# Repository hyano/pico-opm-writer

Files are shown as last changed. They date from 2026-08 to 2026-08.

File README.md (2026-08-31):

# pico-opm-writer

Raspberry Pi Pico 2 (RP2350) を YM2151 (OPM) に直結して鳴らすためのファームウェア。
ホスト PC から USB シリアルで**レジスタを直接叩く**ことも、内蔵フラッシュに入れた
**VGM / MDX を Pico 単体で演奏する**こともできる。鳴った音は YM3012 (DAC) から PCM として
取り込むので、**USB 経由の録音**と **I2S DAC からのアナログ出力**が外部の機材なしで
同時に得られる。

- **レジスタ書き込み**: USB CDC (仮想 COM ポート) にテキストコマンドを打つだけでよく、
  `screen` や `minicom` のような素のターミナルで足りる（[§3](#3-ホストインタフェース)）。
  バッチ実行やキャプチャの自動化には [ホスト側ツール](#10-ホスト側ツール)（`tools/`）を使う
- **VGM 再生**: `/VGM/` に置いた `.vgm` / `.vgz` を、ホストからシーケンスを流し込まずに
  再生する。ファイルが申告するクロックへ φM を自動で合わせる（[§8](#8-vgm-再生)）
- **MDX 再生**: `/MDX/` に置いた X68000 の MDX を、MXDRV 相当の音源ドライバで
  FM 8ch + ADPCM 8ch 再生する。ADPCM (PDX) はソフトウェアでデコードして FM に混ぜる
  （[§9](#9-mdx-再生)）
- **曲データの受け渡し**: 内蔵フラッシュ 4MiB の一部を FAT にしてあり、USB マスストレージ
  として PC から見える。SD カードも外付けフラッシュも要らない（[§7](#7-ストレージ)）
- **PCM 出力**: YM3012 の出力を 2 本目の USB CDC から PCM で吸い出せる（[§4](#4-pcm-出力)）。
  同じデータを I2S で PCM5102A へ常時流している（[§5](#5-i2s-出力)）。ロジックアナライザや
  外部の録音機材は要らない
- **PC を繋がない運用**: ボタン 3 個で自動連続再生とストレージの切り替えができる
  （[§3.17](#317-autoplay自動再生) / [§3.20](#320-ボタンgp21--gp22)）

ファームウェアの内部設計と実装は [docs/pico-opm-writer.md](docs/pico-opm-writer.md) にある。

## 1. ハードウェア構成

### 1.1 接続表

Pico 2 は OPM のバスへ双方向に接続する。**データバスを駆動するのは通常 Pico 側だけ**で、
読み出し（[`r`](#321-r読み出し)）の実行中だけ Pico 側を入力へ倒して OPM に駆動させる。
これとは別に、YM3012 (DAC) のシリアル出力を Pico 側へ取り込む（[§4](#4-pcm-出力)）。

| Pico 2 GPIO | 物理ピン | 接続先 | 方向 | 備考 |
| --- | --- | --- | --- | --- |
| GP0  | 1  | - | - | 将来のデバッグ UART TX 用に予約 |
| GP1  | 2  | - | - | 将来のデバッグ UART RX 用に予約 |
| GP2  | 4  | D0 | I/O | データバス。通常は出力、読み出し中だけ入力 |
| GP3  | 5  | D1 | I/O | |
| GP4  | 6  | D2 | I/O | |
| GP5  | 7  | D3 | I/O | |
| GP6  | 9  | D4 | I/O | |
| GP7  | 10 | D5 | I/O | |
| GP8  | 11 | D6 | I/O | |
| GP9  | 12 | D7 | I/O | D0-D7 は連続した GPIO であること（マスクでまとめて読み書きするため） |
| GP10 | 14 | A0 | OUT | L=アドレスラッチ / H=データ書き込み |
| GP11 | 15 | /CS  | OUT | チップセレクト（負論理） |
| GP12 | 16 | /WR  | OUT | 書き込みストローブ（負論理） |
| GP13 | 17 | /RD  | OUT | 読み出しストローブ（負論理）。[`r`](#321-r読み出し) の実行中だけ L |
| GP14 | 19 | /IC  | OUT | ハードウェアリセット（負論理） |
| GP15 | 20 | φM | OUT | マスタークロック、PIO で生成 |
| GP16 | 21 | /IRQ | IN  | 割り込み要求（負論理）。プルアップ、レベル参照のみ |
| GP17 | 22 | SO | IN  | YM3012 シリアルデータ。PIO の in_base |
| GP18 | 24 | φ1 | IN  | YM3012 ビットクロック（φM/2） |
| GP19 | 25 | SH1  | IN  | CH2 のサンプルホールド。フレーム同期に使う |
| GP20 | 26 | SH2  | IN  | CH1 のサンプルホールド。現在は未使用 |
| GP21 | 27 | SW1  | IN  | ボタン 1（[§3.20](#320-ボタンgp21--gp22)）。内部プルアップ、押下で GND |
| GP22 | 29 | SW2  | IN  | ボタン 2（同上） |
| GP25 | -  | - | OUT | 基板上 LED（[§3.9](#39-led)）。`PICO_DEFAULT_LED_PIN` |
| GP26 | 31 | BCK  | OUT | I2S ビットクロック（[§5](#5-i2s-出力)） |
| GP27 | 32 | LRCK | OUT | I2S ワードセレクト。BCK の次の GPIO であること |
| GP28 | 34 | DIN  | OUT | I2S データ |
| RUN  | 30 | SW3  | IN  | Pico 2 のリセット端子。押下で GND に落としてリセット。**ファームウェアからは見えない**（[§3.20](#320-ボタンgp21--gp22)） |
| GND  | 3, 8, 13, 18 … | GND | - | OPM と共通グラウンドを取ること |

GP23 / GP24 は Pico 2 の内部用途（`PICO_SMPS_MODE_PIN` / `PICO_VBUS_PIN`）なので使わない。
I2S の MCLK は使わないので、DAC へ出すのは GP26-GP28 の 3 本だけ。

SO / φ1 / SH1 / SH2 は **GP17 から連続していること**。キャプチャ用の PIO がこの 4 本を
in_base からのオフセットで参照する（[docs §4.2](docs/pico-opm-writer.md#42-pio-によるビット取り込み)）。

ピン番号の定義は [opm.h](src/opm.h) の `OPM_PIN_*`、[ym3012.h](src/ym3012.h) の `YM3012_PIN_*`、
[button.h](src/button.h) の `BUTTON_PIN_*` にまとまっている。

### 1.2 GPIO を割り当てない OPM 端子

| OPM 端子 | 処理 | 理由 |
| --- | --- | --- |
| CT1 / CT2 | 未接続で可 | 汎用出力端子。本ファームウェアは使わない |

### 1.3 配線上の注意

**Pico 2 と OPM は全線を直結する。** レベル変換器も分圧も挟まない。
[board/](board/) の基板もこの前提で起こしてある。モジュールを使わず RP2350A と PCM5102A を
直接実装する改版が [board_pcba/](board_pcba/README.md) にある（回路図のみ）。

- **入力側（Pico → OPM）**: OPM は 5V デバイス、Pico 2 の GPIO は 3.3V。RP2350 の 3.3V 出力を
  OPM が H / L として判別できることは実機で確認済みで、[test/](test/) の実測データはすべて
  この直結構成で取れている。ただし OPM の入力 H レベル閾値には個体差・ロット差があり、
  他の個体でも同じように動く保証は無い（未確認）。動作しない場合はバッファ / レベルシフタ
  （74HCT244 等）を φM とバス側に挿入する。
- **出力側（OPM → Pico）**: SO / φ1 / SH1 / SH2 / /IRQ は 5V デバイスである OPM の**出力**で、
  H レベルは 3.3V を超える。**RP2350 の GPIO 0-25 は 5V トレラント**なので直結でよい
  （[RP2350 データシート](https://datasheets.raspberrypi.com/rp2350/rp2350-datasheet.pdf)
  §14.8.2.1 Table 1426 の `Digital IO (FT)` / §14.9.1 Table 1433 の `VPIN_FT`）。
  成立の条件は次の 2 つで、本構成はどちらも満たしている。

  | 条件 | 本構成での成立 |
  | --- | --- |
  | 対象は **GPIO 0-25 のみ**（`Digital IO (FT)` パッド）。GP26-GP29 は ADC 兼用の `Digital IO / Analogue` で対象外 | 5V を受けるのは GP2-GP9 (D0-D7) / GP16 (/IRQ) / GP17-GP20 (SO・φ1・SH1・SH2) だけで、すべて範囲内 |
  | 5V が掛かっている間 **IOVDD が 3.3V で給電されている**こと。無給電のまま 5V を掛けるとパッドが壊れる | OPM の 5V は Pico の VBUS から取るので、5V があるときは必ず Pico の 3.3V も生きている |

  **ステッピングによる違いは無い。** データシートの FT パッドの規定は版を区別しておらず、
  Appendix C も A4 を "This stepping has no hardware changes." としている。
  A4 の[告知](https://www.raspberrypi.com/news/rp2350-a4-rp2354-and-a-new-hacking-challenge/)
  （2025-07-29）は認定試験を通したという告知であってシリコンの変更ではないので、
  出回っている A2 の Pico 2 でも同じように使える
  （[Raspberry Pi のエンジニアの明言](https://forums.raspberrypi.com/viewtopic.php?p=2330278)）。

  絶対最大定格は GPIO 0-25 が IOVDD = 3.3V のとき 5.5V、IOVDD = 0V のとき 3.63V
  （Table 1433 の `VPIN_FT`）。それ以外のピンは IOVDD + 0.5V。/IRQ は
  [opm.c](src/opm.c) が内部プルアップを張るので、外付け抵抗は要らない。

  **GP26-GP28（I2S の BCK / LRCK / DIN）に 5V デバイスを繋いではいけない。**
  この 3 本は 5V トレラントの対象外。接続先の PCM5102A は 3.3V ロジックで、
  しかも Pico からの出力専用なので現状は問題にならない（[§5](#5-i2s-出力)）。
- **バスの衝突防止**: D0-D7 は双方向なので、OPM と Pico が同時に駆動すると衝突する。
  /RD を H に保っていれば OPM は D0-D7 を駆動しないため、ファームウェアは
  **読み出し（[`r`](#321-r読み出し)）の実行中以外は /RD を H に固定**している。
  読み出しでは、OPM に駆動させる前に Pico 側を入力へ倒し、/RD を H に戻して OPM が
  バスを手放してから出力へ戻す。この間 D0-D7 は OPM の 5V 出力を受けるので、
  上の表の条件（GPIO 0-25・IOVDD 給電中）がそのまま効く。
  **ただしこれが効くのは GPIO を初期化した後だけ。** RP2350 のパッドはリセット直後
  入力 + プルダウン（`PADS_BANK0_GPIO0_RESET` の `PDE` = 1）なので、電源投入から
  `opm_init()` が /CS と /RD を H にするまでの間は OPM から見て /CS = L / /RD = L となり、
  **OPM が D0-D7 を駆動する窓がある**。この窓では Pico 側がまだ入力なので駆動は衝突せず、
  D0-D7 に乗る 5V も上の表の条件を満たす。窓そのものを塞ぎたければ /CS を 5V へ
  10kΩ 程度でプルアップする（このとき GP11 も 5V を受けるが、GPIO 0-25 なので同じく
  条件の内側）。
- 電源には十分なデカップリング（OPM の VCC-GND 間に 0.1µF + 10µF 程度）を入れる。
- **ボタンは 3 個ともスイッチ 1 個だけでよい。** SW1 / SW2 は GP21 / GP22 と GND の間、
  SW3 は RUN と GND の間に入れる。**外付けのプルアップ抵抗もコンデンサも要らない**
  （GP21 / GP22 は RP2350 の内部プルアップを張って負論理で読み、チャタリングは
  ファームウェア側で時間ベースに除去する。RUN は Pico 2 側で既にプルアップされている）。
  SW1 / SW2 を使わないなら GP21 / GP22 は開放でよい。内部プルアップで「離されている」と
  読めるので、ボタンを実装していない基板でも既定のファームウェアがそのまま動く。

## 2. クロック設定 (φM)

φM は PIO で生成する。φM とシステムクロックは**整数分周（ジッタなし）になる組**でしか
意味を持たないため、両者をペアにしたプリセットとして持たせている。

| プリセット | `clock` の引数 | φM | sys_clk | clkdiv | fs (φM/64) | 備考 |
| --- | --- | --- | --- | --- | --- | --- |
| 4MHz（**起動時の既定**） | `4` | 4.000000 MHz | 144 MHz（= 4MHz × 36） | 18 | 62500.0 Hz | YM2151 の定格上限。RP2350 定格 150MHz 以内 |
| NTSC | `3.58` | 3.579545 MHz | 157.5 MHz（= × 44） | 22 | 55930.4 Hz | NTSC カラーサブキャリア = 315/88 MHz。定格比 約 +5% の OC |

**動作させたまま切り替えられる。**

- `clock 4` / `clock 3.58` で手動切り替え（[§3.16](#316-clockクロック切り替え)）
- `vgm play` はヘッダが申告する YM2151 のクロックへ自動追従する
  （[§8.3](#83-φm-と-vgm-のクロック)）。`clock fixed` で抑止できる
- `mdx play` は X68000 の φM = 4MHz へ寄せる（[§9.3](#93-φm-と-テンポ)）。
  同じく `clock fixed` で抑止できるが、MDX は**テンポも φM に比例して狂う**
- **PCM を流している間は切り替えを拒否する。** サンプリングレートが
  ストリームの途中で変わると、ホスト側で出来上がる WAV の時間軸が黙って狂うため。
  `p 2` の待機中はまだ流していないので通る（[§3.16](#316-clockクロック切り替え)）

切り替えは sys_clk ごと張り替えるが、**φM・BCK・LRCK の H/L 期間が公称値より
短くなることはない**（順序と手順は [docs §2.3](docs/pico-opm-writer.md#23-実行時の切り替え)）。
所要は数百 µs で、その間 I2S のリング（先行 16.4ms）は枯れないのでアンダーランしない。

起動時にどちらで立ち上げるかは次のどちらかで決める。

- `opm.h` の `#define OPM_CLOCK_MODE OPM_CLOCK_MODE_4MHZ` の行を書き換える
- ヘッダを触らずに再コンフィグする:
  ```bash
  cmake -S . -B build -G Ninja -DCMAKE_BUILD_TYPE=Release -DPICO_BOARD=pico2 -DOPM_CLOCK_MODE=1
  ```
  `-DOPM_CLOCK_MODE=` （空）に戻すと `opm.h` の既定値に従う。

**プリセット外の値を使うときは φM と sys_clk の両方を整数分周になる組で指定すること**
（片方だけの変更は小数分周になり、φM にジッタが乗る）。理由と、整数分周にならなかった
場合の挙動は [docs §2](docs/pico-opm-writer.md#2-φm-の生成) にある。

φM を変えても PCM のサンプリングレート（φM/64）が変わるだけで、タイミング定数の
書き換えは要らない。

## 3. ホストインタフェース

### 3.1 接続

- USB CDC (仮想 COM ポート) **2 ポート**。

  | | 用途 | macOS でのデバイス名の例 |
  | --- | --- | --- |
  | CDC #0 | コマンド。Pico SDK の `stdio_usb` がそのまま使う | `/dev/cu.usbmodem11201` |
  | CDC #1 | PCM データ出力（[§4](#4-pcm-出力)） | `/dev/cu.usbmodem11203` |

  CDC #0 をディスクリプタの先頭に置いているので、コマンド側のデバイス名は 1 ポート構成の
  ときと変わらない。CDC #1 は末尾の番号が増えたものになる。
  2 本は独立しているので、コマンドを打ちながら PCM を取り込める。
- CDC を 2 本にする都合で **`picotool load -fx`（BOOTSEL 不要の書き込み）は使えない**
  （[§6.4](#64-書き込み代替経路)）。
- ボーレート・パリティ等の設定は無視される（USB CDC のため何を指定しても動作する）。
- macOS 例: `screen /dev/cu.usbmodem11201 115200`。
  **`/dev/tty.*` ではなく `/dev/cu.*` を使う**（`tty.*` は DCD 待ちで open がブロックする）。
  デバイス名の引き直し方は [§6.5](#65-シリアル-stdio-の読み取り) を参照。
- 接続を検出した時点で起動バナーを出力する（接続前の出力は捨てられるため）。

### 3.2 行フォーマット

- コマンドは **1 行 1 コマンド**。行末は `LF` / `CR` / `CRLF` のいずれでも受け付ける。
- 1 行の最大長は 255 文字。超えた場合は `ERR too long` を返し、その行を破棄する。
- コマンド文字・16 進数の大文字小文字は区別しない。
- トークン区切りは空白またはタブ（連続可）。
- 空行、および **行頭が `#` の行**はコメントとして無視し、**応答も返さない**。

**行末コメント（`w 20 c7 # ...`）には対応していない。** `#` は引数のトークンとして読まれ、
`ERR bad argument` または `ERR wrong arity` になる。行末コメント・プレースホルダ置換・
キャプチャ制御が要るシーケンスは [tools/opm-writer.py](docs/opm-writer.md) 経由で流し込む。

### 3.3 応答

各コマンドは必ず 1 行の応答で終わる。**例外は空行とコメント行だけ**で、これらは
何も返さない（[§3.2](#32-行フォーマット)）。

| 応答 | 意味 |
| --- | --- |
| `OK` | 正常終了 |
| `ERR <理由>` | エラー |

情報を返すコマンドは、`#` で始まる情報行を 0 行以上出力したあと最後に `OK` を返す。
ホスト側は「`#` 始まりは情報、それ以外の 1 行が終端」と扱えばよい。

情報行は 4 種類ある。いずれも `# ` で始まるので、区別せず読み飛ばしても構わない。

| 情報行 | 意味 |
| --- | --- |
| `# <tag> : ...` | 通常の情報。`<tag>` は主題（`vgm` / `adpcm` / `capture` など）を表す |
| `# hint : ...` | **直後の** `ERR` の理由と対処。応答より先に出る。**`ERR wrong state` には必ず付く** |
| `# warn : ...` | 処理は続いたが注意が要ること |
| `# ERR ...` | コマンドの応答ではない非同期の通知（[§3.18](#318-非同期通知)） |

**ファームウェアの応答はすべて英語。** 例外は `mdx play` / `mdx status` の `# title` 行
だけで、これは MDX ファイル中の Shift_JIS をそのまま流している（[§3.15](#315-mdxmdx-再生)）。

エラー理由の一覧:

| 応答 | 発生条件 |
| --- | --- |
| `ERR unknown command` | 未知のコマンド。1 文字のコマンドか `clock` / `storage` / `vgm` / `mdx` / `autoplay` / `reset` / `help` のいずれでもない場合と、それらのサブコマンドが未知の場合（`clock 5` のような未知のプリセット名も含む） |
| `ERR bad argument` | 引数が 16 進数 / 10 進数として解釈できない、ファイル名が不正、または語の引数が想定外（`mdx pcm maybe` / `storage format no`） |
| `ERR wrong arity` | 引数の個数が合わない |
| `ERR out of range` | 引数が許容範囲外 |
| `ERR too long` | 行が長すぎる |
| `ERR wrong state` | いまの状態では実行できない。**直前に必ず理由を示す `# hint` 行が出る。** どのコマンドがどの状態で拒否されるかは [§3.19](#319-状態による拒否の一覧) にまとめてある |
| `ERR no filesystem` | ストレージが未フォーマット、または領域がファームウェアと重なっている |
| `ERR not found` | 指定したファイルが無い、`/VGM` / `/MDX` が無い、または `autoplay list` を打ったときにプレイリストがまだ作られていない（[§3.17](#317-autoplay自動再生)） |
| `ERR bad file` | VGM / MDX として読めない（マジック不正 / ヘッダが壊れている / gzip ストリームが壊れている / MDX が 64KiB を超える） |
| `ERR io error` | フラッシュまたはファイルシステムの入出力に失敗した |
| `ERR not connected` | CDC #1 が開かれていない状態で `p 1`（[§3.10](#310-ppcm-出力)） |
| `ERR drain timeout` | `p 0` のドレインが 2 秒で終わらなかった（[§3.10](#310-ppcm-出力)） |
| `ERR self test failed` | `t` の自己テストのどれかが失敗した（[§3.12](#312-t自己テスト)） |
| `ERR unsupported` | この構成に機能が無い。`clock` の切り替え先の sys_clk をこのチップで生成できない（[§3.16](#316-clockクロック切り替え)）か、ビルド時に無効化されている（`MDX_ENABLED=0` / `PCM8_ENABLED=0`。[§9.8](#98-無効化)、`AUTOPLAY_ENABLED=0`。[§3.17](#317-autoplay自動再生)） |

### 3.4 コマンド一覧

| コマンド | 書式 | 説明 |
| --- | --- | --- |
| `w` | `w <addr> <data> [<addr> <data> ...]` | レジスタ書き込み。引数は 16 進。addr/data のペアを 1 行に複数並べて連続書き込みできる。**途中でエラーになった場合、そこまでの書き込みは実行済み**のまま `ERR` を返す |
| `r` | `r 0` / `r 1` | A0=0 / A0=1 で 1 バイト読み出し（[§3.21](#321-r読み出し)） |
| `reset` | `reset` | /IC によるハードウェアリセット。I2S のアンダーランを 1 回伴う（[§5.3](#53-アンダーラン)） |
| `c` | `c` | ソフトウェアによる全レジスタクリア（[§3.5](#35-cクリアが書き込む内容)） |
| `d` | `d <ms>` | 指定ミリ秒待機。10 進、`0`-`60000`。待っている間も PCM の送出は続く |
| `p` | `p` / `p 1` / `p 2` / `p 0` | PCM 出力の状態表示 / 開始 / 演奏に連動して開始 / 停止（[§3.10](#310-ppcm-出力)） |
| `s` | `s` / `s 0` | 統計の表示 / リセット（[§3.11](#311-s統計)） |
| `t` | `t` | 自己テスト（[§3.12](#312-t自己テスト)） |
| `i` | `i` | 情報表示（[§3.6](#36-i情報表示の出力例)） |
| `h` | `h` / `?` / `help` | コマンド一覧を表示 |
| `clock` | `clock` / `clock status` / `clock 4` / `clock 3.58` / `clock auto` / `clock fixed` | φM の表示と切り替え（[§3.16](#316-clockクロック切り替え)） |
| `storage` | `storage` / `storage status` / `storage host` / `storage player` / `storage format [force] yes` / `storage trace` | ストレージの状態表示とモード切り替え（[§3.13](#313-storageストレージ)） |
| `vgm` | `vgm` / `vgm status` / `vgm list` / `vgm play <path>` / `vgm stop` / `vgm loop [<n>]` / `vgm fade [<ms>]` | VGM の状態表示・一覧・再生、演奏の終わり方（[§3.14](#314-vgmvgm-再生)） |
| `mdx` | `mdx` / `mdx status` / `mdx list` / `mdx play <path>` / `mdx stop` / `mdx loop [<n>]` / `mdx fade [<ms>]` / `mdx pcm [on\|off]` | MDX の状態表示・一覧・再生、演奏の終わり方、ADPCM ミキシングの表示と切り替え（[§3.15](#315-mdxmdx-再生)） |
| `autoplay` | `autoplay` / `autoplay status` / `autoplay list` / `autoplay start` / `autoplay stop` / `autoplay next` / `autoplay prev` / `autoplay mode <list\|random>` / `autoplay loop <n>` / `autoplay fade <ms>` / `autoplay gap <ms>` / `autoplay source <vgm\|mdx\|both>` | VGM と MDX の自動連続再生（[§3.17](#317-autoplay自動再生)） |

コマンド体系の規則:

- **引数を省くと状態表示になる。** `p` / `clock` / `storage` / `vgm` / `mdx` / `mdx pcm` /
  `vgm loop` / `vgm fade` / `mdx loop` / `mdx fade` / `autoplay` は引数なしで現在の状態を
  返す。`clock status` / `storage status` /
  `vgm status` / `mdx status` / `autoplay status` は引数なしの形と同じ（打ちやすい方を
  使えばよい）。
- **状態を変えるコマンドは、変えたあとの状態を返す。** `p 1` / `p 2` / `p 0` / `storage host` /
  `storage player` / `clock 4` / `mdx pcm on` は変更後の状態を出してから `OK` を返す。
- **「止める」「切り替える」は冪等。** `vgm stop` / `mdx stop` / `autoplay stop` / `p 0` /
  `storage host` / `storage player` / `clock 4` は、既にその状態でも `OK` を返す。スクリプトから
  「いま何が動いているか分からないがとにかく止めたい」を書けるようにするため。
- **再生の開始は切り替えでもある。** `vgm play` / `mdx play` は何かが鳴っていても
  受け付け、走っている方（VGM / MDX のどちらでも）を止めてから始める。曲を変えるのに
  `stop` を先に打つ必要はない。
- **引数の基数は `w` だけ 16 進、他は 10 進。** `w` の 16 進は桁数自由で、値が `0xff`
  以下なら受理する（`w f 1` も `w 0020 00c7` も通る）。`0xff` を超えると
  `ERR out of range`。`d <ms>`（`0`-`60000`）と `p 1` / `p 2` / `p 0` / `s 0` は 10 進。
- **引数の語彙は、1 文字コマンドは数値、複数文字コマンドは語。** 1 文字コマンドは
  打鍵の短さを優先して `r 0` / `r 1` / `p 1` / `p 2` / `p 0` / `s 0` / `d 500` とし、複数文字コマンドは
  `on` / `off` / `auto` / `fixed` / `host` / `player` のように語で書く。
  `p on` のような書き方は受け付けない。
- **大小は区別しない。** 1 文字のコマンドも `clock` / `storage` / `vgm` / `mdx` /
  `autoplay` / `reset` / `help` とそのサブコマンドも同様。
- **自動再生とストレージの操作は、基板上のボタンからも行える。** `autoplay start` /
  `autoplay mode` / `autoplay next` / `autoplay prev` / `storage host` に相当する操作を
  SW1 / SW2 の押し方で選べる（[§3.20](#320-ボタンgp21--gp22)）。ボタン起点の操作は
  `#` で始まる情報行しか出さないので、「1 コマンド 1 応答」（[§3.3](#33-応答)）は崩れない。
- **`vgm play` と `mdx play` のファイル名だけは行の残り全部を 1 引数として受ける**ので、
  空白を含む名前もそのまま書ける（`vgm play BAD NAME.VGM`）。サブフォルダは `/` で
  区切って書く（`vgm play KONAMI/GRADIUS.VGM`）。

1 レジスタ書き込みには約 32µs かかる（最大 3 万回/秒）。内訳は
[docs §3.1](docs/pico-opm-writer.md#31-タイミング定数)。

### 3.5 `c`（クリア）が書き込む内容

/IC リセットに近い状態をソフトウェアで作る。実行順:

1. `0xE0`-`0xFF`（全 32 スロットの D1L/RR）に `0x0F`（D1L = 0 / RR = 15、最速リリース）。
   KEY OFF より前に書くので、直前の音色の RR に関わらず即座に減衰する
2. `0x08` に `0x00`-`0x07` を書き、全 8 チャンネルを KEY OFF
3. `0x60`-`0x7F`（全 32 スロットの TL）に `0x7F`（最小音量）
4. `0x0F` に `0x00`（ノイズ off）
5. `0x14` に `0x00`（タイマ / IRQ 停止）
6. `0x01` に `0x00`（LFO リセット解除）
7. `0x18` に `0x00`（LFO 周波数）
8. `0x19` に **`0x80` → `0x00` の順で 2 回**書き込む。`0x19` は bit7 で書き込み先が切り替わる
   レジスタで、`0x80` が PMD = 0、`0x00` が AMD = 0 の設定になる（PMD 側を消し忘れないため
   両方を書く）
9. `0x1B` に `0x00`（LFO 波形 / CT1・CT2）
10. `0x20`-`0x27` に `0x00`（RL / FB / CONNECT）

### 3.6 `i`（情報表示）の出力例

```
# pico-opm-writer 0.3.0
# phiM    : 4000000 Hz (clkdiv 18 + 0/256)
# sys_clk : 144000000 Hz
# preset  : 4  (vgm auto)
# pins    : D0-D7=GP2-GP9 A0=GP10 /CS=GP11 /WR=GP12 /RD=GP13 /IC=GP14
# pins    : phiM=GP15 /IRQ=GP16
# timing  : t_wr=1us t_addr=5us t_data=18.0us (72 phiM) t_rd=1us
# ym3012  : SO=GP17 phi1=GP18 SH1=GP19 SH2=GP20
# pins    : SW1=GP21 SW2=GP22 (pull-up, active low)
# button  : long 1000 ms  boot none
# capture : ring 16384 bytes (4096 frames) rate 62500 Hz
# i2s     : BCK=GP26 LRCK=GP27 DIN=GP28 (clkdiv 36 + 0/256)
# i2s     : 32fs bck 2000000 Hz rate 62500 Hz latency 1024 frames (16384 us)
# piotest : SKIP (disabled)
# storage : flash 0x040000 + 3836 KiB  cluster 4096 B  sector 512 B
# vgm     : dir /VGM  rate 44100 Hz  budget 500 us
# mdx     : dir /MDX  max 64 KiB  budget 500 us
# adpcm   : enabled  8 ch  pdx stream 1024 bytes/ch
OK
```

バージョンに続く 3 行は `clock`（[§3.16](#316-clockクロック切り替え)）の先頭 3 行と
同じ内容・同じ並び。
`I2S_ENABLED=0` でビルドした場合は `# i2s` の 2 行が `# i2s     : disabled` の 1 行に
なる（[§5.4](#54-無効化)）。同じく `BUTTON_ENABLED=0` では `# pins : SW1=...` と
`# button` の 2 行が `# button  : disabled` の 1 行になる（[§3.20](#320-ボタンgp21--gp22)）。

`# button` の `boot` は**起動時にボタンで選んだ動作モードとその結果**
（[§3.20](#320-ボタンgp21--gp22)）。押されていなければ `none`。起動直後の出力は
ホストが CDC を開く前なので捨てられるため、後から USB を挿しても分かるようここに残す。

```
# button  : long 1000 ms  boot autoplay list (ok)
# button  : long 1000 ms  boot autoplay random (no filesystem)
# button  : long 1000 ms  boot storage host (ok)
```

### 3.7 起動バナー

USB CDC の接続を検出した時点で `i` と同じ内容を出力する（末尾の `OK` を含む）。

### 3.8 使用例

```
> i
# pico-opm-writer 0.3.0
...
OK
> reset
OK
> w 20 c7 28 4a 30 00
OK
> d 500
OK
> w 08 00
OK
```

### 3.9 LED

基板上 LED (`PICO_DEFAULT_LED_PIN`、pico2 では GP25) で状態を示す。表示は 100ms
スロットのパターン駆動で、`sleep_ms()` などで処理を止めることはない。

| 状態 | パターン | 意味 |
| --- | --- | --- |
| 待機 | 常時点灯 | 電源が入っていて、キャプチャしておらず、エラーでもない |
| キャプチャ中 | 500ms ON / 500ms OFF | `p 1` から `p 0` の完了まで |
| `storage host` 中 | 200ms ON / 800ms OFF | ファイルシステムを PC へ渡している（[§3.13](#313-storageストレージ)） |
| 起動時のモード選択 | 100ms 点滅 ×n → 休み | ボタンを押しながら起動した。**n が選ばれたモード**（1 = `autoplay list` / 2 = `autoplay random` / 3 = `storage host`）。離すまで続く（[§3.20](#320-ボタンgp21--gp22)） |
| コマンド受信 | 100ms ON → 100ms OFF → 100ms ON | 1 回だけ差し込む。終わったら元のパターンの先頭へ戻る |
| ボタンの長押し成立 | 100ms OFF → 500ms ON → 100ms OFF | 1 回だけ差し込む。しきい値に達した瞬間に出る（[§3.20](#320-ボタンgp21--gp22)） |
| DMA overrun | 100ms ON/OFF ×3 → 1 秒 OFF | [§4.1](#41-取りこぼしたとき-dma-overrun)。エラー表示はこれだけ |

キャプチャ中の 500ms 点滅とコマンド受信の 100ms 二重点滅は速さで区別できる。
`storage host` 中の 200/800 は、点いている時間の短さでキャプチャ中の 500/500 と分かれる。
一時表示の 2 つは、コマンド受信が短い 2 連（計 300ms）、ボタンの長押し成立が
1 発の長い点灯（計 700ms）で区別できる。**長押しの合図が OFF から始まる**のは、
一時表示が基本パターンを完全に置き換えるため。待機（常時点灯）の上に点灯だけの
パターンを重ねても何も変化しない。

起動時のモード選択が 3 回点滅する場合（`storage host`）は DMA overrun と点滅の回数が
同じだが、**DMA overrun は `p 1` の後にしか起き得ない**ので起動待ちと同時には現れない。
休みの長さも違う。

**LED をエラー表示にするのは DMA overrun のときだけ。** `p` の状態エラー・CDC #1 の切断・
USB 未接続・一時的な USB 送信不可は、いずれもエラー表示にしない。

### 3.10 `p`（PCM 出力）

CDC #1 への PCM 送信を制御する。**取り込み側の PIO と DMA は起動時から常時動いていて、
このコマンドでは開始も停止もしない**（[§4](#4-pcm-出力)）。

| 書式 | 動作 |
| --- | --- |
| `p` | 現在の状態を表示する（下記） |
| `p 1` | このコマンドを処理した時点以降に DMA が書いたデータから送信を始める。それより前のデータは送らない |
| `p 2` | **次の `vgm play` / `mdx play` から送信を始め、その曲が終わったら自分で停止する**（下記） |
| `p 0` | このコマンドを処理した時点までに DMA が取り込んだデータを**最後の 1 フレームまで送り切ってから**停止する |

`p 1` / `p 2` / `p 0` は変更後の状態を 1 行出してから `OK` を返す。

```
> p
# capture : IDLE
# auto    : off
# cdc1    : connected
# rate    : 62500 Hz
OK

> p 1
# capture : CAPTURING
OK
```

`# capture` は `s` の `STATE` と同じ（`IDLE` / `WAITING` / `CAPTURING` / `DRAINING` /
`ERROR`。[§3.11](#311-s統計)）。`# auto` は `p 2` で始めたか、`# cdc1` は PCM 側の
ポートをホストが開いているか、`# rate` はサンプリングレート φM/64。

#### `p 1` と `p 2` の違い

**違うのは録り始めと録り終わりだけ。** 送り先（CDC #1）も PCM の形式（[§4](#4-pcm-出力)）も
ドレインの手順も overrun の条件も `storage host` の拒否も同じ。

| | `p 1` | `p 2` |
| --- | --- | --- |
| コマンド直後 | 即座に流し始める | **何も流さない**（`WAITING`）。待っている間の無音は WAV に入らない |
| 録り始め | `p 1` の瞬間 | 次に成功した `play` の瞬間 |
| 既に鳴っているとき | その時点から録る | 何もしない。**次の** `play` を待つ |
| 録り終わり | `p 0` まで無制限 | その曲が終わって**余韻も消えたとき**（[§3.22](#322-曲の終わり方)） |
| 終了の通知 | 無し（`p 0` の応答が終端） | `# capture : done <n> frames` |
| φM の切り替え | 拒否 | **待機中は通る。** 録り始めれば `p 1` と同じ扱い（[§3.16](#316-clockクロック切り替え)） |

φM だけ扱いが違うのは、待機中はまだ 1 フレームも流していないためで、これが
別クロックの VGM を `p 2` で録れる理由になっている。

```
> p 2
# capture : WAITING
OK
> mdx play SORCER/OP.MDX
# mdx     : SORCER/OP.MDX
OK
（曲が鳴り終わるまで CDC #1 に PCM が流れ続ける）
# mdx     : end of data
# capture : done 49376 frames
```

`p 2` の録り終わりは**自動再生が次の曲へ送るのと同じ時刻**になる。どちらも
[§3.22](#322-曲の終わり方) の同じ状態を見ているため。演奏中に別の曲を `play` した
場合もそこで打ち切る（1 回のキャプチャは 1 曲ぶん）。曲を鳴らさないまま放置すれば
`p 0` を打つまで待ち続ける。

演奏の終端をループ回数で決めたいときは `vgm loop` / `mdx loop` と組み合わせる
（[§3.22](#322-曲の終わり方)）。ホスト側の `!capture-song`
（[docs/opm-writer.md](docs/opm-writer.md)）はこの手順をそのまま実行する。

`p 0` はドレインが終わってから `OK` を返す。待っている間も PCM の送出と USB の処理は
回り続けるので、DMA が止まることはない。2 秒で終わらなければ打ち切って
`ERR drain timeout` を返す（ホストが CDC #1 を読んでいない場合）。

**`p 0` は冪等。** 待機中に打っても `OK` を返す。DMA overrun で `ERROR` に落ちている
場合もここで待機へ戻せる（[§4.1](#41-取りこぼしたとき-dma-overrun)）。

エラーになる条件:

| 状況 | 応答 |
| --- | --- |
| キャプチャ中（`WAITING` を含む）に `p 1` / `p 2` | `ERR wrong state`（`# hint : already capturing; run p 0 first`） |
| `storage host` 中に `p 1` / `p 2` | `ERR wrong state`（`# hint : cannot capture PCM in storage host; run storage player first`。[§3.13](#313-storageストレージ)） |
| CDC #1 が開かれていない状態で `p 1` / `p 2` | `ERR not connected` |

いずれもコマンドの状態エラーであって、ファームウェアのエラー状態にはしない
（LED も変えない）。CDC #1 が開かれていないまま送信を始めるとリング 65.5ms 分で
必ず overrun するため、`p 1` / `p 2` の時点で弾いている。

キャプチャ中に CDC #1 が閉じられたら**即座に送信を停止**して待機へ戻る。これはエラーでは
ないので LED も変わらない。再接続しても自動では再開せず、次の `p 1` / `p 2` を待つ。
`p 2` の待機中（`WAITING`）に閉じられた場合も同じで、演奏を待たずに降りる。

### 3.11 `s`（統計）

`s` で実行時の統計を表示し、`s 0` でリセットする。`RING` と `USB_TX` の単位はバイト
（他の項目の単位は下の表のとおり）。**`s` のラベルだけは大文字**で、他のコマンドの
情報行は小文字にしてある。同じ値が両方に出ることがあるのはこのため
（`s` の `FLASH` と `storage status` の `# flash` は同じもの）。

```
# STATE   : CAPTURING
# CPU     : 40% (max 41%)   USB 8%
# RING    : 44/16384 bytes  MAX 568/16384  FREE 16340
# USB_TX  : 0/4096 bytes  MAX 1240/4096
# I2S     : depth 963/1024 frames  MIN 866  UNDERRUN 0
# OVERRUN : 0   E0 : 0   RXSTALL : 0
# RATE    : 62508 frames/s (expect 62500)
# QUIET   : 0 frames
# LOOP    : 468607 passes/s  MAX 1511 us  AUDIO GAP max 1561 us
# SVC     : pcm8 612/1991  cap 794/1991  i2s 781/1991  vgm 0/18430  mdx 110/18430  sto 0/998  worked/calls per s
# FRAMES  : 56263161
# FLASH   : WRITE 76   BLACKOUT max 42711 us
# VGM     : PLAYING AFTERBURNER.VGM
# VGM POS : 507150/2205000 samples  loop 7
# VGM LAG : reslip 0  gz reload 0
# MDX     : STOPPED
# MDX POS : 0 clocks  loop 0  ch 0
# MDX TICK: @t 200  14336 us  reslip 0
# MDX PCM : on  1/8 ch  mask 01  keyon 128  miss 0  reads 647  CLIP 2
# SEQ LAG : max 657 us
# PIOTEST : SKIP (disabled)
# IRQ     : H
OK
```

| 項目 | 内容 |
| --- | --- |
| `STATE` | キャプチャの状態。`IDLE` / `WAITING` / `CAPTURING` / `DRAINING` / `ERROR`（[§3.10](#310-ppcm-出力)） |
| `CPU` | 直近 1 秒のうち **サービス関数の中に居た時間**の割合と、リセット以降の最大値。`USB` は `tud_task()` の占有率で、毎周回走る固定費なので分けてある |
| `RING` | DMA リングの未処理量と high-water、空き |
| `USB_TX` | CDC #1 の送信バッファ滞留量と high-water。USB エンドポイントの状態ではなく、ファーム内の TX FIFO の滞留量 |
| `I2S` | I2S の DMA より先に書けているフレーム数と low-water、アンダーラン回数（[§5](#5-i2s-出力)）。ここだけは減る方向が危険なので最小値を残す |
| `OVERRUN` | DMA overrun の発生回数 |
| `E0` | YM3012 の禁止コード `E=0` を見た数。**PIO のビット位相が正しければ 0 のまま** |
| `RXSTALL` | PIO の RX FIFO があふれた回数。あふれると L/R の並びが崩れる |
| `RATE` | 直近 1 秒で数えた実測フレームレートと期待値 φM/64 |
| `QUIET` | DAC の出力が無音のまま続いているフレーム数。曲の終わりの余韻が消えたかを判定するのと同じ値で、鳴っていれば 0（[§3.22](#322-曲の終わり方)） |
| `LOOP` | 直近 1 秒のメインループ周回数。1 周あたりの固定費を見積もるのに使う。`MAX` は `service_all()` の呼び出し間隔の最大値、`AUDIO GAP max` は音声チェーンが実際に回った間隔の最大値で、**どちらもリアルタイムの余裕を直接表す**（[§3.11.1](#3111-サービスの呼び出し間隔)） |
| `SVC` | サービスごとの「実仕事をした回数 / 呼ばれた回数」（どちらも毎秒）。呼ばれた回数は[§3.11.1](#3111-サービスの呼び出し間隔)の間引き間隔で決まり、実仕事の側はその中で本当に処理があった回数。分子が分母に対して極端に小さければ、そのサービスは間引きを緩めても構わない |
| `FRAMES` | 取り込んだ総フレーム数 |
| `FLASH` | 内蔵フラッシュへ 4KiB ブロックを書き出した回数と、その間メインループが止まった最大時間（[§3.13](#313-storageストレージ)） |
| `VGM` | VGM の再生状態（`STOPPED` / `PLAYING` / `ERROR`）と再生中のファイル名。gzip 圧縮されたファイルなら末尾に `(gzip)` が付く（[§8.5](#85-vgzgzipの再生)） |
| `VGM POS` | 発行済みのサンプル位置 / ヘッダの総サンプル数と、ループした回数 |
| `VGM LAG` | VGM の時計を張り直した回数（[§3.14](#314-vgmvgm-再生)）。`gz reload` は `.vgz` のループで先頭から展開し直した回数で、**0 でなければループのたびに音が数百 ms 途切れている**（[§8.5](#85-vgzgzipの再生)） |
| `MDX` | MDX 再生の状態とファイル名（[§3.15](#315-mdxmdx-再生)）。`MDX_ENABLED=0` でビルドした場合は `DISABLED`（[§9.8](#98-無効化)） |
| `MDX POS` | 発行済みの clock 数、曲が何周したか、チャンネル数。`loop` は「まだ終わっていない全チャンネルがループ点に到達した」回数 |
| `MDX TICK` | 現在の Timer-B 値と 1 clock の長さ、時計を張り直した回数（[§9.2](#92-タイミング)） |
| `MDX PCM` | ADPCM ミキシングの有効・無効、発音中のチャンネル数とビットマスク、発音を開始した回数（`keyon`）と鳴らせなかった回数（`miss`）、PDX を読んだ回数、FM に足した結果あふれたサンプル数（[§9.7](#97-adpcm-pcm8-の再生)） |
| `SEQ LAG` | シーケンサが予定時刻から遅れた最大時間。**VGM と MDX で共用**（同時には再生できないので 1 個で足りる） |
| `PIOTEST` | 起動時の PIO ループバック自己診断の結果（[docs §4.6](docs/pico-opm-writer.md#46-起動時の自己診断)）。既定では `SKIP (disabled)`（[§5.4](#54-無効化)）。`i` と `t` では同じものが `# piotest` として出る |
| `IRQ` | OPM の /IRQ の現在のレベル |

`E0` / `RXSTALL` / `RATE` は、ロジックアナライザを繋がずにキャプチャ経路の健全性を
確かめるための指標。

**`CPU` は「残りどれだけ余裕があるか」の指標ではない。** メインループはやる事が無くても
回り続けるビジーループなので、1 周あたりの費用を削れば周回数 (`LOOP`) が増えて割合は
元に戻る。**この値だけを見て負荷が減った / 増えたと判断しないこと。** 実際に使っている
時間の絶対量を見たいときは `STATS_PROFILE=1` で焼く（[§3.11.1](#3111-サービスの呼び出し間隔)）。

**余裕の有無は `LOOP` の `MAX` / `AUDIO GAP max` と、`I2S` の `MIN` / `UNDERRUN`、
それに `RATE` で見ること。** 前者が原因（サービスが最大どれだけ空いたか）、
後者が結果（そのぶん先行量がどこまで削れたか）にあたる。`AUDIO GAP max` が
I2S の先行量 1024 フレーム（16.4ms）に近づいてきたら余裕が尽きかけている。

`s 0` は high-water / low-water とカウンタ（`LOOP MAX` / `AUDIO GAP max` / `OPMW` を
含む）に加えて、`MDX PCM` 行の `keyon` / `miss` / `reads` / `CLIP` も 0 に戻す（`keyon` / `miss` / `reads` は `mdx play` でも 0 に戻る）。

#### 3.11.1 サービスの呼び出し間隔

メインループは各サービスを**毎周回ではなく最短間隔を決めて**回す。DAC から届く
フレームは 62500/s なのに対しループは数十万周/秒あり、毎周回回すと 1 回あたり
1 フレーム未満のために毎回支度をすることになって、固定費だけで CPU の大半を使う。

| グループ | 間隔 | 決め手 |
| --- | --- | --- |
| `tud_task()` | 125µs | PCM 出力のパケットレート。64 バイト / 250KB/s = 256µs が下限で、その 2 倍 |
| 音声チェーン（リング取り込み / ADPCM / キャプチャ送出 / I2S 供給） | 500µs | 間隔を延ばすほど固定費は下がるが I2S の先行量の谷が深くなる。500µs で 31 フレーム |
| シーケンサ（VGM / MDX）と曲の終わり方・曲送り | 50µs | この間隔ぶんが `SEQ LAG` に乗る。曲の終わり方（[§3.22](#322-曲の終わり方)）と曲送り（autoplay）は同じ周回でシーケンサの後に、この順で見るので、更新された再生状態をそのまま読める |
| ストレージの書き出し | 1000µs | 判断はもともと 250ms のアイドル期限 |
| ボタンの取り込み（GP21 / GP22） | 1000µs | デバウンスの窓 10ms に対して 10 サンプル取れ、1 秒の長押し判定に対しては十分粗い（[§3.20](#320-ボタンgp21--gp22)） |

いずれもリング一周 65.5ms よりはるかに短いので、DMA の位置は見失わない。
値はソースの `AUDIO_SERVICE_INTERVAL_US` などの `#define` 1 箇所で決まる。

**ここに書いてあるのは「最短でもこの間隔を空ける」であって、上限ではない。**
コマンドの応答やシーケンサの予算ループで 1 周が伸びれば、実際の間隔はこれより
長くなる。**実際にどこまで空いたかは `s` の `LOOP MAX` と `AUDIO GAP max` に出る**
（実測で公称 500µs に対し 1.5ms 前後）。I2S の先行量 1024 フレーム = 16.4ms が
その上限なので、`AUDIO GAP max` がそこへ近づいてきたら間隔か処理量を見直すこと。

サービスごとの滞在時間を絶対量 (µs/s) で見たいときは、プロファイルを有効にして焼く。

```bash
cmake -S . -B build -G Ninja -DCMAKE_BUILD_TYPE=Release -DPICO_BOARD=pico2 -DSTATS_PROFILE=1
```

`s` に `SVCTIME` と `OPMW` の 2 行が増える。どちらも区間ごとに時刻を 2 回読むぶん
本体より重くなるので、**常用はしない**。

```
# SVCTIME : pcm8 18302  cap 3042  i2s 23610  vgm 4886  mdx 34447  sto 169  us per s
# OPMW    : 727 writes/s  23407 us/s  avg 32.19 us  max 46 us
```

`OPMW` は OPM バスの 1 レジスタ書き込みの実費用。**`avg`（`us/s` ÷ `writes/s`）が
`opm_write()` 1 回の所要時間そのもの**なので、[opm.h](src/opm.h) のタイミング定数を
変えたときの前後比較はここで行う（[test/opm_busy/](test/opm_busy/README.md) の
ベンチマークと同じ量を実再生で測ったもの）。`max` は 1 回の最大値で、
USB の割り込みが挟まった回が出る。

### 3.12 `t`（自己テスト）

外部機器を使わずに実行できる自己テストをまとめて走らせる。

```
> t
# pcm     : PASS
# piotest : SKIP (disabled)
# mdx     : PASS (7 pitch, 5 tempo)
# adpcm   : PASS (19 cases)
OK
```

| 項目 | 内容 |
| --- | --- |
| `pcm` | PCM 変換の既知ベクタ検証。ゼロ / ±1 / 仮数境界 / 指数全域 / 禁止コード / 無効 3bit のマスク / 値域の両端。加えて全 `E`・全仮数でステップが `1 << (E-1)` になることを総当たりで確認する |
| `piotest` | 起動時に実施した PIO ループバック自己診断の結果（[docs §4.6](docs/pico-opm-writer.md#46-起動時の自己診断)）。**I2S が有効な既定構成では GP26-GP28 が競合するので実施せず `SKIP (disabled)` になる**（[§5.4](#54-無効化)） |
| `mdx` | MDX の音程 → KC/KF 変換と、Timer-B 値 → 1 clock の長さの既知ベクタ検証。KC の下位 4bit が 3/7/11/15 を飛ばす境界とオクターブ跨ぎを含む（[§9.4](#94-音程と音量の作り方)） |
| `adpcm` | MSM6258 の ADPCM デコーダの既知ベクタ検証。ステップ幅の表・符号ビット・12bit の飽和・段番号の上下端での頭打ちを含む。加えてレート比が全モードで整数であることと、音量 8 が原音（ゲイン 1.0）であることを確かめる（[§9.7](#97-adpcm-pcm8-の再生)） |

どれかが失敗したら `ERR self test failed` を返す。

機能をビルド時に落としてある場合、その項目は `SKIP (disabled)` になる（失敗ではない）。
`MDX_ENABLED=0` なら `mdx` と `adpcm` が、`PCM8_ENABLED=0` なら `adpcm` が
`SKIP (disabled)` になる（[§9.8](#98-無効化)）。

### 3.13 `storage`（ストレージ）

内蔵フラッシュ上の FAT ファイルシステムを、**Pico 側（FatFs）と PC 側（USB MSC）の
どちらが持つか**を排他で切り替える。詳しくは [§7](#7-ストレージ) を参照。

| コマンド | 説明 |
| --- | --- |
| `storage` / `storage status` | 現在の状態を表示する |
| `storage host` | フラッシュを PC へ渡す。PC にリムーバブルディスクとして現れる |
| `storage player` | フラッシュを Pico 側へ戻す。FatFs をマウントし直す |
| `storage format yes` | 領域を作り直す。既にファイルシステムがある場合は `storage format force yes` |
| `storage trace` | 直前に PC が投げた SCSI コマンドの記録を表示する（[§7.4](#74-マウントされないときの調べ方)） |

**`storage host` / `storage player` は冪等**で、既にそのモードなら何もせず `OK` を返す。
どちらも切り替え後のモードを 1 行出してから `OK` を返す。

**SW1 と SW2 の同時長押しでも `storage host` に入れる**（[§3.20](#320-ボタンgp21--gp22)）。
ボタン経由では自動再生・VGM・MDX を先に止めてから入るので、下記の拒否のうち残るのは
キャプチャ中だけになる。**HOST 中の LED は 200ms ON / 800ms OFF** になる
（[§3.9](#39-led)）ので、PC を見なくてもどちらのモードかが分かる。

```
> storage host
# storage : HOST
OK
```

`storage` / `storage status` の出力例:

```
# storage : PLAYER
# medium  : not present
# audio   : enabled
# region  : flash 0x040000 + 3836 KiB  (LBA 512 B x 7672)
# firmware: end 0x1001c654 (116308 B)  gap 142 KiB
# fs      : FAT12  cluster 4096 B  free 3808/3816 KiB
# label   : PICOOPM
# cache   : 8 lines  dirty 0
# flash   : WRITE 13   BLACKOUT max 39976 us
OK
```

| 項目 | 内容 |
| --- | --- |
| `storage` | `PLAYER`（Pico が持つ） / `HOST`（PC が持つ） |
| `medium` | MSC にメディアが入っていると見せているか。`HOST` のときだけ `present` |
| `audio` | PCM キャプチャと I2S 出力が使えるか。`HOST` 中は無効 |
| `region` | フラッシュ上の領域と論理セクタの構成 |
| `firmware` | ファームウェア末尾のアドレスと、領域先頭までの余裕 |
| `fs` | FAT の種類・クラスタ長・空き容量。未フォーマットなら `no filesystem` |
| `label` | ボリュームラベル |
| `cache` | ライトバックキャッシュの行数と、未書き出しの行数 |
| `flash` | 4KiB ブロックの書き出し回数と、その間メインループが止まった最大時間 |

**`storage host` は、VGM 再生中・MDX 再生中・PCM キャプチャ中だと `ERR wrong state` で
拒否する。** どれで落ちたかは直前の `# hint` 行に出る。先に `vgm stop` / `mdx stop` /
`p 0` を実行すること（[§3.19](#319-状態による拒否の一覧)）。

```
> storage host
# hint    : cannot switch while VGM is playing; run vgm stop first
ERR wrong state
```

`HOST` 中は次のものが使えない。フラッシュの消去でメインループが数十 ms 止まり、
キャプチャの DMA リング（65.5ms 分）と I2S の先行量（16.4ms 分）を守れないため。

* `p 1`（PCM キャプチャ）
* I2S 出力（無音になる。BCK / LRCK は止めないので DAC はポップしない）
* `vgm list` / `vgm play` / `mdx list` / `mdx play`（ファイルシステムがアンマウントされている）
* `storage format`

`PLAYER` へ戻した時点で音声経路を復帰させ、キャプチャと I2S のリング位置を張り直す。

### 3.14 `vgm`（VGM 再生）

`/VGM/` に置いた VGM ファイルを再生する。演奏対象は **YM2151 の部分だけ**で、
他の音源のコマンドは読み飛ばす。gzip 圧縮された `.vgz` も一時ファイルを作らずに
そのまま再生できる（[§8.5](#85-vgzgzipの再生)）。詳しくは [§8](#8-vgm-再生) を参照。

| コマンド | 説明 |
| --- | --- |
| `vgm` / `vgm status` | 再生状態を表示する |
| `vgm list` | `/VGM/` **以下**の `.vgm` と `.vgz` を並べる。サブフォルダも辿る |
| `vgm play <path>` | `/VGM/<path>` を再生する。`/VGM/` は付けない。`<path>` は `/VGM/` からの相対パス |
| `vgm stop` | 再生を止めて全チャンネルをキーオフする。RR を 15 にしてから落とすので速やかに消える。**冪等**（停止中でも `OK`。曲が自然に終わったあとの余韻もこれで消せる） |
| `vgm loop` / `vgm loop <n>` | 何周したらフェードアウトして終わるかの表示 / 設定。10 進、`0`-`99`。**`0` は無限**（既定）で、ループを持つ曲は止まらない |
| `vgm fade` / `vgm fade <ms>` | フェードアウトの長さの表示 / 設定。10 進、`0`-`60000`（既定 `2000`）。`0` はフェードせず即停止 |

```
> vgm
# vgm     : PLAYING AFTERBURNER.VGM
# pos     : 507150/2205000 samples  loop 7
# lag     : reslip 0  gz reload 0
# end     : loop endless  fade 2000 ms
# song    : PLAYING
OK
```

`.vgz` を再生中なら 1 行目の末尾に `(gzip)` が付く。`# pos` / `# lag` と同じ内容は
`s` の `VGM` / `VGM POS` / `VGM LAG` の 3 行にもある（[§3.11](#311-s統計)）。
`# end` は上の `vgm loop` / `vgm fade` の現在値、`# song` は曲の終わり方の状態で、
どちらも [§3.22](#322-曲の終わり方) を参照。

```
> vgm loop 2
# end     : loop 2  fade 2000 ms
OK
```

```
> vgm list
# file    :   1234567 AFTERBURNER.VGM
# file    :    234567 OUTRUN.VGZ
# file    :    345678 KONAMI/GRADIUS.VGM
# file    :    456789 KONAMI/OLD/TWINBEE.VGM
# file    :    567890 SEGA/OUTRUN.VGM
# files   : 5
OK

> vgm play KONAMI/GRADIUS.VGM
# vgm     : version 1.51  samples 2205000  loop yes
# clock   : file 3579545 Hz / phiM 4000000 Hz (pitch goes up)
OK
```

サイズを先に置き、ファイル名を必ず最後の欄にしてある（名前に空白を含みうるため）。
`.vgz` のサイズは圧縮された状態のバイト数。

#### サブフォルダの扱い

`vgm list` / `mdx list` は `/VGM/` `/MDX/` の**下の階層も辿る**。出す名前はルートからの
相対パスで、区切りは `/`。並びは**深さ優先**で、あるフォルダのファイルを名前順（大小無視）に
出し切ってから、サブフォルダを名前順に 1 つずつ降りる。上の例なら `KONAMI/GRADIUS.VGM` が
`KONAMI/OLD/TWINBEE.VGM` より先に来る。

`vgm play` / `mdx play` にも同じ相対パスをそのまま渡せる。上限は 2 つ:

| 制限 | 値 |
| --- | --- |
| 相対パスの長さ | 127 文字 |
| 階層の深さ | 8 段（`/VGM` 自身を 1 段目と数えるので、その下は 7 段まで） |

超えたものは一覧にもプレイリストにも出さず、`# files` 行の前に警告を出す。

```
# warn    : skipped 3 path(s) longer than 127 chars
# warn    : skipped 1 directory(s) deeper than 8 levels
```

`.` で始まるフォルダ（macOS が作る `.Spotlight-V100` など）と、隠し属性・システム属性の
付いたフォルダには潜らない。

`vgm list` は 256 件で打ち切る。打ち切ったときは `# files` 行の前に警告が出る
（`mdx list` も同じ上限）。

```
# warn    : truncated at 256 entries
# files   : 256
```

デュアルチップの VGM は 2 個目のチップを無視するので、`vgm play` が警告を出す
（[§8.1](#81-対応範囲)）。

```
# warn    : dual chip file; the second chip (0xA4) is ignored
```

`.vgz` を再生すると `# vgm` 行の末尾に `gzip` が付く。

```
> vgm play OUTRUN.VGZ
# vgm     : version 1.51  samples 1852000  loop yes  gzip
OK
```

**再生中は `w` / `reset` / `c` と `storage host` を `ERR wrong state` で拒否する。**
VGM とユーザーのレジスタ書き込みが混ざると何が鳴っているのか分からなくなるため。
`p 1` / `p 0` / `s` / `i` / `t` / `d` は再生中も使える（VGM を鳴らしながら
CDC #1 へ録音できる）。全体は [§3.19](#319-状態による拒否の一覧)。

**`vgm play` / `mdx play` は再生中でも受け付ける。** 走っている方を止めてから
新しいファイルを開くので、曲を変えるのは 1 コマンドで済む。止めた曲は 1 行で報告する。

```
> vgm play OUTRUN.VGM
# vgm     : stopped AFTERBURNER.VGM
# vgm     : version 1.51  samples 1852000  loop yes
OK
```

**新しいファイルを開けなかったときは前の曲へは戻らず、停止状態で終わる。**
`stopped` の行が出るので、応答だけで前の曲が止まったことが分かる。

```
> vgm play NOSUCH.VGM
# vgm     : stopped OUTRUN.VGM
ERR not found
```

ファイル名の書式が不正なとき（`ERR bad argument`）だけは、ファイルを開く前に弾くので
前の曲がそのまま鳴り続ける。

ループを持たないファイルはデータの終端で自動的に止まる。全チャンネルをキーオフして
ファイルを閉じ、状態は `STOPPED` に戻る。再生を始めたあとにファイルの中身が壊れて
いると分かった場合は、`OK` を返したあとなので非同期通知になり、状態は `ERROR` になる。
どちらも [§3.18](#318-非同期通知) を参照。

### 3.15 `mdx`（MDX 再生）

`/MDX/` に置いた MDX ファイル（X68000 の MXDRV 用のバイナリ MML）を再生する。
**FM 8ch と ADPCM 8ch** を鳴らす。ADPCM は本機にハードウェアが無いのでソフトウェアで
デコードし、FM の出力に足して I2S と PCM キャプチャへ流す。
詳しくは [§9](#9-mdx-再生) を参照。

| コマンド | 説明 |
| --- | --- |
| `mdx` / `mdx status` | 再生状態を表示する |
| `mdx list` | `/MDX/` **以下**の `.mdx` を並べる。サブフォルダも辿る。256 件で打ち切る |
| `mdx play <path>` | `/MDX/<path>` を再生する。`/MDX/` は付けない。`<path>` は `/MDX/` からの相対パス |
| `mdx stop` | 再生を止めて全チャンネルをキーオフする。RR を 15 にしてから落とすので速やかに消える。**冪等**（停止中でも `OK`。曲が自然に終わったあとの余韻もこれで消せる） |
| `mdx loop` / `mdx loop <n>` | 何周したらフェードアウトして終わるかの表示 / 設定。10 進、`0`-`99`。**`0` は無限**（既定） |
| `mdx fade` / `mdx fade <ms>` | フェードアウトの長さの表示 / 設定。10 進、`0`-`60000`（既定 `2000`）。`0` はフェードせず即停止 |
| `mdx pcm` | ADPCM ミキシングの状態を表示する |
| `mdx pcm on` / `mdx pcm off` | ADPCM を足す / 足さない（FM だけの音と聴き比べる用） |

```
> mdx
# mdx     : PLAYING GRADIUS.MDX
# title   : グラディウス / KONAMI
# pos     : 12345 clocks  loop 0  ch 9
# tick    : @t 200  14336 us  reslip 0
# end     : loop endless  fade 2000 ms
# song    : PLAYING
OK
```

同じ内容は `s` の `MDX` / `MDX POS` / `MDX TICK` の 3 行にもある
（[§3.11](#311-s統計)）。ADPCM の詳細は `mdx pcm` の方に出る。

```
> mdx list
# file    :      8192 GRADIUS.MDX
# file    :     12345 XEVIOUS.MDX
# file    :      6543 ZOOM/OVERTAKE.MDX
# files   : 3
OK

> mdx play GRADIUS.MDX
# mdx     : GRADIUS.MDX
# title   : グラディウス / KONAMI
# ch      : 9  voices 12
OK
```

タイトルはファイルに入っている Shift_JIS をそのまま流す。UTF-8 の端末では化けるので、
必要なら端末側で文字コードを切り替える。`ch` は 9（FM 8 + ADPCM 1）か
16（FM 8 + ADPCM 8。PCM8 拡張）のどちらか。

PDX（ADPCM の波形集）を要求する曲では、その名前と、実際に開いたファイルが出る。

```
> mdx play THEXDER.MDX
# mdx     : THEXDER.MDX
# title   : THEXDER
# ch      : 9  voices 20
# pdx     : THEXDER
# pdxpath : /MDX/THEXDER.PDX
OK
```

`# pdx` は MDX のヘッダが要求している名前、`# pdxpath` は実際に開いたファイル。
探す順と置き方は [§9.7](#97-adpcm-pcm8-の再生)。

PDX が見つからないときはエラーにはならず、FM パートだけがそのまま鳴る。

```
# pdx     : THEXDER
# hint    : cannot open /MDX/THEXDER.PDX (not found); the ADPCM part will not sound
```

`mdx pcm` で ADPCM の状態が見える。

```
> mdx pcm
# adpcm   : on
# pdxpath : /MDX/THEXDER.PDX
# active  : 2 ch  mask 03  pan L+R
# keyon   : 128   miss 0
# reads   : 647   clip 0
OK
```

`keyon` は ADPCM の発音を開始した回数、`miss` は鳴らそうとして波形が見つからなかった
（または音量 0 になった）回数。**ADPCM が終盤にしか出てこない曲もある**ので、
「聞こえない」だけでは曲の側の話かファームの側の話か分からない。この 2 つを見れば
聴かずに切り分けられる。カウンタは `mdx play` と `s 0` で 0 に戻り、曲が終わったあとも残る。

`mdx pcm off` は**電源を切るまで残る**。off のまま PDX を要求する曲を再生すると、
`mdx play` が理由を出す。

```
> mdx play THEXDER.MDX
...
# pdxpath : /MDX/THEXDER.PDX
# hint    : ADPCM mixing is off; run mdx pcm on to restore it
```

**再生中は `w` / `reset` / `c` と `storage host` を `ERR wrong state` で拒否する。**
`p 1` / `p 0` / `s` / `i` / `t` / `d` は再生中も使える。
全体は [§3.19](#319-状態による拒否の一覧)。

**`mdx play` は再生中でも受け付ける**（[§3.14](#314-vgmvgm-再生) と同じ）。VGM と MDX を
同時に鳴らすことはできないが、どちらが鳴っていても `play` が止めてから始めるので、
`mdx play` ↔ `vgm play` の行き来も 1 コマンドでできる。

`.mdx` として読めない中身は `ERR bad file`。64KiB を超えるファイルも受け付けない
（`# hint : MDX must be 65536 bytes or less`）。再生を始めたあとに壊れていると
分かった場合は `OK` を返したあとなので非同期通知になる。このとき全チャンネルを
キーオフして PDX も閉じ、状態は `ERROR` になる。

全チャンネルが演奏終了（`0xF1 0x00`）に達すると自動で止まる。ループを持つ曲は
止まらないので `mdx stop` で止める。どの止まり方も 1 行の非同期通知が出る
（[§3.18](#318-非同期通知)）。

### 3.16 `clock`（クロック切り替え）

φM を動作させたまま切り替える。プリセットは [§2](#2-クロック設定-φm) の 2 つ。

| 書式 | 動作 |
| --- | --- |
| `clock` / `clock status` | 現在の φM / sys_clk / プリセット / I2S のレートを表示する |
| `clock 4` | φM 4.000000MHz（sys_clk 144MHz）へ切り替える |
| `clock 3.58` | φM 3.579545MHz（sys_clk 157.5MHz）へ切り替える |
| `clock auto` | `vgm play` でファイルのクロックへ追従する（**既定**） |
| `clock fixed` | 追従を止め、手動で選んだプリセットを保つ |

切り替えたときは `clock` と同じ内容を出してから `OK` を返す。

```
> clock 3.58
# phiM    : 3579545 Hz (clkdiv 22 + 0/256)
# sys_clk : 157500000 Hz
# preset  : 3.58  (vgm auto)
# i2s     : clkdiv 44 + 0/256  rate 55930 Hz  bck 1789772 Hz
# capture : rate 55930 Hz
OK
```

既に同じプリセットのときは何もせずに応答だけを返す（冪等）。プリセット名以外を
渡すと `ERR unknown command`（`clock 5` / `clock 3.6` など）。

**PCM を流している間（`CAPTURING` / `DRAINING`）は `ERR wrong state` で拒否する。**
サンプリングレートがストリームの途中で変わると、ホスト側で出来上がる WAV の時間軸が
黙って狂うため。これは `vgm play` の自動追従にも同じように効き、キャプチャ中に
別クロックの VGM を再生しようとすると再生自体が `ERR wrong state` になる
（同じクロックなら通る）。このとき前の曲は止まったままになる（[§3.14](#314-vgmvgm-再生)）。

```
> clock 3.58
# hint    : cannot switch phiM while capturing PCM; run p 0 first
ERR wrong state
```

**`p 2` の待機中（`WAITING`）は通す。** まだ 1 フレームも流していないので、途中で
レートが変わるストリームがそもそも存在しない。通さないと、ファイル側のクロックを
要求する VGM を `p 2` で録ろうとした時点で `vgm play` が必ず弾かれる
（[docs/opm-record.md](docs/opm-record.md) が使うのはこの経路）。

VGM 再生中は拒否しない。レジスタを叩くわけではなく、変わるのは音程と包絡線の速さだけで、
テンポは 44100Hz の絶対サンプル数で刻んでいるので狂わない。

### 3.17 `autoplay`（自動再生）

`/VGM/` と `/MDX/` のファイルを 1 本のプレイリストに束ねて順に鳴らす。曲が終わったこと・
指定した周回数に達したことをファームウェア側で見張るので、ホストは `autoplay start` を
1 回打つだけでよい。

曲の終わり方そのものは [§3.22](#322-曲の終わり方) の状態機械が持っていて、こちらは
その `IDLE` を待って次の曲へ送るだけ。`autoplay loop` / `autoplay fade` は
自動再生中だけ `vgm loop` / `mdx loop` の代わりに使われる（既定値が違うので
2 系統に分けてある。手動再生は `0` = 無限、自動再生は `2`）。

| コマンド | 説明 |
| --- | --- |
| `autoplay` / `autoplay status` | 状態を表示する |
| `autoplay list` | プレイリストを鳴らす順に並べる。現在の曲に `*` が付く |
| `autoplay start` | プレイリストを作り直して 1 曲目を鳴らす（開始時は間隔を空けない） |
| `autoplay stop` | 自動再生を止める。鳴っている曲も止まる。**冪等**（停止中でも `OK`） |
| `autoplay next` / `autoplay prev` | 次 / 前の曲へ**即座に**移る。フェードも間隔も挟まない |
| `autoplay mode list` / `autoplay mode random` | 曲順。既定は `list` |
| `autoplay loop <n>` | フェードを始めるまでの周回数。`0`-`99`、既定 `2`。`0` は無限 |
| `autoplay fade <ms>` | フェードアウトの長さ。`0`-`60000`、既定 `2000`。`0` はフェードせず即停止 |
| `autoplay gap <ms>` | 曲間の無音。`0`-`60000`、既定 `2000` |
| `autoplay source vgm` / `mdx` / `both` | 対象ディレクトリ。既定は `both` |

```
> autoplay
# autoplay: PLAYING  mode list  source both
# song    : PLAYING
# track   : 3/105  mdx BOS01.MDX
# timing  : loop 2  fade 2000 ms  gap 2000 ms
OK
```

`# song` は鳴っている曲の終わり方の状態で、`vgm status` / `mdx status` に出るものと
同じ（[§3.22](#322-曲の終わり方)）。`# autoplay` が `PLAYING` のままでも、
`# song` は `FADING` や `RINGOUT` を通って `IDLE` になり、そこで次の曲へ送られる。

```
> autoplay list
# entry   : *   1 vgm DEMO.VGM
# entry   :     2 vgm LOOPTEST.VGM
# entry   :     3 vgm KONAMI/GRADIUS.VGM
# entry   :     4 mdx BOS01.MDX
...
# entries : 105
OK
```

#### 曲順

`list` は `/VGM/` 以下の全曲に続けて `/MDX/` 以下の全曲を並べる。それぞれの中は
`vgm list` / `mdx list` と同じ**深さ優先**（[§3.14](#314-vgmvgm-再生)）で、曲名はルートからの
相対パス。`vgm list` と `mdx list` の出力をそのまま繋いだ順になり、`autoplay list` の
並びと一致する。

`random` は `autoplay start` のたびにシャッフルし、最後まで行くと並べ直す。並べ直した
直後に同じ曲が 2 回続かないようにしてある。

プレイリストは `autoplay start` のときだけ作る。`autoplay source` や `autoplay mode` を
変えたあと、あるいは PC からファイルを足したあとは、`autoplay start` を打ち直す。
上限は 512 件で、相対パスの合計が 24KiB を超えるか 512 件に達すると
`# warn    : truncated at <件数> entries` を出して打ち切る。パスが 127 文字を超える曲と
8 段より深いフォルダは `vgm list` / `mdx list` と同様にプレイリストにも入らず、
`autoplay start` が同じ `# warn` を出す（[§3.14](#314-vgmvgm-再生)）。

#### 次の曲へ移る条件

**`# song` が `IDLE` になったら次へ送る**（[§3.22](#322-曲の終わり方)）。そこへ至る道は 2 つ。

- **曲が終わった。** ループを持たない VGM の終端、MDX の全チャンネルの演奏終了、
  どちらも再生系が自分で止まるのをそのまま使う。再生中に壊れていると分かって
  `ERROR` に落ちた場合も次へ送る。
- **`autoplay loop <n>` の周回数に達した。** ループカウンタが `n` に達した時点
  （`n` 周を弾き終えて `n+1` 周目に入った瞬間）からフェードアウトを始め、
  `autoplay fade <ms>` の時間をかけて落としてから止める。`autoplay loop 0` に
  すると周回では止めず、曲の終端でだけ次へ進む。

どちらの場合も、**曲の余韻（`RINGOUT`）が消えるのを待ってから** `autoplay gap <ms>` の
無音を数え始める。曲間の無音は「余韻 → 間隔」の順で、次の曲の頭に前の曲の尾が被らない。

```
# mdx     : end of data
# mdx     : BOS02.MDX
...
# song    : fade out (loop 2)
# song    : end of fadeout
# vgm     : version 1.51  samples 2205000  loop yes
...
```

#### フェードアウトの効く範囲

フェードは **YM3012 から取り込んだ PCM に掛けるデジタルゲイン**で作る。ADPCM を混ぜた
あとの 1 箇所に掛かるので、**I2S 出力（[§5](#5-i2s-出力)）と PCM キャプチャ
（[§4](#4-pcm-出力)）の両方に等しく効く**。

**基板上の YM3012 のアナログ出力には効かない。** Pico は OPM から DAC へのシリアル線を
傍受しているだけで、その経路には入っていない（[§1.1](#11-接続表)）。アナログ側で音が
止まるのは、フェードが終わったあとのキーオフの時点になる。

ゲインを 1.0 へ戻すのはキーオフの後。ただし**キーオフしてもチップはすぐには黙らない**
（全スロットの RR を 15 にしても、リリースが消えるまで最悪 5.5ms かかる）ので、
16ms の猶予を置いてから 4ms かけて戻す。そのぶん曲間の無音が伸びるだけで、次の曲は
`autoplay gap 0` や `autoplay next` でも頭を削られずに始まる。

#### 他のコマンドとの関係

**手で `vgm play` / `mdx play` / `vgm stop` / `mdx stop` を打つと自動再生は降りる。**
選んだ曲だけが鳴り、プレイリストの続きへは進まない。

```
> vgm play TESTTONE.VGM
# autoplay: stopped
# vgm     : version 1.51  samples 66150  loop no
OK
```

**曲を開けなかったときは 1 行出して次の曲へ送る。** プレイリストを一巡しても 1 曲も
鳴らせなければ自動再生ごと止める。キャプチャ中（`p 1`）に φM の違う曲へ進もうとすると
`clockmode` が拒否するので、この経路は普通に通る（[§3.16](#316-clockクロック切り替え)）。

```
# hint    : cannot switch phiM while capturing PCM; run p 0 first
# autoplay: skip BOS01.MDX (wrong state)
...
# autoplay: stopped (no playable file)
ERR wrong state
```

**`storage host` は自動再生中なら拒否する。** 曲間（`GAP`）は VGM も MDX も鳴っていないが、
通したところで次の曲で必ず失敗するので、`autoplay stop` を先に打たせる
（[§3.19](#319-状態による拒否の一覧)）。

設定（`mode` / `source` / `loop` / `fade` / `gap`）は `autoplay stop` では消えず、
電源を入れ直すと既定値に戻る。

#### ボタンからの操作

基板上の SW1 / SW2 で、PC を繋がずに開始・曲順の切り替え・曲送りができる。
どの押し方が何に相当するかは [§3.20](#320-ボタンgp21--gp22) の表にまとめてある。

**長押しは `autoplay start` なので、プレイリストを作り直して 1 曲目から始まる。**
`list` で再生中に SW1 を長押しすると先頭へ戻る。曲順を変えずに送りたいだけなら短押しを使う。

#### 無効化

```bash
cmake -S . -B build -G Ninja -DCMAKE_BUILD_TYPE=Release -DPICO_BOARD=pico2 -DAUTOPLAY_ENABLED=0
```

プレイリスト（約 26KiB）と状態機械がリンクされず、`autoplay` は `ERR unsupported` を
返すようになる。

```
> autoplay start
# hint    : autoplay is disabled at build time (AUTOPLAY_ENABLED=0)
ERR unsupported
```

### 3.18 非同期通知

コマンドの応答とは無関係に、ファームウェア側の都合で出る 1 行の通知。**すべて `#` で
始まる情報行**なので、「1 コマンド 1 応答」（[§3.3](#33-応答)）は崩れない。ホスト側は
情報行として読み飛ばすか、必要なら内容を見ればよい。

| 通知 | 意味 |
| --- | --- |
| `# vgm : end of data` | ループを持たない VGM がデータの終端に達して止まった（[§3.14](#314-vgmvgm-再生)） |
| `# mdx : end of data` | MDX の全チャンネルが演奏終了（`0xF1 0x00`）に達して止まった（[§3.15](#315-mdxmdx-再生)） |
| `# mdx : end of fadeout` | MDX が MML のフェードアウト（`0xE7 0x01`）を完了して止まった |
| `# song : fade out (loop <n>)` | ループ回数が上限に達したのでフェードアウトを始めた（[§3.22](#322-曲の終わり方)） |
| `# song : end of fadeout` | 上のフェードアウトが終わって演奏を止めた |
| `# warn : ringout cut at <ms> ms` | 曲の終わりの余韻が上限まで消えなかったので強制的に消音した（[§3.22](#322-曲の終わり方)） |
| `# warn : ringout gave up at <ms> ms` | 強制消音しても無音にならなかったので余韻を待つのをやめた（[§3.22](#322-曲の終わり方)） |
| `# autoplay: skip <名前> (<理由>)` | 自動再生がその曲を開けなかったので次へ送った |
| `# autoplay: stopped` | 自動再生が降りた。手動の `vgm play` / `mdx play` / `*_stop` でも出る |
| `# autoplay: stopped (no playable file)` | プレイリストを一巡して 1 曲も鳴らせなかった |
| `# storage : ejected by host` | PC がリムーバブルディスクを取り出した。所有権が Pico 側へ戻る（[§7.2](#72-pc-から曲データをコピーする)） |
| `# button  : <ボタン> <長さ>: <実行した内容>` | ボタンの操作を受け付けた（[§3.20](#320-ボタンgp21--gp22)） |
| `# button  : <操作> failed (<理由>)` | ボタンの操作が状態の制約で通らなかった。直前に各モジュールの `# hint` が出る |
| `# capture : done <n> frames` | `p 2` のキャプチャが曲の終わりで自分から止まった（[§3.10](#310-ppcm-出力)） |
| `# capture : abort (<理由>)` | `p 2` のキャプチャが曲の終わりを待たずに打ち切られた。`done` は出ない（[§4.1](#41-取りこぼしたとき-dma-overrun)） |
| `# ERR dma overrun` | キャプチャのリングがあふれて送信を止めた。状態は `ERROR`（[§4.1](#41-取りこぼしたとき-dma-overrun)） |
| `# ERR vgm bad file (<理由> at 0x<位置>)` | 再生中の VGM が壊れていた。状態は `ERROR`（[§3.14](#314-vgmvgm-再生)） |
| `# ERR mdx bad file (<理由> at 0x<位置>)` | 再生中の MDX が壊れていた。状態は `ERROR`（[§3.15](#315-mdxmdx-再生)） |
| `# ERR storage io error` | フラッシュへの書き出しに失敗した（[§7.3](#73-書き込みの仕組みと制約)） |
| `# ERR storage region overlaps firmware (...)` | 起動時。FatFs 領域がファームウェアと重なっているのでマウントも書き込みもしない（[§7.1](#71-領域の変え方)） |

```
# ERR vgm bad file (opcode 0x2f at 0x0001a34c)
# ERR mdx bad file (truncated at 0x00000c34)
# button  : SW1 short: next track
# button  : SW1+SW2 long: storage host
# button  : storage host failed (wrong state)
```

**`# ERR ...` は裸の `ERR ...`（コマンドの応答）とは別物。** 頭の `# ` の有無で
機械的に区別できる。`ERROR` に落ちた状態は `s`（[§3.11](#311-s統計)）や
`vgm` / `mdx` / `p` の状態表示からも読める。

### 3.19 状態による拒否の一覧

`ERR wrong state` になる組み合わせ。**拒否されたときは直前に必ず `# hint` 行が出る**ので、
どの原因で落ちたかは応答だけで分かる。原因は下の 4 列に**自動再生中**を加えた 5 つで、
5 つ目が効くのは `storage host` だけ（下記）。

| コマンド | VGM 再生中 | MDX 再生中 | キャプチャ中 (`p 1` / `p 2`) | `storage host` 中 |
| --- | --- | --- | --- | --- |
| `w` / `reset` / `c` | 拒否 | 拒否 | 可 | 可 |
| `r 0` / `r 1` | 可 | 可 | 可 | 可 |
| `d` / `i` / `t` / `s` / `h` | 可 | 可 | 可 | 可 |
| `p 1` / `p 2` | 可 | 可 | 拒否 | 拒否 |
| `p 0` | 可 | 可 | 可 | 可 |
| `clock 4` / `clock 3.58` | 可 | 可 | **拒否**（`p 2` の待機中は可） | 可 |
| `clock auto` / `clock fixed` | 可 | 可 | 可 | 可 |
| `storage host` | 拒否 | 拒否 | 拒否 | 可（冪等） |
| `storage player` | 可 | 可 | 可 | 可 |
| `storage format` | 可 | 可 | 可 | 拒否 |
| `vgm list` / `mdx list` | 可 | 可 | 可 | 拒否 |
| `vgm play` / `mdx play` | 可（止めて始める） | 可（止めて始める） | 同じ φM なら可 | 拒否 |
| `vgm stop` / `mdx stop` | 可 | 可 | 可 | 可 |
| `autoplay start` | 可（止めて始める） | 可（止めて始める） | 同じ φM なら可 | 拒否 |
| `autoplay next` / `autoplay prev` | 可 | 可 | 同じ φM なら可 | 拒否 |
| `autoplay stop` | 可 | 可 | 可 | 可 |
| `autoplay list` と設定（`mode` / `loop` / `fade` / `gap` / `source`） | 可 | 可 | 可 | 可 |
| 状態表示（`p` / `clock` / `storage` / `vgm` / `mdx` / `mdx pcm` / `autoplay`） | 可 | 可 | 可 | 可 |

読み方の要点:

- **`w` / `reset` / `c` を再生中に拒否する**のは、シーケンサとユーザーの書き込みが混ざると
  何が鳴っているのか分からなくなるため（[§3.14](#314-vgmvgm-再生)）。**読み出しの `r` は
  拒否しない**（レジスタを変えないので、再生中のステータスをそのまま観測できる。
  [§3.21](#321-r読み出し)）。
- **`storage host` を 3 つの状態すべてで拒否する**のは、フラッシュの消去でメインループが
  数十 ms 止まり、キャプチャの DMA リング（65.5ms 分）と I2S の先行量（16.4ms 分）を
  守れないため（[§3.13](#313-storageストレージ)）。
- **キャプチャ中の `clock` 切り替えを拒否する**のは、サンプリングレートがストリームの
  途中で変わるとホスト側で出来上がる WAV の時間軸が黙って狂うため
  （[§3.16](#316-clockクロック切り替え)）。`vgm play` / `mdx play` の自動追従にも
  同じように効くので、**キャプチャ中に別クロックの曲を再生しようとすると再生自体が
  拒否される**（同じクロックなら通る）。**このとき前の曲は既に止まっている。**
- **`p 2` の待機中（`WAITING`）だけは φM の列から外れる。** まだ 1 フレームも
  流していないので `clock 4` / `clock 3.58` も、別クロックの `vgm play` / `mdx play` /
  `autoplay` も通る（[§3.10](#310-ppcm-出力)）。それ以外の列 — `p 1` / `p 2` の拒否も
  `storage host` の拒否も — は待機中かどうかに関わらず表のとおり。
- **`storage host` だけは 5 つ目の原因「自動再生中」も見る。** 曲間（`GAP`）は VGM も
  MDX も鳴っていないので表の 2 列では素通りしてしまうが、通しても次の曲で必ず失敗する
  （[§3.17](#317-autoplay自動再生)）。他のコマンドは自動再生そのものを見ておらず、
  曲が鳴っていれば VGM / MDX の列で、鳴っていなければ通る。
- **`vgm play` / `mdx play` は再生中でも拒否しない。** 走っている方を止めてから
  新しいファイルを開く。開いたあとで失敗したときは前の曲へは戻らず、停止状態で
  `ERR` を返す（[§3.14](#314-vgmvgm-再生)）。
- **`stop` 系と `storage` のモード切り替えは拒否されない。** いずれも冪等で、
  既にその状態でも `OK` を返す（[§3.4](#34-コマンド一覧)）。
- **`autoplay list` と設定系はどの状態でも通る。** どちらも RAM のプレイリストと
  設定値を触るだけで、ファイルシステムを読まないため。**プレイリストの作り直し
  （`autoplay start`）だけはファイルシステムが要る**ので `storage host` 中は拒否される。
- **ボタン経由でも同じ表が効く。** ただしボタンの `storage host` は自動再生・VGM・MDX を
  先に止めてから入るので、**残る拒否要因はキャプチャ中だけ**になる
  （[§3.20](#320-ボタンgp21--gp22)）。キャプチャを止めないのは、`p 1` 中は必ずホストが
  CDC を握っていて `p 0` を打てるため。

ビルド時に落とした機能は `ERR wrong state` ではなく `ERR unsupported` を返す
（[§9.8](#98-無効化)）。

### 3.20 ボタン（GP21 / GP22）

基板上の 3 個のタクトスイッチで、**PC を繋がずに**自動再生とストレージを操作する。

| ボタン | 接続先 | 役割 |
| --- | --- | --- |
| SW1 | GP21 | 自動再生の開始（`list`）と次の曲 |
| SW2 | GP22 | 自動再生の開始（`random`）と前の曲 |
| SW3 | RUN | ハードウェアリセット。**ファームウェアからは見えない** |

SW1 / SW2 は GP21 / GP22 と GND の間に入れるだけでよい（[§1.3](#13-配線上の注意)）。
RP2350 の内部プルアップを張って負論理で読み、チャタリングは時間で除去する。

#### 起動時のモード選択

**ボタンを押しながら起動すると、そのモードで動き始める。** 押しながら USB に電源を
入れるか、SW1 / SW2 を押しながら SW3 でリセットする。

| 押されているボタン | 動作 | LED |
| --- | --- | --- |
| SW1 のみ | `autoplay mode list` + `autoplay start` 相当 | 1 回点滅の繰り返し |
| SW2 のみ | `autoplay mode random` + `autoplay start` 相当 | 2 回点滅の繰り返し |
| SW1 + SW2 | `storage host` 相当 | 3 回点滅の繰り返し |
| なし | 通常起動（従来どおり） | 常時点灯 |

**モードは起動した瞬間の押下で決まり、実行は両方を離してから**行う。離すまでは LED が
上記のパターンで点滅し続けるので、意図したモードになっているかを確かめてから離せる
（違っていたら SW3 で起動し直す）。離したあとに押し足しても、決まったモードは変わらない。

起動時の出力は**ホストが CDC を開く前なので捨てられる**。結果は `i` の `# button` 行に
残るので、後から USB を挿しても分かる（[§3.6](#36-i情報表示の出力例)）。

ファイルシステムが無い基板で SW1 / SW2 起動しても、自動でフォーマットはしない
（`# button : long 1000 ms boot autoplay list (no filesystem)` が残るだけ）。
**SW1+SW2 の `storage host` は未フォーマットでも通る**ので、新品の基板を PC 側で
フォーマットする用途に使える。

#### 動作中の操作

**長押しのしきい値は 1 秒。** 押し続けてしきい値に達した瞬間に成立し、LED が
100ms OFF → 500ms ON → 100ms OFF の合図を出す。**離すのを待たない**ので、
効いたかどうかが押している最中に分かる。合図が出たあとは離すまで何も起きない。
しきい値未満で離した場合は短押しになり、離した瞬間に効く。

| 操作 | 動作 |
| --- | --- |
| SW1 長押し | `autoplay mode list` + `autoplay start` 相当 |
| SW2 長押し | `autoplay mode random` + `autoplay start` 相当 |
| SW1 + SW2 長押し | `storage host` 相当 |
| SW1 短押し | `autoplay next` 相当。**自動再生が止まっていれば SW1 長押しと同じ** |
| SW2 短押し | `autoplay prev` 相当。**自動再生が止まっていれば SW2 長押しと同じ** |
| SW1 + SW2 短押し | **何もしない**（1 行出すだけ） |
| SW3 | 押し下げ時間に関わらずハードウェアリセット |

**長押しでモードを切り替えるときは、元のモードを破棄する。** `storage host` へ入る前に
自動再生と VGM / MDX の再生を止め、自動再生を始める前に `storage player` へ戻す。

**SW1 + SW2 の短押しに動作を割り当てていない**のは、`storage host` が破壊的だから。
曲送りを速く連打したときに誤ってファイルシステムを PC へ渡してしまわないよう、
`storage host` は必ず 1 秒の長押しを要求する。

**`storage host` 中は短押しが効かない。** 抜けられるのは長押しか SW3 のリセットだけ
（[§7.2](#72-pc-から曲データをコピーする)）。

```
# button  : SW1 short: next track
# button  : SW2 long: autoplay random
# button  : SW1+SW2 long: storage host
# button  : SW1+SW2 short: ignored (hold 1 s for storage host)
# button  : SW1 short: ignored (storage is handed to the PC)
```

状態の制約で通らなかったときは、各モジュールの `# hint` に続けて 1 行出す。
拒否の条件はコマンドで打った場合と同じ（[§3.19](#319-状態による拒否の一覧)）。

```
# hint    : cannot switch while capturing PCM; run p 0 first
# button  : storage host failed (wrong state)
```

#### 同時押しの判定

**両方を押すタイミングがずれてもよい。** 押している間に押されたボタンをすべて覚え、
**2 個目が入った時点から 1 秒**を数え直す。SW1 を押してから SW2 を足すまでに
0.5 秒かかっても、SW2 を足した 1 秒後に「SW1 + SW2 の長押し」が成立する。

数え直すのは、そうしないと**片方を長く押しているところへもう片方が滑り込んだ瞬間に
`storage host` が誤爆する**ため（SW1 を単独で押し続けているところへ、しきい値の
0.05 秒前に SW2 が入ると、その 0.05 秒後には両方が押されている状態で 1 秒に
達してしまう）。副作用として、SW1 を 0.9 秒押してから SW2 を足すと
SW1 単独の長押しは成立せず、1.9 秒で同時長押しになる。

離すときのずれは気にしなくてよい。**全部離すまでが 1 回の操作**なので、
SW1 を離してから SW2 を離すまでに間があっても 2 回には分かれない。

#### 制約

- **コマンドの実行中はボタンの操作が遅れる。** 押下の検出（LED の合図）はその場で出るが、
  実行はメインループがコマンドを抜けてから。`d 60000` の待機中なら最大 60 秒、
  `vgm list` / `mdx list` / `autoplay list` の長い出力中ならその終わりまで遅れる。
  古くなったからといって捨てることはしない（押したのに何も起きない方が困るため）。
- **消化しきれていない操作があるうちは、次の操作を捨てる。** 溜めて順に流すと、
  待たされた末に曲が何曲も飛ぶことになるため。
- **`storage format` の実行中の操作は失われる。** 数十秒メインループごと止まるので、
  押したことも離したことも検出されない（遅れるのではなく消える）。

#### 無効化

```bash
cmake -S . -B build -G Ninja -DCMAKE_BUILD_TYPE=Release -DPICO_BOARD=pico2 -DBUTTON_ENABLED=0
```

状態機械がリンクされず、**GP21 / GP22 は初期化もされない**ので他の用途へ回せる。
`i` の表示は `# button  : disabled` の 1 行になる。SW3（RUN）はハードウェアの配線
なので、この設定に関わらずリセットがかかる。

なお**ボタンを実装していない基板でも既定の `BUTTON_ENABLED=1` のままでよい**。
内部プルアップで「離されている」と読めるので、従来と同じ挙動になる。

### 3.21 `r`（読み出し）

/RD を叩いて OPM から 1 バイト読み出す。引数は A0 に出すレベルで、10 進の `0` か `1`。

```
> r 1
# read    : a0=1 data=0x00
OK
> w 10 20      # CLKA
OK
> w 14 05      # LOAD A + IRQEN A でタイマ A を走らせる
OK
> r 1
# read    : a0=1 data=0x01      ← タイマ A のフラグ
OK
> w 14 10      # F-Reset A（LOAD A は落とす）
OK
> r 1
# read    : a0=1 data=0x00
OK
```

`data` は D0-D7 をそのまま 16 進で出す。ビットの意味づけはしないので、
必要ならホスト側で分解する。

- **`r 1`（A0=1）がデータシート上のステータスレジスタ。** bit7 = BUSY、bit1 = タイマ B の
  フラグ、bit0 = タイマ A のフラグ。
- **`r 0`（A0=0）の読み出しはデータシートに規定が無い。** 実測では**直前に Pico 側が
  D0-D7 へ駆動した値がそのまま返る**（`w 14 05` の直後は `0x05`、`w 14 10` の直後は
  `0x10`、MDX 再生中はシーケンサが最後に書いた値）。OPM は A0=0 では D0-D7 を駆動して
  おらず、開放されたバスに残った電荷を読んでいるものと考えられる。**値に意味は無い。**

読み出しの間だけデータバスの向きが入れ替わる。OPM に駆動させる前に Pico 側を入力へ倒し、
/RD を H に戻して OPM がバスを手放してから出力へ戻すので、バスは衝突しない
（[§1.3](#13-配線上の注意)、[docs §3](docs/pico-opm-writer.md#3-opm-バスシーケンス)）。
1 回の読み出しに掛かる時間は約 2µs。

**レジスタを変えないので、再生中でも拒否しない**（[§3.19](#319-状態による拒否の一覧)）。
VGM / MDX を鳴らしたままステータスを覗ける。

**`w` の BUSY 待ちには使っていない。** `opm_write()` はデータサイクル後に
`OPM_BUSY_CYCLES`（72 φM サイクル = 4MHz で 18.0µs / 3.579545MHz で 20.1µs）待つ方式で、
ステータスはポーリングしない。BUSY 長が**レジスタにもチップの状態にも依存せず一定**
であることが実測で確定しているため、ポーリングには副作用しか無い
（[docs §3.1](docs/pico-opm-writer.md#31-タイミング定数)、
[test/opm_busy/](test/opm_busy/README.md)）。実効値は `i` の `# timing` 行に出る。

### 3.22 曲の終わり方

VGM も MDX も、曲がどう終わるかは 1 つの状態機械で決まる。`vgm status` /
`mdx status` / `autoplay status` の `# song` 行がその状態。

```
            play                 loop 上限          fade 期限
  IDLE ───────────> PLAYING ─────────────────> FADING ─────────┐
   ▲                  │                                        │
   │                  │ 自然終了 / stop / 壊れていた             │
   │                  ▼                                        ▼
   └───── 無音 ──── RINGOUT <───────────────────────────────────┘
                      │
                  play（曲送り / 次の曲）──> PLAYING
```

余韻を待っている最中に次の曲が始まったら、待たずに `PLAYING` へ戻る
（`autoplay next` や `autoplay gap 0` がこの経路）。

| 状態 | 意味 |
| --- | --- |
| `IDLE` | 鳴っていない |
| `PLAYING` | 演奏中 |
| `FADING` | ループ回数が `loop` に達してフェードアウト中。演奏はまだ続いている |
| `RINGOUT` | 演奏は止まった。**余韻が消えるのを待っている** |

#### ループ回数で終わらせる

`vgm loop <n>` / `mdx loop <n>` を `0` 以外にすると、その回数だけ周回したところで
`fade` ミリ秒かけてフェードアウトし、演奏を止める。**既定は `0`（無限）**なので、
何も設定しなければ従来どおりループを持つ曲は止まらない。

フェードアウトは出力ゲインで作るので、**I2S 出力と USB キャプチャにしか効かない。**
YM3012 のアナログ出力はフェードが終わるまで元の音量のままで、音が消えるのは
そのあとのキーオフ（[§5](#5-i2s-出力)）。

自動再生には `autoplay loop` / `autoplay fade` という別の設定があり、自動再生中は
そちらが優先される（[§3.17](#317-autoplay自動再生)）。既定値が違う（手動再生は
`0` = 無限、自動再生は `2`）ので 2 系統に分けてある。

#### 曲の終わりの余韻

**曲データが尽きたとき、ファームウェアは OPM に何も書かない。** 最後の音は音色本来の
RR で自然に減衰する（[§9.1](#91-対応範囲)）。`RINGOUT` はその減衰が終わるのを待つ状態で、
出力が 100ms のあいだ無音のままなら `IDLE` へ移る。100ms 必要なのは、波形が 1 周期に
2 回ゼロを通るため（可聴下限の 20Hz = 50ms 周期を跨ぐ長さが要る）。

RR が小さい音色が鳴ったまま曲が終わると減衰しないので、**5 秒で打ち切って強制的に
消音する**。このとき `# warn : ringout cut at 5000 ms` を出す。

強制消音しても 10 秒までに無音にならなければ、**待つのをやめて `IDLE` へ移る**
（`# warn : ringout gave up at 10000 ms`）。`RINGOUT` に留まり続けると
`songend_is_active()` が落ちず、キャプチャの終端も曲送りも同時に止まってしまうため、
状態機械に袋小路を作らない。

`vgm stop` / `mdx stop` は状態に関わらず消音するので、余韻の途中でも即座に止められる。
次の曲を `play` したときも、その先頭で全レジスタがクリアされて切れる。

#### 誰がこの状態を見るか

- **自動再生の曲送り** — `IDLE` になってから曲間の無音（`autoplay gap`）を数え始める。
  次の曲の頭に前の曲の尾が被らない
- **演奏に連動したキャプチャ**（`p 2`）— `IDLE` になった時点で WAV を閉じる
  （[§3.10](#310-ppcm-出力)）

どちらも同じ状態を見ているので、**キャプチャの終端と曲送りの時刻は必ず一致する。**

## 4. PCM 出力

OPM が YM3012 (DAC) へ送るシリアル出力を取り込み、PCM に変換して CDC #1 へ流す。
`p 1` / `p 0`（[§3.10](#310-ppcm-出力)）で送信を制御する。

| 項目 | 値 |
| --- | --- |
| 形式 | signed 16bit little-endian、ステレオインタリーブ（L, R, L, R, …） |
| サンプリングレート | **φM / 64**（既定の φM 4MHz なら 62500 Hz） |
| 値域 | **−32768 〜 +32704** |
| チャネル | YM3012 の CH1 = **L**、CH2 = **R** |

- ヘッダは付かない。CDC #1 を開いて読んだバイト列がそのまま PCM になる。
- **正側が +32767 に届かないのは YM3012 の仕様どおり**（最大値は `511 << 6 = 32704`）。
  正規化してはいけない。
- サンプリングレートは φM に比例するので、`OPM_CLOCK_MODE_NTSC`（φM 3.579545MHz）では
  55930.4 Hz になる。WAV に書き出すときはこのレートを使う。

変換の仕組みとフレーム構造は
[docs §4](docs/pico-opm-writer.md#4-ym3012-dac-キャプチャ) にある。

### 4.1 取りこぼしたとき (DMA overrun)

**取り込みは常時動いていて、ファーム内のリングバッファは 65.5ms 分しかない**（φM 4MHz で
4096 フレーム）。`p 1` の間、ホストは CDC #1 を読み続ける必要がある。

読み落としてリングが一杯になると、壊れたデータを送り続けないよう次のように振る舞う。

1. 送信を停止する（`s` の `STATE` が `ERROR` になる）
2. コマンド側の CDC #0 へ `# ERR dma overrun` を出す
3. `p 2`（演奏連動）で始めていたなら、続けて `# capture : abort (dma overrun)` を出す。
   この経路では `# capture : done` を出せないので、**これが終端の合図になる**
4. LED をエラー表示にする（[§3.9](#39-led)）
5. 次の `p 1`（または `p 0`）を受けるまで止まったまま

`# ` 始まりの情報行として出すので、「1 コマンド 1 応答」（[§3.3](#33-応答)）は崩れない
（[§3.18](#318-非同期通知)）。発生回数は `s` の `OVERRUN` に残る。
復帰は次の `p 1` でも、`p 0` で待機へ戻してからでもよい。

[tools/opm-writer.py](docs/opm-writer.md) の `!capture` を使えば、読み出しは
スクリプト側が面倒を見る。

## 5. I2S 出力

キャプチャした PCM をそのまま I2S で外部 DAC (PCM5102A) へ流す。**電源を入れれば常に
出力していて、開始も停止もコマンドは無い**。レジスタを書けばその場で音が出る。

USB キャプチャ（[§4](#4-pcm-出力)）とは独立した読み出し位置を持つので、`p 1` で
キャプチャしながら鳴らしても互いに干渉しない。

### 5.1 DAC の配線

| Pico 2 | PCM5102A | 備考 |
| --- | --- | --- |
| GP26 | BCK | ビットクロック |
| GP27 | LRCK / WS | ワードセレクト。**GP26 の次の GPIO であること**（PIO の sideset 2bit に載せる） |
| GP28 | DIN | データ |
| GND | SCK | **GND へ落とす。** SCK を L にすると内蔵 PLL が BCK からシステムクロックを作る |
| — | XSMT | H 固定（ソフトミュートは使わない）。多くのブレークアウト基板は既定で H |

MCLK (SCK) を DAC 内部で作らせるので、Pico から出すのは 3 本だけ。

### 5.2 フォーマット

| 項目 | 値 |
| --- | --- |
| フォーマット | Philips 標準 I2S、MSB first、16bit |
| BCK | 32fs（φM 4MHz で 2.000 MHz） |
| サンプリングレート | φM/64 = 62500 Hz（`OPM_CLOCK_MODE_NTSC` では 55930.4 Hz） |
| チャンネル | LRCK=0 が L (YM3012 CH1) / LRCK=1 が R (CH2) |
| レイテンシ | 1024 フレーム = 16.4 ms |

62.5kHz は標準的なレートではないが、PCM5102A は内蔵 PLL が BCK に追従するので
そのまま鳴る（対応範囲 8k〜384kHz）。

**サンプリングレートは変換していない。** φM も I2S も同じ sys_clk から分周しているため、
キャプチャ側と出力側のレートは厳密に一致する。リサンプリングもドリフト補正も無く、
固定長のバッファを挟むだけで済む。分周比の導出は
[docs §5.2](docs/pico-opm-writer.md#52-サンプリングレートのロック)。

L と R は同じ波形にならない（[test/dac_lr/](test/dac_lr/README.md)）。これは YM3012 の
仕様どおりで、I2S 出力もそのまま両チャンネルを出している。

### 5.3 アンダーラン

I2S へ供給する DMA は止まらないので、CPU がリングを埋め遅れると **DMA は無音ではなく
古いリング内容を再生する**。検出したら未処理を捨てて先行分を無音で埋め直し、
`s` の `UNDERRUN` を 1 増やす（[§3.11](#311-s統計)）。一瞬ノイズが出るが継続はしない。

余裕は 16.4ms あるので、通常の動作では起きない。`s` の `I2S` の `MIN`（先行量の
low-water）がどこまで削れたかの指標になる。

OPM を繋がずに動かした場合はソースが供給されないため、16.4ms ごとにアンダーランを
繰り返す。出力は無音のままで、`UNDERRUN` だけが増え続ける。

**`reset`（/IC リセット）を実行すると必ず 1 回アンダーランする。** /IC の間は YM3012 が出力を
止めてソースが 10ms ぶん欠け、`opm_reset()` の待ちの間はリングを補充できないので、
先行量 16.4ms を使い切る。リセット直後に一瞬ノイズが出るだけで継続はしない。
**`UNDERRUN` はリセットした回数だけ増えるので、値を見るときは `s 0` でリセットしてからの
差分で見ること。** 内訳は [docs §5.4](docs/pico-opm-writer.md#54-アンダーラン) にある。

### 5.4 無効化

`I2S_ENABLED=0` で再コンフィグすると I2S を止め、GP26-GP28 を解放できる。

```bash
cmake -S . -B build -G Ninja -DCMAKE_BUILD_TYPE=Release -DPICO_BOARD=pico2 -DI2S_ENABLED=0
```

このとき起動時の PIO ループバック自己診断が自動的に有効になる
（[docs §4.6](docs/pico-opm-writer.md#46-起動時の自己診断)）。診断は GP26-GP28 を使うので
I2S とは同時に使えず、**I2S が有効な既定構成では `i` / `t` の `# piotest` と `s` の
`# PIOTEST` が `SKIP (disabled)` になる**。DAC を外して診断だけ試したいときは
`-DYM3012_LOOPBACK=1` を付ける。

## 6. ビルドと書き込み

**配布されている zip を焼くだけならビルドは要らない。[§6.6](#66-リリース版の-zip-を使う) を読むこと。**

ツールチェーンは `~/.pico-sdk/` 配下にバージョン固定でインストールされている。
**システムの cmake / ninja / arm-none-eabi-gcc は使わない。**

| 用途 | パス |
| --- | --- |
| cmake | `~/.pico-sdk/cmake/v4.3.4/bin/cmake` |
| ninja | `~/.pico-sdk/ninja/v1.13.2/ninja` |
| toolchain | `~/.pico-sdk/toolchain/15_2_Rel1/bin` |
| picotool | `~/.pico-sdk/picotool/2.3.0/picotool/picotool` |
| openocd | `~/.pico-sdk/openocd/0.12.0+dev` |

VS Code のターミナルでは `.vscode/settings.json` がこれらを PATH と環境変数に設定する。
CLI から直接叩く場合は自分で export する:

```bash
export PICO_SDK_PATH=~/.pico-sdk/sdk/2.3.0
export PICO_TOOLCHAIN_PATH=~/.pico-sdk/toolchain/15_2_Rel1
export PATH=~/.pico-sdk/toolchain/15_2_Rel1/bin:~/.pico-sdk/picotool/2.3.0/picotool:~/.pico-sdk/cmake/v4.3.4/bin:~/.pico-sdk/ninja/v1.13.2:$PATH
```

### 6.1 ビルド

```bash
# 増分ビルド（通常はこれだけで足りる）
ninja -C build

# 再コンフィグ（CMakeLists.txt や .pio を変更したとき）
cmake -S . -B build -G Ninja -DCMAKE_BUILD_TYPE=Release -DPICO_BOARD=pico2
```

`build/` は Release / `rp2350-arm-s` で構成済み。`.vscode/tasks.json` の "Compile Project"
タスクが増分ビルドと等価。

成果物は `build/pico-opm-writer.{uf2,elf,bin,hex,dis}` と `build/compile_commands.json`。

### 6.2 書き込み（SWD / PicoProbe が既定）

PicoProbe (Debugprobe on Pico、CMSIS-DAP、VID:PID `2e8a:000c`) をターゲット pico2 の SWD に
接続している場合、**CLI からはこれで焼くのが既定**。BOOTSEL 操作もターゲットの USB 状態も
要らない。

```bash
~/.pico-sdk/openocd/0.12.0+dev/openocd \
  -s ~/.pico-sdk/openocd/0.12.0+dev/scripts \
  -f interface/cmsis-dap.cfg \
  -f target/rp2350.cfg \
  -c "adapter speed 5000; program build/pico-opm-writer.elf verify reset exit"
```

`.vscode/tasks.json` の "Flash" タスクと等価。成功時は `** Programming Finished **` /
`** Verified OK **` / `** Resetting Target **` が出る。`openocd` は PATH に無いので
フルパスで叩く。DAP に繋がらなくなったら `target/rp2350-rescue.cfg` を使う
"Rescue Reset" タスク相当を先に実行する。

書き込みには `.elf` を使う（`.uf2` ではない）。

### 6.3 デバッグ

GUI でのステップ実行デバッグは VS Code の "Pico Debug (Cortex-Debug)" 構成を使う。

### 6.4 書き込み（代替経路）

SWD を繋いでいない場合は BOOTSEL から書き込む。BOOTSEL を押しながら USB を挿し、
現れる RPI-RP2 ドライブへ `build/pico-opm-writer.uf2` をコピーする。

```bash
picotool load build/pico-opm-writer.uf2   # BOOTSEL で起動した状態で実行する
```

**`picotool load -fx`（BOOTSEL 操作なしで再起動させる書き込み）は使えない。**
CDC を 2 本にするため TinyUSB のディスクリプタを自前で持っており、
`PICO_ENABLE_USB_RESET_VIA_VENDOR_INTERFACE` が無効になるため
（[docs §6](docs/pico-opm-writer.md#6-usb-cdc-2-本と-msc-の実装)）。

### 6.5 シリアル (stdio) の読み取り

| デバイス | 中身 |
| --- | --- |
| `/dev/cu.usbmodem11201` | **ターゲット pico2 の USB CDC #0** = コマンド / `printf` の出力先 |
| `/dev/cu.usbmodem11203` | **ターゲット pico2 の USB CDC #1** = PCM データ出力（[§4](#4-pcm-出力)） |
| `/dev/cu.usbmodem114302` | PicoProbe 側の CDC-UART ブリッジ（現状の設定では未使用） |

これに加えて USB マスストレージのインタフェースが 1 本ある。`storage host` のあいだだけ
メディアが入っている状態になり、PC にリムーバブルディスクとして現れる（[§7](#7-ストレージ)）。

tty 名は USB のポート位置に依存する。変わったら `ioreg -r -c IOSerialBSDClient -l -w 0` の
`locationID` と `ioreg -p IOUSB -l -w 0` の `USB Product Name` を突き合わせて引き直す
（ターゲットは Product Name `Pico`、プローブは `Debugprobe on Pico _CMSIS_DAP_`）。

注意点:

- **`/dev/tty.*` ではなく `/dev/cu.*` を使う。** `tty.*` は DCD 待ちで open がブロックする。
- **SWD の `reset` でターゲットの USB CDC が切断・再列挙される。** 書き込み直後は
  デバイスノードが数秒消えるので、存在を待ってから開く。
- `stdio_usb` はホストが開く前の出力を捨てるため、起動直後の行は取り逃す。

### 6.6 リリース版の zip を使う

ビルド済みのファームウェアは GitHub の Releases で配っている。

https://github.com/hyano/pico-opm-writer/releases

`pico-opm-writer-<バージョン>.zip` を展開すると、同じ名前のディレクトリが 1 つできる。

| ファイル | 中身 |
| --- | --- |
| `pico-opm-writer.uf2` | ファームウェア本体。これを焼く |
| `README.md` / `docs/` | このドキュメントと内部設計書 |
| `tools/opm-writer.py` / `tools/opm-record.py` | ホスト側ツール（[§10](#10-ホスト側ツール)） |
| `VERSION.txt` | どのコミットをどのオプションでビルドしたか |
| `SHA256SUMS` | 全ファイルのチェックサム |
| `LICENSE` / `THIRD-PARTY-LICENSES.md` / `licenses/` / `external/` | ライセンス（[§12](#12-ライセンス)） |

**焼き方**（[§6.4](#64-書き込み代替経路) と同じ）。BOOTSEL を押しながら USB を挿すと
`RPI-RP2` というドライブが現れるので、そこへ `pico-opm-writer.uf2` をコピーする。
コピーが終わると Pico 2 が勝手に再起動してファームウェアが立ち上がる。

展開した中身が壊れていないかを見るには、展開先のディレクトリで:

```bash
shasum -a 256 -c SHA256SUMS     # Linux では sha256sum -c SHA256SUMS
```

`VERSION.txt` の `version` が zip 名のバージョン、`describe` が元の git のタグ名
（`release/<バージョン>`）、`firmware version` がファームウェア自身が名乗る版
（起動バナーと `i` が出すもの）、`build options` がビルド時のオプションの実効値。
**問い合わせるときはこのファイルを添えること。**

FatFs の領域はファームウェアを焼いても消えない（[§7.1](#71-領域の変え方)）。
ただし `VERSION.txt` の `FLASH_FATFS_OFFSET` と `FLASH_FATFS_SIZE` が
今使っているものと違う版へ乗り換えると、領域の位置がずれてマウントできなくなる。
その場合は `storage format` でやり直す。

#### リリース用の zip を自分で作る

```bash
ninja -C build release
```

`build/release/pico-opm-writer-<バージョン>.zip` ができる。バージョンは
`git describe --tags --always` の結果から先頭の `release/` を落としたもの。
タグが無ければ短縮コミットハッシュになる。

**版を上げるときは [CMakeLists.txt](CMakeLists.txt) の `project(... VERSION x.y.z ...)`
を直してコミットしてから、`release/x.y.z` のタグを打つ。** ファームウェアの版はここの
1 箇所だけで決まり、起動バナー・`i`・`picotool info` のすべてがこの値になる。
タグの版とずれていると `ninja -C build release` はエラーで止まるので、
「zip 名は新しいのに焼いたファームは古い版を名乗る」リリースは作れない。

同じことを GitHub Actions でもやっている（`.github/workflows/build.yml`）。
push と Pull Request では zip を artifact として上げるだけで、
`release/<バージョン>` の形式のタグを push したときだけ Releases を作って zip を添付する。

## 7. ストレージ

Raspberry Pi Pico 2 に載っている **内蔵 QSPI フラッシュ 4MiB** のうち、
ファームウェアの後ろから末尾の予約セクタまでを FAT ファイルシステムとして使う。
外付けのフラッシュや SD カードは足さないので、**GPIO は 1 本も消費しない**。

```
0x10000000  ┬ ファームウェア（約 114KiB）
            ┆  （空き 約 142KiB）
0x10040000  ┬ FatFs 領域 3836KiB
0x103FF000  ┬ 末尾予約 4KiB（RP2350-E10。§7.1 参照）
0x10400000  ┴
```

| 項目 | 値 |
| --- | --- |
| 領域 | フラッシュ先頭から 0x40000、サイズ 3836KiB（3,928,064 バイト） |
| フォーマット | FAT12 / クラスタ 4096 バイト / SFD（MBR 無し） |
| 論理セクタ | 512 バイト（FatFs と USB MSC で共通） |
| ボリュームラベル | `PICOOPM` |
| VGM の置き場所 | `/VGM/` |
| MDX の置き場所 | `/MDX/` |

クラスタ長をフラッシュの消去単位と同じ 4096 バイトに揃えてあるので、
**1 クラスタの書き換えがフラッシュの消去 1 回で済む**。

### 7.1 領域の変え方

通常は **ファームウェアに残す容量（KiB）だけ**を指定すればよい。残りは末尾の
予約セクタの手前まで自動で FatFs になる。

```bash
cmake -S . -B build -G Ninja -DCMAKE_BUILD_TYPE=Release -DPICO_BOARD=pico2 \
      -DFLASH_FATFS_RESERVE_KB=512
```

| `FLASH_FATFS_RESERVE_KB` | 領域の開始 | FatFs の容量 |
| --- | --- | --- |
| 128 | 0x20000 | 3964KiB |
| 256（既定） | 0x40000 | 3836KiB |
| 512 | 0x80000 | 3580KiB |
| 1024 | 0x100000 | 3068KiB |

**どこまで広げられるか**は次の 2 つで決まる。

| 境界 | 値 | 理由 |
| --- | --- | --- |
| 開始位置の下限 | ファームウェアの終端（約 114KiB）を 4KiB 切り上げた位置 | 重なるとファームウェアを自分で壊す |
| 終端の上限 | フラッシュ末尾の 1 セクタ手前（0x3FF000） | 下記の RP2350-E10 |

末尾 1 セクタを空けてあるのは、**picotool が UF2 へ RP2350-E10 エラッタ回避用の
「absolute block」を入れる**ため。これはフラッシュではなく XIP 空間の末尾
0x10FFFF00 を狙うブロックで、4MiB のフラッシュではアドレスが折り返して
末尾セクタ（0x3FF000–0x3FFFFF）に落ちる。ここを FatFs に使ってしまうと、
**BOOTSEL や `picotool load` で UF2 を焼くたびにファイルシステムの末尾 4KiB が消える**。
SWD で `.elf` を焼く場合は absolute block が付かないので起きない。

予約量を変えたいときは `-DFLASH_FATFS_TAIL_RESERVE=` で指定する（4096 の倍数）。
UF2 を一切使わない運用なら 0 にできるが、推奨しない。

オフセットとサイズをバイトで名指しすることもできる。`FLASH_FATFS_OFFSET` と
`FLASH_FATFS_RESERVE_KB` の同時指定はエラーになる。

```bash
cmake -S . -B build -G Ninja -DCMAKE_BUILD_TYPE=Release -DPICO_BOARD=pico2 \
      -DFLASH_FATFS_OFFSET=3145728 -DFLASH_FATFS_SIZE=1044480
```

**領域を変えたらフォーマットし直すこと。** ジオメトリが変わるので、前の領域で
作ったファイルシステムはそのままでは使えない（§7.3）。

検査は 3 段構えになっている。

1. **コンパイル時** — 境界の 4096 バイト揃え、末尾予約への食い込み、FAT12 の
   クラスタ数上限を [flash_disk.c](src/flash_disk.c) の `_Static_assert` で見る。
2. **リンク後** — `__flash_binary_end` を読んでファームウェアと領域が重なって
   いないかを見る。重なっていればビルドが失敗する。余裕は毎回表示される。

   ```
   -- flash: firmware 116308 B (end 0x1001c654)
   --        FatFs  0x40000 + 3928064 B (end 0x3ff000)
   --        margin 145836 B  OK
   ```

3. **起動時** — 同じ `__flash_binary_end` と突き合わせる。重なっていたらマウントも
   書き込みも一切せずに `storage status` へ表示する（ビルド時に捕まえ損ねた場合の
   最後の砦。`hard_assert` で止めると復旧しづらいのでこうしてある）。

### 7.2 PC から曲データをコピーする

```
> storage host
# storage : HOST
OK
```

**SW1 と SW2 の同時長押し、または両方を押しながらの起動でも同じ状態に入れる**
（[§3.20](#320-ボタンgp21--gp22)）。PC を繋ぐ前にファイルシステムを渡しておけるので、
初めて曲を入れるときはこちらが早い。HOST 中は LED が 200ms ON / 800ms OFF になる。

PC にリムーバブルディスク `PICOOPM` が現れるので、`/VGM/` へ `.vgm` / `.vgz` を、
`/MDX/` へ `.mdx` を置く。終わったら **PC 側で取り出し（eject）する**。それだけで
Pico 側へ所有権が戻り、FatFs が自動でマウントし直される。

`/VGM` と `/MDX` はどちらも `storage format` が作る。それより前にフォーマットした
メディアには `/MDX` が無いので、その場合は PC 側でフォルダを作る（無いまま
`mdx list` を実行すると `ERR not found` になる）。

```
# storage : ejected by host
```

eject せずに `storage player` と打っても戻せるが、PC 側に書き込み途中のデータが
残っている可能性があるため警告が出る。

```
> storage player
# warn    : host did not eject; files may be incomplete
# storage : PLAYER
OK
```

**macOS では、一度取り出したあと同じ USB 接続のまま再びディスクとして現れさせることが
できない。** これは macOS 側の制約で、取り出した時点で USB マスストレージのドライバが
デバイスから切り離され、USB の再列挙まで戻ってこないため。ファームウェアが SCSI の
UNIT ATTENTION（メディアが入れ替わった）を返しても、リムーバブルメディアとして
申告していても変わらない。実際、`storage host` の LOEJ 処理を完全に無効にしても
マウントされないことを確認している。

対策は次のいずれか。

* **Pico の USB を挿し直す**（CDC も一度切れるが確実）
* コピーが 1 回で済むよう、必要なファイルをまとめて置いてから取り出す

USB を挿し直したくない場合、`storage host` と `storage player` の往復自体は
何度でもでき、`vgm list` や `vgm play` も正常に動く。**PC からもう一度書きたいときだけ**
挿し直しが要る。

**HOST から抜ける操作をボタンに割り当てているのは長押しだけ**で、短押しは
「ファイルシステムを PC へ渡している」という 1 行を出すだけで何もしない
（[§3.20](#320-ボタンgp21--gp22)）。PC がマウントしたまま抜けると書き込み途中の
ファイルが壊れるうえ、上記のとおり macOS では挿し直すまで戻せないため。
どうしても抜けられなくなったら SW3（リセット）で起動し直す。

新品の基板では領域が全 `0xFF` なのでファイルシステムが無い。
**起動時に自動でフォーマットすることはしない**ので、最初に 1 度だけ実行する。

```
> storage format yes
# format  : takes tens of seconds; I2S will underrun meanwhile
OK
```

### 7.3 書き込みの仕組みと制約

フラッシュの消去・書き込みのあいだは XIP が止まるため割り込みを落とす必要があり、
**4KiB ブロックあたり 40〜70ms メインループが止まる**。これはキャプチャの DMA リング
（65.5ms 分）と I2S の先行量（16.4ms 分）を超えるので、`storage host` のあいだは
PCM キャプチャと I2S 出力を無効にしている（[§3.13](#313-storageストレージ)）。

書き込みは 8 行 × 4KiB のライトバックキャッシュ（RAM 32KiB）を経由する。
PC からの書き込みはまずキャッシュに載り、次のいずれかでフラッシュへ落ちる。

* キャッシュに空きが無くなったとき（その場で最も古い 1 行を書き出す）
* PC からの書き込みが 250ms 途切れたとき（1 行ずつ流し切る）
* PC が eject したとき / `storage player` へ切り替えたとき（全部書き出す）

SCSI の `SYNCHRONIZE CACHE` では書き出さない。macOS はコピー中にこれを頻繁に
投げてくるため、素直に従うと 512 バイト書くたびに 4KiB ブロックを書き直すことになり、
書き込み回数が 1 桁増える。**取り外す前には必ず eject するか `storage player` に戻すこと。**

| 注意点 | 内容 |
| --- | --- |
| ファームウェアの再書き込み | OpenOCD の `program` も `picotool load` も ELF/UF2 の中身しか書かないので、**ファイルシステムは残る**。UF2 だけは末尾セクタへ 1 ブロック書くが、そこは領域外に予約してある（§7.1） |
| `picotool erase` / BOOTSEL の nuke UF2 | フラッシュ全体を消すので**ファイルシステムも消える** |
| 容量 | 3836KiB（既定）。macOS が `.fseventsd` を作るぶん少し減る（Spotlight は `/.metadata_never_index` で抑止済み） |
| 同時アクセス | `PLAYER` では MSC がメディア非挿入を返し、`HOST` では FatFs をアンマウントするので、両者が同時にフラッシュを触ることはない |

### 7.4 マウントされないときの調べ方

`storage host` を実行しても PC にディスクが現れず、すぐに

```
# storage : ejected by host
```

が出ることがある。**まず疑うのは macOS の画面ロック。** macOS は画面がロックされている
あいだ、リムーバブルメディアの自動マウントを拒否してイジェクトする。ファイルシステムの
判別（`msdos_fskit`）まで成功したうえで `loginwindow` がマウント承認を拒否するので、
症状は「認識すらされない」ように見える。**画面のロックを解除してから `storage host` を
実行すれば、そのままマウントされる。**

macOS 側のログでは次のように出る。

```
$ log stream --style compact --level info
diskarbitrationd  probed disk, id = /dev/disk6, with msdos_fskit, success.
diskarbitrationd  dispatched callback, kind = disk mount approval, disk = /dev/disk6.
loginwindow       CopySLMountApprovalCallback | DiskArb - wholeDisk != nil, calling DADiskEject
diskarbitrationd  dispatched response, kind = disk mount approval, dissented, status = 0xF8DA0008
diskarbitrationd  ejected disk, id = /dev/disk6, success.
```

画面ロックが原因でないときは、ファーム側が受け取った SCSI を `storage trace` で見る。
`storage host` に入った時点で記録が始まり、直近 320 件が残る。

```
> storage trace
# msc     : 131 events (showing 131)
# msc 000 : T 01 01 00
# msc 001 : T 01 00 01
# msc 002 : P 01 00 00
# msc 003 : C 00 00 00
# msc 004 : W 01 00 00
# msc 005 : I 00 00 00
# msc 006 : R x115
# msc 121 : P 00 00 00
# msc 122 : S 00 00 01
OK
```

| 記号 | 意味 | 欄 |
| --- | --- | --- |
| `T` | TEST UNIT READY | メディア有無 / メディア交換の通知を返したか / 成功したか |
| `I` | INQUIRY | — |
| `C` | READ CAPACITY | — |
| `W` | 書き込み可否の問い合わせ（MODE SENSE の一部） | 書き込み可か |
| `P` | PREVENT/ALLOW MEDIUM REMOVAL | 取り出し禁止か |
| `S` | START STOP UNIT | 電源状態 / start / **load_eject** |
| `R` | READ10 | 連続する分は `R xN` とまとめる |
| `X` | 上記以外の SCSI | オペコード / 第 2 バイト / 転送長 |

読み方の要点:

- `T 01 01 00` → `T 01 00 01` と続いていれば、メディア交換の通知（UNIT ATTENTION）が
  正しく受理されている。ここで `T 00 ...` しか出ないならメディアを見せられていない
- `R` が数十件出ていれば、**ファイルシステムは読めている**。そのあとの
  `S 00 00 01`（load_eject）が PC 側からのイジェクト
- `R` が 1 件も無いまま `S 00 00 01` が来るなら、PC はファイルシステムを読む前に
  諦めている。ディスクリプタや容量の申告を疑う

## 8. VGM 再生

`/VGM/` に置いた VGM ファイルを、ファームウェア単体で（PC からシーケンスを流し込まずに）
再生する。操作は [§3.14](#314-vgmvgm-再生)。

### 8.1 対応範囲

**演奏対象は YM2151（VGM コマンド `0x54`）だけ。** 他の音源のコマンドは仕様上の
長さぶん読み飛ばす。デュアルチップのファイルは 2 個目（`0xA4`）を無視し、
`vgm play` が `# warn : dual chip file; the second chip (0xA4) is ignored` を出す。

| 項目 | 内容 |
| --- | --- |
| 対応バージョン | 1.00 以降（データ開始位置は v1.50 未満と 0 のとき 0x40 固定） |
| 処理するコマンド | `0x54`（YM2151 書き込み） / `0x61` `0x62` `0x63` `0x70`-`0x7F`（wait） / `0x80`-`0x8F`（DAC。書き込みは飛ばし wait だけ効かせる） / `0x66`（終端） / `0x67`（データブロックを飛ばす） |
| 読み飛ばすもの | 上記以外の既知コマンドを仕様上の長さぶん |
| 中断するもの | 未知のオペコード（`0x00`-`0x2F` / `0x60` / `0x65` / `0x69`-`0x6F` / `0x96`-`0x9F`）、ファイルの途中終端。`# ERR vgm bad file (...)` を出して `ERROR` へ（[§3.18](#318-非同期通知)） |
| ループ | ヘッダのループオフセットが有効ならそこへ戻って繰り返す。`vgm loop <n>` を設定していなければ `vgm stop` するまで続く（[§3.22](#322-曲の終わり方)） |
| 終端 | ループを持たないファイルが終端に達したら**レジスタには何も書かずに**止まる。最後の音は音色本来の RR で自然に減衰する（[§3.22](#322-曲の終わり方)） |
| 圧縮 | `.vgz`（gzip）を一時ファイルを作らずストリームのまま展開して再生する（[§8.5](#85-vgzgzipの再生)） |
| 非対応 | GD3 タグ（曲名・作者）の表示 |

不正なファイルを読んでも、無限ループや範囲外の読み出しは起きない。
どの経路も必ず 1 バイト以上消費し、シークは必ずファイルサイズと突き合わせる。

### 8.2 タイミング

VGM の wait は 44100Hz の絶対サンプル数で表される。予定時刻は `time_us_64()` と
突き合わせ、**発行済みの絶対サンプル数から毎回計算し直す**ので丸め誤差が累積しない。
φM は sys_clk の整数分周で、どちらも同じ水晶から出ているため長期的なずれも生じない。

1 回の処理は 500µs で打ち切り、遅れた分は次の周回で詰める。遅れの最大値は
`s` の `SEQ LAG` で見える（実測で 700µs 程度）。ループの継ぎ目でも時計を
リセットしないので、時間の不連続は生じない。

**ハードウェアタイマの割り込みは使わない。** レジスタ書き込み 1 回が 32µs
ブロックするため、キーオンが集中すると割り込み文脈を数 ms 占有して I2S への
供給を飢えさせる。ポーリングにすることで、書き込みの合間に必ず
キャプチャと I2S のサービスが挟まる。

### 8.3 φM と VGM のクロック

`vgm play` は、ヘッダ（オフセット `0x30`）が申告する YM2151 のクロックへ
**φM を自動で合わせる**。合わせ先は最寄りのプリセット（[§2](#2-クロック設定-φm)）で、
境界は 2 つの中点 3789772Hz。

| ファイルの申告値 | 選ばれるプリセット |
| --- | --- |
| 4000000 Hz | `4`（4.000000 MHz） |
| 3579545 Hz | `3.58`（3.579545 MHz） |
| 3546895 Hz（PAL）/ 3375000 Hz など | `3.58`（3.579545 MHz） |

キャプチャと I2S のサンプリングレート（φM/64）も一緒に変わる。切り替えは
`opm_clear()` より前に済むので、再生開始の時刻には影響しない。

寄せてもなお値が一致しないときだけ、残ったずれを警告する。

```
> vgm play SOMETHING.VGM
# vgm     : version 1.51  samples 705600  loop yes
# clock   : file 3546895 Hz / phiM 3579545 Hz (pitch goes down)
OK
```

**ずれるのは音程と包絡線の速さだけで、テンポは正確なまま。** VGM の wait は
チップのクロックではなく 44100Hz の絶対サンプル数だからで、だから wait を
伸縮させるのは逆効果になる（テンポまで狂う）。

追従してほしくないときは `clock fixed`（[§3.16](#316-clockクロック切り替え)）。
このとき φM は動かず、食い違いは警告として出るだけになる。

**PCM を流している間（`p 1`）に別クロックの VGM を再生しようとすると、再生自体が
`ERR wrong state` になる。** キャプチャ中のクロック切り替えを拒否しているため。
先に `p 0` を打つか、`clock fixed` にする。**このとき前の曲は既に止まっている**
（`play` はファイルを開く前に止めるため）。

**`p 2` の待機中は通る**ので、別クロックの VGM も演奏連動キャプチャで録れる
（[§3.16](#316-clockクロック切り替え)）。曲の頭で φM が切り替わり、その曲の
サンプリングレートで最後まで録れる。

v1.10 より前の VGM にはクロックのフィールドが無い。この場合は追従せず、
現在の φM のまま再生する。

### 8.4 既存機能との共存

VGM 再生中も YM3012 のキャプチャと I2S 出力はそのまま動く。

```
VGM ──> YM2151 ──> YM3012 ─┬─> USB CDC #1（p 1 で録音）
                            └─> I2S ──> PCM5102A
```

`p 1` を併用すれば、再生した VGM をそのまま WAV として録音できる。

### 8.5 `.vgz`（gzip）の再生

gzip 圧縮された VGM（`.vgz`）を、**一時ファイルを作らずに展開しながら**再生する。
ホスト側で圧縮して `/VGM/` へ置くだけでよい。

```bash
gzip -9 -c foo.vgm > foo.vgz
```

圧縮したままフラッシュに置けるので、**領域に入る曲数が数倍になる**（YM2151 の
VGM は 3〜10 倍に縮む）。`vgm list` は `.vgm` と `.vgz` を区別せず名前順に並べ、
`vgm play` はどちらも受ける。

**圧縮されているかどうかは拡張子ではなくファイル先頭のマジック（`1F 8B`）で決める。**
中身が gzip の `.vgm` も、その逆も正しく扱える。

| 項目 | 内容 |
| --- | --- |
| 展開器 | miniz の `tinfl`（[§12](#12-ライセンス)） |
| 展開バッファ | 32KiB。DEFLATE の履歴窓を兼ねる |
| ループ | 継ぎ目に停止は出ない。非圧縮の `.vgm` と同じ（下記） |
| 追加で使う RAM | 約 84KiB。RP2350 の 512KiB に対して残りは約 330KiB |
| 追加で使う ROM | 約 10KiB |
| CRC32 | 検証しない（下記） |

**ループの継ぎ目は非圧縮と変わらない。** gzip は後方シークできないので、ループ先頭を
はじめて通過する瞬間に展開器の状態を丸ごと保存しておき、2 周目以降はそこへ戻す。
戻すのはメモリのコピーだけなので、頭出しのために展開し直すことはない。

保存できないまま通過してしまった場合の保険として、先頭から展開し直す経路がある。
こちらを通ると継ぎ目で音が数百 ms 途切れ、`s` の `gz reload` が増える
（[§3.11](#311-s統計)）。**通常の再生では 0 のまま。** この経路に入るときは
警告が出る。

```
# warn    : could not save the .vgz loop point; will re-inflate from the start
```

`0x67` のデータブロックのような前方への読み飛ばしは、gzip では飛ばせないので展開して
捨てるしかない。1KiB ずつに分けて 500µs の予算に乗せるため、読み飛ばしのあいだも
キャプチャと I2S への供給は止まらない。ここで生じた遅れは時計の張り直しが吸収する
（[§8.2](#82-タイミング)）。

**gzip トレーラの CRC32 は検証しない。** 読むのは ISIZE（展開後のサイズ）だけ。
ループ再生では終端に到達しないことが普通で、全部展開しないと計算できない CRC を
待っても壊れたファイルの検出は早まらないため。壊れていれば展開エラーか VGM 側の
未知オペコードとして必ず捕まる（[§3.14](#314-vgmvgm-再生)）。

同じ VGM を非圧縮と `.vgz` で 20 秒ずつ再生したときの実測（φM 4MHz、I2S 有効）。

| | 非圧縮 `.vgm` | `.vgz` |
| --- | --- | --- |
| 20 秒後の `VGM POS` | 889,033 samples | 889,633 samples |
| `CPU` | 32% | 32% |
| `SEQ LAG` の最大 | 621µs | 798µs |
| `I2S UNDERRUN` | 0 | 0 |

テンポは非圧縮と変わらない。VGM の wait は 44.1kHz の絶対サンプル数なので、
展開に時間がかかっても遅れとして現れるだけで、テンポには乗らない（[§8.2](#82-タイミング)）。

展開器ごと落としたいときは CMake のキャッシュ変数で無効にする。

```bash
cmake -S . -B build -G Ninja -DCMAKE_BUILD_TYPE=Release -DPICO_BOARD=pico2 -DVGM_VGZ_ENABLED=0
```

無効にすると `.vgz` は `ERR bad file` になる。

```
> vgm play OUTRUN.VGZ
# hint    : .vgz (gzip) is disabled by VGM_VGZ_ENABLED=0; gunzip before transferring
ERR bad file
```

実測サイズは
text 90,800 → 80,684 バイト / bss 180,448 → 94,012 バイト。

## 9. MDX 再生

`/MDX/` に置いた MDX ファイル（X68000 の音源ドライバ MXDRV 用のバイナリ MML）を、
ファームウェア単体で再生する。操作は [§3.15](#315-mdxmdx-再生)。

VGM が「レジスタ書き込みのタイムスタンプ付きダンプ」なのに対し、MDX は
**チャンネルごとに独立したシーケンサ**を持つ MML なので、音色・音量・ピッチ・LFO を
ファームウェア側で解釈してはじめて YM2151 のレジスタ値になる。つまり MXDRV 相当の
音源ドライバがファームウェアに入っている。

### 9.1 対応範囲

**FM 8ch と ADPCM 8ch。** MDX の MML コマンドは全部解釈する（音色・音量・パン・
ゲートタイム・レガート・リピート・ループ・ディチューン・ポルタメント・ソフト LFO
（音程 / 音量）・OPM のハードウェア LFO・同期・フェードアウト・キーオン遅延）。

**ADPCM パートはソフトウェアでデコードして鳴らす。** X68000 の ADPCM は MSM6258 と
いう別のチップで本機には載っていないので、PDX から読んだ波形をファームウェアが
デコードし、YM3012 から取り込んだ FM の PCM に足す。詳しくは
[§9.7](#97-adpcm-pcm8-の再生)。

チャンネル数はファイルが持つ 9（FM 8 + ADPCM 1）か 16（FM 8 + ADPCM 8。PCM8 拡張）。
16ch のファイルでは、`0xE8`（PCM8 モード宣言）が実行されるまで 9ch ぶんだけを回す。
`0xE8` は**チャンネル数だけでなく ADPCM の制御そのものを切り替える**。`0xE8` が無い曲では
音量（`v` / `@v`）もバンク（`@n`）も効かない（[§9.7](#97-adpcm-pcm8-の再生)）。
ADPCM チャンネルは**シーケンサとしては FM と同じように回している**。同期コマンド
（`0xEF` / `0xEE`）が ADPCM 側から FM 側へ飛んでくる曲があり、止めてしまうと FM が
永久に待ち続けるため。

`.mdx` を gzip したものには対応しない。MDX 本体は数 KB〜数十 KB しかないので、
`.vgz` のような圧縮の利点が小さい。

**曲データが尽きたときレジスタには何も書かない。** 参照実装 (MXDRV) の演奏終了処理は
END_FLG を落として PCM8 を止めるだけで OPM を触らないので、それに合わせてある。
最後の音は音色本来の RR で自然に減衰し、消えるのは `mdx stop` を打つか次の曲を
`play` したときになる（[§3.22](#322-曲の終わり方)）。

### 9.2 タイミング

MDX のテンポは **OPM の Timer-B 由来**で、`@t`（`0xFF`）が書く 1 バイトがそのまま
Timer-B の値になる。1 clock の長さは

```
1024 × (256 - @t) φM サイクル
```

で、φM 4MHz なら `(256 - @t) × 256 µs`。既定の `@t 200` で 14336µs（約 70Hz）。

**この周期は φM サイクル数でちょうど整数になる**ので、φM から誤差なく µs へ直せる。
実装では 1/65536µs 単位の累算器に足し込んでいて、テンポを変えても `clock` で φM を
切り替えても、丸め誤差が溜まらない。

タイマ割り込みは使わず `time_us_64()` のポーリングで作る。OPM のレジスタ 0x12（Timer-B）
と 0x14（タイマ制御）には MXDRV と同じように書き込むが、`/IRQ` は誰も読まない。

1 tick で発行する書き込みが多いときは、**tick の途中で中断して次の周回へ持ち越す**。
音色の展開は 1 チャンネルあたり 25 レジスタ（約 800µs）で、これが複数チャンネルで
同じ tick に重なると 1 tick で 180 回以上になる。全チャンネルの処理が終わるまで
tick は進めないので、演奏が先へ流れることはない。

200ms を超えて遅れたときは早送りせず時計を張り直す（`s` の `reslip`）。

### 9.3 φM と テンポ

`mdx play` は φM を X68000 の **4MHz** へ寄せる（`clock auto` のとき。
[§2](#2-クロック設定-φm)）。`clock fixed` にしていれば従わず、食い違いを警告する。

```
> mdx play GRADIUS.MDX
# mdx     : GRADIUS.MDX
...
# clock   : mdx 4000000 Hz / phiM 3579545 Hz (pitch and tempo both off)
OK
```

VGM と違い、**MDX は φM がずれるとテンポまでずれる。** VGM の wait は 44100Hz 固定の
絶対サンプル数なので φM とは無関係だが（[§8.3](#83-φm-と-vgm-のクロック)）、MDX の
1 clock は Timer-B 由来なので φM に反比例する。3.579545MHz で鳴らすと音程が約 10%
低くなるうえ、テンポも約 10% 遅くなる。

### 9.4 音程と音量の作り方

内部の音程は **1/64 半音**単位で持つ。MDX の音符 0-95 は `音符 × 64 + 5` が基準値で、
この `+5` は MXDRV の調律ぶん。ここへディチューン・ポルタメント・音程 LFO を足し込み、
最後に 4 倍して上位バイトを KC（`0x28+ch`）、下位バイトを KF（`0x30+ch`）にする。

KC の下位 4bit は 3 / 7 / 11 / 15 を飛ばすので、音符番号から KC への変換は 96 個の表で行う。
MDX の音符 0 は `o0 d+` で、これは OPM の KC 0 とちょうど一致する。

音量は `v0`-`v15`（16 段の表で TL へ）と `@v`（TL を直接指定）の 2 系統があり、
値の bit7 で区別する。TL を足すのは**キャリアのスロットだけ**で、どれがキャリアかは
音色の CON から決まる。フェードアウトと音量 LFO はこの TL に足し込む。

`t` コマンドがこの音程変換とテンポ換算を既知のベクタで検証する（[§3.12](#312-t自己テスト)）。

### 9.5 既存機能との共存

**VGM と MDX を同時に鳴らすことはできない。** ただし `play` は走っている方を止めてから
始めるので、切り替えは 1 コマンドでできる（[§3.14](#314-vgmvgm-再生)）。読み込みに
失敗したときは前の曲へは戻らず、停止状態で終わる。

再生中は `w` / `reset` / `c` と `storage host` を拒否する（理由は VGM と同じ。
[§8.4](#84-既存機能との共存)）。MDX 本体はファイルを丸ごと RAM に載せているので
アンマウントされても読めるが、**PDX は再生中もファイルを開いたまま読み続ける**
（[§9.7](#97-adpcm-pcm8-の再生)）。どちらにせよフラッシュの消去中は数十 ms 止まる
ので拒否する。

PCM キャプチャ（`p 1`）と I2S 出力は再生中も動く。`mdx play` が φM を切り替えようと
したときに PCM を流している最中だと `ERR wrong state` になり、前の曲は止まったままに
なる。`p 2` の待機中なら切り替えは通る（[§3.16](#316-clockクロック切り替え)）。

### 9.6 MXDRV との相違点

レジスタへの書き込み内容と順序は MXDRV 2.06+17 Rel.X5-S / MXDRVg V2.00b に合わせてある
（一部の機能だけ MXDRV 2.06+16 Rel.3+25。[§12](#12-ライセンス)）。違うのは 2 点。

**BUSY 待ちをしない。** MXDRV は書き込みのたびに OPM のステータスレジスタを読んで
bit7 が下りるのを待つが、本機は固定ウェイト（アドレス後 5µs / データ後 25µs、
合計約 32µs）で代える。ステータス自体は [`r 1`](#321-r読み出し) で読めるが、
書き込み経路では見ない（[test/opm_busy/](test/opm_busy/README.md)）。
X68000 実機より遅い方向なので、詰まるとすれば書き込みが間に合わない側に出る。
`s` の `MDX TICK` の `reslip` と I2S のアンダーランで検出できる。

**余韻が消えない曲を 5 秒で打ち切る。** 参照実装は演奏終了後の音を止めないので、
RR が 0 の音色が鳴ったままだと減衰せずに残り続ける。本機は 5 秒待っても無音に
ならなければ強制的に消音し、`# warn : ringout cut at 5000 ms` を出す
（[§3.22](#322-曲の終わり方)）。それでも 10 秒までに無音にならなければ待つのをやめる。
それ以外の場面での消音のタイミングは参照実装と同じ。

ADPCM については、X68000 では PCM8（江藤啓氏の ADPCM 多重再生ドライバ）が
MSM6258 を叩く。本機はその PCM8 に相当する処理をソフトウェアで持っている
（[§9.7](#97-adpcm-pcm8-の再生)）。

### 9.7 ADPCM (PCM8) の再生

MDX ファイルのヘッダには PDX（ADPCM の波形集）の名前が入っている。
`mdx play` はその名前に `.PDX` を付けたファイルを、次の順で探す。

1. **再生中の MDX と同じフォルダ** — `/MDX/BOS/BOS01.MDX` なら `/MDX/BOS/<名前>.PDX`
2. **`/MDX/` 直下** — `/MDX/<名前>.PDX`

曲ごとのフォルダに PDX を同梱する置き方と、共通の PDX を `/MDX/` 直下へまとめる置き方の
どちらでも鳴る。`/MDX/` 直下の曲では 1. と 2. が同じパスになるので 1 回しか探さない。
大小文字は区別しないので、`THEXDER` という名前で `thexder.pdx` も見つかる。
どちらにも無ければエラーにはならず、FM パートだけがそのまま鳴る。

ヘッダの PDX 名そのものにフォルダは書けない。`/` `\` `:` と制御文字を含む名前は
（ファイルの中身は信用しないので）その場で弾く。

```
> mdx play BOS14.MDX
# mdx     : BOS14.MDX
# title   : Ｂlast Ｐower ！ ～ from BOSCONIAN-X68
# ch      : 9  voices 8
# pdx     : bos
# pdxpath : /MDX/bos.PDX
OK

> mdx play BOS/BOS01.MDX
# mdx     : BOS/BOS01.MDX
# title   : Ｇood Ｍorning ～ from BOSCONIAN-X68
# ch      : 9  voices 8
# pdx     : bos
# pdxpath : /MDX/BOS/bos.PDX
OK
```

PDX は数百 KB あるので RAM には載せず、**再生しながらフラッシュから読む**。
`storage host` が再生中に拒否されるのはこのためでもある（[§9.5](#95-既存機能との共存)）。
`mdx stop` と曲の終わりでファイルは閉じる。

#### 鳴らし方

X68000 の ADPCM は 5 通りの再生周波数を持ち、MDX の `@ED` がそれを選ぶ。
本機の出力レートは φM/64 で、ADPCM のレートも φM の分周なので、**比は必ず整数**になる。

| `@ED` | 形式 | レート | 出力フレーム/サンプル |
| --- | --- | --- | --- |
| 0 | ADPCM | 3.90625 kHz | 16 |
| 1 | ADPCM | 5.20833 kHz | 12 |
| 2 | ADPCM | 7.8125 kHz | 8 |
| 3 | ADPCM | 10.41667 kHz | 6 |
| 4 | ADPCM | 15.625 kHz | 4 |
| 5 | 16bit PCM | 15.625 kHz | 4 |
| 6 | 8bit PCM | 15.625 kHz | 4 |

整数比なので**補間はしない**。1 サンプルをそのまま所定の回数だけ繰り返す。これは
MSM6258 の出力（階段波）そのもので、実機に一番近い。`mdx play` は φM を X68000 と
同じ 4MHz へ寄せるので、実レートも実機と一致する。

音量は PCM8 の仕様どおり **1 step = 2dB で 8 が原音**（-16dB〜+14dB）。MML の
`v` / `@v` とフェードアウトから PCM8 の 0-15 を作る。定位は PCM8 の仕様どおり
**全チャンネル共通**で、0 以外で最後に指定された値が有効になる。

#### `0xE8` があるかどうかで鳴り方が変わる

X68000 では、PCM8 を使うのは **`0xE8`（PCM8 モード宣言）を出した曲だけ**。出さない曲は
IOCS の ADPCM コールへ流れる。IOCS には音量もバンクも無いので、**同じ PDX を使っても
鳴り方が違う**。本機もこの分岐をそのまま持っている。

| | `0xE8` あり | `0xE8` なし |
| --- | --- | --- |
| 発音チャンネル | 8 | 1 |
| 音量 `v` / `@v` | 効く | **効かない**（原音量 8 固定） |
| フェードアウト | 音量が下がる | 途中から**音が止まる**（定位 0） |
| バンク `@n` | 効く | **効かない**（常にバンク 0） |
| 波形の長さ | 24bit | **16bit** |

周波数（`@ED`）と定位（`p`）はどちらでも同じように効く。`0xE8` を出さない曲が ADPCM
パートに `v` を書いていても、実機と同じく無視される。

**音量の調整つまみは無い。** ADPCM のフルスケールを FM のフルスケールと同じ重みで
足す、実機に忠実な固定のレベルにしてある。両方が大きいときに足して 16bit を超えた
回数は `s` の `MDX PCM` の `CLIP` に出る（実機のアナログミックスでも歪む領域）。

#### 出力先

ADPCM は **I2S 出力にも PCM キャプチャ（`p 1`）にも同じように乗る。** YM3012 から
取り込んだ値を PCM へ変換した直後の 1 箇所で足しているので、どちらの経路にも同じ音が
流れる。`mdx pcm off` にすると FM だけになるので、聴き比べや解析に使える
（ADPCM 側の解析をしたくないときにも使う）。

#### 対応していないこと

- PCM8 のチェイン出力（アレイチェイン / リンクチェイン）。MDX からは使われない。
- PCM8 の単音再生モードと、常駐判定・占有などの管理用ファンクション。
- `0xE7 0x02`（MDX から PCM8 へのコマンド）のうち、本機に対応する設定が無いもの
  （多重 / 単音モードの切り替えなど）。読み飛ばすだけで演奏は続く。

### 9.8 無効化

MDX 再生と ADPCM は CMake のキャッシュ変数で個別に落とせる。

```bash
# MDX 再生ごと落とす（シーケンサと 64KiB のファイルバッファがリンクされない）
cmake -S . -B build -G Ninja -DCMAKE_BUILD_TYPE=Release -DPICO_BOARD=pico2 -DMDX_ENABLED=0

# FM だけ鳴らす（ADPCM のデコーダとミックスリング 約 27KiB がリンクされない）
cmake -S . -B build -G Ninja -DCMAKE_BUILD_TYPE=Release -DPICO_BOARD=pico2 -DPCM8_ENABLED=0
```

`PCM8_ENABLED` の既定は空で、`MDX_ENABLED` に従う。`-DMDX_ENABLED=0` にすれば
ADPCM も一緒に落ちるので、両方を指定する必要は無い。

`PCM8_ENABLED=0` でビルドすると `i` の `# adpcm` 行が `disabled` になり、
PDX を要求する曲は FM パートだけが鳴る。

```
# adpcm   : disabled  8 ch  pdx stream 1024 bytes/ch
...
# pdx     : THEXDER
# hint    : cannot open /MDX/THEXDER.PDX (disabled); the ADPCM part will not sound
```

`mdx pcm off`（[§3.15](#315-mdxmdx-再生)）との違いは、**コードごと消えること**。
実行時に `mdx pcm on` へ戻すことはできない。聴き比べたいだけなら `mdx pcm off` を使う。

**無効化した機能は `ERR unsupported` を返す**（`ERR wrong state` ではない。
理由は `# hint` 行に出る）。状態表示だけは通るので、無効化されていることを
`mdx` / `mdx pcm` / `i` / `t` から確認できる。

```
（PCM8_ENABLED=0）
> mdx pcm on
# hint    : ADPCM is disabled at build time (PCM8_ENABLED=0)
ERR unsupported

（MDX_ENABLED=0）
> mdx list
# hint    : MDX playback is disabled at build time (MDX_ENABLED=0)
ERR unsupported

> mdx
# mdx     : DISABLED
# pos     : 0 clocks  loop 0  ch 0
# tick    : @t 0  0 us  reslip 0
OK
```

## 10. ホスト側ツール

`tools/` にホスト PC 側のスクリプトを置いている。いずれも Python 3 の標準ライブラリだけで
動く（`.zst` を扱う機能のみ Python 3.14 以上が必要）。

| スクリプト | 役割 | ドキュメント |
| --- | --- | --- |
| `tools/opm-writer.py` | シーケンスファイルを USB CDC 経由でファームへ流し込む。行末コメント / `@KEY@` 置換 / `!capture` `!capture-song` によるキャプチャに対応。どちらもファームの CDC #1 から PCM を直接読む | [docs/opm-writer.md](docs/opm-writer.md) |
| `tools/opm-record.py` | 実機に入っている曲を 1 曲 1 ファイルで WAV に録る。曲名の指定・`--list` による一覧・`--all` による全曲録音 | [docs/opm-record.md](docs/opm-record.md) |
| `tools/opm-lfo-period.py` | 実機キャプチャから LFO の更新周期をサンプル数で測る（`--mode am` / `--mode pm`）。結果は 1 ファイル 1 行の TSV | [docs/opm-lfo-period.md](docs/opm-lfo-period.md) |
| `tools/opm-lfo-period-testgen.py` | `opm-lfo-period.py` の回帰テスト（実機不要） | [docs/opm-lfo-period-testgen.md](docs/opm-lfo-period-testgen.md) |

**キャプチャはファームの CDC #1 から PCM を直接読むので、ロジックアナライザは要らない。**
`test/` の掃引スクリプトはそのまま実行できる。

```bash
./test/dac_lr/capture_all.py --analyze
```

曲をまるごと録るなら `opm-record.py` が短い。長さを指定する必要はない。

```bash
./tools/opm-record.py --all --loop 2 -o out/
```

`test/` 以下は、これらを使った実機調査の一次データ生成環境。掃引スクリプトと測定条件は
それぞれの README にまとめてある。

| ディレクトリ | 調べていること |
| --- | --- |
| [test/lfo_noise/](test/lfo_noise/README.md) | LFO ノイズ波形（`LFRQ` / `NFRQ` の掃引） |
| [test/noise_period/](test/noise_period/README.md) | ノイズ発生器そのもの（NE でノイズを直接 DAC へ出す） |
| [test/dac_lr/](test/dac_lr/README.md) | DAC の 2 スロット (CH1/CH2) の関係 |
| [test/pcm8_sync/](test/pcm8_sync/README.md) | FM と ADPCM の発音タイミング |
| [test/opm_busy/](test/opm_busy/README.md) | BUSY フラグと `opm_write()` の待ち時間 |

## 11. 将来の拡張（本仕様の範囲外）

- **PCM8 のチェイン出力（アレイチェイン / リンクチェイン）。** MDX からは使われない
  ので後回しにしている（[§9.7](#97-adpcm-pcm8-の再生)）
- バイナリストリーミングモード（`w` の 1 行あたりのオーバーヘッド削減）
- VGM の GD3 タグ（曲名・作者）の表示
- ロータリーエンコーダ / 表示器による操作（ボタンは
  [§3.20](#320-ボタンgp21--gp22) で実装済み。曲名の表示先が無いので、
  いま鳴っている曲は CDC #0 でしか分からない）
- 自動再生の設定（曲順・ループ回数・フェード）のフラッシュへの保存。現在は電源を
  入れ直すと既定値に戻る
- `opm_write()` の固定ウェイトの短縮。`t_ADDR`（5µs）と `t_WR`（1µs）は仮置きの値で、
  最小値を測っていない（[test/opm_busy/](test/opm_busy/README.md)）
- `/IRQ` の割り込み処理。現在はレベルを参照できるだけ（`s` の `IRQ`）
- バス書き込みの PIO 化と FIFO による非同期キューイング
- 2 個目の OPM / 他の Yamaha 音源チップ (OPN 系) への対応

## 12. ライセンス

MIT License。詳細は [LICENSE](LICENSE) を参照。

ただし `pico_sdk_import.cmake` は Raspberry Pi (Trading) Ltd. 由来のファイルで、
BSD-3-Clause が適用される（ファイル先頭の表示のとおり）。

`external/` に置いた外部ソースはそれぞれの条件による（[external/README.md](external/README.md)）。

MDX の解釈（[§9](#9-mdx-再生)）は X68000 の音源ドライバ MXDRV
（(c)1988-92 milk., K.MAEKAWA, Missy.M, Yatsube）の仕様に準拠している。
準拠先は大半が **X68k MXDRV music driver version 2.06+17 Rel.X5-S / for Win32 [MXDRVg] V2.00b**
で、一部の機能だけ **MXDRV 2.06+16 Rel.3+25** に準拠する。
MXDRV のソースは本リポジトリには含まれておらず、`mdx.c` は独自に書き起こしたもの。

ADPCM パート（[§9.7](#97-adpcm-pcm8-の再生)）は **PCM8 version 0.48**
（(c) 江藤啓 1991,92）の技術資料に準拠している。PCM8 のソースやバイナリは本リポジトリ
には含まれておらず、`pcm8.c` は独自に書き起こしたもの。

| 置き場所 | ライセンス |
| --- | --- |
| `external/fatfs/` — FatFs R0.16（ChaN） | 1 条項の BSD 風。[external/fatfs/LICENSE.txt](external/fatfs/LICENSE.txt) |
| `external/miniz/` — miniz 3.1.2 | MIT（本プロジェクトと同一）。[external/miniz/LICENSE](external/miniz/LICENSE) |

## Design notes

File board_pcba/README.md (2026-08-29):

# board_pcba — RP2350 / PCM5102A 直載せ基板

JLCPCB の **Economic PCBA** で組み立てる pico-opm-writer の基板。Raspberry Pi Pico 2 と
GY-PCM5102 のモジュールを使わず、RP2350A・PCM5102A・周辺部品を直接実装する。
モジュール側に重複していた電源回路・USB・水晶を基板側へ統合してある。

**ファームウェアのピン割り当ては [README.md](../README.md) §1.1 の接続表と同一。**
`src/opm.h` の `OPM_PIN_*` / `src/ym3012.h` の `YM3012_PIN_*` / `src/button.h` の
`BUTTON_PIN_*` はそのまま使える。

回路図・部品配置・配線・GND ベタまで**一通り完成している**。ERC / DRC ともエラー 0 件（§8）。

## 1. ファイル

| ファイル | 内容 |
| --- | --- |
| `pico-opm-writer_pcba.kicad_sch` | 回路図（A3 1 枚。6 ブロックに区切ってある） |
| `pico-opm-writer_pcba.kicad_pcb` | 基板（46 × 47.5mm / 2 層）。配線・GND ベタまで入っている（§5） |
| `pico-opm-writer_pcba.kicad_dru` | カスタム DRC ルール（ソケット内側の部品を許可する。§5.3） |
| `pico-opm-writer.kicad_sym` | プロジェクト固有シンボル（YM2151 のみ） |
| `abracon_aota-b201610s3r3-101-t.kicad_mod` | インダクタのフットプリント（出典は §6） |
| `rpi_capc1005x50_wide.kicad_mod` | C8 / C10 用のパッド間を広げた 0402（**VREG_LX をパッドの間に通すために必須**。§4.6、出典は §6） |
| `sym-lib-table` / `fp-lib-table` | 上の 2 つをライブラリとして登録する |

シンボル・フットプリントは **YM2151 と上の 2 つの `.kicad_mod` 以外すべて KiCad 10 の標準ライブラリ**。

## 2. 回路の構成

```
USB-C VBUS ─┬─ +5V ─┬─ U4 AMS1117-3.3 ── +3V3   RP2350A / フラッシュ / PCM5102A デジタル
            │       ├─ U5 XC6206P332  ── +3.3VA PCM5102A の AVDD / CPVDD
            │       └─ U6 YM2151 VDD
            └─ C1 10uF + C2 100nF

+3V3 ─ U1 VREG_VIN ─┐ RP2350 内蔵スイッチングレギュレータ
      ─ R9 33Ω ─ VREG_AVDD（C9 4.7uF）
                VREG_LX ─ L1 3.3uH ─ VREG_FB = +1V1 ─ DVDD ×3
```

回路図のブロック分け:

| ブロック | 内容 |
| --- | --- |
| A. USB-C ・ 電源 | J1、CC プルダウン、USB 直列終端、U4 / U5 の 2 系統 LDO |
| B. クロック ・ フラッシュ ・ 起動 | X1、U2、BOOTSEL (SW4)、RESET (SW3) |
| C. RP2350A | U1、デカップリング、内蔵レギュレータの外付け部品 |
| D. YM2151 (OPM) | U6、/CS プルアップ、デカップリング |
| E. PCM5102A ・ 音声出力 | U3、I2S 直列抵抗、チャージポンプ、出力フィルタ、J2 |
| F. ユーザー I/F ・ デバッグ端子 | SW1 / SW2、LED、SWD / UART / DAC プローブ、取付穴 |

ブロック間はネットラベルだけでつないである。ネット名は現行 [board/](../board/) を踏襲し、
I2S のみ PCM5102A のピン名に合わせて `LRCK` としている。

### 2.1 RP2350A ↔ YM2151

[README.md](../README.md) §1.1 の接続表そのまま。

| U1 ピン | GPIO | ネット | U6 ピン |
| --- | --- | --- | --- |
| 4,5,7,8,9,10,12,13 | GP2–GP9 | `D0`–`D7` | 10,12,13,14,15,16,17,18 |
| 14 | GP10 | `A0` | 4 |
| 15 | GP11 | `~{CS}` | 7 |
| 16 | GP12 | `~{WR}` | 5 |
| 17 | GP13 | `~{RD}` | 6 |
| 18 | GP14 | `~{IC}` | 3 |
| 19 | GP15 | `ΦM` | 24 |
| 27 | GP16 | `~{IRQ}` | 2 |
| 28 | GP17 | `SO` | 21 |
| 29 | GP18 | `Φ1` | 23 |
| 31 | GP19 | `SH1` | 20 |
| 32 | GP20 | `SH2` | 19 |

GP21 / GP22 はボタン、GP25 は LED、GP26–GP28 は I2S。GP0 / GP1 は UART ヘッダへ引き出す。
**GP23 / GP24 / GP29 と YM2151 の CT1 / CT2 は未接続。**

### 2.2 PCM5102A

GY-PCM5102 の既定ジャンパ設定をハードワイヤしてある。

| ピン | 接続 |
| --- | --- |
| 1 CPVDD / 8 AVDD | `+3.3VA`（U5 の出力。100nF を各ピンに 1 個ずつ） |
| 20 DVDD | `+3V3`（100nF） |
| 18 LDOO | 内蔵 1.8V LDO の出力。100nF + 10µF で `GND` へ |
| 2 CAPP / 4 CAPM | 2.2µF のフライングキャパシタ |
| 5 VNEG | 2.2µF で `GND` へ |
| 12 SCK | `GND`（内蔵 PLL モード） |
| 16 FMT | `GND`（I2S） |
| 11 FLT | `GND`（Normal latency） |
| 10 DEMP | `GND`（De-emphasis off） |
| 17 XSMT | `+3V3`（soft un-mute） |
| 13 BCK / 15 LRCK / 14 DIN | 22Ω 直列で GP26 / GP27 / GP28 |
| 6 OUTL / 7 OUTR | 470Ω → J2.T / J2.R、各々 2.2nF で `GND` へ |

**CPVDD はチャージポンプの電源で、TI のデータシートは AVDD と同じアナログ 3.3V に置く**
（§10.1.1 の Figure 33、§11.1 の Table 12）。デジタル側から取ると、チャージポンプの
パルス電流がアナログ電源へ回り込む。

**470Ω + 2.2nF は TI のデータシートが指定するポストフィルタ**（fc ≈ 154kHz）。
TI は THD+N・SNR・チャンネルセパレーションの規格値をすべて
「10kΩ 負荷 + 470Ω 出力抵抗 + 2.2nF シャント」の条件で規定しているので省略しない。
出力はチャージポンプで GND センターになるため DC カットのコンデンサは要らない。

### 2.3 YM2151 の /CS プルアップ

**R11: `~{CS}` → `+3V3` に 1kΩ。** 電源投入から `opm_init()` が /CS を H にするまでの間、
RP2350 のパッドは入力＋内部プルダウンなので、これが無いと OPM が D0-D7 を駆動する窓ができる
（[README.md](../README.md) §1.3）。

プルアップ先を 5V ではなく **3.3V** にした理由:

- **YM2151 の全入力の VIH は min 2.0V**（TTL しきい値。VIL は max 0.8V、入力リークは
  Vi=10V で 0.1µA 以下）。**RP2350 の内部プルダウンは IOVDD=3.3V で 36kΩ〜113kΩ。**
- この 2 つから、`opm_init()` 前の /CS 電位は次のようになる。

  | プルアップ | R_PD=36k | R_PD=113k | VIH 2.0V への余裕 | /CS Low 時の吸い込み | GP11 の最大電圧 |
  | --- | --- | --- | --- | --- | --- |
  | +5V / 10kΩ | 3.91V | 4.59V | +1.9V | 0.5mA | **4.59V** |
  | +3V3 / 10kΩ | 2.58V | 3.03V | +0.58V | 0.33mA | 3.3V |
  | **+3V3 / 1kΩ** | **3.21V** | **3.27V** | **+1.2V** | 3.3mA | 3.3V |

- 通常動作では GP11 が 3.3V で /CS を駆動するので、5V にしても H レベルは良くならない。
  1kΩ なら起動直後も**通常駆動時と同じ電位**になる。
- 5V プルアップは、VBUS が立って 3.3V がまだ立ち上がり切っていない間、IOVDD 不足のまま
  GP11 へ 5V を流し込む。3.3V なら GP11 は 3.3V レールに追従するだけで IOVDD を超えない。
- 1kΩ は他でも使っているので部品番号が増えない。3.3mA は RP2350 の 1 ピンあたりの駆動能力
  （12mA）にも合計値（`I_IOVSS_MAX` 100mA）にも収まり、/CS が L になるのは
  バスサイクル中だけなので平均消費は無視できる。

3.3V レールの立ち上がり中の短い窓は塞げないが、それは現行 [board/](../board/) と同じ状態で、
README §1.3 の整理がそのまま当てはまる。POR 解除から `opm_init()` までの長いほうの窓は塞げる。

## 3. 部品表

単価は JLCPCB の 10 個購入時。**Basic は Extended 手数料（部品番号ごとに $3）がかからない。**

| Ref | 部品 | LCSC | 種別 | 個数 | 単価 | 小計 |
| --- | --- | --- | --- | ---: | ---: | ---: |
| U1 | RP2350A (A4 ステッピング) | C42411118 | Ext | 1 | $1.2699 | $1.270 |
| U2 | W25Q128JVSIQ (16MB) | C97521 | **Basic** | 1 | $2.2528 | $2.253 |
| U3 | PCM5102APWR | C107671 | Ext | 1 | $1.2440 | $1.244 |
| U4 | AMS1117-3.3 (デジタル) | C6186 | **Basic** | 1 | $0.2161 | $0.216 |
| U5 | XC6206P332MR-G (アナログ) | C5446 | **Basic** | 1 | $0.1449 | $0.145 |
| X1 | ABM8-272-T3 12MHz | C20625731 | Ext | 1 | $0.4217 | $0.422 |
| L1 | AOTA-B201610S3R3-101-T 3.3µH | C42411119 | Ext | 1 | $0.2834 | $0.283 |
| J1 | USB-C 16P | C2765186 | Ext | 1 | $0.0740 | $0.074 |
| SW1–SW4 | TS-1088-AR02016 | C720477 | **Basic** | 4 | $0.0555 | $0.222 |
| D1 | LED 0603 赤 | C2286 | **Basic** | 1 | $0.0074 | $0.007 |
| R2–R4, R10, R11 | 1kΩ 0402 | C11702 | **Basic** | 5 | $0.0039 | $0.019 |
| R5, R6 | 27Ω 0402 | C25100 | Ext | 2 | $0.0032 | $0.006 |
| R7, R8 | 5.1kΩ 0402 | C25905 | **Basic** | 2 | $0.0026 | $0.005 |
| R9 | 33Ω 0402 | C25105 | **Basic** | 1 | $0.0077 | $0.008 |
| R12–R14 | 22Ω 0402 | C25092 | **Basic** | 3 | $0.0057 | $0.017 |
| R15, R16 | 470Ω 0402 | C25117 | **Basic** | 2 | $0.0048 | $0.010 |
| C2, C4, C5, C7, C11–C21, C24–C27, C29, C30 | 100nF 0402 X7R | C1525 | **Basic** | 21 | $0.0055 | $0.115 |
| C22, C23 | 15pF 0402 C0G | C1548 | **Basic** | 2 | $0.0041 | $0.008 |
| C33, C34 | 2.2nF 0402 | C1531 | Ext | 2 | $0.0037 | $0.007 |
| C8–C10 | 4.7µF 0402 6.3V | C23733 | **Basic** | 3 | $0.0232 | $0.070 |
| C31, C32 | 2.2µF 0603 16V | C23630 | **Basic** | 2 | $0.0193 | $0.039 |
| C6, C28 | 10µF 0603 10V | C19702 | **Basic** | 2 | $0.0349 | $0.070 |
| C1, C3 | 10µF 0805 25V | C15850 | **Basic** | 2 | $0.0959 | $0.192 |

**実装 62 点で $6.70 / 枚。Extended は 7 種（U1 / U3 / X1 / L1 / J1 / 27Ω / 2.2nF）で
手数料 $21。10 枚なら部品 $67.0 + $21 = 約 $88**（PCB 製造費・実装費・送料は別）。

R1（10kΩ・QSPI_SS のプルアップ）は **DNF**。フットプリントだけ用意してある（§4.4）。

### 3.1 手はんだする部品（PCBA 対象外）

| Ref | 部品 | フットプリント |
| --- | --- | --- |
| U6 | YM2151 + DIP-24 ソケット | `Package_DIP:DIP-24_W15.24mm_Socket` |
| J2 | ST-005-G 3.5mm ステレオジャック | `Connector_Audio:Jack_3.5mm_Switronic_ST-005-G_horizontal` |
| J3 | SWD 1×3 ピンヘッダ | `Connector_PinHeader_2.54mm:PinHeader_1x03_P2.54mm_Vertical` |
| H1 / H2 | M2 取付穴（対角 2 箇所） | `MountingHole:MountingHole_2.2mm_M2` |

| ヘッダ | ピン |
| --- | --- |
| J3 (SWD) | 1=`SWDIO` / 2=`GND` / 3=`SWCLK` |

### 3.2 未使用の GPIO

**GP0 / GP1（UART）は未接続。** 当初は φ1.0mm のテストパッドを置いていたが、基板を
縮めるにあたって削除した。回路図では U1 の GPIO0 / GPIO1 に no-connect フラグを
付けてあるので ERC は 0 件になる。

`Φ1` / `SO` / `SH1` / `SH2` の観測が要るときは、U1 と U6 の間の配線にプローブを当てる。

## 4. 部品選定：検討した選択肢と選定理由

### 4.1 サイズと価格

| 項目 | 選択肢 | 採用 | 理由 |
| --- | --- | --- | --- |
| チップ抵抗 | 0402 / 0603 | **0402 に統一** | Economic PCBA の最小サイズが 0402 |
| µF 級コンデンサ | 全部 0402 / 全部 0603 / 電圧で使い分け | **電圧で使い分け** | 0402 の Basic 品は 6.3V しかなく DC バイアスで大きく容量が減る。`+5V` と `+3V3` の 10µF は 0805/25V、`+3.3VA` と LDOO の 10µF は 0603/10V |
| VREG 周辺の 4.7µF | 0402 / 0603 | **0402** | RPi の設計ガイド §2.1 が 0402 (1005 metric) を指定。レギュレータのレイアウトが critical なのでサイズを勝手に大きくしない |
| タクトスイッチ | 5.1×5.1mm / 3.9×3×2mm | **C720477 (3.9×3×2mm)** | Basic かつ在庫 90 万個。KiCad 標準 `SW_SPST_TS-1088-xR020` がこの部品のデータシートから起こされている |

### 4.2 フラッシュ容量

| 選択肢 | 判断 |
| --- | --- |
| 2MB (W25Q16) | 曲データが約 1.7MB までで足りない |
| 4MB (W25Q32) | Pico 2 と同容量でファームウェアの変更が不要だが、**Extended 品しかなく 16MB の Basic 品より高い** |
| **16MB (W25Q128JVSIQ / C97521)** | **採用。** Basic で在庫 10 万個。RP2350 がサポートする最大容量で、RPi のリファレンス設計と同一部品。FatFs 領域が約 15.7MB になる（ファームウェア側の対応は §7） |

### 4.3 USB D+/D− の直列 27Ω

RPi の設計ガイド §5.1 が「USB のインピーダンス規格を満たすために 27Ω の直列終端が必要」と
明記している。**JLCPCB に Basic の 27Ω は 0402 / 0603 / 0805 のいずれにも無く**、手数料が
同じくかからない Preferred ティアにも無い。Basic の 0402 抵抗で選べる値は
0 / 10 / 22 / 33 / 49.9 / 100 / 120 / 200 / 220 / 330 / 470 / 510 / 1000 Ω の 13 種だけ。

| 個数 / 1 本あたり | 最良の組み合わせ | 実効値 |
| --- | --- | --- |
| 2 個 | 33 ∥ 200 | 28.32Ω (+4.9%) |
| 2 個 | 33 ∥ 120 | 25.88Ω (−4.1%) |
| 3 個 | 22 + (10 ∥ 10) | 27.00Ω（厳密） |
| 3 個 | 33 ∥ (49.9 + 100) | 27.05Ω (+0.2%) |

2 個では ±4% 以上ずれ、±1% に入れるには 1 本あたり 3 個（D+/D− で計 6 個）要る。
Extended 手数料は枚数に依存しない $3 なので 10 枚なら 1 枚あたり $0.30 にしかならず、
**USB はこの基板の唯一のホストインタフェースなので終端を分割してまで節約しない**。
33Ω 単体（R9 と共通化して新規部品ゼロ）も検討したが、+22% となり USB 2.0 フルスピードの
ドライバ出力インピーダンス規格（28〜44Ω、直列抵抗込み）を超える可能性がある。

### 4.4 RPi の設計ガイドに従った部分

RP2350 の内蔵スイッチングレギュレータ周辺は、RPi の設計ガイドが
「部品選定ごと真似しろ、外れるなら自己責任」と明記しているので全面的に合わせてある。

| 部品 | 選択肢 | 採用と理由 |
| --- | --- | --- |
| 12MHz 水晶 | Basic の 20pF 品 (C9002) / Extended の 12pF (C70565) / **ABM8-272-T3 (C20625731)** | **ABM8-272-T3。** ガイド §4 が名指しで推奨し、直列 1kΩ は「最大 ESR 50Ω・IOVDD 3.3V」に合わせて水晶を過大駆動しないよう選んだ値だと述べている。回路から外れると全温度域での検証が必要になる。負荷容量 15pF ×2 の直列 7.5pF に寄生 3pF を足して 10.5pF ≒ CL 10pF |
| VREG インダクタ | Sunlord SWPA3015 (C48020, 3×3mm) / **AOTA-B201610S3R3-101-T (C42411119)** | **AOTA。** ガイド §2.1 が「巻き方向が逆だと漏れ磁束が出力コンデンサ C7 に干渉し、RP2350 内部の制御回路を乱す」ため極性ドット付き・リール内で向きが揃った専用品を Abracon に作らせたと述べ、代替は自己責任としている |
| QSPI_SS の 10kΩ | 実装 / **DNF** | **DNF。** ガイド §3.1「この特定のフラッシュ (W25Q128JVS) では外付けプルアップは不要と判明した。別のフラッシュを使うときのために footprint だけ用意してある」 |
| アナログ LDO | ME6211C33M5G (C82942) / SPX3819 (C9055) / **XC6206P332MR-G (C5446)** | **XC6206。** ME6211 は在庫 9 個で実質発注不可。XC6206 は Basic・在庫 45 万個で、200mA / ドロップ 250mV@100mA は AVDD の約 25mA に十分 |
| PCM5102A の電源 | LDO 1 個で共通 / フェライトビーズで分離 / **LDO 2 個** | **LDO 2 個。** RP2350 内蔵バックのスイッチングノイズをアナログ側から切り離す。追加は LDO 1 個とコンデンサ 2 個だけ。AVDD と CPVDD は TI のデータシートどおり同じ `+3.3VA` に載せ、DVDD だけ `+3V3` から取る |
| 10µF の置き場所 | 電源ピンごと / **レギュレータの入出力だけ** | **レギュレータの入出力だけ。** `+5V` は C1（U4 / U5 の入力）、`+3V3` は C3（U4 の出力）、`+3.3VA` は C6（U5 の出力）の 1 個ずつで、デカップリングバンクには置かない。RPI-RP2350A-MINIMAL と同じ配置で、AMS1117 / XC6206 が安定条件として要求する出力コンデンサもこれで満たす。各 IC のピン直近は 100nF が受け持つ |
| 出力フィルタ | Basic の 1nF (fc 339kHz) / Basic の 4.7nF (fc 72kHz) / **2.2nF (C1531)** | **2.2nF。** TI が THD+N・SNR の規格値をこの条件で規定しているので測定条件と一致させる |

### 4.5 フットプリントの照合

**KiCad 10 標準ライブラリで足りることを、実部品のパッド座標と数値比較して確認した。**

| 部品 | 使うフットプリント | 確認内容 |
| --- | --- | --- |
| USB-C C2765186 | `Connector_USB:USB_C_Receptacle_Palconn_UTC16-G` | EasyEDA API から取った実物のパッド座標と比較。SMD パッド X は ±3.20 / ±2.40 / ±1.75 / ±1.25 / ±0.75 / ±0.25 で完全一致、シェル穴も相対 0.03mm 以内。当初候補の `HRO_TYPE-C-31-M-12` は ±3.25 / ±2.45 で**不一致** |
| ABM8-272-T3 | `Crystal:Crystal_SMD_3225-4Pin_3.2x2.5mm` | RPi リファレンスの footprint とパッドが完全一致（±1.1 / ±0.85、1.4×1.2mm） |
| TS-1088-AR02016 | `Button_Switch_SMD:SW_SPST_TS-1088-xR020` | KiCad 側の `descr` が C720477 のデータシートを参照している |
| ST-005-G | `Connector_Audio:Jack_3.5mm_Switronic_ST-005-G_horizontal` | KiCad 側の `descr` が ST-005-G のデータシートを参照している |
| C8 / C10 の 0402 | `pico-opm-writer:rpi_capc1005x50_wide` | KiCad 標準ではパッド間が 0.40mm しかなく `VREG_LX` が通らない（§4.6） |
| AOTA-B201610S3R3-101-T | `pico-opm-writer:abracon_aota-b201610s3r3-101-t` | KiCad 標準の 2016 メトリック品はどれもパッドが違う（最も近い `L_Changjiang_FTC201610S` で ±0.65mm / 0.8×1.7mm、実物は ±0.7mm / 0.7×1.7mm）ため §6 のとおり複製した |

USB-C はレイアウト着手時に 1:1 印刷で最終確認する。合わなければ
`easyeda2kicad --lcsc_id C2765186 --footprint` で取り込む。

### 4.6 C8 / C10 のパッド間を広げた 0402

**`VREG_LX`（U1 pin 48 → L1）は C8 と C10 のパッドの間を通す。** RPi のリファレンス設計は
この 2 個（向こうの C6 / C7）だけ専用の land pattern を使っており、KiCad 標準の 0402 では
配線が通らない。

| フットプリント | パッド | パッド内側の隙間 | 0.15mm 配線（両側 0.15mm クリアランス）|
| --- | --- | --- | --- |
| RPi `generic_capc1005x50_wide` | 0.47 × 0.55 @ ±0.515 | **0.56mm** | 通る |
| RPi `generic_capc1005x50`（通常） | 0.55 × 0.55 @ ±0.475 | 0.40mm | 通らない |
| KiCad 標準 `C_0402_1005Metric` | 0.56 × 0.62 @ ±0.48 | 0.40mm | **通らない** |

そのため `rpi_capc1005x50_wide.kicad_mod` を複製して C8 / C10 に割り当てている（出典は §6）。
コートヤードだけは RPi の 0.94mm ピッチ配置に収まるよう 1.8 × 0.9mm に広げてある。
**C8 / C10 を標準の 0402 に戻すと `VREG_LX` が通らなくなる。**

部品自体は同じ 0402 のチップコンデンサなので、BOM も JLCPCB の部品番号も変わらない。

## 5. 基板

### 5.1 仕様

| 項目 | 値 |
| --- | --- |
| 外形 | **46 × 47.5mm**、角 R2mm |
| 層数 / 板厚 | **2 層 / 1.6mm** |
| 配線 | 753 本 / 総延長 1579mm（F.Cu 551 本 / B.Cu 202 本） |
| ビア | **167 本すべて φ0.45mm / ドリル 0.2mm**（アニュラーリング 0.125mm） |
| GND | 基板全面のベタゾーン 1 個（F.Cu + B.Cu）＋ **スティッチングビア 84 本**（§5.7） |
| 実装面 | **表面のみ**（Economic PCBA は片面実装） |
| 手はんだ | `U6` / `J2` / `J3` の 3 点だけ（§3.1） |

ネットクラスと実際に使われている配線幅:

| ネットクラス | 幅 | クリアランス | 本数 |
| --- | --- | --- | ---: |
| Default | 0.15mm | 0.15mm | 498 |
| Power / USB / VREG | 0.2mm | 0.15mm | 217 |
| Analog | 0.3mm | 0.15mm | 16 |
| （局所ネックダウン） | 0.125〜0.142mm | 0.15mm | 22 |

**ネックダウンの 22 本は QFN-60（0.4mm ピッチ）の脱出部などで 0.15mm が物理的に入らない
箇所。** JLCPCB の 1oz 標準能力は 0.10mm 幅 / 0.10mm 間隔なので製造上の問題はない。
DRC の `min_track_width` はこれに合わせて 0.12mm にしてある。

DRC ルール: `min_clearance` 0.15 / `min_via_diameter` 0.45 /
`min_through_hole_diameter` 0.2 / `min_via_annular_width` 0.125 /
`min_hole_clearance` 0.2 / `min_copper_edge_clearance` 0.3。

**部品は 0.5mm グリッドに載せてある。** 例外は次の 2 つだけ。

- **RPi のリファレンス設計から 1:1 で複製した部品**は U1 相対座標がグリッドに乗らない。
  対象は `RPI-RP2350A-MINIMAL_R4-S1.kicad_pcb` の以下の部品で、
  U1 の回転（270°）に合わせてクラスタごと回してある。

  | ours | RPi | 役割 |
  | --- | --- | --- |
  | `C8` `C10` `L1` `C9` `R9` | C6 / C7 / L1 / C9 / R3 | 内蔵レギュレータ。§4.4 のとおりここから外れると自己責任 |
  | `R5` `R6` | R7 / R8 | USB の 27Ω 直列終端 |
  | `C21` | C12 | 53 / 54 ピンで共用する 100nF |

  `L1` の極性ドットの向きも RPi と一致させてある。
- **`J1` (USB-C)** は挿入口が基板端に載る Y 座標に置いてある。

**リファレンスのシルクはすべて水平**（`KeepUpright` 有効）。0.25mm グリッドに載せ、
部品の中心に揃えてある。68 個中 31 個は自分の部品から 0.5mm 以内、最も遠いもので 2.3mm。
密集部（U1 のデカップリング列と PCM5102A のアナログ部）は 0.8mm の文字が
入る隙間が無いため、これ以上は詰められない。

### 5.2 ビア寸法の根拠

JLCPCB の仕様は資料によって食い違っている（同社の Q&A ページ自身が矛盾を認めて
サポート問い合わせを案内している）。確認できた範囲では次のとおり。

| 出典 | 記載 |
| --- | --- |
| 能力表（2 層） | 最小ビア穴 0.15mm・最小ビア径 0.25mm。ただし **0.15mm 穴は割増** |
| 能力表の推奨値 | ビア穴 **0.2mm** / ビア径 **0.35mm** |
| ブログ | 推奨アニュラーリング **0.13mm**、「ドリル **0.3mm 以上が標準プロセス**」 |

採用した φ0.45 / 0.2mm は、

- ドリル 0.2mm は能力表の**推奨最小値**。0.3mm 未満なので小径穴として基板製造費に
  割増が付く可能性はあるが、**Economic PCBA（実装）の可否には影響しない**
- アニュラーリング 0.125mm は推奨 0.13mm にほぼ一致し、JLCPCB 自身の推奨ビア
  （0.35/0.2 → 0.075mm）よりはるかに健全

**ビア径を後から広げることはできない。** 配線済みの基板で実測したところ、
φ0.45 → φ0.5 で 234 件、φ0.6 で 134〜141 件のクリアランス違反が出る。
寸法を変えるならネットクラスを直してから配線をやり直すこと。

### 5.3 ブロック配置

コネクタは 2 つとも**下辺**に出す。

```
      0      10      20      30      40  46
  0 +---------------------------------------+
    | +-----------------------------+ SW1SW2|
    | |   U6  DIP-24 socket (横置き) | SW3SW4|
    | |   内側: C25                 | D1 R10|
 20 | +-----------------------------+    H2 |
    | C15 C11 C14  R11 R2 R1  U2 flash      |
    | X1  C22             C21 R5 R6  R12-14 |
 30 | C16 U1 RP2350A  C8 C10 L1   U3 PCM5102|
    | C12 R3 C17   C9 R9   C26-C28  U5 C5-C7|
    | J3  C18-C20         C30-C32 R15 R16   |
 40 | H1  C1-C3  R7 R8    C33 C34           |
    |    [J1 USB-C]   U4     [J2 jack] ===> |
 47.5+---------------------------------------+
```

**U1 は 270° 回してある。** GPIO2–11（`D0`–`D7` / `A0` / `~{CS}`）の並ぶ辺が
真上の U6 を向き、残りの辺は次のようになる。

| U1 の辺 | 向き | 主な信号 | 向かい合う部品 |
| --- | --- | --- | --- |
| GPIO0–11 (1–15) | 上 | `D0`–`D7` `A0` `~{CS}`（GP0/GP1 は未使用） | U6 の下段 |
| GPIO12–18 ほか (16–30) | 左 | `~{WR}` `~{RD}` `~{IC}` `ΦM` / `XIN` `XOUT` / SWD / `RUN` / `~{IRQ}` `SO` `Φ1` | X1、J3、U6 の上段左端 |
| GPIO19–28 ほか (31–45) | 下 | `SH1` `SH2` / ボタン / `LED` / I2S | C18–C20、U3 |
| VREG・USB・QSPI (46–60) | 右 | VREG 一式 / `USB_DP` `USB_DM` / QSPI | L1、R5/R6、U2 |

**U6 は 90° 回してある。** 下段（U1 側）が 1–12 ピン、上段が 24–13 ピン。

| 段 | 左→右 |
| --- | --- |
| 上段 | `ΦM` `Φ1` `VDD` `SO` `SH1` `SH2` `D7` `D6` `D5` `D4` `D3` `D2` |
| 下段 | `GND` `~{IRQ}` `~{IC}` `A0` `~{WR}` `~{RD}` `~{CS}` CT1 CT2 `D0` `GND` `D1` |

この向きにすると **`D2`–`D7` が U1 の並び順のまま**上段へ抜け、`ΦM` / `Φ1` /
`SO` / `SH1` / `SH2` が U1 の左辺の至近（上段の左端）に来る。
**`SH1` / `SH2` だけは U1 の下辺から出るので回り込みになる**が、
これは 62.5kHz のサンプルホールドストローブなので長さを許容している。

**U3 は 90° 回してある。** I2S（`BCK` / `LRCK` / `DIN`）が上、`OUTL` / `OUTR` が下。
データシート §12.1 の「I2S のクロック・データを OUTL / OUTR から離す」を
パッケージの反対側に分けることで満たし、アナログ出力は真下の J2 へ最短で降りる。

### 5.4 ソケットの内側に置いた部品

DIP-24 ソケットは 2 列の間が 15.24mm 開いている。ここに `C25`（U6 の VDD の 100nF）を
置いて面積を稼いでいる。**U6 のコートヤードの中にあるので DRC が衝突と判定する。**
`pico-opm-writer_pcba.kicad_dru` の `socket_inner_parts` ルールで例外にしてある。

反対の列へ渡る信号もソケットの内側を通している。
**表層を通せば裏面のベタ GND を切らずに済む。**

### 5.5 配線するときの注意

RP2350 の設計ガイドから。回路図には現れないのでここに残す。

- **USB は 90Ω 差動が理想だが、2 層 1.6mm では現実的な線幅で作れない。**
  RP2350 の USB はフルスピード (12Mbps) なので、
  「対を短く・密結合・等長・**直下は切れ目のない裏面 GND**」で通す（設計ガイド §5.1）。
  J1 は U1 の右辺（`USB_DP` / `USB_DM`）の真下に置いてある
- **R5 / R6（27Ω）は RP2350 の至近**、フラッシュ周りの R1 / R2 はフラッシュの至近（設計ガイド §3.1・§5.1）
- **`VREG_PGND` の大電流リターンは、他の GND を乱さずに PGND ピンへ直接戻す**（§2.1）
- **L1 は極性ドットの向きを RPi のレイアウトに合わせる**（設計ガイド §2.1。座標は本書 §5.1）
- **水晶の配線は極力短く。** 寄生容量を 3pF と見込んで負荷容量を決めている（§4）
- 電源ピンごとに 100nF を至近に置く。53 / 54 ピンだけ `C21` 1 個を共用している（§2.2.1）
- SMD 部品はすべて表面に置く（Economic PCBA は片面実装）
- **`VREG_LX` は C8 / C10 のパッドの間を通す**（§4.6）

PCM5102A のデータシート §12.1 から。

- **電源とチャージポンプのデカップリング（C26 / C27 / C28 / C29 / C30 / C31 / C32）は
  U3 の直近に置く**
- **I2S のクロック・データ配線を OUTL / OUTR から離す**（§5.3 で U3 の向きにより分離済み）
- `AGND` / `DGND` / `CPGND` は分離せず共通グラウンドでよい。表層を信号、裏層を GND ベタにする

`+5V` のバルクは U4 / U5 の入力側の C1 だけで、U6 の VDD には C25 (100nF) しか付いていない
（§4.4）。**J1 から U4 / U5 を経て U6 までの `+5V` を短く太く引く。**

### 5.6 freerouting を使うときの手順

配線は KiCad の Specctra DSN / SES 経由で freerouting に投げている。
**DSN のエクスポートは GUI 専用**（`kicad-cli` には無い）。

1. KiCad で基板を開き、**Board Setup → Net Classes のビア寸法が φ0.45 / 0.2mm に
   なっているか先に確認する**
2. File → Export → Specctra DSN
3. freerouting で自動配線 → Export Specctra Session (.ses)。
   **両層とも preferred direction は無効にする**（有効だとマンハッタン配線になり
   ビアが激増して裏面 GND が細切れになる）
4. File → Import → Specctra Session

**KiCad を開いたままプロジェクトファイルを外部から編集しないこと。** KiCad は
プロジェクト設定をメモリに持っていて保存時に書き戻すため、`.kicad_pro` の
ネットクラスや DRC ルールの編集が失われ、古い設定のまま DSN が出力される。

取り込み後にやること:

- **SES 由来の小さな銅箔ゾーンを削除する。** freerouting は一部の接続をポリゴンで
  出力し、KiCad はそれを 1mm² 未満の小さなゾーンとして取り込む（今回は 312 個）。
  削除しても未接続は増えない
- **0.12mm 未満の配線が無いか確認する。** freerouting は DSN が 0.15mm を宣言していても
  0.1124mm の配線を出すことがある（今回は 21 本）
- ゾーンを再フィルして DRC を通す

### 5.7 GND のベタとスティッチングビア

GND は **F.Cu と B.Cu をまたぐ 1 個のゾーン**で、基板端から 0.3mm 内側まで塗ってある。

- **スティッチングビア 84 本**を 5mm 格子で入れて表裏のベタをつないでいる。
  格子点に置けない場合は周囲 ±1mm を 0.25mm 刻みで探し、それでも無理なら飛ばす
- ビアは他の銅箔から 0.15mm、**穴からは 0.2mm（KiCad は「穴の縁 ↔ 相手の銅箔」で測る）**、
  基板端からは 0.3mm + ビア半径を確保している
- ゾーンは **島の除去を「常に」** に設定してある。どこにもつながらないベタは残らない
- 最小幅 0.25mm。これ以下の細いヒゲは塗られない

結果として、F.Cu は 7 領域（最大 1394mm²）、B.Cu は 3 領域（最大 1486mm²）で、
**すべての領域が 4 点以上でつながっている**（1 点だけで釣り下がったアンテナ状のベタは無い）。

### 5.8 ケース（3D プリント）

- 取付穴は **M2 × 2 箇所**（左下 H1 / 右上 H2）。ソケットへ YM2151 を押し込む力を受けるので、
  **ケース側にソケット真下を支えるボスを立てる**こと
- 操作部は右辺に固めてある（SW1 / SW2 / SW3 / SW4 / D1）。天面に穴を開ける
- コネクタは下辺に 2 つ。J2 のバレルは基板端から突き出す

## 6. 出典

`abracon_aota-b201610s3r3-101-t.kicad_mod` と `rpi_capc1005x50_wide.kicad_mod` は
Raspberry Pi の `RPI-RP2350A-MINIMAL_R4-S1`（`reference/board/` に同梱、**MIT License**、
Copyright (c) 2026 Raspberry Pi Ltd）の `.kicad_pcb` に埋め込まれていたフットプリント
（`abracon_aota-b201610s3r3-101-t` と `generic_capc1005x50_wide`）を複製したもの。
3D モデルの参照と基板固有の情報（配置座標・ネット・ローカルクリアランス）は外してある。
`rpi_capc1005x50_wide` はコートヤードだけ 1.8 × 0.9mm に広げてある（§4.6）。

## 7. ファームウェア側の未対応事項

16MB フラッシュを選んだので、この基板でファームウェアを動かすには次が要る。

- `PICO_FLASH_SIZE_BYTES` を 16MiB にする独自ボードヘッダ（`pico2.h` を include して上書き）
- `cmake ... -DFLASH_TOTAL_BYTES=16777216`

`src/flash_disk.c` の `_Static_assert` が両者の一致を検査するので、片方だけ変えると
コンパイルが落ちる。

## 8. 検証

実機は要らない。`kicad-cli` だけで完結する。

```bash
KC=/Applications/KiCad/KiCad.app/Contents/MacOS/kicad-cli

# ERC（0 件であること）
$KC sch erc --severity-error --severity-warning --exit-code-violations \
    board_pcba/pico-opm-writer_pcba.kicad_sch

# 基板（エラー 0 件・未配線 0 件・回路図との等価性 0 件であること）
$KC pcb drc --schematic-parity --severity-error --severity-warning --units mm \
    -o /tmp/pcba-drc.rpt board_pcba/pico-opm-writer_pcba.kicad_pcb

# BOM（LCSC 番号と DNP が入っていること）
$KC sch export bom --group-by 'Value,Footprint,LCSC Part #' \
    --fields 'Reference,Value,Footprint,${QUANTITY},LCSC Part #,${DNP}' \
    -o /tmp/pcba-bom.csv board_pcba/pico-opm-writer_pcba.kicad_sch

# 目視用
$KC sch export pdf -o /tmp/pcba.pdf board_pcba/pico-opm-writer_pcba.kicad_sch
$KC pcb render --side top -o /tmp/pcba-top.png board_pcba/pico-opm-writer_pcba.kicad_pcb
```

現状:

| 項目 | 結果 |
| --- | --- |
| ERC | **0 件** |
| DRC エラー | **0 件** |
| 未配線 | **0 件** |
| 回路図との等価性 | **0 件** |
| DRC 警告 | 9 件（シルクのみ。下記） |

残る警告 9 件は次の 2 種類で、いずれも実害が無いため残してある。

| 警告 | 件数 | 内容 |
| --- | ---: | --- |
| `silk_edge_clearance` | 4 | 基板端に載る J1 / J2 のコネクタ外形。基板端のシルクは製造時に切られる |
| `silk_overlap` / `silk_over_copper` | 5 | 密集部でリファレンス文字が隣の線やパッドにわずかにかかる。JLCPCB はパッドにかかるシルクを自動で除去する |

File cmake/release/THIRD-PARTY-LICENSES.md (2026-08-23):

# 同梱物のライセンス

このパッケージに入っている `pico-opm-writer.uf2` は、本プロジェクトのコードに加えて
下記の第三者コードをリンクした結果である。それぞれのライセンス本文を同梱している。

pico-opm-writer 自身のライセンスは MIT。[LICENSE](LICENSE) を参照。

| コンポーネント | 版 | ライセンス | 本文 |
| --- | --- | --- | --- |
| Raspberry Pi Pico SDK（Raspberry Pi Ltd.） | 2.3.0 | BSD-3-Clause | [licenses/pico-sdk-LICENSE.txt](licenses/pico-sdk-LICENSE.txt) |
| TinyUSB（hathach, tinyusb.org） | Pico SDK 同梱版 | MIT | [licenses/tinyusb-LICENSE](licenses/tinyusb-LICENSE) |
| FatFs（ChaN） | R0.16 | 1 条項の BSD 風 | [external/fatfs/LICENSE.txt](external/fatfs/LICENSE.txt) |
| miniz（Rich Geldreich ほか） | 3.1.2 | MIT | [external/miniz/LICENSE](external/miniz/LICENSE) |

FatFs と miniz の入手元・適用したパッチ・設定は [external/README.md](external/README.md) にある。

`pico_sdk_import.cmake`（ビルドスクリプト。バイナリには含まれない）も
Raspberry Pi (Trading) Ltd. 由来で BSD-3-Clause が適用される。

## ソースを含まない準拠先

MDX の解釈は X68000 の音源ドライバ MXDRV
（(c)1988-92 milk., K.MAEKAWA, Missy.M, Yatsube）の仕様に準拠している。
準拠先は大半が **X68k MXDRV music driver version 2.06+17 Rel.X5-S /
for Win32 [MXDRVg] V2.00b** で、一部の機能だけ **MXDRV 2.06+16 Rel.3+25** に準拠する。

ADPCM パートは **PCM8 version 0.48**（(c) 江藤啓 1991,92）の技術資料に準拠している。

どちらもソース・バイナリ・資料とも本プロジェクトには含まれておらず、
`mdx.c` と `pcm8.c` は独自に書き起こしたものである。

## ソース

https://github.com/hyano/pico-opm-writer

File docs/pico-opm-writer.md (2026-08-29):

# pico-opm-writer（ファームウェア内部設計）

[pico-opm-writer.c](../src/pico-opm-writer.c) ほか `src/` 以下の `.c` / `.h` / `.pio`

Raspberry Pi Pico 2 (RP2350) 上のファームウェアが、OPM のバス制御と YM3012 の
DAC キャプチャをどう実装しているかの説明。**使い方・配線・コマンド仕様は
[README.md](../README.md)** にある。

## 1. ソース構成

| ファイル | 役割 |
| --- | --- |
| [pico-opm-writer.c](../src/pico-opm-writer.c) | `main()`。システムクロック設定、初期化列、メインループの骨格（4 行） |
| [console.h](../src/console.h) / [console.c](../src/console.c) | コマンドの受け口。CDC #0 からの行入力、パーサ、各コマンドのハンドラ、応答（`OK` / `ERR`） |
| [report.h](../src/report.h) / [report.c](../src/report.c) | `i` / `s` / `h` の状態表示。本文だけを出し、末尾の `OK` は出さない |
| [sched.h](../src/sched.h) / [sched.c](../src/sched.c) | メインループの協調スケジューラ。`service_all()` と、各グループを回す最短間隔（[§1.1](#11-メインループ)） |
| [opm.h](../src/opm.h) / [opm.c](../src/opm.c) | OPM のピン割り当て・タイミング定数・φM の分周比算出と張り替え、バス制御 |
| [opm_clock.pio](../src/opm_clock.pio) | φM 生成用 PIO プログラムと `opm_clock_program_init()` |
| [clockmode.h](../src/clockmode.h) / [clockmode.c](../src/clockmode.c) | φM プリセットの実行時切り替え。sys_clk と PIO 分周比の張り替え順序（[§2.3](#23-実行時の切り替え)） |
| [ym3012.h](../src/ym3012.h) / [ym3012.c](../src/ym3012.c) | YM3012 の PIO + DMA リング初期化、リング位置の管理、PCM 変換、自己診断 |
| [ym3012.pio](../src/ym3012.pio) | キャプチャ用 PIO プログラムと `ym3012_capture_program_init()` |
| [capture.h](../src/capture.h) / [capture.c](../src/capture.c) | キャプチャの状態機械と、リング → PCM → CDC #1 の送出。演奏に連動する `p 2` もここ（[§4.7](#47-演奏に連動したキャプチャ-p-2)） |
| [i2s.h](../src/i2s.h) / [i2s.c](../src/i2s.c) | I2S 出力の PIO + DMA リング初期化、先行量の維持、アンダーラン復帰 |
| [i2s.pio](../src/i2s.pio) | I2S 出力用 PIO プログラムと `i2s_out_program_init()` |
| [usb_pcm.h](../src/usb_pcm.h) / [usb_pcm.c](../src/usb_pcm.c) | CDC #1 の接続判定・書き込み・滞留量 |
| [button.h](../src/button.h) / [button.c](../src/button.c) | GP21 / GP22 の取り込み。デバウンス、短押し / 長押しの状態機械、イベントのメールボックス（[§13](#13-ボタン入力)） |
| [buttonmap.h](../src/buttonmap.h) / [buttonmap.c](../src/buttonmap.c) | ボタン起点の操作。イベントの消化と、起動時のモード選択（[§13.1](#131-検出と消化を分ける)） |
| [led.h](../src/led.h) / [led.c](../src/led.c) | 非ブロッキングな LED パターン表示 |
| [stats.h](../src/stats.h) / [stats.c](../src/stats.c) | CPU 使用率・high-water・カウンタ |
| [flash_disk.h](../src/flash_disk.h) / [flash_disk.c](../src/flash_disk.c) | 内蔵フラッシュ上のブロックデバイス。領域定数、ライトバックキャッシュ、消去と書き込み |
| [ffconf.h](../src/ffconf.h) | FatFs の設定（上流の `external/fatfs/` には置かない。[§8.1](#81-ffconfh-をプロジェクト側に置く仕組み)） |
| [diskio_flash.c](../src/diskio_flash.c) | FatFs の `disk_*` 実装 |
| [storage.h](../src/storage.h) / [storage.c](../src/storage.c) | ストレージのモード状態機械、マウント、フォーマット、状態表示 |
| [filelist.h](../src/filelist.h) / [filelist.c](../src/filelist.c) | FatFs 上のファイル一覧。`vgm list` / `mdx list` の出力、autoplay のプレイリストへ集める `filelist_collect()`、パスの検査 `filelist_path_ok()` で共用（[§1.3](#13-ファイル一覧の共用)） |
| [usb_msc.c](../src/usb_msc.c) | USB マスストレージの `tud_msc_*` コールバック |
| [vgm.h](../src/vgm.h) / [vgm.c](../src/vgm.c) | VGM のヘッダ解析、コマンド解釈、スケジューラ、一覧 |
| [vgz.h](../src/vgz.h) / [vgz.c](../src/vgz.c) | gzip ストリームの展開。`FIL` から読み、展開したバイト列を前から順に返す（[§9.4](#94-vgz-のストリーム展開)） |
| [mdx.h](../src/mdx.h) / [mdx.c](../src/mdx.c) | MDX のヘッダ解析、MML の解釈、チャンネル状態機械、tick スケジューラ、一覧（[§10](#10-mdx-再生)） |
| [pcm8.h](../src/pcm8.h) / [pcm8.c](../src/pcm8.c) | MDX の ADPCM パート。PDX のストリーム読み出し、MSM6258 デコード、FM への加算（[§10.7](#107-adpcm-pcm8-の再生)） |
| [songend.h](../src/songend.h) / [songend.c](../src/songend.c) | 曲の終わり方。ループ回数での打ち切り、フェードアウト、終わったあとの余韻待ち（[§11](#11-曲の終わり方-songend)） |
| [autoplay.h](../src/autoplay.h) / [autoplay.c](../src/autoplay.c) | VGM / MDX の自動連続再生。プレイリスト、曲順、曲送りの状態機械（[§12](#12-自動連続再生-autoplay)） |
| [tusb_config.h](../src/tusb_config.h) / [usb_descriptors.c](../src/usb_descriptors.c) | USB CDC 2 本 + MSC 1 本の TinyUSB 設定とディスクリプタ |
| [external/fatfs/](../external/fatfs/) | FatFs R0.16（上流のまま。[external/README.md](../external/README.md)） |
| [external/miniz/](../external/miniz/) | miniz 3.1.2（上流のまま。展開器 `tinfl` だけを使う。[external/README.md](../external/README.md)） |

### 1.1 メインループ

メインループの 1 周分は [sched.c](../src/sched.c) の `service_all()` が持つ。
`main()` に残っているのは初期化列と、次の 4 行を回す `for(;;)` だけ。

```c
service_all();          // USB・音声・シーケンサ・ストレージをひと回し（sched.c）
buttonmap_dispatch();   // ボタンのイベントを 1 個消化する（buttonmap.c）
console_poll_connect(); // ホストが CDC #0 を開いたか（100ms ごと。console.c）
console_service();      // コマンドを 1 文字読む（console.c）
```

**スケジューラを別ファイルにしてあるのは、`service_all()` から呼んでよいものの
境界がこのファームウェアで最も壊しやすい不変条件だから**（再入・順序・間引きの
3 つが同時に掛かる）。コマンドパーサや状態表示と同居していると、その境界が
1 ファイル 2000 行の中に埋もれる。

**`report.c` が `OK` を出さないのも同じ理由。** 「1 コマンド 1 応答」
（[README §3.3](../README.md#33-応答)）を守る責任を `console.c` の
1 か所に閉じてあるので、`report_info()` は起動バナーとしても同じものを使える。

`service_all()` は `tud_task()` → キャプチャリング位置の取り込み → ADPCM のレンダリング →
キャプチャの送出 → I2S への供給 → VGM の発行 → MDX の発行 → 曲の終わり方の判定 →
曲送りの判定 → 演奏連動キャプチャへの通知 → ストレージの書き出し → ボタンの取り込み →
LED → 統計、をひと回しする。**ボタンの消化**とコマンド 1 文字読みは `main()` の側。

**曲の終わり方（[§11](#11-曲の終わり方-songend)）は必ずシーケンサの後、曲送りの前。**
同じ周回で更新された再生状態から出した結論を、autoplay がそのまま曲送りに使える。
演奏連動キャプチャへの通知（`capture_note_track()`、[§4.7](#47-演奏に連動したキャプチャ-p-2)）
だけは間引きの外に置く。比較が数回で済むうえ、間引くと待機から録り始めるまでの遅れが
そのまま WAV の頭の欠けになるため。

**リング位置の取り込みと ADPCM のレンダリングが先頭に来る**のは、キャプチャも I2S も
`ym3012_reader_read_pcm()` の中でミックス済みの PCM を受け取るため。どちらが読むより
先に描き終えていなければならない（[§10.7](#107-adpcm-pcm8-の再生)）。
`d` の待機、`p 0` のドレイン待ち、`vgm list` / `mdx list` / `autoplay list` の行出力の
合間、起動時のボタン解放待ち（[§13.6](#136-起動シーケンス)）からも同じ処理を呼ぶので、
コマンドの待ち時間の中でも PCM の送出・I2S への供給・USB の処理は止まらない。

**この周回は 2 つの DMA リングの位置を追いかけている**（キャプチャ側と I2S 側）。
どちらもリング一周は 65.5ms なので、1 周回がこれを超えると位置を見失う。
フラッシュの消去はこれを超えるので、専用の復帰手順を用意している（[§9.3](#93-書き込み中の停止とリング位置)）。

**各サービスは毎周回ではなく、グループごとに最短間隔を決めて呼ぶ。** 間隔と決め手は
[README §3.11.1](../README.md#3111-サービスの呼び出し間隔) にある。判定は `due()` が
受け持ち、「最短でもこの間隔を空ける」であって「この周期ちょうどで回す」ではない。
長く止まったあとは 1 回だけ真になり、取りこぼしを溜めない。

**間引きは信号の流れに対しては透明だが、新しい内容を書き込む瞬間には効く。**
リングの読み書きはフレーム番号で結ばれていて、いつ読みに行っても内容は同じになる。
これが崩れるのは「外から時刻を持ち込む操作」だけで、ADPCM のキーオンがそれに当たる。
そちらは間引きを待たずにその場で処理する（[§10.7](#107-adpcm-pcm8-の再生) の
「束ねても発音の時刻は動かない」）。

間引く理由は 2 つ。1 つは、フレームが 62500/s しか届かないのにループは数十万周/秒
あるので、毎周回回すと 1 回あたり 1 フレーム未満のために毎回支度をすることになる点
（[§10.7](#107-adpcm-pcm8-の再生) の `PCM8_BATCH_FRAMES` と同じ理屈）。もう 1 つは、
**ここはビジーループなので 1 周が軽くなるとその分だけ周回数が増える**点。片方のグループ
だけを間引くと、浮いた時間を残りのグループが周回数ぶん食い返す（実測: 音声チェーンだけを
間引いたら `LOOP` が 3.4 倍になり `tud_task()` の占有率が 15% から 26% へ上がった）。
だから `tud_task()` も含めて全部を間引く。

**ボタンだけは取り込みと消化が離れている。** `service_all()` の中で行うのは GPIO を読んで
短押し / 長押しのイベントに変えるところまでで、`autoplay_*` / `storage_*` を呼ぶのは
`main()` の `for(;;)` 直下に置いた `buttonmap_dispatch()` だけ。`service_all()` は上記のとおり
コマンド処理中の待ちからも呼ばれるので、そこから上位の操作を呼ぶと
`filelist_collect()`（[§1.3](#13-ファイル一覧の共用) のとおり走査バッファを共用していて
再入できない）を壊し、コマンドの応答の途中へ別の出力が割り込む。
`buttonmap_dispatch()` を置いた位置は、**`process_line()` の外側であることが構文的に保証される
唯一の点**。イベントは深さ 1 のメールボックスで渡す（[§13](#13-ボタン入力)）。

コマンド側の入出力はすべて標準入出力 API 経由で行う。

- 出力: `printf()` / `puts()`
- 入力: `getchar_timeout_us()` でノンブロッキングに 1 文字ずつ受け取り、行バッファに溜める。
  受信 FIFO が空のときに SDK のドライバ走査まで降りないよう、`tud_cdc_n_available()` で
  先に見る
- 接続検出: `stdio_usb_connected()`（100ms ごと）

パーサ側の上限は [console.c](../src/console.c) に定義がある。1 行の最大長が
`LINE_MAX_LEN`（255 文字）、`d` に指定できる待機時間の上限が `DELAY_MAX_MS`（60000 ms）。

### 1.2 主要 API

```c
void opm_init(void);                        // GPIO と PIO(φM) を初期化し /IC リセットを実行
void opm_write(uint8_t addr, uint8_t data); // 1 レジスタ書き込み（アドレス→データの 2 サイクル）
void opm_reset(void);                       // /IC によるハードウェアリセット
void opm_clear(void);                       // ソフトウェアによる全レジスタクリア
void opm_key_off_all(void);                 // 全 32 スロットを RR=15 にしてから 8ch をキーオフ

uint32_t opm_clock_hz_actual(void);         // 実際に生成されている φM 周波数
uint32_t opm_clock_div_int(void);           // PIO 分周比の整数部
uint32_t opm_clock_div_frac(void);          // PIO 分周比の小数部（/256）
```

クロック照会の 3 関数は `i` の情報表示（[README §3.6](../README.md#36-i情報表示の出力例)）に使う。
`opm_key_off_all()` は消音の唯一の実装で、`opm_clear()` / `vgm_stop()` / `mdx_stop()` と
余韻の強制打ち切り（[§11.2](#112-余韻の判定)）が共有する。手順と、書く順序を分けてある
理由はこの関数の側に書いてある（[§11.3](#113-フェードアウト)）。

フラッシュ書き込みのように長く止まったあとは、リングの位置を張り直す
（[§9.3](#93-書き込み中の停止とリング位置)）。呼び出し側は集約した 1 本だけを使う。
個別の 3 本を直接呼ばないのは、消費者が増えたときに呼び忘れが起きないようにするため。

```c
void capture_resync_after_blackout(void); // 下の 3 つをまとめて呼ぶ。呼び出し側はこれだけ

void ym3012_ring_resync(void); // 書き込み位置を取り込み直し、既定カーソルを合わせる
void i2s_resync(void);         // 読み出し位置を取り込み直し、先行分を無音で埋め直す
void pcm8_resync(void);        // ミックスリングを無音で埋めてレンダリング位置を張り直す

void i2s_set_enabled(bool);    // 無効中はソースを読まず無音だけを流す（クロックは止めない）
```

変換した PCM に別の音源を混ぜるフック。USB キャプチャと I2S の唯一の合流点に
掛かるので、1 箇所で両方に効く（[§10.7](#107-adpcm-pcm8-の再生)）。

```c
void ym3012_set_mixer(ym3012_mixer_t fn); // 変換直後に呼ぶ。加算と飽和はフック側で行う
void ym3012_set_mix_ready(uint64_t frame);// 描き終えた位置。カーソルはここを超えて読まない
```

ミキサの後段に掛ける出力ゲイン。autoplay のフェードアウトがこれを使う
（[§11.3](#113-フェードアウト)）。

```c
void ym3012_fade_start(uint64_t start_frame, uint32_t frames);          // 1.0 -> 0.0
void ym3012_fade_release(uint32_t delay_frames, uint32_t ramp_frames);  // 猶予のあと 1.0 へ
void ym3012_fade_clear(void);                                           // 猶予もランプも無し
```

ボタン（[§13](#13-ボタン入力)）。取り込みと消化が離れているので、
`button_service()` を呼ぶ側と `button_take_event()` を呼ぶ側は別（[§1.1](#11-メインループ)）。

```c
void button_service(void);                   // GPIO を読んでイベントに変えるところまで
bool button_take_event(button_event_t *out); // メールボックスから 1 個。無ければ false
uint32_t button_boot_chord(void);            // 起動時に押されていた集合。0 = 通常起動
void button_boot_wait_release(void (*tick)(void)); // 全解放まで tick を回して待つ
```

LED の一時表示と、起動時のモード提示（[§13.5](#135-led-の一時表示と起動待ち)）。

```c
void led_notify_button(void);           // 長押し成立の合図
void led_boot_pattern(uint32_t blinks); // 起動待ち。点滅の回数で選んだモードを示す
```

### 1.3 ファイル一覧の共用

`vgm list` と `mdx list` は、ディレクトリ・拡張子・件数上限を除いて同じ処理をするので
[filelist.c](../src/filelist.c) にまとめてある。`vgm_list()` / `mdx_list()` は引数を渡すだけ。

```c
const char *filelist_print(const char *dir, const char *const *exts, uint32_t n_exts,
                           uint32_t max_entries, void (*tick)(void));
```

`dir` 以下を**再帰**し、扱う名前は常に `dir` からの相対パス（`KONAMI/GRADIUS.VGM`）。
並びは**深さ優先**で、あるディレクトリのファイルを名前の昇順で出し切ってから、
サブディレクトリを名前の昇順で 1 つずつ降りる。

名前を全部ためてからソートすると数十 KB のバッファが要るので、「直前に採った名前より
大きいものの中で最小」を毎回ディレクトリ走査で探す（`scan_min_gt()`）。走査は XIP からの
読み出しだけなので速く、必要な RAM は名前 2 個ぶんで、これは `FILINFO.fname` と同じ
`FF_LFN_BUF + 1`（256 バイト）。同じ関数をサブディレクトリの順序付けにも使う。

**並べ替えの比較子と等値判定は別に持つ。**

- `filelist_name_cmp()` は大小無視で比較し、**大小無視で等しいときは `strcmp()` の結果を
  返す**。上の走査は順序が一意に決まらないと同じ名前を出し続けるか取りこぼすため。
- 拡張子の判定にはこれを使えない。`".MDX"` と `".mdx"` は大小無視では等しくても
  `strcmp()` は 0 を返さないので、一致しなくなる。等値判定は専用の `ext_equal()` が行う。

`tick` は 1 行出すごとに呼ばれる。呼び出し側は `service_all` を渡していて、
一覧の出力中も PCM の送出と I2S への供給が止まらないようにしてある。

#### 再帰の作業領域

段ごとにスタックへ名前 2 本（512 バイト）を積むわけにはいかないので、走査の作業領域は
すべて `static` に置く。

| 変数 | 大きさ | 役割 |
| --- | --- | --- |
| `s_fi` | 約 300 B | 走査に使う `FILINFO`。段をまたいで使い回す |
| `s_dp[FILELIST_MAX_DEPTH]` | 約 416 B | 段ごとの `DIR`。8 段ぶん |
| `s_path` | 161 B | いま見ているディレクトリの絶対パス（`FILELIST_PATH_BUF`） |
| `s_prev` / `s_best` | 各 256 B | 「直前に採った名前」と「走査で見つかった最小の名前」 |

**`s_prev` / `s_best` は段をまたいで共用できる。** 深さ優先の順序がそれを保証している。

- ファイルの走査中に再帰は起きない（同じ段のファイルを出し切ってから降りる）ので、
  ファイル用の `s_prev` は段をまたがない。
- サブディレクトリ用の「直前」だけは再帰を跨ぐが、選んだ名前は `s_path` へ追記してから
  降りるので、**戻ってきたときの `s_path` の最終要素がそのまま「直前」になる**。
  親を開き直すあいだだけ `s_path` の区切りを `'\0'` へ差し替えて `f_opendir()` し、
  直後に `'/'` へ戻す（FatFs はパス文字列を読むだけなので、これで親と子を使い分けられる）。
  段ごとの「直前」バッファが要らなくなる。
- `s_best` は `s_path` へ写すか出力するまでの一時領域で、再帰を跨がない。

`f_readdir()` は `.` と `..` を返さない（[ff.c](../external/fatfs/ff.c) の `dir_read()` が
`et == '.'` を弾く）ので、走査が親へ戻って回り続けることはない。加えて先頭ドットの
ディレクトリと隠し属性・システム属性のディレクトリには潜らない。

#### 上限と検査

| 定数 | 値 | 意味 |
| --- | --- | --- |
| `FILELIST_MAX_DEPTH` | 8 | 潜れる深さ。ルート自身を 1 段目と数える |
| `FILELIST_PATH_MAX` | 127 | ルートからの相対パスの長さ |

上限を超えたものは一覧にもプレイリストにも入れず、件数の行の前に
`# warn    : skipped N path(s) longer than 127 chars` /
`# warn    : skipped N directory(s) deeper than 8 levels` を出す。長すぎるものの数を
数えるのは 1 周目だけ（`filelist_print()` は同じディレクトリを何度も走査するので、
毎回数えると同じファイルを重複して数えてしまう）。

コマンドから来たパスは `filelist_path_ok()` が開く前に検査する。長さ・深さに加えて
`\` `:` と制御文字、空の要素、`.` / `..` を弾く。**`..` を通すとルートの外のファイルを
開けてしまう**ので、ここが実質の境界になる。`vgm_play()` / `mdx_play()` はこの 1 本を
呼ぶだけで、それぞれが自前の検査を持たない。

ルート自身が開けないときだけ `"not found"` / `"io error"` を返す。途中のサブディレクトリが
開けないときは `# warn` を出して走査を続ける。

#### 一覧を RAM へ集める

autoplay のプレイリストは任意の位置の名前を後から引く必要があり、上の「毎回全走査」では
足りない。同じフィルタと同じ順序を使いつつ、ディレクトリ 1 個につき 1 回の走査で
呼び出し側のバッファへ詰める口を別に持つ。

```c
const char *filelist_collect(const char *dir, const char *const *exts, uint32_t n_exts,
                             uint32_t path_max, filelist_buf_t *buf);
```

- 相対パスは `'\0'` 区切りでプールへ、オフセットは `uint16_t` の配列へ入れる。走査しながら
  **二分挿入**するので、全部ためてから並べ替えるための追加バッファが要らず、動かすのは
  `uint16_t` の配列だけで済む。
- `buf->count` をリセットせず**追記**する。並べ替えは**ディレクトリ単位で閉じていて**、
  各ディレクトリのファイルを「そこを詰め始めた位置」から後ろの範囲だけで並べる。
  サブディレクトリの分はその後ろへ積まれるので、結果は `filelist_print()` と同じ
  深さ優先の順になる。だから `vgm list` の出力順と `autoplay list` の並びが一致する。
- `vgm_collect()` → `mdx_collect()` の順に呼べば「`/VGM` の全部 → `/MDX` の全部」が
  1 個のバッファにできる（[§12.1](#121-プレイリスト)）。
- `path_max` より長い相対パスは飛ばす。`vgm_play()` / `mdx_play()` が 127 文字までしか
  受け付けないので、集めても鳴らせない。

走査の実体（`walk()`）は `filelist_print()` と共通で、違いは `filelist_buf_t *` を
渡したかどうかだけ。順序が 2 つの実装に分かれないようにしてある。

`FILINFO` と上の作業領域は 2 本で `static` 共用する。**この 2 本は互いに再入できない。**

## 2. φM の生成

PIO ステートマシン 1 基で GPIO をトグルする（1 命令 1 サイクル × 2 で 1 周期）。

```
φM = sys_clk / (2 × clkdiv)
```

プリセットの一覧と切り替え方は [README §2](../README.md#2-クロック設定-φm) にある。
プリセットは動作させたまま切り替えられる（[§2.3](#23-実行時の切り替え)）。

### 2.1 システムクロックを φM に合わせる理由

φM とシステムクロックは**整数分周（ジッタなし）になる組**でしか意味を持たないため、
両者をペアにしたプリセットとして [opm.h](../src/opm.h) に持たせている。

`φM × 偶数 = sys_clk` がちょうど成り立つ組でのみ `clkdiv` が整数（小数部 0）になり、
ジッタのない φM が得られる。RP2350 の既定値 150MHz のままだと 4MHz は
`clkdiv = 18.75`、3.579545MHz は `clkdiv = 20.953125`（1/256 に丸めた値）となり、
どちらも小数分周になる。小数分周でも平均周波数の誤差は無視できる
（前者は誤差なし、後者で約 -35ppm）が、1 周期ごとに ±1 sys_clk
（150MHz で ±6.7ns、φM 3.58MHz の周期に対して約 2.4%）のジッタが乗る。

起動時に `set_sys_clock_khz(OPM_SYS_CLOCK_KHZ, true)` を **`stdio_init_all()` より前に**
呼んでいる（ここで決まるのは起動時のプリセットだけで、以後は
[clockmode.c](../src/clockmode.c) が張り替える）。USB は独立した USB PLL から給電されるため、この変更の影響を受けない。
既定の 144MHz は RP2350 の定格 150MHz 以内なのでオーバークロックにあたらない。
`OPM_CLOCK_MODE_NTSC` の 157.5MHz は定格に対して約 5% のオーバークロックになるが、
電圧設定の変更なしで動作する範囲。

`OPM_CLOCK_HZ` / `OPM_SYS_CLOCK_KHZ` をプリセット外の値へ直接書き換えることもできるが、
その場合は **必ず両方を整数分周になる組で**指定すること（片方だけの変更は小数分周になる）。

### 2.2 小数分周へのフォールバック

プリセット外の φM を指定して整数分周にならない場合は、PIO の小数分周
（`sm_config_set_clkdiv_int_frac8()`、分解能 1/256）にフォールバックする。起動時の
情報表示で実際の分周比を確認できる。

### 2.3 実行時の切り替え

4MHz と 3.579545MHz (= 315/88 MHz) の**両方**が整数分周になる sys_clk は 2520MHz が
最小で、RP2350 では実現できない。したがって φM を変えるには sys_clk ごと張り替えるしかない。
[clockmode.c](../src/clockmode.c) がこれを行う。

守るべきは 1 つ。**φM・BCK・LRCK の H/L 期間を公称値より短くしないこと。**
YM2151 と PCM5102A が短いパルスを取りこぼしたり誤判定したりするのを避ける。

#### 短いパルスが出る条件

φM の H/L 期間は `clkdiv` 個の clk_sys サイクルに等しい（[opm_clock.pio](../src/opm_clock.pio) は
2 命令ループ）。BCK も同じで、H/L = `clkdiv_i2s` 個。したがって:

- clk_sys 自体には欠けたサイクルが出ない。clk_sys は **glitchless mux** を持つ
- clk_sys が**下がる**方向では、進行中の H/L 期間は**伸びる**だけ
- clk_sys が**上がる**方向では、進行中の H/L 期間は最悪
  `clkdiv × 新 clk_sys の周期` まで縮む。**これは新しい周波数での公称 H/L 期間そのもの**

つまり短いパルスは「分周比が小さいまま clk_sys が上がる」ときにだけ出る。規則はこうなる。

> **clk_sys を上げる操作の直前には、その clk_sys に対応する最終の分周比が入っていること。
> 分周比を書き換えるのは clk_sys を下げたあとにすること。**

#### 手順

割り込みを落として一気に実行する。所要は数百 µs。

| | 操作 | そのあいだの φM |
| --- | --- | --- |
| A | clk_sys を pll_usb (48MHz) へ退避する。pll_sys を触るには使用をやめる必要がある | 下げ方向。H/L は伸びるだけ |
| B | 48MHz を前提に分周比を張り直す。**整数へ切り上げる**ので φM は目標以下にしかならない | ほぼ公称値（4MHz なら clkdiv 6 でぴったり、3.579545MHz なら clkdiv 7 で 3.429MHz） |
| C | `pll_init(pll_sys, ...)` で pll_sys を新しい周波数へ再ロックする | B のまま。OPM も DAC も通常の動作範囲に留まる |
| D | 新しい sys_clk を前提にした**最終の**分周比を入れる | 48MHz のままなので 1.1〜1.3MHz へ落ちるが、E までは約 1µs |
| E | clk_sys を pll_sys へ戻す | 上げ方向。最終の分周比が入っているので最悪でも公称値ちょうど |

`clock_configure_undivided()` は内部で一度 clk_ref (XOSC 12MHz) を経由する
（aux mux は glitchless ではないため、SDK が SRC を逃がしてから aux を書き換える）。
このため A と E それぞれに数 µs の「clk_sys 12MHz」の窓ができるが、これも下げ方向なので
短いパルスにはならない。E で戻るときは最終の分周比が効く。

`clk_peri` と `clk_ref` は起動時の設定（pll_usb / XOSC）のままで触らない。

#### 分周比の書き換え自体

走ったままの SM に `SMx_CLKDIV` を書くと、進行中のカウントがどう扱われるかは規定されて
いない。**SM を一瞬止めてから書く**ことでこの不確定性を消している。

```c
pio_sm_set_enabled(pio, sm, false);   /* ピンは最後のレベルを保持 = H/L が伸びる */
pio_sm_set_clkdiv_int_frac8(pio, sm, div_int, div_frac8);
pio_sm_clkdiv_restart(pio, sm);       /* 分周カウンタを 0 に。次の H/L は必ず全幅 */
pio_sm_set_enabled(pio, sm, true);
```

`pio_sm_clkdiv_restart()` は `CTRL.CLKDIV_RESTART` を立てるだけで PC / X / Y / ISR / OSR
には触らない。**`pio_sm_restart()` は使わない**（[i2s.pio](../src/i2s.pio) の注意書きのとおり、
PC を先頭へ戻すと X が中途半端なまま位相が恒久的に狂う）。

#### 影響を受けない部分

| | 理由 |
| --- | --- |
| ym3012 キャプチャ | [ym3012.pio](../src/ym3012.pio) は clkdiv 固定 1 で、SO / φ1 / SH1 / SH2 のエッジ駆動。12MHz の窓のあいだだけ φ1 に対する余裕が減って数フレーム壊れうるが、毎フレーム SH1 で再同期する |
| VGM のテンポ | `time_us_64()` 基準。タイマのティックは clk_ref (XOSC) 系なので sys_clk と無関係（[§9.2](#92-スケジューラ)） |
| USB | `clk_usb` は pll_usb 系で、pll_sys の再構成に影響されない |
| BUSY 待ち | `OPM_BUSY_CYCLES`（72 φM）から実 φM で実行時に算出するので、切り替えのたびに計算し直される（[§3.1](#31-タイミング定数)） |
| I2S の先行量 | 切り替え中はメインループが約 300µs 止まるが、先行 `I2S_TARGET_FRAMES` = 16.4ms に対して十分短い。アンダーランしない |
| フラッシュ (QMI) | 分周は `PICO_FLASH_SPI_CLKDIV = 4` 固定で clk_sys に追従する。遷移の両端 36MHz / 39.4MHz はどちらも起動時に実績のある構成 |

`sys_clk` に依存して実行時に算出している値（[opm.c](../src/opm.c) の `s_setup_cycles` /
`s_data_wait_cycles` と φM の分周比、[i2s.c](../src/i2s.c) の `s_div256`）は、
切り替えのたびに計算し直す。
I2S 側は `clkdiv_i2s = 2 × clkdiv_opm`（[§5.2](#52-サンプリングレートのロック)）の関係だけで決まるので、
B で使う切り上げた分周比にもそのまま追従する。

## 3. OPM バスシーケンス

OPM への 1 レジスタ書き込みは「アドレスラッチ」→「データ書き込み」の 2 サイクルからなる。

```
[アドレスサイクル]
  A0 = L, D0-D7 = レジスタアドレス
  データ確定を待つ (t_SETUP)
  /WR = L → t_WR 保持 → /WR = H
  t_ADDR 待機

[データサイクル]
  A0 = H, D0-D7 = 書き込む値
  データ確定を待つ (t_SETUP)
  /WR = L → t_WR 保持 → /WR = H
  BUSY 待機     ← OPM の内部処理（BUSY）が終わるまで。72 φM サイクル
```

読み出しは 1 サイクルで、`opm_read()`（`r 0` / `r 1`、[README §3.21](../README.md#321-r読み出し)）
だけが使う。**データバスの向きの切り替えが衝突防止そのもの**なので、この順序は崩さない。

```
[読み出しサイクル]
  D0-D7 を入力へ倒す        ← OPM に駆動させる前に必ず先に行う
  A0 = 読み出し先, /CS = L
  アドレス確定を待つ (t_SETUP)
  /RD = L → t_RD 保持 → D0-D7 を取り込む → /RD = H
  /CS = H
  t_FLOAT 待機              ← OPM が D0-D7 を手放すまで
  D0-D7 を出力へ戻す
```

**書き込み経路ではステータスレジスタの BUSY フラグを見ない。** 読み出せるようになった
後も、データサイクル後は **BUSY が明けるのに要する時間だけ待つ**（`OPM_BUSY_CYCLES`）
ままにしてある。BUSY 長が完全に一定であることが実測で確定しているので、
ポーリングには副作用しか無い（[§3.1](#31-タイミング定数)）。

### 3.1 タイミング定数

[opm.h](../src/opm.h) の定数で調整する。クロック依存の待ち時間は `clock_get_hz(clk_sys)` から
実行時に算出しているため、φM プリセットを変えても定数の書き換えは要らない。

| 定数 | 既定値 | 考え方 |
| --- | --- | --- |
| `OPM_T_SETUP_NS` | 100 ns | データ確定から /WR 立ち下がりまで。実際は GPIO 操作の命令実行時間で満たされるが明示的に確保する |
| `OPM_T_WR_US` | 1 µs | /WR の L 期間 |
| `OPM_T_ADDR_US` | 5 µs | アドレスラッチ後の待機 |
| `OPM_BUSY_CYCLES` | 72 φM | データ書き込み後の BUSY 待ち。**µs ではなく φM サイクルで持ち、実 φM から実行時に算出する**（4MHz で 18.0µs / 3.579545MHz で 20.1µs）。実測の 67.1 サイクルに約 7% の余裕を足した値（[test/opm_busy/](../test/opm_busy/README.md)） |
| `OPM_T_RD_US` | 1 µs | /RD の L 期間。データシートのアクセス時間に対して大きく余裕を取った仮置き |
| `OPM_T_FLOAT_US` | 1 µs | /RD を H に戻してから D0-D7 を出力へ戻すまで。OPM がバスを手放すのを待つ |
| `OPM_T_IC_LOW_MS` | 10 ms | /IC の L 保持時間 |
| `OPM_T_IC_WAIT_MS` | 10 ms | /IC を H に戻してから最初の書き込みまでの待機 |

**`OPM_BUSY_CYCLES` 以外はデータシートの最小値から詰めた値ではなく、余裕を大きく取った
仮置きである。** この値で [test/](../test/) の全キャプチャ（数千条件）が取れているので
「短すぎはしない」ことは分かっているが、どこまで短縮できるかは測っていない（未確認）。

`OPM_BUSY_CYCLES` だけは実測に基づく。BUSY はデータサイクルから **67.1 ± 0.2 φM
サイクル**で落ち、**レジスタアドレスにも書き込む値にもチップの発音状態にも依存しない**
（[test/opm_busy/](../test/opm_busy/README.md)）。したがって

- **単位は µs ではなく φM サイクル。** `s_setup_cycles` と同じく実行時に算出するので、
  φM プリセットを切り替えても定数の書き換えが要らない。算出は
  `opm_clock_compute()` が目標値ではなく**実 φM**（`s_clock_hz_actual`）で行う。
  クロック切り替えの途中で使う切り上げ分周比では実 φM が目標を下回るため、
  目標で割ると待ちが足りなくなる
- **BUSY のポーリングには置き換えない。** 削減幅は固定待ちと同じ 7µs で、
  副作用（チップ不在時の無限ループ、アサート遅延 0.33µs の余裕、D0-D7 が 5V を
  受ける時間の増加）だけが増える（同 README の「案 C を採る理由が無い」）
- **待ちの繰り延べもしない。** 平均は下がるが最悪は下がらず（`opm_clear()` の密ループには
  重ねる仕事が無い）、φM の張り替え前と `opm_reset()` の前に未消化の待ちを消化する
  制約が新たに増える

1 レジスタ書き込みは約 25µs（最大 4 万回/秒）。実測値は `s` の `OPMW` 行に出る
（[README §3.11.1](../README.md#3111-サービスの呼び出し間隔)）。

### 3.2 リセット手順

1. φM の出力を開始する（PIO を先に動かしておくこと）
2. /IC = L にして `OPM_T_IC_LOW_MS` 保持
3. /IC = H に戻して `OPM_T_IC_WAIT_MS` 待機

φM が停止した状態で /IC を操作しても OPM は初期化されないため、順序が重要。

## 4. YM3012 DAC キャプチャ

OPM が YM3012 (DAC) へ送るシリアル出力を PIO + DMA で取り込み、Core 0 で
signed 16bit little-endian ステレオ PCM へ変換して 2 本目の USB CDC へ流す。
ロジックアナライザを使わずに Pico 2 単体で波形が取れる。

**PIO と DMA は起動時から常時動いている。** `p 1` / `p 0`（[README §3.10](../README.md#310-ppcm-出力)）が
切り替えるのは「リングから読み出して CDC へ流すかどうか」だけで、取り込み自体は止めない。

```
     YM3012
   SO / φ1 / SH1
        │
        ▼
       PIO  ← 1 フレーム 32bit を組む（ビット取り込みだけ）
        │
        ▼
       DMA  ← ハードウェアリングへ書き続ける（割り込みなし）
        │
        ▼
  16KB リングバッファ
        │
        ▼
     Core 0  ← YM3012 形式 → PCM 変換
        │
        ▼
  USB CDC #1（signed 16bit LE ステレオ）
```

### 4.1 フレームの構造

φ1 は φM/2 のビットクロック。1 変換 = φ1 16 クロック、CH1 → CH2 の順に繰り返すので
**1 フレーム = 32 クロック**、出力レートは **φM/64**（φM 4MHz なら 62500Hz）になる。

CH1 の D0 を起点にしたときのフレームの中身は次のとおり。

| φ1 クロック | 内容 |
| --- | --- |
| 0..9 | CH1 仮数 D0..D9 |
| 10..12 | CH1 指数 S0..S2 — 直後に **SH2 が立ち下がる** |
| 13..15 | 無効 ×3 |
| 16..25 | CH2 仮数 D0..D9 |
| 26..28 | CH2 指数 S0..S2 — 直後に **SH1 が立ち下がる** |
| 29..31 | 無効 ×3 |

**CH1 = L / CH2 = R。** SH1 と SH2 はそれぞれ相手チャネルの名前が付いているように見えるが、
SH2 が CH1 の、SH1 が CH2 のサンプルホールドである。したがって、

- **SH1 の立ち下がり**の直後から 32bit 取り込むと `L, R` の順になる
- SH2 の立ち下がりの直後から取り込むと `R, L` の順になってしまう

ので、フレーム同期には **SH1 の立ち下がり**を使う。この対応は
[test/dac_lr/](../test/dac_lr/README.md) で実測により確定している。

### 4.2 PIO によるビット取り込み

[ym3012.pio](../src/ym3012.pio) の 7 命令。入力は in_base (GP17) から連続 4 本で、
ピンはすべて in_base からのオフセットで参照する（GPIO 番号は現れない）。
**SO / φ1 / SH1 / SH2 を GP17 から連続で割り当てないといけないのはこのため。**

```
.wrap_target
    wait 1 pin 2            ; SH1 が H になるのを待つ
    wait 0 pin 2            ; SH1 立ち下がり = CH2 スロットの終端。次は CH1 (L)
    set  x, 31              ; 1 フレーム = 32bit
bitloop:
    wait 0 pin 1            ; φ1 の L 区間へ入る
    wait 1 pin 1            ; φ1 立ち上がり
    in   pins, 1            ; SO を 1bit 取り込む
    jmp  x--, bitloop
.wrap
```

- **右シフト + autopush（閾値 32）**。YM3012 は LSB first なので、右シフトすると
  先に届いたビットがそのまま LSB 側へ落ちる
- 1 フレーム = 1 エントリ。**L が下位 16bit、R が上位 16bit** に入る。L と R が
  ハードウェア的に不可分なので、途中でずれることがない
- **毎フレーム SH1 で取り直す**ので、一度ずれても次のフレームで復帰する
- TX FIFO は使わないので `PIO_FIFO_JOIN_RX` で RX を深さ 8 にする
- 分周なし。φ1 (2MHz) に対して sys_clk (144MHz) は 1 クロックあたり 72 サイクルある

φM 生成用の PIO ([opm_clock.pio](../src/opm_clock.pio), 2 命令) と I2S 出力用の PIO
([i2s.pio](../src/i2s.pio), 8 命令) とは別のステートマシンを使う。3 つとも
`pio_claim_free_sm_and_add_program()` で動的に確保するので、SM も命令メモリのオフセットも
固定していない。合計 17 命令で、RP2350 には PIO ブロックが 3 つ（各 4 SM / 32 命令）
あるので余裕がある。

得られる 32bit ワードのビット配置:

```
bit  0.. 2 : 無効 ×3        bit 16..18 : 無効 ×3
bit  3..12 : L 仮数 D0..D9   bit 19..28 : R 仮数 D0..D9
bit 13..15 : L 指数 S0..S2   bit 29..31 : R 指数 S0..S2
```

### 4.3 PCM への変換

データシート LSI-2130123 (1992-04) より、YM3012 の 1 語は
**無効 3bit + 仮数 10bit + 指数 3bit** で、いずれも LSB first。

- 仮数は 10bit オフセットバイナリ。符号付き値は `m - 512`（範囲 −512..+511）
- 指数は `E = S2*4 + S1*2 + S0`。E が大きいほどステップが粗い（E=1 が最も細かい）
- 線形値は **`pcm = (m - 512) << (E - 1)`**
- **`E = 0` は 3→7 デコーダの禁止コード**で正常な出力には現れない。0 として扱う

値域は **−32768**（m=0, E=7）〜 **+32704**（m=1023, E=7 = 511<<6）。
正側が +32767 に届かないのは仕様どおりで、正規化してはいけない。

実装は [ym3012.h](../src/ym3012.h) の `ym3012_word_to_pcm()`。

MDX の ADPCM パートを鳴らしているあいだは、この変換の**直後**に ADPCM が加算される
（[§10.7](#107-adpcm-pcm8-の再生)）。加算はカーソルによらず同じ結果になるので、
USB キャプチャと I2S には同じ音が乗る。禁止コード E=0 の計数は加算より前に済ませて
あるので、統計は取り込んだ信号の品質を表したまま変わらない。

### 4.4 DMA リング

RP2350 のハードウェアリング機能で、PIO の RX FIFO からリングバッファへ書き続ける。

| 項目 | 値 |
| --- | --- |
| 転送サイズ | 32bit（1 フレーム = 1 転送） |
| リングサイズ | 16384 バイト = 4096 フレーム（`channel_config_set_ring(.., true, 14)`） |
| バッファのアライン | 16384 バイト境界（リング機能はアドレス下位ビットだけを回すため） |
| TRANS_COUNT | `dma_encode_endless_transfer_count()`（MODE=ENDLESS） |
| DREQ | `pio_get_dreq(pio, sm, false)` |
| 割り込み | **使わない** |

φM 4MHz では 62500 フレーム/s なので **流入は 250 KB/s**、リングは **65.5ms 分**になる。
これが Core 0 と USB が停滞できる上限。

CPU は `dma_channel_hw_addr(ch)->write_addr` から書き込み位置を読む。リング内の位置は
12bit しか分からないので、差分を積んで 64bit の総フレーム数へ延ばす。呼び出し間隔が
リング一周より短い限りこの差分は一意に決まる。読み出し位置との差が未処理フレーム数で、

| 未処理フレーム数 | 状態 |
| --- | --- |
| 0 | empty |
| 1 .. 4095 | データあり |
| 4096 以上 | **overrun** |

リング末尾をまたぐ読み出しはそこで 2 回に分割する。

**読み出し位置は消費者ごとに持つ。** USB キャプチャと I2S 出力（[§5](#5-i2s-出力)）は
同じリングを別々のペースで読むので、`ym3012_reader_t` を各自が 1 個持ち、
`ym3012_reader_read_pcm()` がそのカーソルだけを進める。書き込み位置
（`s_write_total`）は 1 つで、DMA の位置から更新する。

```c
typedef struct {
    uint64_t read_total;
    bool     count_forbidden;  // 禁止コード E=0 を統計へ数えるか
} ym3012_reader_t;
```

`count_forbidden` を分けているのは、`E0`（[README §3.11](../README.md#311-s統計)）が
「キャプチャしたデータの品質」の指標だから。常時回っている I2S 側で数えると意味が
変わるので、数えるのは USB キャプチャ側のカーソルだけにしている。

引数を取らない `ym3012_unread()` / `ym3012_read_pcm()` などは、USB キャプチャが使う
既定カーソルへのラッパとして残してある。

### 4.5 DMA overrun

未処理がリング全体に達すると、最も古いフレームが DMA に踏まれた可能性がある。
壊れたデータを PCM として送り続けないよう、次のように扱う。

1. キャプチャを中止して PCM 送信を停止する（状態は `ERROR`）
2. コマンド CDC へ `# ERR dma overrun` を出す
3. `p 2`（演奏連動、[§4.7](#47-演奏に連動したキャプチャ-p-2)）で始めていたなら、続けて
   `# capture : abort (dma overrun)` を出してから `s_auto` を落とす。**この経路では
   `# capture : done` を出せない**ので、合図を出さないとホストは上限まで待ち続ける
4. LED をエラー表示にする（[README §3.9](../README.md#39-led)）
5. 次の `p 1`（または待機へ戻す `p 0`）を受けるまで止まったままにする

**PIO と DMA は止めない。** リングの整合性は次の `p 1` で読み出し位置を取り直して回復する。

`# ` を付けた情報行として出しているのは、裸の `ERR ...` を非同期に出すと
「1 コマンド 1 応答」（[README §3.3](../README.md#33-応答)）を破り、ホスト側のパーサが実行中の
コマンドの応答と取り違えて同期を失うため。状態は `s`（[README §3.11](../README.md#311-s統計)）の
`state` と `OVERRUN` からも読める。

### 4.6 起動時の自己診断

ロジックアナライザを繋がずに PIO のビット順を検証するため、起動時に
**ループバック自己診断**を 1 回だけ実行する。

キャプチャ用 PIO が参照するのは SO / φ1 / SH1 の 3 本だけで、しかも純粋にエッジ駆動で
タイミング制約が無い。そこで DMA を仕掛ける前に、未接続の **GP26-GP28** を CPU から
ビットバンギングして既知の (L, R) を含む合成フレームを流し込み、PIO が push した
32bit ワードと変換後の PCM が期待値と一致するかを確かめる。これで

- SH1 立ち下がりの検出
- φ1 立ち上がりでの SO サンプリング
- LSB first / 右シフト / autopush 32
- 16bit ワードのフィールド配置と L, R の順序

がまとめて検証できる。結果は起動バナーと `t`（[README §3.12](../README.md#312-t自己テスト)）で
確認できる。

**GP26-GP28 は I2S 出力（[§5](#5-i2s-出力)）と同じ 3 本**なので、両立しない。
`YM3012_LOOPBACK_ENABLED` の既定値は `I2S_ENABLED` から決まり、I2S が有効なら診断を
行わず結果は `SKIP (disabled)` になる。DAC を外して診断だけ試すときは
`-DYM3012_LOOPBACK=1` で再コンフィグする。

### 4.7 演奏に連動したキャプチャ (`p 2`)

`p 1` との違いは**録り始めと録り終わりだけ**で、送信の実装はどちらも同じ経路を通る。
状態が 1 つ増える。

```
IDLE --p 1--> CAPTURING --p 0--> DRAINING --送り切り--> IDLE
IDLE --p 2--> WAITING --play--> CAPTURING --曲の終わり--> DRAINING --> IDLE
```

`WAITING` は IDLE と同じくリングを読み捨てるだけで、CDC #1 へは 1 バイトも出さない。
**待っている間の無音を WAV に入れないため。** ここで溜め込むとリング 65.5ms 分で
overrun するので、読み捨ては省けない。

**開始と終了の合図はどちらも `capture_note_track(active, seq)` で外から渡す。**

- `seq` は `songend_track_seq()`（`vgm_play_seq() + mdx_play_seq()`）。`p 2` の時点の値を
  控えておき、変わったら「次の play が起きた」。**レベル（鳴っているか）では拾えない** —
  鳴っている最中に別の曲を `play` しても再生状態は落ちないため。`WAITING` 中に変われば
  録り始め、`CAPTURING` 中に変われば打ち切る（1 キャプチャ = 1 曲）
- `active` は `songend_is_active()`（[§11](#11-曲の終わり方-songend)）。**余韻が消えるまで
  true** なので、`p 2` の録り終わりは自動再生が次の曲へ送るのと必ず同じ時刻になる

**[capture.c](../src/capture.c) は vgm / mdx / songend を include しない。** 判定を持ち込むと、
`storage host` の排他をコマンド層に置いたのと同じ理由で層が濁る。渡ってくるのは
`bool` と番号だけ。

呼び出しは [pico-opm-writer.c](../src/pico-opm-writer.c) の `service_all()` で、**シーケンサの
間引き（`due()`）の外**に置く。比較が数回で済むうえ、間引くと待機から録り始めるまでの
遅れがそのまま WAV の頭の欠けになる。

終了は `# capture : done <n> frames` で通知する。`#` 始まりの情報行なので「1 コマンド
1 応答」（[README §3.3](../README.md#33-応答)）は崩れない。`n` は
`ym3012_read_total() - s_start_total`、つまり CDC #1 へ積んだフレーム数そのもの。

**終わったことは異常終了でも必ず通知する。** DMA overrun（[§4.5](#45-dma-overrun)）は
1 フレームも送れないまま止まるので `done` を出せない。代わりに
`# capture : abort (dma overrun)` を出す。この 2 行のどちらかが出るまでホストは
待つので、片方でも欠けるとホストは `--song-max-ms` を使い切るまで気付けない。

## 5. I2S 出力

キャプチャした PCM を、そのまま I2S で外部 DAC (PCM5102A) へ流す。
利用者から見た仕様と配線は [README §5](../README.md#5-i2s-出力)。

USB キャプチャと同じリングを [§4.4](#44-dma-リング) の別カーソルで読むので、
`p 1` と同時に動いても互いに干渉しない。**起動時から常時動いていて、停止する手段は無い。**

MDX の ADPCM パートは変換の直後に足されるので、I2S にも USB キャプチャと同じ音が
乗る（[§10.7](#107-adpcm-pcm8-の再生)）。

```
  16KB キャプチャリング（[§4.4](#44-dma-リング)）
        │
        ▼
     Core 0  ← YM3012 形式 → PCM 変換（I2S 用のカーソルで読む）
        │
        ▼
  16KB 出力リング  ← DMA の読み出し位置より 1024 フレーム先を維持する
        │
        ▼
       DMA  ← ハードウェアリングから PIO TX FIFO へ流し続ける（割り込みなし）
        │
        ▼
       PIO  ← BCK / LRCK / DIN を作る
```

### 5.1 PIO プログラム

[i2s.pio](../src/i2s.pio) の 8 命令。sideset 2bit に BCK / LRCK、OUT 1bit に DIN を割り当てる。
**LRCK は BCK の次の GPIO でなければならない**（sideset は連続したピンにしか出せない）。

```
.side_set 2                         ;  bit1 = LRCK / bit0 = BCK
.wrap_target
bitloop_r:
    out pins, 1        side 0b10    ; BCK L: ビットを出す
    jmp x--, bitloop_r side 0b11    ; BCK H: DAC が拾う。15bit ぶん回る
    out pins, 1        side 0b00    ; 16bit 目。ここで LRCK を先に落とす
    set x, 14          side 0b01
bitloop_l:
    out pins, 1        side 0b00
    jmp x--, bitloop_l side 0b01
    out pins, 1        side 0b10    ; 16bit 目。ここで LRCK を先に上げる
    set x, 14          side 0b11
.wrap
```

1 bit = 2 命令 = 2 サイクル（BCK の L 区間と H 区間）で、1 フレーム = 32bit = **64 サイクル**。
各 16bit ブロックの最終ビットを出すところで LRCK を先に反転させているのが、I2S の
「LRCK 遷移の 1 BCK 後から新しいワードの MSB が始まる」規約にあたる。

**ワードのビット並びが [§4.3](#43-pcm-への変換) の出力形式とそのまま一致する。**

- OSR は MSB first (`shift_right = false`) の 32bit autopull なので、先に出るのは上位 16bit
- 先に出るブロックは LRCK=1 の期間 = Philips I2S の R チャンネル
- キャプチャ側のフレーム形式は「下位 16bit = L (CH1) / 上位 16bit = R (CH2)」

つまり `ym3012_reader_read_pcm()` が `out[2i]=L, out[2i+1]=R` と書いたバッファを
`uint32_t` として DMA で流すだけでよく、**並べ替えや専用の変換関数は要らない**
（リトルエンディアンであることが前提。`_Static_assert` で担保している）。

`pio_sm_init()` はスクラッチレジスタ X を初期化しないので、
`i2s_out_program_init()` の末尾で `pio_sm_exec()` を使って X = 14 を入れている。
SM 停止中の `pio_sm_exec()` は即時実行されるため、呼び出し側が `pio_sm_set_enabled()` を
呼ぶ時点で X は 14 になっている。走り出したあとは各位相の 16bit 目の `set x, 14` が
次の位相ぶんを仕込むので、以後はプログラム内で回る。

これを省くと最初の R ブロックのビット数が 16 からずれ、以後ワード境界と LRCK の位相が
**恒久的に**ずれる（autopull は 32bit ごとに引くのに対し、LRCK は 32bit 周期のままなので
一度ずれると戻らない）。同じ理由で、**SM を再起動する経路を足すときは X を入れ直すこと**。
PC だけプログラム先頭へ戻すと、X が中途半端な値のまま最初の位相のビット数がずれる。

1 フレームが 64 サイクルに厳密に収まっていて、各位相の 16bit 目の BCK H 区間が
その `set x, 14` そのものなので、[§4.2](#42-pio-によるビット取り込み) の取り込み側のように
`.wrap_target` の直後へ初期化用の `set x` を置く余地は無い（1 命令足すとレートが狂う）。

### 5.2 サンプリングレートのロック

φM も I2S も同じ sys_clk を PIO で分周して作っているので、**両者は同一クロック源で
完全にロックする**。リサンプリングもドリフト補正も要らず、固定長のバッファを挟むだけでよい。

1 フレーム = 64 サイクル、fs = φM/64 なので

```
clkdiv_i2s = sys_clk / (64 × fs) = sys_clk / φM
```

φM 側は 2 命令のループなので `clkdiv_opm = sys_clk / (2 × φM)`。したがって

```
clkdiv_i2s = 2 × clkdiv_opm
```

`i2s_init()` は `opm_clock_div_int()` / `opm_clock_div_frac()` から 16.8 固定小数の
分周値を組み立て、**256 倍のまま 2 倍する**。丸めを一度も挟まないので、プリセットが
小数分周になる場合でもレートは厳密に一致する。

2 プリセットではどちらも整数分周になる。

| プリセット | sys_clk | φM | fs | clkdiv_i2s | BCK (32fs) |
| --- | --- | --- | --- | --- | --- |
| `4` | 144 MHz | 4.000000 MHz | 62500.0 Hz | 36 + 0/256 | 2.000 MHz |
| `3.58` | 157.5 MHz | 3.579545 MHz | 55930.4 Hz | 44 + 0/256 | 1.7898 MHz |

`i2s_retune()` は同じ式を再計算して、走っている SM の分周比だけを書き換える。
φM 側が何を入れていても `clkdiv_i2s = 2 × clkdiv_opm` の関係だけで決まるので、
クロック切り替えの途中で使う切り上げ分周比にも自動で追従する（[§2.3](#23-実行時の切り替え)）。

### 5.3 出力リングと先行量の維持

[§4.4](#44-dma-リング) のリングを、読み出し側で回す形に反転させたもの。

| 項目 | 値 |
| --- | --- |
| 転送サイズ | 32bit（1 フレーム = 1 転送） |
| リングサイズ | 16384 バイト = 4096 フレーム（`channel_config_set_ring(.., false, 14)`） |
| バッファのアライン | 16384 バイト境界 |
| TRANS_COUNT | `dma_encode_endless_transfer_count()`（MODE=ENDLESS） |
| DREQ | `pio_get_dreq(pio, sm, true)` |
| 割り込み | **使わない** |
| 先行量 `I2S_TARGET_FRAMES` | 1024 フレーム = 16.4 ms |

リング一周をキャプチャ側と同じ 65.5ms に揃えてあるので、**ポーリング間隔の制約は
増えていない**（[§1.1](#11-メインループ)）。

CPU は `dma_channel_hw_addr(ch)->read_addr` から DMA の読み出し位置を読み、差分を積んで
総フレーム数へ延ばす。自分が書いた総フレーム数との差が「DMA の先をどれだけ走っているか」
= 出力レイテンシで、毎周回これを `I2S_TARGET_FRAMES` まで埋め戻す。

起動時はリングが `.bss` の全ゼロ（= 無音）なので、書き込み位置を先行量ぶん進めた
状態にするだけで先行分の無音が用意できる。

**ソースが空のときに無音を差し込まない。** レートが厳密に一致している以上、ポーリングの
位相差でキャプチャ側が一瞬空になるのは正常な状態。ここで無音を入れると差し込んだ分だけ
キャプチャ側にバックログが溜まり、最後は overrun する。足りない分は次の周回で埋める。

逆に CPU が停滞した場合は、DMA が進んだぶん埋め戻す量が増えるので、次の周回で
バックログをまとめて消費して両者が揃う。**追いつき処理は要らない。**

### 5.4 アンダーラン

ENDLESS のリング DMA は止まらないので、埋め戻しが間に合わないと **DMA は無音ではなく
古いリング内容を再生する**。先行量が 0 以下になったら

1. `UNDERRUN` を 1 増やす（[README §3.11](../README.md#311-s統計)）
2. キャプチャ側のカーソルを書き込み位置へ合わせて、溜まった古いフレームを捨てる
3. 先行分を無音で埋め直して仕切り直す

これを完全に防ぐには DMA を止めるか無音バッファへチェーンする必要があり、
割り込みを使わない構成から外れるので採っていない。

先行量が尽きるのは 16.4ms 停滞したときで、キャプチャ側リングの 65.5ms より
はるかに早い。**アンダーランは必ずキャプチャ側の overrun より先に検出される**ので、
I2S 側のカーソルがキャプチャ側リングを一周遅れることはない。

OPM を繋がずに動かした場合はソースが供給されないため、16.4ms ごとに 1. 〜 3. を
繰り返す。出力は無音のままで、`UNDERRUN` だけが増え続ける。

`reset`（/IC リセット）でも必ず 1 回起きる。理由は 2 つあり、どちらも単独で先行量を使い切る。

- `opm_reset()` は `OPM_T_IC_LOW_MS` + `OPM_T_IC_WAIT_MS` = **20ms** をメインループを
  回さずに待つ（[§1.1](#11-メインループ)）。その間 DMA は 1250 フレーム消費するのに
  埋め戻しは走らないので、先行量 16.4ms を超える。
- /IC が L の間は YM3012 が出力を止めるため、**625 フレーム（10ms 相当）がそもそも
  供給されない**。レートが厳密に一致していて余剰が無い（[§5.2](#52-サンプリングレートのロック)）
  以上、この欠損を取り返す方法は無く、先行量から永久に差し引かれる。**先行量を増やしても
  欠損の累積は止まらない。**

欠損量は `s` の `RATE` で確かめられる。`reset` を含む 1 秒だけ 61870 frames/s 前後（= 62500 から
620 ほど少ない）に落ち、/IC を使わない `c` では 62500 frames/s のまま減らない。

## 6. USB CDC 2 本と MSC の実装

コマンド用とキャプチャ用に CDC を 2 本並べる（利用者から見た構成は
[README §3.1](../README.md#31-接続)）。Pico SDK の `stdio_usb` は CDC を 1 本しか
用意しないので、TinyUSB のディスクリプタと初期化はアプリ側で持つ。

- `tinyusb_device` を追加でリンクし、[tusb_config.h](../src/tusb_config.h) と
  [usb_descriptors.c](../src/usb_descriptors.c) を自前で用意する
- `tud_task()` はメインループから回す
- **CDC #0 をディスクリプタの先頭に置く。** こうするとコマンド側のデバイス名が
  1 ポート構成のときと変わらず、既存のホスト側スクリプトがそのまま動く。
  CDC #1 は末尾の番号が増えたものになる
- この構成では `PICO_ENABLE_USB_RESET_VIA_VENDOR_INTERFACE` が無効になるため、
  **BOOTSEL へ自動移行する `picotool load -fx` は使えない**
  （[README §6.4](../README.md#64-書き込み代替経路)）

`PICO_STDIO_USB_STDOUT_TIMEOUT_US=10000` を CMake で定義している。既定の 0.5 秒のままだと、
ホストが CDC #0 を読まないときの `printf` が DMA リングの 65.5ms（[§4.4](#44-dma-リング)）を
食い潰す。同じ理由で `vgm list` は行の出力ごとにメインループのサービスを回す。

### 6.1 MSC の追加

マスストレージは CDC の**後ろ**（インタフェース 4、EP `0x05` / `0x85`）に足す。
CDC #0 をインタフェース 0 に固定したままにするためで、CDC #1 の番号も動かない。
`USBD_ITF_MAX` がそのまま `bNumInterfaces` になるので、enum に 1 行足すだけで追従する。

`CFG_TUD_MSC_EP_BUFSIZE` は論理セクタと同じ 512 にする。こうすると `read10` / `write10`
コールバックの `offset` が常に 0 になり、1 回の呼び出しがちょうど 1 セクタになる。
この define が無いと `msc_device.h` が `#error` で止まる。

**モードの切り替えでインタフェースを付け外ししない。** `bNumInterfaces` を変えるには
`tud_disconnect()` / `tud_connect()` が必要で、`storage host` と打った瞬間に CDC #0 が
切れてしまい、同じセッションからモードを往復できなくなる。代わりに
`tud_msc_test_unit_ready_cb()` の真偽で**メディアの挿抜**として表現する。
false を返すと TinyUSB が自分で MEDIUM NOT PRESENT の sense を立てるので、
PLAYER モードでは PC からの SCSI コマンドが `read10` / `write10` に到達する前に全部失敗する。

### 6.2 SCSI トレース

MSC はホスト側の挙動が見えないので、コールバックが受け取った SCSI をリングに控える
（`usb_msc.c` の `trace()`、直近 320 件）。表示は `storage trace`
（[README §7.4](../README.md#74-マウントされないときの調べ方)）。

**記録だけしてその場では表示しない。** MSC のコールバックは `tud_task()` の中から
呼ばれるので、ここで `printf` すると `stdio_usb` が `tud_task()` を再入しうる。

記録の開始は `storage_set_host()` が `usb_msc_trace_reset()` を呼ぶところ。
PLAYER に戻しても消さないので、イジェクトされたあとでも読み出せる。

## 7. ビルド構成

Pico VS Code 拡張が管理する「DO NOT EDIT」ブロック（`sdkVersion` / `toolchainVersion` /
`picotoolVersion` の設定と `pico-vscode.cmake` の include）は手で書き換えない。
それ以外は次の構成になっている。

- `add_executable` に [§1](#1-ソース構成) の `.c` を並べる
- **ファームウェアのバージョンの定義は `project(VERSION ...)` の 1 箇所だけ。**
  そこから `pico_set_program_version`（バイナリに埋め込むメタデータ。`picotool info`
  が読む）と、`target_compile_definitions` の `OPM_WRITER_VERSION`（`i` と起動バナーが
  表示する版番号）の両方を出す。代替定義は置いていないので、CMake を通さずに積むと
  未定義エラーになる
- `target_compile_options` に `-Wall -Wextra`（自前のソースだけが対象）
- `pico_generate_pio_header(... opm_clock.pio)` / `(... ym3012.pio)` / `(... i2s.pio)` →
  `build/opm_clock.pio.h` / `build/ym3012.pio.h` / `build/i2s.pio.h` を生成
- `target_link_libraries` は `pico_stdlib` / `hardware_pio` / `hardware_dma` /
  `hardware_clocks` / `hardware_pll` / `hardware_flash` / `pico_flash` / `pico_rand` /
  `tinyusb_device` / `fatfs` / `miniz`。`hardware_pll` は [clockmode.c](../src/clockmode.c) の
  `pll_init()`、`pico_rand` は [autoplay.c](../src/autoplay.c) の `get_rand_32()` が要求する
- FatFs と miniz は `add_library(... STATIC ...)` の別ターゲットにする。`-Wall -Wextra` が
  `pico-opm-writer` に `PRIVATE` で付いているので、これで上流コードに波及せず、
  警告抑止も改変も要らなくなる（[§8](#8-ストレージ)）
- miniz は設定ヘッダを持たないので、`miniz` ターゲットの `target_compile_definitions` で
  `MINIZ_NO_STDIO` / `MINIZ_NO_TIME` / `MINIZ_NO_MALLOC` / `MINIZ_NO_DEFLATE_APIS` /
  `MINIZ_NO_ARCHIVE_APIS` / `MINIZ_NO_ZLIB_APIS` を定義し、展開器 `tinfl` だけを残す
- キャッシュ変数 `OPM_CLOCK_MODE` を持ち、指定時のみ同名マクロを
  `target_compile_definitions` で渡す（φM プリセットの切り替え、[§2](#2-φm-の生成)）
- キャッシュ変数 `I2S_ENABLED`（既定 1）は**常に**マクロとして渡す。
  [ym3012.h](../src/ym3012.h) がこれを見て `YM3012_LOOPBACK_ENABLED` の既定値を決めるため、
  未定義のままにできない（[§4.6](#46-起動時の自己診断)）
- キャッシュ変数 `YM3012_LOOPBACK` は指定時のみ `YM3012_LOOPBACK_ENABLED` として渡し、
  上の自動判定を上書きする
- キャッシュ変数 `VGM_VGZ_ENABLED`（既定 1）は**常に**マクロとして渡す。
  [vgz.h](../src/vgz.h) がこれで実装ごと切り替わるため、未定義のままにできない
  （0 にすると展開器と約 84KiB のバッファがリンクされない。[§9.4](#94-vgz-のストリーム展開)）
- キャッシュ変数 `MDX_ENABLED`（既定 1）は**常に**マクロとして渡す。
  [mdx.h](../src/mdx.h) がこれで実装ごと切り替わるため、未定義のままにできない
  （0 にするとシーケンサと 64KiB のファイルバッファがリンクされず、`mdx` コマンドは
  すべて失敗する。[§10](#10-mdx-再生)）
- キャッシュ変数 `PCM8_ENABLED` は指定時のみマクロとして渡す。空なら
  [pcm8.h](../src/pcm8.h) の既定（`MDX_ENABLED` に従う）を使う
  （0 にするとデコーダとミックスリング約 27KB がリンクされない。[§10.7](#107-adpcm-pcm8-の再生)）
- キャッシュ変数 `AUTOPLAY_ENABLED`（既定 1）は**常に**マクロとして渡す。
  [autoplay.h](../src/autoplay.h) がこれで実装ごと切り替わるため、未定義のままにできない
  （0 にするとプレイリスト約 26KB と状態機械がリンクされない。[§12](#12-自動連続再生-autoplay)）
- キャッシュ変数 `BUTTON_ENABLED`（既定 1）は**常に**マクロとして渡す。
  [button.h](../src/button.h) がこれで実装ごと切り替わるため、未定義のままにできない
  （0 にすると GP21 / GP22 に一切触らない。[§13.7](#137-無効化)）
- キャッシュ変数 `STATS_PROFILE`（既定 0）は**常に**マクロとして渡す。1 で `s` に
  `SVCTIME` と `OPMW` の 2 行が増える（[README §3.11.1](../README.md#3111-サービスの呼び出し間隔)）
- FatFs 領域は `FLASH_FATFS_RESERVE_KB`（ファームウェアに残す KiB。既定 256）から
  オフセットとサイズを CMake 側で計算し、`FLASH_FATFS_OFFSET` / `FLASH_FATFS_SIZE` /
  `FLASH_FATFS_TAIL_RESERVE` を**常に**マクロとして渡す。後段のリンク後チェックが
  領域の実値を必要とするため、[flash_disk.h](../src/flash_disk.h) 側の `#ifndef` 既定値は
  CMake を通さないビルドのための保険という位置づけ（[README §7.1](../README.md#71-領域の変え方)）。
  `FLASH_FATFS_OFFSET` / `FLASH_FATFS_SIZE` をバイトで名指しすることもでき、
  `FLASH_FATFS_OFFSET` と `FLASH_FATFS_RESERVE_KB` の同時指定は `FATAL_ERROR` にする。
  サイズを名指ししなければ `FLASH_TOTAL_BYTES`（既定 4194304）から末尾予約と
  オフセットを引いた残り全部になる
- `pico_add_extra_outputs()` の後に [cmake/check_flash_region.cmake](../cmake/check_flash_region.cmake)
  を `POST_BUILD` で走らせ、`__flash_binary_end` と領域が重なっていないかを検査する
  （[§8.5](#85-領域がファームウェアと重ならないこと)）
- `PICO_STDIO_USB_STDOUT_TIMEOUT_US=10000` を定義する（[§6](#6-usb-cdc-2-本と-msc-の実装)）
- `pico_enable_stdio_usb 1` / `pico_enable_stdio_uart 0`
- `target_include_directories` に `src/` を入れる。SDK の tusb_config.h は
  `-isystem` で入るので、これで自前の [tusb_config.h](../src/tusb_config.h) が優先される
- 配布用の `release` ターゲットを持つ。configure 時の値（SDK のパス、各キャッシュ変数の
  実効値）を [cmake/release_config.cmake.in](../cmake/release_config.cmake.in) から
  `build/release_config.cmake` へ焼き、`cmake -P` で走る
  [cmake/make_release.cmake](../cmake/make_release.cmake) が zip に固める。
  **キャッシュ変数を増やしたらテンプレートの `REL_OPTIONS` にも足すこと**（`VERSION.txt`
  に並べるビルドオプション）。版はタグ由来の値と `project(VERSION)` を照合し、違えば
  `FATAL_ERROR` で止める。中身と使い方は [README §6.6](../README.md#66-リリース版の-zip-を使う)

### 7.1 PIO のビルドフロー

`.pio` は `pico_generate_pio_header()` で `build/<名前>.pio.h` に変換され、C 側は
`#include "opm_clock.pio.h"` のように参照する。`.pio` 内の `% c-sdk { ... %}` ブロックは
そのまま生成ヘッダへ展開されるため、`opm_clock_program_init()` のような初期化ヘルパは
ここに書く。

**新しい `.pio` を追加したときは `pico_generate_pio_header()` の行を足して再コンフィグする。**

## 8. ストレージ

内蔵 QSPI フラッシュの一部を FAT ファイルシステムとして使う。層の構成は次のとおり。

```
  VGM Player                USB MSC (usb_msc.c)
      |                            |
    FatFs (external/fatfs)         |
      |                            |
  diskio_flash.c                   |
      |                            |
      +---------> flash_disk.c <---+
                       |
             内蔵 QSPI フラッシュ
```

`flash_disk.c` は論理セクタ 512 バイトのブロックデバイスで、FatFs と USB MSC の
**両方が同じサイズで見る**。所有権は `storage.c` のモードで排他にしており、
同時に両方から触られることはない（[README §7.3](../README.md#73-書き込みの仕組みと制約)）。

### 8.1 `ffconf.h` をプロジェクト側に置く仕組み

FatFs 本体は無改変で `external/fatfs/` に置く。設定だけを
[ffconf.h](../src/ffconf.h) に持たせるために、**上流のテンプレート `ffconf.h` を
`external/fatfs/` へ置かない**。

`ff.h` の `#include "ffconf.h"` がツリー内で唯一の参照で（`ff.c` は `ff.h` と
`diskio.h` しか include しない）、GCC は `"..."` をまず include 元のファイルがある
ディレクトリから探す。そこに無ければ `-I` に入っている `src/` が拾われる。

事故を検出するため [ffconf.h](../src/ffconf.h) は `OPM_FFCONF_H` を定義し、
[diskio_flash.c](../src/diskio_flash.c) が `#if !defined(OPM_FFCONF_H)` で `#error` にする。
`ff.h` 自身も `FF_DEFINED != FFCONF_DEF` をコンパイル時に弾くので、版のずれも検出される。

出所・適用した公式パッチ・省いたファイルは [external/README.md](../external/README.md) に記録している。

### 8.2 ライトバックキャッシュ

フラッシュの消去単位は 4096 バイト、論理セクタは 512 バイトなので、書き込みには
読み出し・修正・書き戻しが要る。8 行 × 4KiB（RAM 32KiB）のキャッシュを挟む。

| 関数 | 性質 |
| --- | --- |
| `flash_disk_read()` | dirty な行はその行から、それ以外は XIP から `memcpy`。ブロックしない・消去しない・キャッシュを汚さない |
| `flash_disk_write()` | キャッシュに載せるだけ。**絶対に消去しない**。空きが無ければ `FLASH_DISK_BUSY` |
| `flash_disk_flush_one()` | 最も古い dirty 行を 1 つ書き出す。**唯一の停止点** |

行数を 8 にしてあるのは、FAT12 のメタデータ（ブートセクタ + FAT + ルートディレクトリ
= 4KiB ブロックで 5 個ほど）とデータクラスタを同時に載せておくため。PC のファイルコピーは
FAT・ディレクトリ・データを交互に書くので、行が少ないとそのたびに追い出しが起きる。

書き出す前に XIP を読んで全 `0xFF` なら消去を省く。新品の基板では領域が
まるごと消去済みなので、初回のフォーマットと最初のコピーが目に見えて速くなる。

`flash_range_program()` へ渡すポインタは RAM を指している必要がある（書き込み中は
XIP が止まる）。キャッシュ行のデータ部を別配列にしてあるのはそのため。

### 8.3 書き出しをいつ行うか

**`tud_msc_write10_cb()` の中でその場で書き出す。** 当初は「キャッシュが埋まったら 0 を
返して呼び直してもらい、その隙にメインループのサービスが書き出す」設計にしたが、これは
成立しない。`tud_task()` はイベントキューを空になるまで同じ呼び出しの中で回すので、
0 を返してもメインループには戻らず、再試行が空回りするだけでコピーが止まる。

HOST モードでは PCM キャプチャと I2S を止めてあるので（[§8.4](#84-所有権の切り替え)）、
ここで数十 ms ブロックしても巻き込む相手がいない。

先回りの書き出しはしない。「dirty が全行に達したら書き出す」ようにすると、ホストが
FAT やディレクトリを何度も書き直すたびに書き出したそばから汚れ直し、書き込み回数が
数倍になる。SCSI の `SYNCHRONIZE CACHE` でも書き出さない（macOS はコピー中にこれを
頻繁に投げてくる）。確実に書き切るのは eject と `storage player` のときだけ。

256KiB のコピー（macOS の `cp`）での実測:

| 方式 | 書き出し回数 | 所要時間 |
| --- | --- | --- |
| 先回り + SYNCHRONIZE CACHE で全書き出し | 640 | 34 秒 |
| 必要になったときだけ | **76** | **3 秒** |

理論値は 256KiB / 4KiB = 64 回なので、1.19 倍まで詰められている。

### 8.4 所有権の切り替え

```
PLAYER --( storage host )--> HOST
    ガード: autoplay 停止中 かつ VGM 停止中 かつ MDX 停止中
            かつ capture_state() == IDLE
    動作:   i2s_set_enabled(false) -> f_unmount() -> メディア挿入

HOST --( storage player / ホストの eject )--> PLAYER
    動作:   flash_disk_flush_all() -> メディア排出 -> f_mount()
            -> i2s_set_enabled(true) -> capture_resync_after_blackout()
```

`STORAGE_MODE_PLAYER` を 0 にしてあるので、`.bss` のゼロ初期値が「メディア非挿入」に
なる。`tusb_init()` から `storage_init()` までの隙間で MSC のコールバックが呼ばれても
安全側に倒れる。

`disk_status()` は HOST モード中に `STA_NOINIT` を返し、FatFs 側からも同時アクセスを塞ぐ。

HOST へ入るとき `storage_take_media_change()` の合図を立て、MSC 側は最初の
TEST UNIT READY で 1 回だけ UNIT ATTENTION（`0x06` / ASC `0x28`「メディアが
入れ替わった」）を返す。`tud_msc_test_unit_ready_cb()` が false を返しても、
sense を先に立てておけば TinyUSB は MEDIUM NOT PRESENT で上書きしない
（`msc_device.c` は `sense_key` が 0 のときだけ既定値を入れる）。

またホストがメディアを 1 度も読んでいないうちに来た LOEJ は無視する。
これは利用者の操作ではなく「前に取り外したのだから入れ直すな」というホストの指示で、
従うと `storage host` に戻せなくなる。

**ただし macOS では、一度取り出すと USB を挿し直すまでディスクとして戻ってこない。**
UNIT ATTENTION を返しても、TinyUSB がリムーバブルメディアとして申告していても、
LOEJ 処理を完全に無効にしても変わらないことを実機で確認した。取り出した時点で
ホスト側の USB マスストレージドライバがデバイスから切り離されるためで、
ファームウェア側から回避する手段は無い（[README §7.2](../README.md#72-pc-から曲データをコピーする)）。

### 8.5 領域がファームウェアと重ならないこと

`storage_init()` でリンカシンボル `__flash_binary_end` を読み、領域の先頭を超えていたら
`STORAGE_FS_REGION_OVERLAP` にして**マウントも書き込みも一切しない**。

`hard_assert` で止めないのは、基板が起動しなくなると復旧しづらいため。状態として
持ち回り、`i` と `storage status` から常時見えるようにしている。

ただし実行時の検査は焼いて起動するまで結果が分からないので、**その前に 2 段構えで
落とす**。

領域自体の妥当性は [flash_disk.c](../src/flash_disk.c) の `_Static_assert` でコンパイル時に
検査する。4096 バイト境界に揃っているか、末尾の予約セクタに食い込んでいないか、
クラスタ数が FAT12 の上限（4085）を下回るか。

ファームウェアと重なっていないかは、リンクが終わらないと分からない。
[cmake/check_flash_region.cmake](../cmake/check_flash_region.cmake) を `POST_BUILD` で
走らせ、`${CMAKE_NM}` で `__flash_binary_end` を読んで領域の先頭と突き合わせる。
重なっていれば `FATAL_ERROR` でビルドが失敗し、そうでなければ余裕のバイト数を出す。

末尾の予約セクタ（`FLASH_FATFS_TAIL_RESERVE`、既定 4096）は picotool が UF2 へ入れる
RP2350-E10 の absolute block 用。0x10FFFF00 狙いのブロックが 4MiB のフラッシュでは
末尾セクタへ折り返すので、ここを領域に含めると UF2 で焼くたびにファイルシステムの
末尾が潰れる（[README §7.1](../README.md#71-領域の変え方)）。

## 9. VGM 再生

### 9.1 コマンドの解釈

`vgm_step()` が 1 コマンドずつ処理する。オペランド長は `operand_len()` の表で引き、
`0xFF` は「未知なので中断」。**どの経路も必ず 1 バイト以上消費する**ので、
壊れたファイルでも無限ループにならない。シークは必ずファイル全体の長さと突き合わせる
（`.vgz` では `f_size()` の代わりに gzip トレーラの ISIZE を使う。[§9.4](#94-vgz-のストリーム展開)）。

`0x54 aa dd`（YM2151 書き込み）の `aa` は 8bit のレジスタアドレスそのもので、
**bit7 をマスクしてはいけない**。`0x80`-`0xFF` は D1L/RR・KC・KF・PMS/AMS の実レジスタで、
落とすと音が出なくなる。2 個目の YM2151 は別オペコード `0xA4` で、固定長スキップで飛ばす。

`0x67` のデータブロックは MB 単位になりうるので、`f_lseek()` で飛ばす（1 バイトずつ
読んで飛ばすと破綻する）。`.vgz` はシークできないので別扱いになる（[§9.4](#94-vgz-のストリーム展開)）。

`vgm_play()` はヘッダ解析のあと `apply_file_clock()` を呼び、オフセット `0x30` が申告する
YM2151 のクロックへ φM を寄せる（[clockmode.c](../src/clockmode.c) の
`clockmode_follow_file()`。最寄りのプリセット、境界は 2 つの中点 3789772Hz）。
これは `opm_clear()` と `s_start_us` の設定より前に済ませるので、切り替えに使った
数百 µs が再生の起点に乗らない。寄せてもなお一致しないときだけ、残ったずれを警告する。

`clock fixed` のときは寄せずに警告だけを出す。クロックを切り替えられない状態
（PCM キャプチャ中）で切り替えが必要になった場合は、`vgm_play()` 自体が
`wrong state` で失敗する（[§2.3](#23-実行時の切り替え)）。

### 9.2 スケジューラ

```c
s_due_us = s_start_us + (s_samples * 1000000ull) / VGM_SAMPLE_RATE;
```

**絶対サンプル数から毎回計算し直す**ので丸め誤差が累積しない。ループの継ぎ目でも
`s_samples` と `s_start_us` を触らないため、時間の不連続も生じない。

1 回の `vgm_service()` は `VGM_BUDGET_US`（500µs）で打ち切る。メインループは 1 周回で
標準入力を 1 文字しか読まないので、ここを大きくするとコマンド入力が遅くなる
（1.5ms にすると 660 文字/秒まで落ちる）。500µs なら約 2000 文字/秒で、
追いつき能力は `opm_write()` が 32µs なので約 28k writes/s あり十分。

ハードウェアタイマの割り込みは使わない。`opm_write()` が 32µs ブロックするため、
キーオンが集中すると割り込み文脈を数 ms 占有して `i2s_service()` を飢えさせる。
「アプリコードに割り込みハンドラを置かない」という既存の方針も崩れる。

キャプチャのフレームカウンタ（φM/64）から時計を取る案も採らない。62500 → 44100 の
換算が結局必要なうえ、再生タイミングがキャプチャ経路の健全性に依存してしまう。

`VGM_RESYNC_LAG_US`（200ms）を超えて遅れたら、遅れを早送りで取り返さずに時計の方を
現在時刻へ張り直す。回数は `s` の `reslip` に出る。

### 9.3 書き込み中の停止とリング位置

**これを外すと既存機能が無警告で壊れるので、実装で最も注意を要する点。**

`ym3012_ring_poll()` と `i2s_poll()` は DMA ポインタの差分を**リング長 4096 フレームで
剰余を取って**総フレーム数に積む（[§4.4](#44-dma-リング) / [§5.3](#53-出力リングと先行量の維持)）。
これにより

```
s_write_total ≡ DMA の書き込み添字 (mod YM3012_RING_FRAMES)
s_dma_total / s_fill_total ≡ リング内の添字 (mod I2S_RING_FRAMES)
```

という**位相**が常に成り立つ。「フレーム番号 f の中身は `s_ring[f & 4095]` にある」という、
読み出しカーソル・フェードのゲイン・PCM8 のミックスリングが共通で頼っている前提は、
この位相そのものである。

**張り直すときも差分は必ず積む。** 基準点だけを現在位置へ寄せると、止まっていた分だけ
位相がずれる。位相がずれても音は連続したままなので気づかないが、以後フレーム番号が指すのは
その分だけ**古い音**になり、ずれは停止のたびに積み上がる。実害は次のとおり。

- **フェードの解除境界が過去に落ちる。** `ym3012_fade_release()` は「いま取り込んでいる
  フレーム」に境界を置くが、位相が E ずれていると実際に解除されるのは E フレーム前から。
  autoplay のフェードアウト直後に、キーオフ前の全音量の音楽が最大 65.5ms 出る
- **I2S の先行量が嘘になる。** `i2s_resync()` の直後に `s_fill_total = s_dma_total` する
  ので、真の先行量が `(I2S_TARGET_FRAMES - 止まっていた分) mod 4096` になる。`depth` は
  満量を報告し続けるので `depth <= 0` のアンダーラン復帰も発火しない
- **overrun 検出が手遅れになる。** 真の上書きは `unread >= 4096 - E` で始まるのに、
  判定は `unread >= 4096` のまま

一周 65.5ms を超えて止まると、進んだ分が一周単位で切り捨てられて総フレーム数
（`s` の `FRAMES` / `RATE`）が少なく出る。**それは統計だけの誤差で、位相はどれだけ
止まっても必ず合う。** フラッシュの書き出しは 1 セクタごとに張り直すので、実測でも
1 回あたり 42ms 止まりで一周には届かない。

対策は 2 段構えにしてある。

1. **HOST モード中は音声経路を止める。** `i2s_set_enabled(false)` で I2S はソースを
   読まず無音だけを詰める。リング全体が無音なので、停止中に DMA が古い内容を再生しても
   出てくるのは無音。BCK / LRCK と DMA は止めない（止めると PCM5102A がポップし、
   [i2s.h](../src/i2s.h) の「I2S 出力は常時動作し停止しない」前提も崩れる）
2. **`capture_resync_after_blackout()` で基準点を張り直す。** 呼ぶのは 3 か所で、
   `flash_disk_flush_one()` の中（`storage format` は PLAYER モードで走るため必要）、
   `storage player` への遷移時、そして `buttonmap_boot_apply()` の末尾
   （[§13.6](#136-起動シーケンス)）

**張り直しは 3 本を 1 本にまとめてある**（[§1.2](#12-主要-api)）。`ym3012_ring_resync()` /
`i2s_resync()` / `pcm8_resync()` を個別に呼ばないのは、消費者が増えたときに呼び忘れが
起きないようにするため。`i2s_resync()` が**自分の ym3012 カーソルも同期する**のが肝で、
既存のアンダーラン復帰路ではやっているが停止経路はそこを通らない。前 2 者は
`ym3012_ring_poll()` / `i2s_poll()` を呼んでから復帰処理に入る形にしてあり、
位相を保つ責任は poll の 1 か所に閉じている。

検証は `s` を見る。**フラッシュの書き出し回数 (`FLASH WRITE`) と `I2S UNDERRUN` が
ほぼ同数**になり、復帰後に `RATE` が φM/64 ちょうどへ戻れば正しく繋がっている。
`UNDERRUN` が 0 のままなら resync が効いておらず、静かに壊れている。

**位相までは `s` からは見えない。** 崩れていても `RING` は空いて見え、`OVERRUN` も
増えないので、確かめるには音で測る。長い無音を作ってから `p 1` を打ち、その直後に
キーオンして、キャプチャの先頭からトーンが始まるまでのフレーム数を数える。
`capture_start()` は `ym3012_ring_poll()` と `ym3012_ring_sync()` を通るので、位相が
合っていればコマンドの往復ぶん（1ms 未満）に収まる。ここが数千フレームなら崩れている。

### 9.4 `.vgz` のストリーム展開

gzip 圧縮された VGM を、一時ファイルを作らずに展開しながら再生する。層の構成は次のとおり。

```
  vgm.c        ヘッダ解析・コマンド解釈・スケジューラ（圧縮の有無を知らない）
    |          s_buf[4096] の補充だけが分岐する
  vgz.c        gzip ヘッダ / トレーラの解析、出力リング、スナップショット
    |          VGM の知識は持たない
  miniz tinfl  DEFLATE の展開（external/miniz）
    |
  FatFs (FIL)  圧縮されたままのバイト列を読む
```

`vgm_getc()` 以降のコマンド解釈は非圧縮と共通で、`s_buf` も同じものを使う。
違うのは補充が `f_read()` か `vgz_read()` かだけ。

**圧縮の判定は拡張子ではなくファイル先頭のマジック（`1F 8B`）で行う。** 中身が gzip の
`.vgm` も、`.vgm` そのままの `.vgz` も世の中にあるため。`vgm list` の絞り込み
（[filelist.c](../src/filelist.c) の `has_ext()` と [vgm.c](../src/vgm.c) の `VGM_EXTS[]`）は
拡張子で拾うが、それは一覧に何を出すかの話であって展開するかどうかとは独立している。

**出力リングが DEFLATE の履歴窓を兼ねる。** `tinfl` は出力バッファをリングとして扱い、
窓のマスクを

```c
mask = (pOut_buf_next - pOut_buf_start) + *pOut_buf_size - 1;
```

から作って、これが 2 の冪 -1 でないと弾く。**つまり「毎回リングの末尾まで埋めさせる」
呼び方しかできず、1 回の出力バイト数を選べない。** DEFLATE の距離は最大 32768 なので、
リングを 32KiB (`VGZ_DICT_SIZE`) にすればそれがそのまま履歴窓になり、別に窓を持つ必要も
無くなる。

出力長を選べない代わりに、**1 回の `tinfl_decompress()` の仕事量は入力量で抑える**。
`VGZ_IN_CHUNK`（256 バイト）だけ渡すと、通常の圧縮率（3〜10 倍）で 1〜3KiB の展開に
相当する。圧縮率が極端に高い箇所では 1 回でリング末尾まで（最大 32KiB）展開しうるが、
それでも数 ms で、I2S のリングが 65.5ms あるので破綻しない（[§5.3](#53-出力リングと先行量の維持)）。
圧縮率 72 倍のファイルを実機で再生したときの `SEQ LAG` の最大値は 11ms、
`I2S UNDERRUN` は 0 だった。

`vgm.c` 側の補充単位も非圧縮とは別にしてある。`VGM_GZ_CHUNK` は 1024 バイトで、
展開が 1 バイトあたり十数サイクルかかるため `s_buf` 全体（4096 バイト）を一度に埋めると
`VGM_BUDGET_US`（500µs）を割ってしまう（[§9.2](#92-スケジューラ)）。

**ループの戻り方が、実装で最も注意を要する点。** gzip は後方シークできないので、
素直に作ると 2 周目の頭出しのたびに先頭から展開し直すことになり、継ぎ目で音が
数百 ms 途切れる。

そうならないよう、**ループ先頭 (`s_loop_target`) をはじめて通過する瞬間に展開器の状態を
丸ごと保存する**。保存するのは次の 5 つ。

| 保存するもの | 大きさ |
| --- | --- |
| `tinfl_decompressor`（ビットバッファ・ハフマン表・状態） | 約 8KiB |
| 32KiB の出力リングとその書き込み位置 | 32KiB |
| 消費済みの圧縮オフセット（ファイル内位置） | - |
| 展開後の位置と、未消費の展開データの位置・長さ | - |
| `vgm.c` 側の `s_buf` とその位置（`vgz` 側は `s_buf` に先読みしたぶん先を指しているため） | 4KiB |

2 周目以降は `memcpy` と `f_lseek()` で戻すだけなので、**継ぎ目に停止は出ない**
（非圧縮の `.vgm` と同じ）。これが成り立つのは `tinfl_decompressor` が**ポインタを含まない
POD** で、出力リングを呼び出しごとに引数で渡す造りだからで、miniz を更新するときは
この前提を確認する（[external/README.md](../external/README.md)）。

保存できないままループ先頭を過ぎてしまった場合の保険として `vgz_rewind()` があり、
先頭から展開し直す。この経路を通った回数は `s` の `gz reload` に出す
（[README §3.11](../README.md#311-s統計)）。**0 でなければループのたびに音が途切れている。**

**前方への読み飛ばしは展開して捨てるしかない。** `0x67` のデータブロックを gzip の
途中から飛ばすことはできないため。データブロックは MB 単位になりうるので、
1 回のサービスで消化しきると I2S が飢える。

`vgm_skip()` は残りバイト数を `s_skip_left` に積むだけにして、`vgm_step()` の頭で
`VGM_GZ_CHUNK`（1024 バイト）ずつ消化する。`vgm_service()` の 500µs 予算ループに
そのまま乗るので、読み飛ばしのあいだもキャプチャと I2S へのサービスが挟まる。
ここで生じた遅れは `VGM_RESYNC_LAG_US`（200ms）による時計の張り直しが吸収する
（[§9.2](#92-スケジューラ)）。256KiB のデータブロックを含む `.vgz` を実機で再生したときの
`SEQ LAG` の最大値は 20ms、`I2S UNDERRUN` は 0 だった。

**gzip トレーラの CRC32 は検証しない。** 読むのは ISIZE（展開後サイズ）だけで、
`vgm_size()` が `f_size()` の代わりに使う。**ループ再生では終端に到達しないことが普通**で、
全部展開しないと計算できない CRC を待っても壊れたファイルの検出は早まらないため。
壊れていれば `tinfl` の展開エラーか、VGM 側の未知オペコード
（[§9.1](#91-コマンドの解釈)）として必ず捕まる。

`VGM_VGZ_ENABLED=0` にすると [vgz.c](../src/vgz.c) は「常に失敗する」スタブだけになり、
展開器も約 84KiB のバッファもリンクされない（[§7](#7-ビルド構成)）。
`vgm_play()` は gzip のファイルを `bad file` で拒否し、理由を `# hint` 行で出す。

## 10. MDX 再生

VGM が「レジスタ書き込みのタイムスタンプ付きダンプ」なのに対し、MDX は
**チャンネルごとに独立したシーケンサ**を持つバイナリ MML なので、音色・音量・ピッチ・
LFO をこちらで解釈してはじめて YM2151 のレジスタ値になる。つまり [mdx.c](../src/mdx.c) は
MXDRV 相当の音源ドライバそのもの。

利用者から見た仕様は [README §9](../README.md#9-mdx-再生)。

### 10.1 参照実装への準拠

レジスタへの書き込み内容と順序は **MXDRV 2.06+17 Rel.X5-S / MXDRVg V2.00b** に
合わせてある（一部の機能だけ **MXDRV 2.06+16 Rel.3+25**。[README §12](../README.md#12-ライセンス)）。
[mdx.c](../src/mdx.c) の冒頭に、参照実装のチャンネルワーク `MXWORK_CH` のオフセット
（`S0000`〜`S004e`）と `mdx_ch_t` のフィールドの対応表を置いてある。整数の幅も
参照実装に合わせ（符号なしで持ち、必要なところだけ符号付きへキャストする）、
68000 での桁溢れの仕方まで同じ結果になるようにしている。

**MXDRV のソースはリポジトリに含めない。** `mdx.c` は独自に書き起こしたもの
（[README §12](../README.md#12-ライセンス)）。

相違点は 2 つ。

**BUSY 待ちをしない。** MXDRV は書き込みのたびに OPM のステータスを読んで bit7 が
下りるのを待つが、本機は `opm_write()` の固定ウェイト（合計約 32µs、
[§3.1](#31-タイミング定数)）で代える。ステータス自体は `opm_read()` で読めるが、
書き込み経路では見ない（[§3](#3-opm-バスシーケンス)）。X68000 実機より遅い方向にしか
ならない。

**余韻が消えない曲を 5 秒で打ち切る。** 消音のタイミングそのものは参照実装と同じで、
`$E0`-`$FF` へ `0x0F` を撒いてから `$08` へ ch0-7 のキーオフを撃つ `L00063e` 相当
（本機の `opm_key_off_all()`）が走るのは **STOP と次の PLAY の先頭だけ**。演奏終了
（`L001442`。全チャンネルが `0xF1 0x00` に達した時点）では END_FLG を落として PCM8 を
止めるだけで OPM を触らないので、最後の音は音色本来の RR で自然に減衰する。
参照実装はその音を止める手立てを持たないが、本機は RR=0 の音色が残った場合に備えて
5 秒で強制消音する（[§11.2](#112-余韻の判定)）。

参照実装が持つ 256 バイトのレジスタシャドウはそのまま持っている。レジスタ `0x1B` は
上位 2bit が CT1/CT2 出力で、LFO 波形を書くときに読み出して混ぜる必要があるため。

### 10.2 データ構造とローダ

ファイルは **丸ごと RAM に載せる**（`MDX_MAX_BYTES` = 64KiB）。VGM の 4096 バイト
前方ストリームは使えない。チャンネルごとに独立したポインタがリピートやループで前後し、
さらに `0xF6`（リピート開始）が**データ自身を書き換えて**回数カウンタに使うため。

ヘッダの構造は次のとおりで、オフセットとワードはすべてビッグエンディアン（68000）。

```
タイトル (Shift_JIS)  0x0D 0x0A 0x1A で終端
PDX ファイル名        0x00 で終端
base: +0      Word      音色データのオフセット（base 相対）
      +2      Word × N  各チャンネルの MML のオフセット（base 相対）
```

チャンネル数 `N` は表そのものの大きさから求める。表は base から `2 + 2N` バイトなので
`N = (先頭チャンネルのオフセット - 2) / 2` で、9（FM 8 + ADPCM 1）か
16（FM 8 + ADPCM 8。PCM8 拡張）になる。それ以外なら `bad file`。

音色は 27 バイト固定長レコードの並びで、先頭バイトが音色番号。番号 → 位置の索引を
256 エントリ作る。参照実装は再生のたびに線形探索して**最初の一致**を採るので、
索引も最初の一致を残す。

### 10.3 tick スケジューラ

テンポは OPM の Timer-B 由来で、1 clock は `1024 × (256 - @t)` φM サイクル。
**φM サイクル数でちょうど整数になる**ので誤差なく時刻へ直せる。

```c
s_due_q += ((uint64_t)period_cycles * 65536ull * 1000000ull) / phim_hz;
s_due_us = s_due_q >> 16;
```

`s_due_q` は 1/65536µs 単位の累算器。`period_cycles` は最大 262144 なので、除算前でも
u64 に収まる。丸めは 1 tick あたり 15ps 未満で、1 時間で 4µs 程度。テンポ変更にも
`clock` による φM の切り替えにも自然に追従する。

**1 tick は途中で中断して次の周回へ持ち越せる。** 音色の展開は 1 チャンネルあたり
25 レジスタ（約 800µs）で、複数チャンネルで同じ tick に重なると 1 tick で 180 回を
超える。`MDX_BUDGET_US`（500µs）で抜けて次の周回から続きを処理し、**全チャンネルの
処理が終わるまで tick は進めない**ので、演奏が先へ流れることはない。中断位置は
`s_cursor` と `s_in_tick` が持つ。

この予算の理由は `VGM_BUDGET_US` と同じで、メインループが 1 周回で標準入力を
1 文字しか読まないため（[vgm.h](../src/vgm.h) の説明）。

`MDX_RESYNC_LAG_US`（200ms）を超えて遅れたら、早送りせず時計を張り直す。

### 10.4 チャンネル状態機械

1 tick で各チャンネルに対して次の 3 つをこの順に呼ぶ（参照実装の割り込みハンドラと
同じ並び）。

1. **`ch_pre()`** — ポルタメントの積分と LFO を 1 clock 進める
2. **`ch_len()`** — ゲートタイムを減らして 0 ならキーオフ、音長を減らして 0 なら
   次の音符・休符まで MML を読む（`ch_fetch()`）。同期待ち中はここで止まる
3. **`ch_post()`** — 音色の展開・パン・音程・音量をレジスタへ反映し、キーオンする

**音色の書き込みはキーオンまで遅延する。** `0xFD`（`@`）は音色レコードの位置を控えて
フラグを立てるだけで、レジスタは書かない。参照実装と同じ挙動で、書き込みバーストの
分布が変わるとタイミングの詰まり方も変わるため合わせてある。

`0xF1 0x00`（演奏終了）に当たったチャンネルは、参照実装が静的な `{0x7f, 0xf1, 0x00}` へ
ポインタを向け直すのと同じ効果を、**いま読んだ `0xF1` の位置へ戻す**ことで作る。
こうしないとその先にある別チャンネルの MML や音色データを読んでしまう。
全チャンネルが終了したら再生を止める。

### 10.5 音程と音量の変換

内部の音程は **1/64 半音**単位。MDX の音符 0-95 は `音符 × 64 + 5` が基準で、`+5` は
MXDRV の調律ぶん。ここへディチューン・ポルタメント・音程 LFO を足し、
`pitch_to_kc_kf()` が 0x17FF で頭打ちにしてから 4 倍し、上位バイトを KC（`0x28+ch`）、
下位バイトを KF（`0x30+ch`）にする。KC の下位 4bit は 3 / 7 / 11 / 15 を飛ばすので
96 エントリの表で引く。MDX の音符 0 は `o0 d+` で OPM の KC 0 とちょうど一致する。

音量は `v0`-`v15`（16 段の表で TL へ）と `@v`（TL 直接）の 2 系統で、値の bit7 で
区別する。TL を足すのは**キャリアのスロットだけ**で、どれがキャリアかは音色の CON から
引く（`{0x08,0x08,0x08,0x08,0x0c,0x0e,0x0e,0x0f}`）。オペレータのレジスタは
`ベース + スロット × 8 + チャネル` で並びは M1 / M2 / C1 / C2、これは MDX の音色 27 バイトの
並びと同じなので並べ替えは要らない（[test/noise_period/](../test/noise_period/README.md)
で実測済み）。

この 2 つの変換は `t` コマンドが既知のベクタで検証する
（[README §3.12](../README.md#312-t自己テスト)）。

### 10.6 出力バックエンド

音を出す操作は `snd_voice()` / `snd_pan()` / `snd_volume()` / `snd_pitch()` /
`snd_key_on()` / `snd_key_off()` の 6 本に集約してある。**FM と ADPCM の分岐は
この 6 本の中だけ**にあり、`if (ch < 8)` を処理のあちこちに撒かなくて済む。

FM チャンネルは 6 本すべてが OPM のレジスタを書く。ADPCM チャンネルは
`snd_key_on()` / `snd_key_off()` だけが働き、[pcm8.c](../src/pcm8.c) を呼ぶ。
音色・パン・TL・KC/KF はレジスタに対応するものが無いので何もしない
（PCM8 は発音のたびに音量・レート・定位を引数で渡す方式で、レジスタ相当の
遅延書き込みが要らない）。

**ADPCM チャンネルもシーケンサとしては FM と同じように回す。** 同期コマンド
（`0xEF` / `0xEE`）が ADPCM 側から FM 側へ飛んでくる曲があり、止めると FM が
永久に待つため。チャンネルの内訳は参照実装と同じく 16 = FM 8 + ADPCM 1 + PCM8 拡張 7 で、
9-15ch は `0xE8`（PCM8 モード宣言）が実行されてから回り始める。

`0xE8` が変えるのはチャンネル数だけではない。**ADPCM の制御そのものが切り替わる**
（[§10.7](#107-adpcm-pcm8-の再生) の「PCM8 モードと IOCS 経路」）。

### 10.7 ADPCM (PCM8) の再生

X68000 の ADPCM は MSM6258 という別のチップで、本機には載っていない。
[pcm8.c](../src/pcm8.c) が **PCM8（江藤啓氏の ADPCM 多重再生ドライバ）相当の 8ch** を
ソフトウェアでデコードし、YM3012 から取り込んだ FM の PCM に足す。
利用者から見た仕様は [README §9.7](../README.md#97-adpcm-pcm8-の再生)。

```
  PDX（FatFs / 内蔵フラッシュ）
        │  チャンネルごとに 1KB ずつ先読み
        ▼
   ADPCM デコード（MSM6258）→ 音量 → hold 回そのまま繰り返す
        │
        ▼
   8ch を int32 で加算 → 1 回だけ飽和 → 16KB ミックスリング（フレーム番号で引く）
        │
        ▼
   ym3012_reader_read_pcm() の中で FM に加算 → 1 回だけ飽和
        │                                      │
        ▼                                      ▼
   USB キャプチャ (CDC #1)                  I2S 出力
```

#### PCM8 の呼び出し方

参照実装は `TRAP #2` で PCM8 を叩く。[pcm8.h](../src/pcm8.h) の API はその機能コードと
1 対 1 に対応させてある（`pcm8_key_on()` = `$000x`、`pcm8_set_mode()` = `$007x`、
`pcm8_stop()` = `$000x` でデータ長 0、`pcm8_abort_all()` = `$0101`）。

- **キーオンは 2 回発行する。** 参照実装はまずデータ長 0 で当該チャネルを止め、
  次に長さを付けて鳴らす。`snd_key_on()` もそのまま `pcm8_stop()` → `pcm8_key_on()` と呼ぶ。
- **音量**は FM と同じ `v` / `@v` の値から TL 相当（0-42）を作り、43 段の表で
  PCM8 の音量 0-15 に落とす。フェードアウトのオフセットもここに 8bit で足すので、
  溢れたら音量 0 かつ定位 0（= そのチャネルは鳴らない）になる。
  参照実装と同じく **フェードアウトはキーオン時にしか効かない**。IOCS 経路では
  音量そのものが指定できないので、代わりに `PCM_CUT` が定位を 0 にする。
- **定位は全チャネル共通**（PCM8 の仕様）。0 以外で最後に指定された値が残る。
  MML の `p` は `0xFC` の側で 0 と 3 を入れ替えて格納し、キーオン時にもう一度
  入れ替えるので元に戻る。初期値 0 はキーオン時に 3（左右）になる。
- **`v` / `@v` はタイでつながっている間だけ**、発音中の音量を `$007x` で差し替える
  （参照実装の `PCM_Vol`）。判定に使う「直前の音がタイだったか」は `ch_len()` の
  入口でチャンネルのレガート指定を写して持つ。周波数と定位は `-1`（据え置き）で
  渡すので、音量が範囲を外れても停止はせず音量 0 になるだけ。PCM8 モードでない曲では
  発行しない。
- **`0xE7 0x02`（PCM8 へのコマンド）** は 6 バイトが `d0.w` + `d1.l` の
  ビッグエンディアン。`$0100`（終了）・`$0101`（一時停止 = 即時打ち切り）・
  `$007x`（動作モード変更）を解釈し、本機に効く設定が無いもの（`$01FC` など）は無視する。

#### PCM8 モードと IOCS 経路

参照実装が PCM8 を叩くのは **`0xE8`（PCM8 モード宣言）が実行された曲だけ**。
`0xE8` が無い曲の ADPCM は IOCS `_ADPCMOUT` / `_ADPCMMOD` へ流れる。IOCS には
音量もバンクも無いので、**同じ PDX を使っても鳴り方が違う**。

| | PCM8 モード（`0xE8` あり） | IOCS 経路（`0xE8` なし） |
| --- | --- | --- |
| 発音チャンネル | 8（9-15ch） | 1（8ch のみ） |
| 音量 `v` / `@v` | 効く（0-15 に落とす） | **効かない**（原音量 8 固定） |
| フェードアウト | 音量に足す | **音量には効かない**。`PCM_CUT`（`FADE_ADD` >= 10）で定位 0 = 無音 |
| バンク `@n` | 効く（`bank × 96 + 音符`） | **効かない**（常にバンク 0） |
| PDX の長さ | 32bit を読んで 24bit へ切る | **下位 16bit だけ** |
| タイ中の音量差し替え | `$007x` を出す | 出さない |
| `0xE7 0x02`（PCM8 コマンド） | 実行する | 6 バイト読み飛ばす |
| キーオフ | データ長 0 のチャネル停止 | `_ADPCMMOD` の中止 + 終了 |
| `0xE7 0x06` | 効かない | 中止を抑止して鳴らし切る |

周波数（`0xED`）と定位（`p`）はどちらの経路でも同じ値を渡す。

[pcm8.h](../src/pcm8.h) では IOCS 経路を `pcm8_iocs_out()` / `pcm8_iocs_mod()` として
別の入口に分けてある（参照実装でも呼ぶベクタが違う）。MSM6258 は実機に 1 個しか
無いので `pcm8_iocs_out()` は ch0 固定。

#### PDX の読み出し

PDX は先頭が **96 音 × 8 バイト（BE の offset と length）のエントリ表**で、
`@n`（`0xFD`）が選ぶバンクを合わせると `(bank × 96 + 音符) × 8` で引ける。長さは
参照実装と同じく 24bit で切る。offset はファイル先頭からの絶対位置。
IOCS 経路ではバンクが効かず（常に 0）、長さも下位 16bit しか見ない。

**PDX は丸ごと RAM に載せない。** 数百 KB あって MDX 本体（64KiB）のようには
扱えないので、`FIL` を 1 本開いたまま `f_lseek` + `f_read` でストリーミングする。
チャンネルごとに 1KB の先読みバッファを持ち、使い切ったら次を読む
（15.6kHz でも 1KB は 131ms 分なので、補充は毎秒数回で済む）。エントリ表は
1 バンクぶん（768 バイト）だけキャッシュし、バンクが変わったときに読み直す。
裏はすべて内蔵フラッシュの XIP なので、1 回の読み出しは数 µs で終わる。

ファイル名は MDX ヘッダの PDX 名に `.PDX` を付けたもの。`pdx_path()` がこれを
**再生中の MDX と同じディレクトリ**と **`MDX_DIR` 直下**の 2 通りに組み立て、
`open_pdx()` がその順に開いてみる。曲ごとのフォルダへ PDX を同梱する置き方と、
共通の PDX を直下へまとめる置き方のどちらでも鳴る。`MDX_DIR` 直下の曲では 2 通が
同じパスになるので 1 回しか試さない。

ディレクトリ部は再生中の曲の相対パス（`s_name`）の最後の `/` までをそのまま使う。
ヘッダの PDX 名の側は**ファイルの中身なので信用せず**、ディレクトリ区切りと制御文字を
弾く（曲は `/MDX` の外を指せない）。FatFs の LFN 照合は大小を無視するので、実体が
小文字（`bos.pdx`）でも当たる。

#### デコードとレート変換

MSM6258 の ADPCM は 1 ニブル 4bit で、**下位ニブルが先**。

```
delta = step/8 + step/4·b0 + step/2·b1 + step·b2   （符号は b3）
出力  = clamp(出力 + delta, -2048, 2047)            （12bit）
段番号 = clamp(段番号 + {-1,-1,-1,-1,2,4,6,8}[n & 7], 0, 48)
```

12bit の結果を 4bit 左シフトして 16bit フルスケールにする。これは PCM8 の
16bit PCM 形式と同じレベルで、仕様の「8bit PCM の D/A 変換レベルは 16bit PCM と同一」
とも一致する。16bit PCM 形式（mode 5）は BE の signed short をそのまま、
8bit PCM 形式（mode 6）は signed char を 8bit 左シフトする。

**レート変換に補間は要らない。** X68000 では ADPCM のクロックも OPM のクロックも
同じ発振器から作られる。本機でも同じ関係を保ち、ADPCM のレートを φM の分周として
定義すると、出力の φM/64 との比は φM の値によらず必ず整数になる。

| mode | レート | φM との関係 | 出力フレーム/サンプル |
| --- | --- | --- | --- |
| 0 | 3.90625 kHz | φM/1024 | 16 |
| 1 | 5.20833 kHz | φM/768 | 12 |
| 2 | 7.8125 kHz | φM/512 | 8 |
| 3 | 10.41667 kHz | φM/384 | 6 |
| 4 | 15.625 kHz | φM/256 | 4 |
| 5 (16bit PCM) | 15.625 kHz | φM/256 | 4 |
| 6 (8bit PCM) | 15.625 kHz | φM/256 | 4 |

`mdx_play()` は φM を X68000 と同じ 4MHz へ寄せる（[§2.3](#23-実行時の切り替え)）ので、
実レートも実機と一致する。φM がそれ以外でも比は整数のままで、音程もテンポも ADPCM も
一緒にずれる（`mdx_play()` がその旨を出す）。

したがってソースサンプルをそのまま整数回繰り返すだけでよく、位相の小数部も除算も
要らない。これは MSM6258 の出力（階段波）そのものでもある。

#### ミックスリングと 2 本のカーソル

キャプチャの読み出しカーソルは USB と I2S で独立していて、位置も 1 回に読む長さも違う
（[§5](#5-i2s-出力)）。そこで ADPCM 側は **フレーム番号で引ける 16KB のリング**に
描いておき、読み出しでは消費しない。`ym3012_reader_read_pcm()` が渡してくる
`rd->read_total` は消費者によらない絶対フレーム番号なので、どちらのカーソルから
何フレーム単位で呼ばれても同じ結果を返せる（= 冪等）。リングの長さをキャプチャ側と
同じ 4096 フレームにしてあるのは、カーソルが書き込み位置から最大でも
リング 1 周ぶんしか離れないため。

加算は `ym3012_reader_read_pcm()` の変換直後の 1 箇所だけで行う
（[ym3012.c](../src/ym3012.c) の `ym3012_mixer_t` フック）。ここが USB キャプチャと
I2S の唯一の合流点なので、1 箇所で両方に効く。禁止コード E=0 の計数は混ぜる前に
済ませてあるので、統計は「取り込んだ信号の品質」のまま変わらない。

**飽和は 1 回だけ。** 8ch を int32 で足してからリングへ入れるときに 1 回、
FM に足すときにもう 1 回。チャンネルごとに 16bit へ飽和させると歪む。
ADPCM のフルスケールと FM のフルスケールを同じ重みで足すので、実機のアナログ
ミックスと同じく両方が大きいときは歪む。その回数は `s` の `CLIP` で見える。

#### まとめて描く理由

メインループは 20 万周/秒ほど回るのに対し、出力は 62500 フレーム/秒しかない。
毎周回描くと 1 周あたり 1 フレーム未満のためにブロックの支度をすることになり、
固定費だけで CPU の 2 割近くを使う。そこで **発音中は 64 フレーム（約 1ms）
溜めてから描く**（`PCM8_BATCH_FRAMES`）。

まとめている途中のフレームを消費者が先に持って行くと、その分だけ混ぜ損ねて
ADPCM が途切れる。これを防ぐため `ym3012_set_mix_ready()` で
「描き終えたフレーム番号」を伝え、カーソルはそこを超えて読まない。I2S は
1024 フレームの先行を持っている（[§5.3](#53-出力リングと先行量の維持)）ので、
64 フレーム待たせても余裕には響かない。

無音のときは束ねない。リング全体がすでに 0 なので、書き直さずに位置だけ進める。

#### 束ねても発音の時刻は動かない

`pcm8_service()` が描くのは `[s_rendered_total, ym3012_write_total())` という
**「今」より過去に向かう**区間で、レンダリング前線 `s_rendered_total` は束ねと
音声チェーンの間引き（`AUDIO_SERVICE_INTERVAL_US` = 500µs、[§1.1](#11-メインループ)）の
ぶんだけ「今」より後ろにある。ここへそのままキーオンを描き込むと、**その音は過去の
フレーム番号から鳴り始める**。FM は `opm_write()` した瞬間の音がその瞬間のフレーム番号に
入る（[§4.4](#44-dma-リング)）ので、ADPCM だけが早く出ることになる。

そこで **発音状態を変える前に、その瞬間のフレーム番号まで描き切る。**
[pcm8.c](../src/pcm8.c) の `flush_now()` がこれを行い、`pcm8_key_on()` / `pcm8_stop()` /
`pcm8_set_mode()` / `pcm8_abort_all()` / `pcm8_iocs_out()` / `pcm8_iocs_mod()` /
`pcm8_set_enabled()` の入口から呼ばれる（`pcm8_close_pdx()` は `pcm8_abort_all()` 経由）。
描く総量は変わらないので、費用は `pcm8_service()` から `mdx_service()` へ移るだけ。

**`ym3012_ring_poll()` をその場で呼ぶのが肝。** 呼ばないと `ym3012_write_total()` は
直前の音声チェーン（最大 500µs 前）の値のままで、間引きぶんの 31 フレームが残る。
差分を積むだけの関数なので何度呼んでも安全（[§4.4](#44-dma-リング)）。

**束ねそのものは撤去していない。** 発音状態が変わらない区間では時刻の誤差を生まないので、
CPU の固定費を下げる効果だけが残る。

これを入れる前は ADPCM が FM より **実曲で最大 2.0ms 早く**、しかも 1 音ごとに揺らいでいた。
入れたあとの残りは 1〜2 フレーム（16〜32µs）で、その中身はキャプチャ経路の 1 フレームと、
tick 内で FM のキーオンが先に発行される分。測定と内訳は
[test/pcm8_sync/](../test/pcm8_sync/README.md)。

#### 鳴っているかを聴かずに確かめる

ADPCM が曲の終盤にしか出てこないことがある（`DS19P.MDX` は 12 秒の曲で ADPCM の
発音が 2 回だけ、しかも 6.5 秒過ぎから）。「聞こえない」だけでは曲の側の話か
ファームの側の話か分からないので、`mdx pcm` に発音を開始した回数（`keyon`）と
鳴らせなかった回数（`miss`）を出している。`keyon` が 0 のままなら曲がまだ
鳴らそうとしていない、`miss` が増えていれば PDX にその波形が無い（または音量 0）。

`mdx pcm off` は電源を切るまで残るので、off のまま PDX を要求する曲を再生したときは
`mdx play` が理由を出す。

#### 長時間止まったとき

フラッシュの消去などでメインループがリング 1 周（65.5ms）を超えて止まると、
描いても誰も読まない領域を延々と埋めることになる。遅れがリング 1 周を超えたら
リングを無音で埋めて位置を張り直す。なお通常の復帰では
`capture_resync_after_blackout()` が `pcm8_resync()` まで呼ぶので、この保険には
入らない（[§9.3](#93-書き込み中の停止とリング位置)）。

### 10.8 既存機能との共存

VGM と MDX は相互排他で、同時には鳴らせない。排他は中央のアービタではなく
`vgm_play()` / `mdx_play()` が直接相手を止めることで作る。どちらも、自分と相手のうち
`STOPPED` でない方を `vgm_stop()` / `mdx_stop()` で止めてからファイルを開く。

**止めるのを先にするのは、新しい曲の読み込み先が再生中の曲のデータそのものだから。**
MDX は `s_file`（64KB）が 1 面しかなく、VGM もストリーム用の `FIL` が 1 個しかない。
新旧を並べて持てない以上、読み込みに失敗しても前の曲へは戻せないので、そのまま停止状態で
エラーを返す仕様にしてある。ファイル名の書式検査だけは副作用が無いので停止より前に置き、
`bad argument` では前の曲を止めない。

`MDX_ENABLED=0` のスタブは `mdx_stop()` が hint と `unsupported` を返すので、`vgm.c` からは
`mdx_state() != MDX_STATE_STOPPED` で囲って呼ぶ（スタブの `mdx_state()` は常に
`MDX_STATE_STOPPED` なので、無効ビルドでは呼ばれない）。`mdx.c` から `vgm_stop()` を呼ぶ側は
VGM に無効化ビルドが無いので囲わない。

`ERROR` も止める対象に入れて `STOPPED` へ正規化する。`mdx_service()` は `mdx_fail()` で
`ERROR` に落ちた時点で `vgm_service()` と対称にキーオフと `pcm8_close_pdx()` を行うので、
`ERROR` のまま放置しても PDX が開いたままにはならない。

遅れの統計は `stats_seq_lag_*` を 2 つで共用する（同時に走らないので 1 個で足りる）。
曲を切り替えても 0 には戻らないので、曲ごとに見るなら `s 0`。

[§9.3](#93-書き込み中の停止とリング位置) の「書き込み中の停止とリング位置」の制約は
MDX にもそのまま掛かる。MDX はファイルを丸ごと RAM に載せているのでアンマウントされても
読めるが、**PDX は再生中もファイルを開いたまま読み続ける**（[§10.7](#107-adpcm-pcm8-の再生)）。
どちらにせよフラッシュの消去中は数十 ms 止まるので `storage host` は再生中拒否する。
`mdx stop` と曲の終わりで PDX は閉じる。

## 11. 曲の終わり方 (songend)

[songend.c](../src/songend.c) は「曲の一生」を 1 本の状態機械で持つ。ループ回数で打ち切るか、
自然に終わるまで待つか、終わったあとの余韻をどこまで待つか — **その仕様も処理もここに
しかない。** 利用者側の仕様は [README §3.22](../README.md#322-曲の終わり方)。

**外に出す観測は実質 `songend_is_active()` の 1 つ。** 自動連続再生の曲送り
（[§12](#12-自動連続再生-autoplay)）も、演奏に連動したキャプチャ（[§4.7](#47-演奏に連動したキャプチャ-p-2)）も
これを見る。両者が必ず同じ時刻で動くのはこのため。

### 11.1 状態機械

```
            play                 loop 上限          fade 期限
  IDLE ───────────> PLAYING ─────────────────> FADING ─────────┐
   ▲                  │                                        │
   │                  │ 自然終了 / stop / ERROR                 │ stop_players()
   │                  ▼                                        ▼
   └───── 無音 ──── RINGOUT <───────────────────────────────────┘
                      │
                  play（曲送り / 次の曲）──> PLAYING
```

`songend_service()` は [§1.1](#11-メインループ) のシーケンサ群の**後ろ**、
`autoplay_service()` の**前**で回す。同じ周回で更新された `vgm_state()` / `mdx_state()` を
見て出した結論を、autoplay がそのまま曲送りに使える。

| 状態 | 抜ける条件 | 次 |
| --- | --- | --- |
| どれでも | `songend_track_seq()` が変わった | `PLAYING`（新しいトラック） |
| `PLAYING` | 再生系が `PLAYING` でなくなった（終端 / `ERROR` / `stop`） | `RINGOUT` |
| `PLAYING` | `loop != 0` かつループカウンタが `loop` に達した | `FADING`（`fade == 0` なら止めて `RINGOUT`） |
| `FADING` | フェードの期限が来た、または曲が先に終わった | 止めて `RINGOUT` |
| `RINGOUT` | 出力が `SONGEND_RINGOUT_QUIET_MS` のあいだ無音だった | `IDLE` |

**新しいトラックの検出はレベルではなく通し番号で行う。** 鳴っている最中に別の曲を
`play` しても `vgm_is_playing()` は落ちないので、「曲が変わった」をレベルからは拾えない。
`vgm_play_seq()` / `mdx_play_seq()` は `*_play()` が成功するたびに増える通し番号で、
その和が `songend_track_seq()`。`autoplay next` が余韻を待たずに切り替わるのも、
`songend_stop_playback()` の直後に `start_track()` が番号を進めて `PLAYING` へ引き戻すため。

**終わりの検出はポーリングしかできない。** 再生系にコールバックの口は無く、終了は
`vgm_service()` / `mdx_service()` が状態を落として 1 行出すだけ。

**ループ上限は 2 系統ある。** `songend_set_loop()` が持つのは手動再生用の設定
（既定 0 = 無限）で、autoplay はトラックを始めるたびに `songend_arm()` で自分の値
（既定 2）を差し込む。既定値の意味が違うので統合できない。`songend_arm()` は
通し番号もそこで latch するので、後から `songend_service()` が設定値で上書きし直す
ことはない。

### 11.2 余韻の判定

曲データが尽きたとき、[vgm.c](../src/vgm.c) / [mdx.c](../src/mdx.c) は **OPM に何も書かない**
（[README §3.22](../README.md#322-曲の終わり方)）。最後の音は音色本来の RR で減衰するので、
`RINGOUT` はそれが消えるのを待つ。MDX でそうするのは参照実装がそうだから
（[§10.1](#101-参照実装への準拠)）で、VGM には対応する参照実装が無く、
「終端で余韻を切り落とさない」という同じ扱いに揃えてある
（[README §8.1](../README.md#81-対応範囲) の「終端」）。

観測は [ym3012.c](../src/ym3012.c) が持つ。`ym3012_ring_poll()` が取り込んだフレームを
`ym3012_word_to_pcm()` で変換して `YM3012_QUIET_LEVEL` と比べ、超えた位置を
`ym3012_last_loud_total()` に覚える。`ym3012_write_total()` との差がそのまま
「無音が続いているフレーム数」で、`s` の `QUIET` 行に出る。

**`ym3012_reader_read_pcm()` の側ではなく取り込みの側に置いてある。** 変換を通るのは
I2S と USB キャプチャの 2 本だけなので、`I2S_ENABLED=0` でキャプチャもしていない構成では
誰も変換せず、判定が止まってしまう。取り込みは常時走っている。見ているのが
ミックス前・フェード前の生の DAC 出力になるのは、むしろ「チップがまだ鳴っているか」
そのものなので都合がよい。ADPCM は曲の終わりに `pcm8_close_pdx()` /
`pcm8_abort_all()` で止まるので取りこぼさない。

**`SONGEND_RINGOUT_QUIET_MS` が 100ms なのは、波形が 1 周期に 2 回ゼロを通るため。**
瞬時値だけを見ると鳴っていても「無音」に見えるので、可聴下限（20Hz = 50ms 周期）を
跨ぐ長さが要る。

**`SONGEND_RINGOUT_MAX_MS`（5 秒）で強制的に消音する。** RR=0 の音色が鳴ったまま曲が
終わると減衰しないので、待つのをやめるだけではチップが鳴りっぱなしになる。
`opm_key_off_all()` を 1 回だけ撃って `# warn : ringout cut at 5000 ms` を出し、
そのまま無音の判定を続ける（強制リリースは実測で最悪 5.5ms なので必ず成立する）。
**参照実装は自然終了後の音を止めないので、ここは保険としての意図的な逸脱**
（[§10.1](#101-参照実装への準拠)）。

**`SONGEND_RINGOUT_GIVEUP_MS`（10 秒）で無音を待つのをやめる。** 強制消音は 1 回しか
撃たないので、それでも出力が `YM3012_QUIET_LEVEL` を割らなければ `RINGOUT` から抜ける
道が無くなる。`songend_is_active()` が永久に true になり、**キャプチャの終端も
autoplay の曲送りも同時に止まる**（両方ともこの 1 つの観測しか見ていないため）。
ここまで来たら `# warn : ringout gave up at 10000 ms` を出して `IDLE` へ落とし、
状態機械に袋小路を残さない。

### 11.3 フェードアウト

`ym3012_reader_read_pcm()` の**ミキサ適用後**に掛けるデジタルゲインで作る
（[§4.3](#43-pcm-への変換) の合流点）。ADPCM を混ぜたあとなので FM と ADPCM の両方が
一緒に落ち、I2S と USB キャプチャの両方に同じように効く。

**ゲインは絶対フレーム番号の関数にしてある。** カーソルは I2S とキャプチャで 2 本あり
読み出し位置も読む量も違うので、経過時刻で決めると 2 本で違う音になる。ミキサフックが
`first_frame` を受けているのと同じ理屈。

```
残り比 q = 1 - (frame - start) / frames      (Q16)
ゲイン   = q * q                              (線形だと終わり際で急に消えて聞こえる)
```

除算はフレームごとには行わない。開始時に `1/frames` を Q32 で 1 回だけ求め、以後は
乗算とシフトで引く。

**解除もフレーム番号で持つ。** ゲインを即座に 1.0 へ戻すと、リングにまだ残っている
「フェード済みのはずの区間」が全音量で読み出されて十数 ms のノイズになる。
`ym3012_fade_release()` は「このフレーム以降だけ 1.0 に戻す」境界を置くだけで、
それより前は落とし切ったままにする。

**境界を置く前に `ym3012_ring_poll()` を呼ぶ。** 取り込み位置 `s_write_total` は
`service_all()` の音声チェーン（500us 間隔、[§1.1](#11-メインループ)）でしか進まず、
`songend_service()` はその 1/10 の間隔で走る。さらに `opm_key_off_all()` が約 1.3ms
ブロックする。引き直さないと境界が最大 1.8ms 過去に落ち、**まだ落とすべき区間まで
解除されて**しまう。位相が保たれていること（[§9.3](#93-書き込み中の停止とリング位置)）が
前提で、崩れているとこの引き直しをしても境界はその分だけ過去に落ちる。

**解除するのは停止（キーオフ）の後**で、`enter_ringout()` が `stop_players()` の
後ろで呼ぶ。順序が逆だと、まだ鳴っているチップの音が全音量で出てしまう。

**ただしキーオフの直後ではまだ黙っていない。** `opm_key_off_all()` は全スロットの RR を
15 にしてから落とすが、それでもチップのリリースは残る。実測で **KC=0 / KS=0（リリースが
最も遅くなる条件）でも 0 に達するまで約 5.5ms**。ここを詰めると、その区間が全音量で
出て「プチッ」と鳴る。そこで `SONGEND_RELEASE_MS`（16ms）の猶予を置いてから、
`SONGEND_RELEASE_RAMP_MS`（4ms）のランプで 1.0 へ戻す。猶予はフェードが 0 に達した
あとの無音を延ばすだけなのでコストが無く、余裕を 3 倍取ってある。ランプは見積もりが
外れて音が残っていたときの保険。カーブはフェードアウトの `q²` を時間で反転したもの。

`opm_key_off_all()` は**全 32 スロットの RR を書いてから、キーオフ 8 回をまとめて撃つ**。
ch ごとに交互に書くと最初と最後のチャンネルでキーオフが 1.3ms ずれ、リリースの残りも
同じだけ滲むので、猶予の見積もりが立たなくなる。

**境界は前へしか動かない。** `ym3012_fade_start()` で `UINT64_MAX` に初期化されて
1 回のフェードのあいだ単調減少し、後ろへ動かす要求は無視する。一度解除した区間を
無音に塗り直さないため。この規則があるので、`begin_track()` が曲を始めた時点で
`ym3012_fade_release(0, ramp)` を打ち直せる。曲間を挟まない `autoplay next` / `prev` や
`autoplay gap 0` では猶予の大半が新しい曲の頭に被るので、この打ち直しは省略できない
（猶予が済んでいれば何もしない）。

**効く出力先が I2S と USB キャプチャに限られる**のは、Pico が OPM から DAC へのシリアル線を
傍受しているだけで、基板の YM3012 のアナログ経路には入っていないため
（[README §3.22](../README.md#322-曲の終わり方)）。

MDX は MXDRV 由来の TL フェード（`0xE7 0x01`）を別に持っているが、songend はそちらを
使わない。VGM に相当物が無く、曲の種類でフェードの効く出力先が変わってしまうため。

## 12. 自動連続再生 (autoplay)

[autoplay.c](../src/autoplay.c) は「曲が終わったら次を鳴らす」だけの薄い層で、**音を出す仕事も
曲を終わらせる仕事もしない。** 曲の終わり方は [§11](#11-曲の終わり方-songend) が持っていて、
こちらは `songend_is_active()` が落ちるのを待って次の曲を `vgm_play()` / `mdx_play()` で
始めるだけ。

利用者側の仕様は [README §3.17](../README.md#317-autoplay自動再生)。

### 12.1 プレイリスト

曲は `VGM_DIR` / `MDX_DIR` からの相対パス（`KONAMI/GRADIUS.VGM`）で持つ。`'\0'` 区切りで
プールへ詰め、`filelist_collect()`（[§1.3](#13-ファイル一覧の共用)）が深さ優先の順に
並べたオフセット配列を持つ。

```c
static char     s_pool[AUTOPLAY_POOL_BYTES];    // 24KiB
static uint16_t s_offs[AUTOPLAY_MAX_ENTRIES];   // 深さ優先の順。VGM の後ろに MDX
static uint16_t s_order[AUTOPLAY_MAX_ENTRIES];  // 鳴らす順。値は s_offs の添字
static uint32_t s_vgm_count;                    // s_offs の [0, s_vgm_count) が VGM
```

プールが 24KiB あるのは、名前ではなくサブディレクトリを含む相対パスを持つため。
`vgm_play()` / `mdx_play()` へはこの文字列をそのまま渡す（プレイリスト側はディレクトリを
意識しない）。

**曲の種別を持つ配列は無い。** `vgm_collect()` を先に、`mdx_collect()` を後に呼んで
同じバッファへ追記するので、`s_offs` 上の位置が `s_vgm_count` 未満かどうかがそのまま
「VGM か MDX か」になる。

`s_order` を `s_offs` と分けてあるのは、シャッフルしても「一覧としての並び」を壊さない
ため。`list` では恒等写像、`random` では Fisher-Yates（`get_rand_32()`）で並べ替える。
前方へ一巡したところで並べ直し、**並べ直した直後の先頭が直前に鳴らした曲だったら 1 個
ずらす**（切れ目で同じ曲が 2 回続かないように）。

プレイリストを作るのは `autoplay start` のときだけ。再生中にディレクトリを走査し直すと、
曲の途中で数十 ms 止まるうえ、鳴らしている曲の位置を見失う。走査はツリーを再帰するので、
段が深いほど止まる時間も伸びる。

### 12.2 状態機械

`autoplay_service()` は `songend_service()` の**後ろ**で回す
（[§1.1](#11-メインループ)）。同じ周回で出た結論をそのまま見られる。

| 状態 | 抜ける条件 | 次 |
| --- | --- | --- |
| `PLAYING` | `songend_is_active()` が落ちた | `GAP` |
| `GAP` | 無音の期限が来た | 次の曲を鳴らして `PLAYING` |

**曲が終わるのを待つ枝は 1 本しかない。** ループ回数での打ち切りもフェードアウトも
songend が行い、**余韻が消えるまで active のまま**なので、曲間の無音は静かになってから
数え始まる。曲が壊れて `ERROR` に落ちたときも同じ道を通る。フェード中かどうかは
`songend_state_name()` の側に出るので、autoplay 自身の状態は 3 つで足りる。

`start_track()` は `*_play()` が成功したら `songend_arm(s_loop, s_fade_ms)` を呼ぶ。
autoplay の loop / fade の既定値は手動再生と違う（[§11.1](#111-状態機械)）ので、
トラックごとに差し込み直す。

**曲名は autoplay 側が持つ。** `vgm_current_name()` は停止した瞬間に空文字列を返すので、
「いま何番目の何を鳴らしていたか」は再生系からは引けない。

`start_track()` は鳴らせる曲が見つかるまで送り、1 曲ずつ理由を出す。プレイリストを
一巡しても 1 曲も鳴らせなければ自動再生ごと止める（`p 1` 中に φM の違う曲へ進むと
`clockmode_follow_file()` が拒否するので、この経路は普通に通る）。

`s_busy` は `autoplay_service()` を抑止するフラグ。**立てるのは autoplay 自身の 2 経路
だけ** — `autoplay start` がプレイリストを集めている間と、`autoplay list` が出している間。
どちらも 1 行ごと（または 1 件ごと）に `service_all()` を tick として呼ぶので、
立てておかないと集計や出力の最中に曲送りが走ってプレイリストの並びが変わる。
`vgm list` / `mdx list` は `s_busy` に触らない。曲送りが走っても
[filelist.c](../src/filelist.c) の走査バッファは壊れない（`vgm_play()` はそこを触らない）が、
一覧の途中に `# autoplay:` の行が挟まりうる。

### 12.3 他のモジュールとの関係

- **手動の `vgm play` / `mdx play` / `*_stop` はコマンド層で `autoplay_stop()` を先に呼ぶ。**
  autoplay 自身も `vgm_play()` を呼ぶので、区別はコマンド層に置くのが一番単純になる。
- **`storage host` のガードに `autoplay_is_running()` が要る**（[§8.4](#84-所有権の切り替え)）。
  曲間（`GAP`）は VGM も MDX も鳴っていないので、再生系の判定だけでは素通りしてしまう。
- 統計（`STATS_SVC_*`）は足していない。`autoplay_service()` は比較が数回で、`s` の
  `SVC` 行を増やすほどの滞在時間にならない。

## 13. ボタン入力

GP21 (SW1) と GP22 (SW2) の 2 個。SW3 は RUN 端子に繋がっていてハードウェアが
リセットするだけなので、ファームウェアには現れない。仕様と操作は
[README §3.20](../README.md#320-ボタンgp21--gp22)。

### 13.1 検出と消化を分ける

[button.c](../src/button.c) は **autoplay も storage も include しない**。GPIO を読んで
短押し / 長押しのイベントに変えるところまでを持ち、何をするかは
[buttonmap.c](../src/buttonmap.c) の `buttonmap_dispatch()` が決める。

分ける理由は `service_all()` の呼ばれ方（[§1.1](#11-メインループ)）。`d` の待機・
`p 0` のドレイン待ち・一覧出力の行ごとの tick から**コマンド処理の途中で再入的に
呼ばれる**ので、ここから `autoplay_start()` を呼ぶと、`vgm list` の走査中に
`filelist_collect()` が同じ `FILINFO` と走査バッファへ入ってくる
（[§1.3](#13-ファイル一覧の共用)）。応答の途中に `# autoplay:` の行が割り込む問題も
同時に起きる。

`buttonmap_dispatch()` は `main()` の `for(;;)` 直下、`service_all()` の次に置く。
ここが `process_line()` の外側であることが構文的に保証される唯一の点。

### 13.2 デバウンスを時間で測る理由

「N 回連続で同じ値なら確定」ではなく「同じ値が `BUTTON_DEBOUNCE_US` 続いたら確定」に
してある。メインループの周回数は状況で桁違いに変わる（通常は数十万周/秒、フラッシュの
消去中は数十 ms 空く）ので、回数で数えると時定数が定義できない。

`button_service()` 自体も `BUTTON_SERVICE_INTERVAL_US` で間引いてある。値と決め手は
[README §3.11.1](../README.md#3111-サービスの呼び出し間隔) にある。

2 本を 1 つの窓でまとめて見ている。片方が暴れている間はもう片方も確定しないが、
確定値は保持されたままなので実害が無く、ピンごとに窓を持つより状態が少なくて済む。

### 13.3 エピソードと chord

**エピソード**は最初の押下から全解放まで。**chord** はそのエピソード中に押された
ボタンの OR。離すときのずれ（SW1 を離してから SW2 を離すまでの数十 ms）は、全解放まで
エピソードが続くので自動的に吸収される。

| 状態 | 遷移 |
| --- | --- |
| `EP_IDLE` | 確定値が 1 個以上 ON → chord を張って `EP_ACTIVE` へ |
| `EP_ACTIVE` | chord が広がった → chord を足して**ホールドの起点を張り直す** |
| `EP_ACTIVE` | 起点から `BUTTON_LONG_PRESS_US` 経過 → 長押しを post して `EP_LOCKED` へ |
| `EP_ACTIVE` | 全解放 → 短押しを post して `EP_IDLE` へ |
| `EP_LOCKED` | 全解放まで何もしない。全解放で `EP_IDLE` へ |

**ホールドの起点は「最初の押下」ではなく「最後に chord が広がった時刻」。** ここが
唯一の非自明な点で、起点を最初の押下にすると *SW1 を単独で 0.9 秒押しているところへ
SW2 が 0.05 秒遅れて入った瞬間に chord が BOTH になり、1.0 秒の時点で `storage host` が
誤爆する*。張り直せばこれが消えるうえ、**和音のずれを吸収するための猶予時間という
定数を別に置かずに済む**。副作用は「SW1 を 0.9 秒押してから SW2 を足すと 1.9 秒で
同時長押しになる」だけで、誤爆よりはるかに安全。

長押しを**しきい値に達した瞬間**に成立させ、以降は全解放までロックアウトするので、
押しっぱなしでも 1 回しか効かない。離したときに何も起きないのはこのため。

### 13.4 メールボックス

深さ 1。埋まっている間に来たイベントは捨てる（古い方を残す）。理由は
[README §3.20](../README.md#320-ボタンgp21--gp22)。長押しの成立後は全解放まで
ロックアウトされるので、「長押しの直後に短押しが来て上書きされる」という並びは
構造的に起きない。

**捨てたことをその場で `printf` しない。** `button_service()` は一覧出力の行ごとの
tick からも呼ばれるので、そこから行を吐くと出力の途中に割り込む。数だけ
`button_dropped()` に積む。

### 13.5 LED の一時表示と起動待ち

[led.c](../src/led.c) の一時表示（オーバーレイ）はポインタ + 長さ + 位置の 3 変数で持ち、
`overlay_start()` で差し込む。非アクティブはポインタが `NULL` なので番兵の値は要らない。
種類を問わず後から来たものが勝つ。

**一時表示は基本パターンを完全に置き換える。** 待機は常時点灯なので、点灯だけの
パターンを重ねても何も変化しない。長押しの合図を `"0111110"`（OFF から始まる）に
してあるのはこのため。

起動待ちは基本状態 `LED_STATE_BOOT` を 1 つだけ足し、点滅回数ごとのパターンは
`led_boot_pattern()` がポインタで選ぶ。3 つの状態には割っていない。

`LED_STATE_HOST` の張り替えは [storage.c](../src/storage.c) が持つ
（[capture.c](../src/capture.c) が `LED_STATE_CAPTURE` を持つのと同じ作法）。コマンド経由・
ボタン経由・PC の eject 経由（`storage_host_ejected()`）の 3 つが必ず
`storage_set_host()` / `storage_set_player()` を通るので、1 箇所で揃う。

**不変条件: `LED_STATE_HOST` と `LED_STATE_CAPTURE` は同時に成立しない。** `p 1` は
HOST 中に拒否され、`storage host` はキャプチャ中に拒否されるため
（[§8.4](#84-所有権の切り替え)）。この排他を将来緩めると、キャプチャの停止が
`LED_STATE_IDLE` を張って HOST の表示を消す。

### 13.6 起動シーケンス

`button_init()` は `led_init()` の直後、初期化列の先頭に近い位置で呼ぶ。**プルアップを
最も早く効かせて整定時間を稼ぐため**と、押されているかの採取をここで済ませて素早く
離した利用者を取りこぼさないため。GP21 / GP22 は `opm_init()` の `gpio_init_mask()`
（GP2-GP14）にも ym3012（GP17-GP20）にも I2S（GP26-GP28）にも含まれないので、後続の
初期化と衝突しない。整定は RC で µs オーダーだが当てにせず、`button_init()` の中で
同じ値が `BUTTON_DEBOUNCE_US` 続くのを確かめてから確定する。

実行（`buttonmap_boot_apply()`）は初期化列の最後、`autoplay_init()` の後。
`autoplay_start()` が `storage_init()` のマウントを前提にするため。

**解放待ちのループでは `service_all()` を回す。** 待ち時間は利用者次第で数秒あり得るが、
キャプチャ側と I2S 側の DMA リングは `ym3012_init()` / `i2s_init()` の時点で既に走って
いて、一周 65.5ms を超えて止まると位置を見失う（[§1.1](#11-メインループ)）。
`tud_task()` が止まると USB の列挙も進まない。

**起動時に押されていたぶんを実行時のイベントにしない。** `button_init()` は
`EP_LOCKED` から始め、`button_boot_wait_release()` は抜けるときに状態機械を
`EP_IDLE` / chord = 0 へ戻す。これをやらないと、離した時点で短押しが post されて
起動モードと二重に発火する。

`buttonmap_boot_apply()` の最後に `capture_resync_after_blackout()` を呼ぶ。ホストが CDC を
開く前の `printf` は 1 本あたり最大 `PICO_STDIO_USB_STDOUT_TIMEOUT_US`（10ms）ブロック
するので、複数行出すと I2S の先行量 16.4ms を超え得るため。

### 13.7 無効化

`BUTTON_ENABLED=0` では [button.c](../src/button.c) が全部空の実装になり、GP21 / GP22 には
一切触らない。`button_take_event()` が常に `false` を返すので、
**[pico-opm-writer.c](../src/pico-opm-writer.c) の消化側に `#if` は要らない**
（autoplay と同じ流儀）。[led.c](../src/led.c) の追加分は数十バイトなので常にリンクする
（`LED_STATE_HOST` はボタンとは独立に `storage host` で使う）。

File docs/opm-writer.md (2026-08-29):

# opm-writer

[tools/opm-writer.py](../tools/opm-writer.py)

シーケンスファイルを USB CDC 経由で pico-opm-writer のファームへ流し込むホスト側ドライバ。
1 行送るごとに応答 (`OK` / `ERR`) を待ち、`!capture` / `!capture-song` の行では
キャプチャを起動する。ファームのコマンド仕様は [README §3](../README.md#3-ホストインタフェース) を参照。

外部ライブラリは使わない（標準ライブラリのみ）。

## 使い方

```bash
# シーケンスを流し込み、!capture の内容を WAV で保存
./tools/opm-writer.py seq.txt out.wav.zst

# プレースホルダを埋める
./tools/opm-writer.py seq.txt out.wav.zst -D LFRQ=a3 -D NFRQ=1f -D TIME=1000

# 実機に触らず、実行内容だけ確認する
./tools/opm-writer.py seq.txt out.wav.zst -D ... -n
```
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

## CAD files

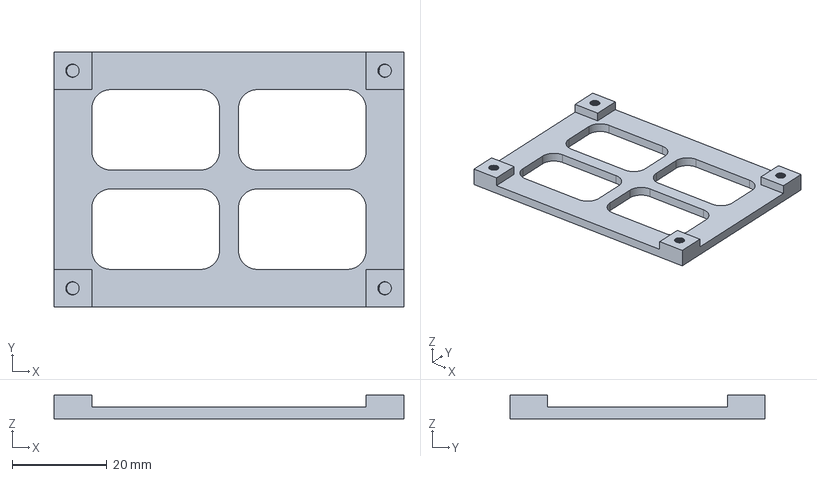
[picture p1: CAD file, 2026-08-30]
board/base/pico-opm-writer_base.FCStd
74.0 x 54.0 x 5.00 mm

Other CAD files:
board/base/pico-opm-writer_base-Body.stl

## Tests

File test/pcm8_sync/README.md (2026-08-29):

# FM と ADPCM の発音タイミングのずれ

FM（YM2151 → YM3012 → PIO キャプチャ）と ADPCM（[pcm8.c](../../src/pcm8.c) のソフトデコード）は
`ym3012_reader_read_pcm()` の中でフレーム番号を突き合わせて足され、I2S と USB CDC #1 へ出る。
MDX が両者を**同じ tick でキーオン**したとき、出力の中で立ち上がりが揃うかを実測した。

対象は I2S と USB キャプチャだけ。**YM3012 のアナログ出力には ADPCM が乗らない**ので、
そちらを聴いている限りこのずれは存在しない。

数値はすべて φM 4MHz（出力 62500 フレーム/s、**1 フレーム = 16µs**）のもの。

## 1. 解析結果の要約

| 項目 | 結論 | 根拠 |
| --- | --- | --- |
| 修正前の FM と ADPCM の発音時刻の関係 | **ADPCM が先行する。**実曲で最大 126 フレーム = 2.0ms。1 音ごとに値が変わる揺らぎで、固定オフセットではない | [§3.1](#31-修正前adpcm-が-fm-より先に出る) |
| 先行量を決めているもの | `pcm8_service()` のレンダリング前線 `s_rendered_total` が「今」より後ろにある量そのもの。束ね（`PCM8_BATCH_FRAMES` = 64 フレーム）と音声チェーンの間引き（`AUDIO_SERVICE_INTERVAL_US` = 500µs = 31 フレーム）の噛み合わせで決まる | [§3.2](#32-先行量はレンダリング前線の遅れそのもの) |
| ADPCM が発音中かどうかによる違い | 無音からの発音は間引きぶんだけ（10〜39 フレーム）、発音中の追加発音には束ねも乗る（14〜101 フレーム） | [§3.3](#33-束ねが効くのは発音中だけ) |
| 修正後に残るずれ | 0〜3 フレーム = 0〜48µs。機構由来の成分は 0 | [§3.4](#34-修正後は機構由来の成分が-0-になる) |

## 2. 判明した仕様

### 2.1 FM は実時刻に固定され、ADPCM は固定されていなかった

キャプチャリングのフレーム番号 N は実時刻 N/62500 に固定されている。DMA の書き込み位置と
`s_write_total` が `s_write_total ≡ 書き込み添字 (mod 4096)` で結ばれていて
（[ym3012.c](../../src/ym3012.c) の `ym3012_ring_poll()`）、途中で位相がずれない。したがって
`opm_write()` した瞬間の FM の音は、その瞬間のフレーム番号に入る。

ADPCM 側はフレーム番号を自分で選ぶ。`pcm8_service()` が描くのは

    [s_rendered_total, ym3012_write_total())

という **「今」より過去に向かう**区間なので、キーオンした音はその時点の
`s_rendered_total` = **過去のフレーム番号**から鳴り始めていた。

### 2.2 束ねと間引きは、そのまま発音時刻の誤差になっていた

`s_rendered_total` の遅れを決めるのは次の 2 つ。どちらも CPU の固定費を下げるための
仕組みで、音質のための設計ではない。

| 仕組み | 値 | 効き方 |
| --- | --- | --- |
| `PCM8_BATCH_FRAMES`（[pcm8.c](../../src/pcm8.c)） | 64 フレーム | **発音中だけ**、64 フレーム溜まるまで描かない |
| `AUDIO_SERVICE_INTERVAL_US`（[pico-opm-writer.c](../../src/pico-opm-writer.c)） | 500µs = 31 フレーム | リング位置の取り込みと描画を 500µs ごとにまとめる |

31 フレームずつ進む `w` に対して束ねの閾値が 64 なので、発音中は 3 回に 1 回しか描かない。
前線の遅れは 0〜93 フレームを往復し、そこへメインループが長く止まった回が加わる。

### 2.3 実機 X68000 とは向きも逆だった

MXDRV は FM のレジスタを書いてから ADPCM を叩く。[mdx.c](../../src/mdx.c) の tick ループも
チャンネル番号順（FM 0-7 → ADPCM 8-15）に処理するので、**キーオンの発行順は FM が先**。
実機では ADPCM がわずかに遅れるはずのところ、pcm8 が過去へ描くせいで先行に転じていた。

### 2.4 直し方

**発音状態を変える前に、その瞬間のフレーム番号まで描き切る。**
[pcm8.c](../../src/pcm8.c) の `flush_now()` がこれを行い、`pcm8_key_on()` /
`pcm8_stop()` / `pcm8_set_mode()` / `pcm8_abort_all()` / `pcm8_iocs_out()` /
`pcm8_iocs_mod()` / `pcm8_set_enabled()` の入口から呼ばれる
（`pcm8_close_pdx()` は `pcm8_abort_all()` 経由）。

**`ym3012_ring_poll()` をその場で呼ぶのが肝。** 呼ばないと `ym3012_write_total()` は直前の
音声チェーン（最大 500µs 前）の値のままで、間引きぶんの 31 フレームが残る。

束ねそのものは撤去していない。発音状態が変わらない区間では時刻の誤差を生まないため。

## 3. 結論の根拠

測定は 2 系統ある。**波形から測ったもの**（出力に本当にそう出ているか）と、
**ファーム内部のカウンタ**（機構がそう動いているか）で、独立に同じ量を指す。

### 3.1 修正前、ADPCM が FM より先に出る

FM を右、ADPCM を左に振り分けた [SYNC.MDX](gen_testdata.py) を鳴らして 8 秒取り込み、
左右それぞれの立ち上がりフレームを比べた（[§4](#4-解析方法)）。**正が「ADPCM のほうが早い」。**

| 条件 | 対の数 | min | max | 幅 | 平均 | 平均 (µs) |
| --- | ---: | ---: | ---: | ---: | ---: | ---: |
| quiet（音の合間は ADPCM が 1ch も鳴っていない） | 326 | 10 | 39 | 29 | 18.36 | 293.7 |
| busy（ほぼ無音のドローンで発音中を保つ） | 326 | 14 | 101 | 87 | 47.22 | 755.5 |

実曲（`DRACULA/dra03.mdx` を 60 秒）では内部カウンタで **min 1 / max 126 / 平均 32 フレーム**、
すなわち**最大 2.0ms** に達した。合成した曲より大きいのは、PDX の読み出しや音色の展開で
メインループが長く止まる回があるため。

### 3.2 先行量はレンダリング前線の遅れそのもの

キーオンの瞬間に `ym3012_write_total() - s_rendered_total` を数える診断を当てて
（[diag.patch](diag.patch)）、同じ 8 秒のあいだ同時に記録した。

| 条件 | 波形から (min/max/平均) | 内部カウンタ (min/max/平均) |
| --- | --- | --- |
| quiet | 10 / 39 / 18.4 | 7 / 37 / 16 |
| busy | 14 / 101 / 47.2 | 6 / 100 / 44 |

**2 つは 2〜3 フレーム以内で一致する。** 差は FM 側だけに掛かる分（キャプチャ経路の
1 フレームと、正弦波が検出閾値を跨ぐまでの 1 フレーム）と、tick 内で FM のキーオンが
先に出る分が相殺した残り。前線の遅れ以外に、ずれを作っている要素は無い。

### 3.3 束ねが効くのは発音中だけ

quiet と busy の違いはドローン 1 本の有無だけで、測定対象の 2 チャンネルは同一。それでも

- quiet の幅 29 フレーム ≈ 間引きの 31 フレーム
- busy の幅 87 フレーム ≈ 間引き 31 + 束ね 64 = 95 フレーム

となり、`pcm8_service()` の `s_sounding && behind < PCM8_BATCH_FRAMES` という条件
（発音中だけ束ねる）がそのまま分布の幅に出ている。

### 3.4 修正後は機構由来の成分が 0 になる

同じ測定を修正後に繰り返した。

| 条件 | 対の数 | min | max | 幅 | 平均 | 平均 (µs) | 内部カウンタ |
| --- | ---: | ---: | ---: | ---: | ---: | ---: | --- |
| quiet | 326 | 1 | 3 | 2 | 2.02 | 32.4 | 0 / 1 / 0 |
| busy | 326 | 0 | 2 | 2 | 1.52 | 24.2 | 0 / 1 / 0 |
| 実曲 (60 秒) | — | — | — | — | — | — | 0 / 1 / 0 |

内部カウンタが全条件で 0〜1 フレームということは、**ADPCM がキーオンした瞬間の
フレーム番号から鳴り始めている**ということ。残った 0〜3 フレームは FM 側と検出側の
バイアスで、[§3.2](#32-先行量はレンダリング前線の遅れそのもの) で見た 2〜3 フレームと同じもの。

### 3.5 退行が無いこと

`DRACULA/dra03.mdx` を 60 秒、同じ条件で修正前後に鳴らして比べた。

| 指標 | 修正前 | 修正後 |
| --- | --- | --- |
| `I2S` UNDERRUN | 0 | 0 |
| `I2S` MIN（先行量の谷） | 843 | 843 |
| `OVERRUN` / `E0` / `RXSTALL` | 0 | 0 |
| `MDX PCM` keyon / miss / reads | 341 / 0 / 595 | 341 / 0 / 595 |
| `CLIP` | 0 | 2 |
| `SEQ LAG` max | 84 µs | 90 µs |
| `CPU` | 39% | 39% |
| `SVCTIME` pcm8 + mdx | 17815 + 33979 = 51794 µs/s | 17648 + 32307 = 49955 µs/s |

**発音の判定は 1 回も変わっていない**（keyon / miss / reads が完全に一致）。描く総量も
変わらないので `SVCTIME` の合計も増えていない（差の 3.5% は実行ごとのばらつきの範囲）。
`CLIP` の 2 は、ブロックの切れ目が動いたことで飽和の判定が数フレームずれたもの。

`t` の自己テストは `pcm PASS` / `mdx PASS (7 pitch, 5 tempo)` / `adpcm PASS (19 cases)`。

## 4. 解析方法

### 4.1 左右に振り分けて 1 回のキャプチャで比べる

FM と ADPCM が同じ tick でキーオンするだけの曲を作り、**FM を右・ADPCM を左**に置く。
差分も相互相関も要らず、同じキャプチャの中で立ち上がりを直接比べられる。

- FM は OPM の `0x20+ch` の `RL` で片側だけに出す。反対側のスロットには何も加算されない。
- ADPCM は [pcm8.c](../../src/pcm8.c) の `render_block()` が `pan & 1` で L、`pan & 2` で R に
  振り分ける。ミックスリングの段階で片側は 0 のまま。**PCM8 の定位は全チャネル共通**なので、
  鳴らすチャンネルはすべて `p1` にしてある。

左右の DAC スロットは同じ値にならない（[../dac_lr/](../dac_lr/README.md)）が、その差は
1 フレーム未満で、ここで測る 100 フレームには効かない。

### 4.2 立ち上がりを鋭くする

| 側 | 波形 | 立ち上がり |
| --- | --- | --- |
| ADPCM | 8bit PCM 形式（mode 6）の直流 0x60 | 1 ソースサンプル = 4 出力フレームで全振幅。実測では 1 フレームで 0 → 24576 |
| FM | 1 オペレータ（CON=7 で C2 だけ TL=0）、AR=31、音符 84（約 2.5kHz） | 実測で 0 → 2008 → 8144 の 3 フレーム |

ADPCM 形式（mode 0-4）を使うと、MSM6258 のステップ幅が 16 から始まるので全振幅まで 1ms
ほどかかり、測りたい量と同じ桁になってしまう。**そのため ADPCM 形式は使っていない。**
デコーダ自体の検証は `t` の `adpcm` が既知ベクタで行う。

### 4.3 2 条件を作る

`pcm8_service()` は `s_sounding`（直前の描画で発音していたか）が真のときだけ束ねる。
そこで 2 つ用意した。

| ファイル | 条件 | 中身 |
| --- | --- | --- |
| `SYNC.MDX` | quiet | FM ch0 と ADPCM ch8 だけ。音の合間は ADPCM が 1ch も鳴っていない |
| `SYNC2.MDX` | busy | 上に加えて ADPCM ch9 でドローンを鳴らし続ける |

ドローンは PDX のエントリ 1（振幅 1 の直流）を最小音量（`@v42` = PCM8 の音量 0 = 利得
0.158）で鳴らすもので、出力は 40 前後。解析の閾値 500 のはるか下なので立ち上がりの検出に
掛からない。ゲートタイムだけ `q8`（= 音の長さいっぱい）にして、キーオフと次のキーオンが
同じ tick に来るようにしてある。`q2` にすると 1/3 の時間しか鳴らず、束ねが働かない。

### 4.4 立ち上がりの決め方

無音が 64 フレーム続いたあと、最初に絶対値 500 を超えたフレームを立ち上がりとする。
無音区間は厳密に 0 になるので、閾値は雑音を跨ぐためではなく**アタックのごく初期の
1-2 フレームを無視するため**にある。

閾値のぶんの遅れは L / R それぞれで一定なので、**分布の幅**と**条件間の平均の差**には
効かない。この 2 つが結論に使っている量で、絶対値そのものは使っていない。

対応づけは「L の各立ち上がりに対し 768 フレーム以内で最も近い R」。片側が取りこぼされた
音は捨てる。8 秒で 326 対が取れ、これは音の間隔 24.58ms から期待される数と一致する。

検出器と対応づけは [analyze_sync.py](analyze_sync.py) の `--self-test` が 15 ケースで
検証する（実機不要）。生成物の書式は [gen_testdata.py](gen_testdata.py) の `--self-test` が
27 ケースで検証する。

### 4.5 内部カウンタ

波形の測定は FM 側のバイアスを含む。機構そのものを見るために、キーオンの瞬間に
`ym3012_ring_poll()` してから `ym3012_write_total() - s_rendered_total` を数える診断を
当てた。実装は [diag.patch](diag.patch)、使い方は[付録](#付録)。**本体には残していない。**

## 5. 詳細な解析結果

### 5.1 修正前の分布

quiet（8 秒 / 326 対）。幅 29 フレームで、間引きの 31 フレームにほぼ一致する。

```
     10.0 ..    11.8 | ################################################ 99
     11.8 ..    13.6 | ###################                              40
     13.6 ..    15.4 | ################                                 33
     15.4 ..    17.2 | #############                                    27
     17.2 ..    19.1 | ###                                              6
     19.1 ..    20.9 | ###################                              40
     20.9 ..    22.7 | ##                                               5
     22.7 ..    24.5 | ###                                              7
     24.5 ..    26.3 |                                                  0
     26.3 ..    28.1 |                                                  1
     28.1 ..    29.9 | ##########                                       21
     29.9 ..    31.8 | ###                                              7
     31.8 ..    33.6 | #####                                            10
     33.6 ..    35.4 |                                                  0
     35.4 ..    37.2 |                                                  0
     37.2 ..    39.0 | ###############                                  30
```

busy（8 秒 / 326 対）。幅 87 フレームで、間引き 31 + 束ね 64 = 95 の内側に収まる。

```
     14.0 ..    19.4 | ################################################ 69
     19.4 ..    24.9 | #####                                            7
     24.9 ..    30.3 | ###                                              4
     30.3 ..    35.8 | ###                                              4
     35.8 ..    41.2 | ################################################ 69
     41.2 ..    46.6 | #######################                          33
     46.6 ..    52.1 | ##############                                   20
     52.1 ..    57.5 |                                                  0
     57.5 ..    62.9 | ######                                           8
     62.9 ..    68.4 | #############                                    19
     68.4 ..    73.8 | ######################################           55
     73.8 ..    79.2 | ######                                           9
     79.2 ..    84.7 | ##################                               26
     84.7 ..    90.1 |                                                  0
     90.1 ..    95.6 |                                                  0
     95.6 ..   101.0 | ##                                               3
```

**分布が一様でなく塊になる。** 音の間隔は 6 clock = 4.096ms × 6 = 24.576ms、音声チェーンの
間引きは 500µs で、両者の比が整数でないぶんだけキーオンの落ちる位相が少しずつ動く。
その周期が 8 秒より長いので、1 回のキャプチャでは特定の位相に偏る。**幅は正しく出るが、
平均と中央値は取り込み長に依存する。**

### 5.2 修正後の分布

quiet は 288/326 が 2 フレームちょうど、busy は 1 と 2 に割れる。どちらも幅 2 フレーム。

```
quiet:  1.0 ..  1.1 | ##                                               15
        2.0 ..  2.1 | ################################################ 288
        2.9 ..  3.0 | ####                                             23

busy:   0.0 ..  0.1 | #                                                4
        1.0 ..  1.1 | ##########################################       150
        1.9 ..  2.0 | ################################################ 172
```

### 5.3 残差 1〜2 フレームの内訳

3 つの成分がある。いずれも 1 フレーム前後で、打ち消し合って正味 1〜2 フレームになる。

| 成分 | 量 | 向き |
| --- | --- | --- |
| 検出の閾値。FM は正弦波なので 0 を離れてから 500 を跨ぐまで 1 フレームかかる | +1 | ADPCM が早く見える |
| キャプチャ経路。FM の 1 サンプルは、OPM が計算した次のフレームでリングに入る | +1 前後 | ADPCM が早く見える |
| tick 内の順序。ch0（FM）のキーオンが ch8（ADPCM）より先に発行される | −1〜−2 | ADPCM が遅く出る |

3 番目が小さいのは、この曲では音色・音程・音量が毎回同じで**キーオンのたびに書くのが
`0x08` の 1 本だけ**だから。音色を展開し直す曲では 25 本になり、その分だけ ADPCM が
遅れる。これは参照実装と同じ挙動で、修正の対象ではない。

### 5.4 実曲での内部カウンタ

`DRACULA/dra03.mdx` を 60 秒（keyon 341 回）。

| | min | max | 平均 |
| --- | ---: | ---: | ---: |
| 修正前 | 1 | 126 | 32 |
| 修正後 | 0 | 1 | 0 |

修正前の max 126 は、合成した曲の 100 より大きい。束ね 64 + 間引き 31 = 95 を超えるのは、
PDX の読み出しや音色の展開でメインループが 1 回の音声チェーン間隔より長く止まった回が
あるため。**遅れの上限は 2 つの定数では決まらず、そのときのメインループの詰まり方で
決まっていた。**

## 6. 考察

### 6.1 聴こえるかどうかとは別に、直す価値がある

2.0ms は 2 つの音の同時性としては閾値以下で、これだけを理由に音の違いを聴き分けるのは
難しい。それでも直したのは次の理由による。

- **揺らぐ。** 固定オフセットなら「そういう音」で済むが、1 音ごとに 0〜2ms 動くので
  リズムパートでは打点が安定しない。
- **上限が決まらない。** [§5.4](#54-実曲での内部カウンタ) のとおり、メインループが
  詰まるほど大きくなる。機能を足していくと悪化する側の量だった。
- **向きが実機と逆だった。** MXDRV は FM を書いてから ADPCM を叩くので、実機では ADPCM が
  わずかに遅い。忠実さを目標にしている以上、符号が逆なのは直す理由になる。
- **直すコストがほぼ 0 だった。** ミックスリングがもともとフレーム番号で引く冪等な設計
  だったので、前線を実時刻へ寄せるだけで済み、描く総量も変わらない
  （[§3.5](#35-退行が無いこと)）。

### 6.2 「間引いてよいもの」と「間引いてはいけないもの」

メインループは各サービスを最短間隔を決めて回す。これは 1 周あたりの固定費を下げるための
設計で、**信号の流れ（1 秒に 62500 フレーム）に対しては透明**である。リングの読み書きは
フレーム番号で結ばれていて、いつ読みに行っても内容は同じだからである。

**透明でなくなるのは、間引いた側が新しい内容を書き込む瞬間だけ。** 今回の ADPCM の
キーオンがまさにそれで、「いつ描くか」は自由でも「どのフレーム番号から描くか」は自由に
できない。同じ構造は、外から時刻を持ち込む操作すべてに当てはまる。

### 6.3 束ねを外す選択肢を採らなかった理由

`PCM8_BATCH_FRAMES` を 1 にすれば束ねの成分は消えるが、間引きの 31 フレームは残るうえ、
ブロックの支度の固定費が 64 倍になる。`AUDIO_SERVICE_INTERVAL_US` を縮めれば間引きの
成分も減るが、こちらはメインループ全体の周回数に効く（[README §3.11.1](../../README.md#3111-サービスの呼び出し間隔)）。
どちらも**誤差を小さくするだけで 0 にはできず、CPU を確実に食う。**
発音の瞬間に前線を寄せる方法は誤差を 0 にして CPU を食わない。

## 7. 不明点・未解決事項

- **音色を展開し直す曲での FM 側の遅れを測っていない。**
  [§5.3](#53-残差-12-フレームの内訳) のとおり、キーオンごとに 25 レジスタを書く曲では
  FM のキーオンが 700µs 前後かかり、その分 ADPCM が遅れて出る。これは参照実装と同じ
  挙動なので修正の対象ではないが、**実際に何フレームになるかは測っていない。**
- **平均値が取り込み長に依存する。** [§5.1](#51-修正前の分布) のとおり、キーオンの位相が
  8 秒より長い周期でゆっくり動くため、1 回のキャプチャの平均は真の平均ではない。
  結論に使ったのは分布の幅と修正前後の差なので影響しないが、**修正前の「平均 47 フレーム」
  という値そのものは条件に依存する。**
- **`ym3012_ring_poll()` をキーオンのたびに呼ぶことの影響を切り分けていない。**
  [§3.5](#35-退行が無いこと) で `SVCTIME` の合計が増えないことは確かめたが、この呼び出し
  単体の費用は測っていない。DMA のレジスタ読み 1 回と加算数回なので無視できるはずだが、
  未確認。
- **8ch を同時に鳴らす曲での挙動を測っていない。** ドローン 1 本で束ねを働かせたが、
  8ch すべてが鳴っている状態では 1 回の描画量が増える。前線を寄せる操作がキーオンごとに
  走るので、tick の中での CPU の山は高くなるはず。`SEQ LAG` に出るかは未確認。

## 8. 今後の課題

- **音色展開を伴うキーオンでの FM 側の遅れを測る。** [gen_testdata.py](gen_testdata.py) の
  FM チャンネルに、音符ごとに `@`（`0xFD`）を挟むだけでよい。音色は同じものを指しても
  `F17_VOICE_REQ` が立つので 25 レジスタが毎回書かれる。同じ測り方で L と R の差を取れば、
  参照実装どおりの遅れが何フレームなのかが出る。実機での同時性の上限を知る意味がある。
- **位相の偏りを消して真の平均を出す。** 音の間隔を音声チェーンの間引き（500µs）と
  互いに素な値にすれば、短い取り込みでも位相が一巡する。`NOTE_CLOCKS` と `TEMPO` を
  選び直して、たとえば 1 音 25.1ms（= 500µs の整数倍から少しずらす）にすればよい。
  修正前の分布を「幅」ではなく「平均」で語れるようになる。
- **8ch 同時発音での CPU の山を測る。** `SYNC2.MDX` のドローンを 7 本に増やし、
  `-DSTATS_PROFILE=1` で `SVCTIME` の `mdx` と `SEQ LAG` を見る。`MDX_BUDGET_US`（500µs）を
  超えて tick が分割されるようなら、前線を寄せる操作を「1 tick に 1 回」にまとめる余地がある。

## 付録

### A.1 テストデータを作って実機へ置く

```bash
./gen_testdata.py                 # SYNC.MDX / SYNC2.MDX / SYNC.PDX を作る
./gen_testdata.py --self-test     # 生成物の自己検証（実機不要 / 27 ケース）
```

3 つのファイルを実機の `/MDX/` へ置く。ファームを `storage host` にすると
ホストから USB マスストレージとして見える（再生中は拒否されるので先に `mdx stop`）。

```bash
# ファーム側: storage host
cp SYNC.MDX SYNC2.MDX SYNC.PDX /Volumes/PICOOPM/MDX/
# ホスト側で取り出してから、ファーム側: storage player
```

### A.2 取り込む

```bash
../../tools/opm-writer.py opm_seq.txt wav/before-quiet.wav.zst -D TIME=8000 -D MDX=SYNC.MDX
../../tools/opm-writer.py opm_seq.txt wav/before-busy.wav.zst  -D TIME=8000 -D MDX=SYNC2.MDX
```

| プレースホルダ | 意味 |
| --- | --- |
| `@MDX@` | 鳴らす曲。`SYNC.MDX`（quiet）か `SYNC2.MDX`（busy） |
| `@TIME@` | 取り込む長さ（ms）。8000 で 326 対が取れる |

### A.3 解析する

```bash
./analyze_sync.py wav/*.wav.zst              # 要約とヒストグラム
./analyze_sync.py wav/*.wav.zst --no-hist    # 要約だけ
./analyze_sync.py wav/before-busy.wav.zst --tsv > skew.tsv
./analyze_sync.py --self-test                # 検出器の自己検証（実機不要 / 15 ケース）
```

| オプション | 既定 | 意味 |
| --- | --- | --- |
| `--threshold N` | 500 | 立ち上がりと見なす絶対値 |
| `--guard N` | 64 | 立ち上がりの前に要る無音フレーム数 |
| `--window N` | 768 | L と R を対にする最大の隔たり（フレーム） |
| `--tsv` | — | 1 音 1 行の TSV を出す |
| `--no-hist` | — | ヒストグラムを省く |

### A.4 内部カウンタを読む

```bash
git apply test/pcm8_sync/diag.patch
ninja -C build
# SWD で焼く（README の手順）
```

`s` の出力に 1 行増える。`s 0` と `mdx play` で 0 に戻る。

```
# MDX SKEW: min 6  max 100  avg 44  n 708  frames
```

`ym3012_write_total() - s_rendered_total` を発音開始のたびに数えたもの。修正が効いていれば
**全条件で 0 か 1** になる。0 でない値が並ぶなら `flush_now()` の掛け漏れか、その中の
`ym3012_ring_poll()` の呼び忘れ。

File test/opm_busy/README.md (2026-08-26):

# YM2151 の BUSY フラグと `opm_write()` の待ち時間

`opm_write()` はデータサイクルのあと `OPM_T_DATA_US`（25µs）を固定で待っている。
`r 0` / `r 1` でステータスレジスタの BUSY (bit7) が読めるようになったので、
**この固定ウェイトを BUSY のポーリングに置き換えるべきか**を実測で判断するための調査。

## 解析結果の要約

| 項目 | 結論 | 根拠 |
| --- | --- | --- |
| データ書き込みと BUSY 解除の関係 | 書き込みから **67.1 ± 0.2 φM サイクル**で BUSY が落ちる（φM=4MHz で 16.8µs / 3.579545MHz で 18.8µs） | [§1](#1-busy-の長さ--φm-を振って傾きから求める) |
| レジスタアドレスと BUSY 長の関係 | **どのレジスタでも同じ。** 12 レジスタでばらつき 16ns。8ch 発音中も同じ | [§3](#3-レジスタにもチップの状態にも依存しない) |
| アドレスサイクルと BUSY の関係 | **アドレスサイクル (A0=0) は BUSY を立てない。** `OPM_T_ADDR_US` はポーリングでは 1ns も削れない | [§4](#4-アドレスサイクルは-busy-を立てない) |
| 書き込みと BUSY アサートの関係 | BUSY が立つのは書き込みの **2.9 φM サイクル後**（φM=4MHz で 0.73µs）。即座には立たない | [§1](#1-busy-の長さ--φm-を振って傾きから求める) |
| ステータス読み出し 1 回の所要時間 | 連続ポーリングで **1.00µs**、単発の `opm_read()` で 2.00µs | [§2](#2-測定系の妥当性) |
| 待ち方と 1 レジスタ書き込みの所要時間の関係 | 固定 25µs = **32.0µs** / 固定 18µs = **25.0µs** / BUSY ポーリング = **25.0µs** | [§詳細](#待ち方ごとのベンチマーク) |
| 待ちの繰り延べと書き込みのブロック時間の関係 | 書き込みの間に 20µs 以上の仕事が挟まると **7.0µs** まで縮む。密なループでは縮まない | [§詳細](#待ち方ごとのベンチマーク) |
| MDX 再生中の `mdx_service()` の滞在時間 | 49.0ms/s → 固定 18µs で 41.8ms/s、繰り延べを足して **38.8ms/s** | [§詳細](#実再生での効果) |

## 判明した仕様

### BUSY フラグのタイミング（φM を単位とする）

```
  データサイクルの /WR 立ち上がり
    |
    |<-- 2.9 サイクル -->|                                    BUSY=1
    |                    |<--------- 64.2 サイクル --------->|
    0                   2.9                                67.1  [φM サイクル]
```

| φM | BUSY が立つ | BUSY が落ちる |
| --- | --- | --- |
| 4.000000 MHz | 0.73 µs | **16.79 µs** |
| 3.579545 MHz | 0.82 µs | **18.76 µs** |

- **BUSY 長はレジスタアドレス・書き込む値・チップの発音状態のいずれにも依存しない。**
  内部転送に固定サイクル数かかるだけと考えられる。
- **アドレスサイクル (A0=0) では BUSY は立たない。** データサイクル (A0=1) だけが立てる。
- データシート由来としてドキュメントに書かれている 68 サイクルは、実測の 67.1 ± 0.2 と
  1 サイクル以内で一致する。この測定では 67 と 68 を区別できない
  （[不明点](#不明点未解決事項)）。

### 待ち方ごとの書き込み所要時間（φM=4MHz）

| 待ち方 | 密なループ | 間に 20µs 以上の仕事があるとき |
| --- | --- | --- |
| 固定 25µs（現状） | 32.00 µs | 32.00 µs |
| 固定 18µs | 25.01 µs | 25.01 µs |
| BUSY ポーリング | 25.00 µs | 25.00 µs |
| 固定 25µs + 繰り延べ | 32.01 µs | **7.00 µs** |
| 固定 18µs + 繰り延べ | 25.01 µs | **7.00 µs** |
| BUSY ポーリング + 繰り延べ | 25.61 µs | 9.00 µs |

「繰り延べ」はデータサイクル後に待たずに戻り、次にバスを触る直前で待ちを消化する方式
（参照実装 MXDRV の `L_WRITEOPM` と同じ構造）。7.00µs は待ちを全部他の仕事に吸収させても
残る部分で、`t_WR`(1) + `t_ADDR`(5) + `t_WR`(1) にあたる。

## 結論の根拠

### 1. BUSY の長さ — φM を振って傾きから求める

ステータスの読み出しには時間がかかるので、「書き込みから d だけ待って読む」を掃引しても
得られる境界は `d = T_busy − offset` であって、`offset`（読み出しがバスをサンプルする
までの時間）が分からないと `T_busy` が出ない。

**sys_clk を 144MHz に固定したまま φM だけを 1.2〜3.6MHz で振ると、`offset` は変わらずに
`T_busy` だけが 1/φM に比例して伸びる。** 境界 `d` を 1/φM の 1 次式として最小二乗すると、
傾きが BUSY の φM サイクル数、切片が `−offset` になる。

2 回の掃引（計 12 点、[result/scale-phim.tsv](result/scale-phim.tsv) と
[result/scale-phim-run1.tsv](result/scale-phim-run1.tsv)）の結合フィット:

```
  N       = 67.14 ± 0.15 φM サイクル
  offset  = 1065 ns
  残差 RMS = 104 ns
```

立ち上がり側も同じ方法で 9 点をフィットして **2.92 サイクル**（残差 RMS 186ns）。

### 2. 測定系の妥当性

これは YM2151 の仕様ではなく、上のフィットが信用できることの確認。

- **フィットで出た `offset` 1065ns は、読み出し経路から計算した値と一致する。**
  掃引用のステータス読みは「D0-D7 を入力へ倒す → A0/`/CS` を確定 → `t_SETUP`(104ns) →
  `/RD` を L → `t_RD`(1000ns) → サンプル」なので約 1.15µs。独立に求めた 2 つの値が
  合うので、傾きの側も信用してよい。
- **ポーリング 1 回の所要時間を直接測ると 1.003µs**（[result/variants.txt](result/variants.txt)）で、
  `t_SETUP` + `t_RD` + GPIO 操作という内訳と合う。
- φM=4MHz での掃引は**遷移が 1 掃引ステップ（125ns）で切り替わり、32 回の試行で
  ばらつきがゼロ**（[result/sweep-4.000MHz.tsv](result/sweep-4.000MHz.tsv)）。φM は sys_clk の
  整数分周なので、バス操作と φM の位相関係が試行ごとに変わらないため。
  φM が 1µs（タイマの刻み）と整合しない値では位相がばらけ、遷移が数百 ns の帯になる。

初期の掃引は `opm_read()` をそのまま使っていたため、内部の `busy_wait_us_32(1)` が
タイマ境界へ丸めてサンプル時刻が 1µs 単位に量子化されていた。掃引用の読み出しだけ
サイクル基準の待ちに差し替えて分解能を回復させてある（[§解析方法](#解析方法)）。

### 3. レジスタにもチップの状態にも依存しない

代表 12 レジスタで境界を測った結果（[result/regs.tsv](result/regs.tsv)、φM=4MHz、各 32 回）:

| レジスタ | 0x01 | 0x08 | 0x0f | 0x12 | 0x14 | 0x18 | 0x1b | 0x20 | 0x28 | 0x38 | 0x60 | 0xe0 |
| --- | --- | --- | --- | --- | --- | --- | --- | --- | --- | --- | --- | --- |
| 境界 (ns) | 15550 | 15562 | 15558 | 15558 | 15554 | 15546 | 15562 | 15550 | 15546 | 15562 | 15554 | 15562 |

**ばらつきは 16ns**（掃引ステップ 125ns より小さい）。キーオン (0x08)・タイマ (0x12)・
LFO (0x18)・TL (0x60)・RR (0xE0) のどれも同じ。

8ch を発音させた状態（全スロット AR=31 / RR=0 でキーオンし、音を出したまま）で測っても
境界は 15546ns で変わらない（[result/sweep-sounding.tsv](result/sweep-sounding.tsv)）。

**この一様性が採否の分かれ目になる。** BUSY 長が状況で変わるならポーリングでしか
追従できないが、一定なら φM から待ち時間を計算するだけで同じ結果が得られる。

### 4. アドレスサイクルは BUSY を立てない

アドレスサイクル (A0=0) だけを行って掃引すると、**0〜30µs の 241 点すべてで 32 回とも
BUSY=0**（[result/sweep-addr-cycle.tsv](result/sweep-addr-cycle.tsv)）。

`OPM_T_ADDR_US`（5µs）は BUSY とは無関係な仮置きの値なので、BUSY ポーリングを入れても
ここは 1ns も縮まない。逆に言えば、ここを詰める作業は BUSY とは独立にできる。

### 5. 書き込みが化けていないことの確認

YM2151 のレジスタは読み戻せないので、待ちを詰めた結果として書き込みが化けても直接は
見えない。**タイマ A の周期は書き込んだ CLKA そのもの**（`64 × (1024 − CLKA) / φM`）
なので、これをレジスタの読み戻しとして使う。

CLKA を 896〜1007（周期 256µs〜2048µs）で 2048 回振り、毎回 `0x10` / `0x11` / `0x14` ×2 を
書いてから周期を測り、期待値との差の最大を見る。

| 構成 | 最大誤差 |
| --- | --- |
| 現状（固定 25µs） | 22 µs |
| 固定 18µs | 10 µs |
| BUSY ポーリング | 8 µs |
| 固定 18µs + 繰り延べ | 14 µs |
| BUSY ポーリング + 繰り延べ | 20 µs |
| 固定 18µs（φM=3.579545MHz） | 13 µs |

タイマ A は 64 φM サイクル（φM=4MHz で 16µs）刻みで動くので、**測定のノイズ床が 16µs** ある。
どの構成もその範囲に収まっており、書き込みが落ちたり化けたりした形跡はない。
参考までに、待ちを異常に詰めると誤差が 1000µs 台に跳ね上がって明確に区別できる
（[§詳細](#t_data-を詰めたときの破綻点)）。

## 解析方法

### 測定の原理

BUSY をポーリングして測ると、ポーリング自身のバス操作（`/CS` と `/RD` のトグル）が
測定対象を乱す。そこで **遅延を振って 1 回だけ読む** 方式にした。

```
1 点の測定:
  100µs 待って OPM をアイドルにする
  アドレスサイクル → t_ADDR → データサイクル
  busy_wait_at_least_cycles(d)      ← d を 125ns 刻みで振る
  ステータスを 1 回だけ読んで bit7 を記録
これを 32 回（φM 掃引では 64 回）繰り返し、BUSY=1 だった回数を数える
```

境界の期待値は `E[b] = Σ P(BUSY=1 at d) × Δ` で求める（`Δ` = 125ns）。立ち上がりと
立ち下がりを分けて積算するので、位相がばらけて遷移が帯になっても平均が取れる。

掃引用のステータス読みは `opm_read()` と同じバス操作をするが、`t_RD` の待ちだけ
`busy_wait_us_32()` ではなく `busy_wait_at_least_cycles()` にしてある。
`busy_wait_us_32(1)` は 1µs のタイマ境界へ丸めるので、そのままだとサンプル時刻が
1µs 単位に量子化されて 125ns の掃引ステップが無意味になる。

### 診断コマンド

`-DOPM_DIAG=1` でのみリンクされる `busy` コマンドを一時的に足して測った。
実装は [diag.patch](diag.patch)、使い方は[付録](#付録)。**本体には残していない。**

`opm_write()` の待ち方は 2 つのビルドスイッチで切り替えられるようにした。

| スイッチ | 内容 |
| --- | --- |
| `OPM_BUSY_POLL` | 待ちの中身を固定ウェイトから BUSY ポーリングへ |
| `OPM_BUSY_DEFER` | 待つ位置を「書き込み後」から「次にバスを触る直前」へ |
| `OPM_T_DATA_US` | `opm.h` の `t_DATA` を上書き |

### 測定の限界

- **BUSY のアサートを φM=4MHz で直接は観測できない。** ステータスを最も早くサンプル
  できるのは書き込みの 1065ns 後（読み出し経路の所要時間）で、アサートの推定値
  730ns はそれより手前にある。アサート時刻は φM を下げた測定からの外挿。
- **書き込みの健全性はタイマ A 経由でしか見ていない。** 直接検証したのは
  レジスタ `0x10` / `0x11` / `0x14` だけ。分解能はタイマ A の刻み 16µs。
- 測ったのは**この 1 個体・この温度・この電源**だけ。

## 詳細な解析結果

### BUSY 消滅時刻の掃引

φM=4MHz（[result/sweep-4.000MHz.tsv](result/sweep-4.000MHz.tsv)）:

```
delay_ns  busy/32
  15375     32
  15500     32     ← 全試行で BUSY
  15625      0     ← 全試行でクリア
  15750      0
```

φM=3.579545MHz（[result/sweep-3.579MHz.tsv](result/sweep-3.579MHz.tsv)）では位相が
ばらけるので 17500〜17875ns が遷移帯になり、期待値は 17757ns。

### φM 依存性

[result/scale-phim.tsv](result/scale-phim.tsv)（sys_clk=144MHz 固定、各 64 回）:

| φM (Hz) | 立ち上がり (ns) | 立ち下がり (ns) |
| --- | --- | --- |
| 3600000 | 0 | 17630 |
| 3000000 | 248 | 21406 |
| 2400000 | 156 | 26851 |
| 1800000 | 726 | 36159 |
| 1440000 | 1078 | 45574 |
| 1200000 | 1439 | 54731 |

立ち上がり側の 3.6MHz / 3.0MHz は、アサートがサンプル可能な最速時刻より手前にあるため
0 に張り付く（打ち切られた観測なのでフィットからは除いた）。

φM=1.0MHz と 2.0MHz は**意図的に使っていない**。φM の周期がタイマの刻み 1µs の整数倍に
なると位相が固定され、試行ごとにばらけなくなって「32 回中 16 回」のような二値的な結果に
なる。最初の掃引でこれを踏んだ。

### レジスタ依存性

[§3](#3-レジスタにもチップの状態にも依存しない) の表のとおり。

### 待ち方ごとのベンチマーク

`opm_write(0x60, 0x7f)` を 2000 回繰り返し、書き込みの間に `work_us` の空回しを挟んで
1 回あたりの時間を測った（[result/variants.txt](result/variants.txt)、φM=4MHz）。
`write_ns` は 1 回あたりから空回しぶんを引いた値。

| work_us | 現状 | 固定18µs | ポーリング | 繰り延べ | 18µs+繰り延べ | ポーリング+繰り延べ |
| --- | --- | --- | --- | --- | --- | --- |
| 0 | 32004 | 25006 | 25004 | 32005 | 25005 | 25606 |
| 2 | 32003 | 25002 | 25003 | 30000 | 23002 | 23574 |
| 5 | 32003 | 25003 | 25003 | 27000 | 20001 | 20336 |
| 10 | 32002 | 25002 | 25002 | 22000 | 15000 | 15572 |
| 15 | 32003 | 25003 | 25001 | 17000 | 10000 | 11001 |
| 20 | 32002 | 25002 | 25002 | 12001 | **7003** | 9002 |
| 30 | 32002 | 25002 | 25002 | **7003** | **7003** | 9002 |
| 50 | 32002 | 25001 | 25001 | **7002** | **7003** | 9003 |

読み取れること:

- **BUSY ポーリングと「φM から計算した固定 18µs」は同値**（25.004 と 25.006）。
  ポーリング回数の最大は 15 回で、タイムアウトは 1 度も起きていない。
- **繰り延べは、間に挟まる仕事が待ち時間を超えるまで線形に効く。** 超えたところで
  非吸収コアの 7.00µs に張り付く。
- **ポーリングは繰り延べと組むと固定ウェイトより 2µs 損をする**（9.00 対 7.00）。
  BUSY が既に明けていても、アサート遅延を踏まないための下限待ちと 1 回の読み出しを
  必ず通るため。密なループでも 25.61 対 25.01 でわずかに遅い。

### 実再生での効果

`DRACULA/dra05.mdx`（MDX ファイルのうち最も `mdx_service()` が重い曲）を再生し、
`-DSTATS_PROFILE=1` で 20 秒ぶんの統計を取った（[result/playback.txt](result/playback.txt)）。

| 構成 | `mdx` 滞在時間 | CPU | I2S 最小 | UNDERRUN / E0 / RXSTALL / OVERRUN | SEQ LAG |
| --- | --- | --- | --- | --- | --- |
| 現状 | 49026 µs/s | 40% | 854/1024 | 0 / 0 / 0 / 0 | 171 µs |
| 固定 18µs | 41788 µs/s | 40% | 872/1024 | 0 / 0 / 0 / 0 | 125 µs |
| BUSY ポーリング | 44057 µs/s | 40% | 869/1024 | 0 / 0 / 0 / 0 | 125 µs |
| 固定 18µs + 繰り延べ | 38778 µs/s | 40% | 873/1024 | 0 / 0 / 0 / 0 | 177 µs |

- 現状と固定 18µs の差 7238µs/s を 1 回あたりの短縮 7µs で割ると、**この曲は毎秒
  約 1030 回レジスタを書いている**。
- **`mdx` の滞在時間は 21% 減るが、CPU 使用率は 40% のまま変わらない。** 浮いた時間は
  メインループの空転に回るだけで、他のサービスの数字も動かない。
- **`SEQ LAG` に系統的な差は出ない。** 125〜177µs のばらつきは同じ構成でも同程度に出る。
- **ポーリングでもキャプチャ系の統計は悪化しない。** `E=0`（YM3012 の禁止コード）・
  `RXSTALL`・`OVERRUN`・I2S アンダーランはすべて 0 のまま。
  この曲の書き込みレートでは `/RD` のトグルは毎秒 15000 回ほどで、
  D0-D7 が 5V を受けている時間の割合は 1.6% にとどまる。

なお `SEQ LAG` は README §8.2 が挙げる 700µs ではなく 74〜177µs だった。手元の MDX を
一通り再生した範囲ではこの程度で、`snd_voice()`（24 書き込み = 772µs）が単独で
`MDX_BUDGET_US` を超えても、`reslip` が出るほどの遅れにはなっていない。

### `t_DATA` を詰めたときの破綻点

`t_DATA` を変えて[§5](#5-書き込みが化けていないことの確認)の検証を回した結果:

| `t_DATA` | 25 | 20 | 18 | 17 | 16 | 15 | 14 | 12 | 11 | 10 | 9 | 8 | 6 | **4** | **2** |
| --- | --- | --- | --- | --- | --- | --- | --- | --- | --- | --- | --- | --- | --- | --- | --- |
| 最大誤差 (µs) | 21 | 16 | 8 | 6 | 12 | 12 | 8 | 4 | 8 | 8 | 4 | 9 | 12 | **1092** | **1096** |

破綻するのは 4µs 以下。BUSY が明けるのは 16.8µs 後なのに 6µs でも通るのは、
**連続する 2 回のデータサイクルの間隔が `t_DATA` + 約 7µs** になるから
（データサイクルのあと次の書き込みのアドレスサイクルと `t_ADDR` が挟まる）。
6 + 7 = 13µs で、これでも BUSY 期間より短い。

**BUSY より短い間隔でも書き込みが通ることは、この個体でそう観測されたというだけで
仕様ではない。** 待ち時間を決める根拠には使えない。

### 音の突き合わせ

同じ曲を現状と「固定 18µs + 繰り延べ」で再生し、CDC #1 から 4 秒ぶんの PCM を取って
100ms ブロックごとに整列して比較した（[pcmcap.py](pcmcap.py) / [pcmcmp.py](pcmcmp.py)）。

| 比較 | 包絡線の差 | ブロックのずれ |
| --- | --- | --- |
| 現状 vs 現状（同一ビルドを 2 回） | −44.4 dB | −5〜0 サンプル |
| 現状 vs 固定18µs+繰り延べ | −31.0 dB | −70〜−45 サンプル |

**この比較では書き込みの健全性は判定できなかった。** 書き込みが速くなるとシーケンサが
早く追いつくため曲全体が約 1ms 前へずれ、そのずれ自体が残差になる。同一ビルドでも
−44.4 dB までしか一致しないので、−31.0 dB との差を「音が変わった」根拠にはできない。
書き込みの健全性は[§5](#5-書き込みが化けていないことの確認)のタイマ A による検証で見ている。

## 考察

### 選択肢

待ち方は独立した 2 つの軸に分かれる。

**軸 1: 待ちの長さ**

| 案 | 内容 | 1 write |
| --- | --- | --- |
| A | 現状（固定 25µs） | 32.0 µs |
| B | `t_DATA` を φM から実行時算出（`s_setup_cycles` と同じやり方） | 25.0 µs |
| C | BUSY をポーリング | 25.0 µs |

**軸 2: 待ちの位置**

| 案 | 内容 | 非吸収コア |
| --- | --- | --- |
| — | 現状（書き込み後にその場で待つ） | — |
| E | 次にバスを触る直前へ繰り延べる | 7.0 µs |

**軸 3: BUSY と無関係**

- D: `t_ADDR`(5µs) / `t_WR`(1µs) を詰める。合わせて 7µs あり、**案 B/C の削減幅
  7µs と同じオーダー**。今回は測っていない。

### 案 C（BUSY ポーリング）を採る理由が無い

ポーリングの唯一の理論的な利点は「BUSY 長が状況によって変わる場合の追従性」だが、
[§3](#3-レジスタにもチップの状態にも依存しない)のとおり **BUSY 長は完全に一定**だった。
その結果、実測では案 B と案 C が同値になり、繰り延べと組むと案 C のほうが 2µs 遅い。

対価は小さくない。

- **チップ不在時に無限ループする。** A0=1 の読みは OPM が居なければ直前に Pico が
  駆動した値を返すので、bit7 が立つ値を書いた直後（`opm_clear()` の `0x19`←`0x80` など）は
  永久に BUSY に見える。タイムアウトと `stats` のカウンタが必須になる。
- **アサート遅延を踏むと書き込みが黙って化ける。** BUSY が立つのは 0.73µs 後、
  最も早くサンプルできるのが 1.065µs 後で、**余裕は 0.33µs（1.3 φM サイクル）しかない**。
  `t_RD` を詰めるなど読み出しを速くする変更が、そのままこの余裕を削る。
  今回の試作では「データサイクルから最低 2µs 空けてから読み始める」で回避した。
- **D0-D7 が 5V を受ける時間が増える。** 連続書き込み時は 25µs のうち 15µs（60%）。
  実再生では 1.6% にとどまり、実測でもキャプチャ系の統計は悪化しなかった。
  ただし採用するなら README §1.3 の「A2 の個体で**読み出しを使う場合は** D0-D7 にも
  レベル変換器か分圧が要る」という条件付きの注意は**無条件**に書き換わる。
- バスの方向切り替えが毎秒 2000 回程度から増える。

**案 B なら、これらの対価をひとつも払わずに同じ 7µs が手に入る。**

### 案 E（繰り延べ）が効く場所と効かない場所

繰り延べは待ちを他の仕事に吸収させるので、**平均は下がるが最悪は下がらない**。

- 効く: サービス関数の末尾の 1 回（戻った先でメインループが `tud_task()` /
  `i2s_service()` / `capture_service()` / `pcm8_service()` を回す）、MDX の tick 処理で
  次チャンネルの MML 解釈と重なるぶん。実測で `mdx` 滞在時間がさらに 3.0ms/s 減った。
- 効かない: `opm_clear()`（87 回）・`key_off_all()`（40 回）・`snd_voice()`（24 回）の
  密なループ。ここには重ねる仕事が無いので 1 回あたり 25µs のまま。
  **I2S アンダーランと `SEQ LAG` を決めるのはこちらなので、最悪ケースは改善しない。**

新たに増える制約もある。`opm_write()` がチップの BUSY 中に戻るので、**φM を止める /
張り替える前（`clockmode.c` の分周比の張り替えは SM を一瞬止める）と `opm_reset()` の前に
未消化の待ちを消化する**必要がある。φM が止まると BUSY が明けないまま書き込みが化ける。
期限の比較は `time_us_32()` の 71.6 分のラップを跨ぐので符号付き差分で行う。

### 効果の大きさ

案 B + E で `mdx_service()` の滞在時間は 49.0 → 38.8ms/s（−21%）になる。
ただし **CPU 使用率は 40% のまま動かず、I2S の先行量にも `SEQ LAG` にも
キャプチャ系の統計にも差は出ない。** 現状でアンダーランもオーバーランも
`reslip` も 0 で、余裕が十分あるため。

つまりこれは**動いていない何かを直す変更ではなく、余裕を積み増す変更**である。

### 結論

- **案 C（BUSY ポーリング）は採るべきでない。** 効果は案 B と同じで、副作用だけが増える。
  BUSY 長が一定であることが実測で確定した以上、ポーリングの存在理由が無い。
- **案 B（`t_DATA` を φM から実行時算出）は、採るなら最も割が良い。** 副作用が無く、
  `s_setup_cycles` と同じ「クロック依存の値は実行時に算出する」という既存の方針に乗る。
  φM を下げる将来のプリセットに対しても、固定 25µs より正しく追従する。
  値は `ceil(68 / φM[MHz]) + 1` 程度（4MHz で 18µs、3.579545MHz で 20µs）。
- **案 E（繰り延べ）は効果に対して制約が多い。** 平均しか下がらず、最悪ケースは変わらず、
  φM 切り替えと `/IC` リセットに新しい前提条件が付く。参照実装と構造が揃うという
  副次的な利点はある。
- **案 D（`t_ADDR` / `t_WR` を詰める）は未調査だが、案 B と同じオーダーの削減幅がある。**
  詰めるなら先にこちらを測るべき。今回の掃引と検証の枠組みがそのまま使える。
- どれも**現状で困っている症状を解消するものではない**。

## 不明点・未解決事項

- **BUSY が 67 サイクルなのか 68 サイクルなのか決着していない。** フィットの統計誤差は
  ±0.15 サイクルだが残差 RMS が 104ns（0.37 サイクル相当）あり、系統誤差が残っている。
  読み出しオフセットの推定と分離できていない。
- **BUSY のアサート遅延 2.92 サイクルは外挿値。** φM=4MHz では読み出しが間に合わず
  直接観測できていない。残差 RMS も 186ns と大きく、有効な点が 9 個しかない。
- **1 個体しか測っていない。** BUSY 長の個体差・ロット差・温度依存・電源電圧依存は未確認。
  README §1.3 が入力 H レベルについて書いているのと同じ不確かさがここにもある。
- **書き込みの健全性を直接検証したのはレジスタ `0x10` / `0x11` / `0x14` だけ。**
  BUSY 長がレジスタに依存しないことから他のレジスタも同じと考えられるが、
  「BUSY が明けていれば書き込みは確定している」ことそのものは検証していない。
- **`t_ADDR` と `t_WR` の最小値は測っていない。** 今回の対象外。
- **音による回帰確認ができていない。** 書き込みが速くなると曲全体が前へずれるため、
  波形の突き合わせがずれに埋もれる。

## 今後の課題

- **67 と 68 を区別する。** 読み出しオフセットを独立に決めれば分離できる。
  診断コード内で GPIO を 1 本トグルして「データサイクルの `/WR` 立ち上がり」と
  「ステータスをサンプルした瞬間」を出し、ロジックアナライザで直接測る。
  あるいは φM をさらに下げて（0.6MHz など）てこ比を倍にする。ただし YM2151 の
  下限クロックを外れるので、その領域で BUSY の線形性が保たれるかの確認が要る。
- **アサート遅延を φM=4MHz で直接観測する。** 掃引用のステータス読みから `t_RD` を
  削り（サイクル基準で 200ns 程度まで）、サンプル時刻を 0.3µs 前へずらす。
  読み出しが成立する最小の `t_RD` を先に掃引で決める必要がある。
- **`t_ADDR` / `t_WR` の最小値を決める。** `OPM_T_ADDR_US` / `OPM_T_WR_US` を振りながら
  [§5](#5-書き込みが化けていないことの確認) の検証を回し、誤差が跳ね上がる点を探す。
  `t_DATA` で同じことをやったときは 4µs で明確に破綻したので、同じ手順がそのまま使える。
  そのうえで、BUSY と無関係に得られる削減幅を案 B と比べる。
- **別個体で `busy scale` を回す。** BUSY 長が個体に依らないなら、φM から算出する
  案 B の前提が固まる。依存するなら案 C を採る理由が復活する。
- **書き込みの健全性の検証を全レジスタへ広げる。** タイマ A 以外に読み戻せるものが
  無いので、DAC 出力を使う（TL を振って出力レベルを測る、KC を振って周波数を測る）
  経路を作る。`test/lfo_noise/` のキャプチャ環境がそのまま使える。

## 付録

### 診断コマンド

`-DOPM_DIAG=1` でビルドしたときだけ `busy` コマンドがリンクされる。
[diag.patch](diag.patch) を当てて再コンフィグする。

```bash
git apply test/opm_busy/diag.patch
cmake -S . -B build -G Ninja -DCMAKE_BUILD_TYPE=Release -DPICO_BOARD=pico2 -DOPM_DIAG=1
```

| サブコマンド | 内容 |
| --- | --- |
| `busy sweep [addr] [data] [max_ns]` | BUSY 消滅時刻の掃引。TSV（`delay_ns` / `busy` / `reps`）を出し、末尾に境界と期待値 |
| `busy addr [addr] [max_ns]` | アドレスサイクル (A0=0) だけで同じ掃引 |
| `busy regs` | 代表 12 レジスタの境界を総なめ |
| `busy scale` | φM を 1.2〜3.6MHz で振って境界を測る（sys_clk は動かさない）。最後に φM を戻す |
| `busy phim <hz>` | φM だけを指定値へ張り替える |
| `busy read` | `opm_read()` と `opm_read_once()` の 1 回あたりの所要時間 |
| `busy bench` | 空回しを挟みながら 1 write あたりの時間を測る |
| `busy verify [n]` | タイマ A の周期で書き込みが化けていないことを検証 |
| `busy stat` | ポーリングのタイムアウト回数と最大ポーリング回数 |

ビルドスイッチ:

| 変数 | 既定 | 内容 |
| --- | --- | --- |
| `OPM_DIAG` | 0 | `busy` コマンドをリンクする |
| `OPM_BUSY_POLL` | 0 | 待ちを BUSY ポーリングにする |
| `OPM_BUSY_DEFER` | 0 | 待ちを次のバスアクセス直前へ繰り延べる |
| `OPM_T_DATA_US` | 空 | `opm.h` の `t_DATA` を上書き |

**長い掃引の間は `tud_task()` を回さないとホストが USB を切断する。**
`diag_sweep()` が 1 点ごとに呼んでいる。

### ホスト側スクリプト

この Mac には `timeout` も pyserial も無いので、いずれも python3 標準ライブラリだけで
書いてある（`os.open` の `O_NONBLOCK` + `select`）。

| スクリプト | 内容 |
| --- | --- |
| [opmcmd.py](opmcmd.py) | CDC #0 へコマンドを送り、`OK` / `ERR` の行が出るまで読む |
| [playmeas.py](playmeas.py) | 曲を再生し、統計をリセットしてから 20 秒走らせて `s` を読む |
| [pcmcap.py](pcmcap.py) | CDC #1 から PCM を取り込む（CDC #1 を開いてから `p 1` を送る） |
| [pcmcmp.py](pcmcmp.py) | 2 本のキャプチャを 100ms ブロックごとに整列して突き合わせる |

### 再現手順

```bash
# 掃引（φM=4MHz）
python3 test/opm_busy/opmcmd.py "clock fixed" "clock 4" "busy sweep 60 7f" > sweep.tsv

# φM を振って BUSY のサイクル数を出す
python3 test/opm_busy/opmcmd.py "busy scale"

# レジスタ依存性
python3 test/opm_busy/opmcmd.py "busy regs"

# 待ち方ごとのベンチと書き込みの検証（ビルドを変えて繰り返す）
python3 test/opm_busy/opmcmd.py "busy bench" "busy verify 2048" "busy stat"

# 実再生での効果（-DSTATS_PROFILE=1 でビルドしておく）
python3 test/opm_busy/playmeas.py DRACULA/dra05.mdx
```

### 一次データ

| ファイル | 内容 |
| --- | --- |
| [result/sweep-4.000MHz.tsv](result/sweep-4.000MHz.tsv) | φM=4MHz の掃引 |
| [result/sweep-3.579MHz.tsv](result/sweep-3.579MHz.tsv) | φM=3.579545MHz の掃引 |
| [result/sweep-addr-cycle.tsv](result/sweep-addr-cycle.tsv) | アドレスサイクルだけの掃引 |
| [result/sweep-sounding.tsv](result/sweep-sounding.tsv) | 8ch 発音中の掃引 |
| [result/scale-phim.tsv](result/scale-phim.tsv) / [result/scale-phim-run1.tsv](result/scale-phim-run1.tsv) | φM を振った測定（2 回） |
| [result/regs.tsv](result/regs.tsv) | 代表 12 レジスタ |
| [result/variants.txt](result/variants.txt) | 6 構成のベンチと書き込み検証 |
| [result/playback.txt](result/playback.txt) | 4 構成の実再生統計 |

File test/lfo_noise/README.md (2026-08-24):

# YM2151 LFO ノイズ波形の調査

YM2151 の LFO は周波数を `LFRQ`（レジスタ `0x18`）1 バイトで指定するが、この値と実際の
LFO の速さの関係はデータシートに数値表として載っていない。さらに LFO 波形をノイズ
（`W=3`、レジスタ `0x1B`）にすると LFO の値がノイズ発生器から供給されるため、
**ノイズ周波数 `NFRQ`（レジスタ `0x0F` の下位 5bit）が LFO の挙動に関与するのか**もはっきり
しない。実機の DAC 出力をキャプチャして、この 2 点を実測で決める（測定系は
[§4.2](#42-測定系)）。

**本調査のデータは大半が `W=3`（ノイズ）固定で、以下の結論は断りがなければ W=3 についてのもの。**
ただし**更新周期の規則は W=0（鋸）/ W=2（三角）でも成り立つことを実測してある**（[§5.7](#57-w0--w2-でも更新間隔は上位ニブルだけで決まる)）。
**矩形 (`W=1`) は本調査のスコープ外**で、一次データを残すだけで解析しない（[§4.11](#411-調べていないこと-w1-矩形)）。

このドキュメントでは、**実測**（このディレクトリのデータで確かめたこと。根拠の置き場を
併記する）、**推測**（実測から導いた説明。「〜と考えられる」と書く）、**未確認**（このデータ
では決まらないこと）を書き分ける。数値の根拠はすべて `result/` にある
（[§4.5](#45-解析と集計の手順) / [§4.6](#46-段ごとの-lfo-値を取り出す解析)）。

`NFRQ` は本掃引 `wav/` では `0x00` と `0x1f` の 2 値しか振っていないが、**専用の掃引
`wav_nfrq/` `wav_nfrq_5a09/` `wav_lfrq28_nfrq/` で全 32 値を押さえてある**
（[§4.4](#44-データセット) / [§5.4](#54-nfrq-を全-32-値振る) / [§5.5.3](#553-nfrq-を全-32-値振ると-0x1f-だけが立つ)）。

## 1. 解析結果の要約

| 項目 | 結論 | 根拠 |
| --- | --- | --- |
| `LFRQ` 上位ニブルと LFO 更新周期の関係 | 更新周期 = `2^(18 - (LFRQ >> 4))` samples。1 増えるごとに半分。**上位ニブル `f`（8 samples）も含めて例外は無い** | [§3](#3-結論の根拠) `[B]`（896 条件、実測/モデル 0.9998〜1.0006）/ `[J]`（`f` 帯で 8 サンプルごとのラッチを直接確認）/ 実測波形は [§2.1](#21-更新周期は-lfrq-の上位ニブルだけで決まる) の図 2 |
| `LFRQ` 下位ニブルと LFO 更新周期の関係 | 更新周期には効かない（値を振っても変わらない） | [§3](#3-結論の根拠) `[B]`（最大/最小 ≤ 1.0067。想定モデルどおりなら 1.9375）/ 実測波形は [§2.1](#21-更新周期は-lfrq-の上位ニブルだけで決まる) の図 1 |
| `LFRQ` 下位ニブルと LFO 値列の関係 | 値列も変えない。**下位ニブル 16 値すべて**が同じ値列を出す | [§3](#3-結論の根拠) `[K]`（`a0` と `af` の値列が真の一致 100%。偶然なら 10%）/ `[P]`（16 値 × 3 セッションの 48 本で、値列がどの組になるかが下位ニブルと無関係） |
| `LFRQ` 下位ニブルと 1 回の更新で進む歩幅の関係 | 歩幅 = `(16 + (LFRQ & 0x0f)) / 16`。1 LFO 周期あたりの段数は `4096 / (16 + (LFRQ & 0x0f))` で、上位ニブルには依らない | [§3](#3-結論の根拠) `[R]`（W=0 の 128 条件すべてで段数が予測と 1 段以内） |
| ハードウェアリセットとノイズ列の関係 | リセット後のノイズ列は決定的で、別々のキャプチャで同じ列が出る | [§3](#3-結論の根拠) `[K]`（別セッションの 2 本が真の一致 100%） |
| `LFRQ` 下位ニブルと更新周期の関係（W=0 / W=2） | ノイズ以外の波形でも更新周期を変えない。規則 `2^(18 - (LFRQ >> 4))` は W=3 固有ではない | [§3](#3-結論の根拠) `[N]`（鋸・三角の AM で判別できる 150 条件すべてが一致。ymfm モデルは 0 条件） |
| `NFRQ` とノイズ語の更新周期の関係 | ノイズ発生器が新しい語を出す周期 = `(32 - NFRQ) / 2` samples | [§3](#3-結論の根拠) `[J]`（`NFRQ=0x00`〜`0x0c` を搬送波 2 種 × AM/PM の 4 系列で実測。実測/予測 0.99〜1.02。PM は `0x0f` まで）。`0x1e` までの全域は [test/noise_period/](../noise_period/README.md) |
| `LFRQ` 上位ニブルと「値が 2 段ずつ対になる」現象の関係 | 上位ニブル `2` でだけ起きる。同じ下位ニブル `8` の `0x18`（hi=1）/ `0x38`（hi=3）では起きない | [§5.5.6](#556-hi2-の帯を-nfrq0x1f-で当てると対にならない)（推定周期は 8 本とも規則どおり、段境界の変化率も 8 マス平坦） |
| `NFRQ` と「値が 1 段おきにしか変わらない」現象の関係 | `NFRQ=0x1f` でだけ起きる。`0x00`〜`0x1e` の 31 値は平坦で、傾斜も中間の値も無い | [§3](#3-結論の根拠) `[O]`（`LFRQ=0x28` × `NFRQ` 全 32 値 × AM/PM。弱い側のパリティが `0x1f` だけ AM 30% / PM 0%、他の 31 値は 79〜100%） |
| `LFRQ` 下位ニブルと「値が 2 段ずつ対になる」強さの関係 | 対になる段境界の割合は `min(lo, 16-lo)/16` で、`0x28` を頂点とする**対称な山**。どちらのパリティに寄るかは `0x27` と `0x28` のあいだで反転する | [§5.5.5](#555-下位ニブル-16-値で山とパリティの反転位置を突き合わせる)（下位ニブル全 16 値。PM の残差 RMS 5.5 pt に対し、対称でない単調モデルは 32.5 pt） |

## 2. 判明した仕様

### 2.1 更新周期は `LFRQ` の上位ニブルだけで決まる

    更新周期 = 2^22 / (16 << (LFRQ >> 4)) = 2^(18 - (LFRQ >> 4))  [samples]

**`LFRQ & 0x0f` は無視される。** fs = 62500Hz（φM / 64）。

Low nibble of LFRQ does not change the step width

上位ニブルを `d` に固定し、下位ニブルだけを `0` / `4` / `8` / `c` / `f` と振ったときの実測波形
（AM 測定 / L チャネル）。灰色が**キャプチャした生のサンプルそのもの**（線形の振幅）、
青が段ごとの搬送波レベル [dB]（取り出しは [§4.6](#46-段ごとの-lfo-値を取り出す解析) と同じ）。
**5 本とも搬送波のレベルが跳ぶ位置が同じ 32 サンプル格子に乗る。** レベルの値そのものが
5 本で違うのは、キャプチャごとに LFO リセットからの開始位置が違って別の区間を切り出して
いるため（値列まで一致することは [§2.3](#23-下位ニブルは値列も変えない) で別に示す）。

搬送波（`KC` / `MUL`）は `LFRQ` の帯ごとに掃引スクリプトが選ぶので、下位ニブルによって
2 種類が混ざる（[付録 B.4](#b4-kc--mul-の選び方)）。**それでも段の幅は変わらない。**
図の生成とパネルごとの波形の出どころは [§4.5 図の生成](#図の生成)。

**この式は W=3 固有ではない。** W=0（鋸）/ W=2（三角）でも同じ規則が成り立つことを
実測してある（[§5.7](#57-w0--w2-でも更新間隔は上位ニブルだけで決まる)）。下位ニブルが変えるのは更新の間隔ではなく、
**1 回の更新で LFO 値が進む量（歩幅）**である。

LFO の値が変わりうるのは、この周期おきに来る瞬間だけ。実測した更新イベントの間隔は
必ず更新周期の整数倍になり、中途半端な間隔は 1 つも出ない
（[§5.5](#55-lfrq0x28-の異常を段数-10-倍でキャプチャし直す)）。間隔が 2 倍・3 倍になる回が
あるのは、その瞬間に値がたまたま変わらず、更新が見えなかったため。

したがって次の 2 つは別の話で、本調査ではこれを分けて扱う。

| | 何が決めるか |
| --- | --- |
| **更新周期そのもの**（何サンプルおきに更新の瞬間が来るか） | `LFRQ` の上位ニブルだけ（[§3](#3-結論の根拠) `[B]`） |
| **その瞬間に値が実際に変わるかどうか** | 主にノイズ語の更新周期 `P_n`（[§2.2](#22-lfo-値が変わる間隔はノイズ語の更新周期との合成で決まる)）。加えて、`NFRQ=0x1f` かつ上位ニブル `2` の帯では `LFRQ` の下位ニブルも効く（[§2.4](#24-nfrq0x1f-かつ上位ニブル-2-では値が-2-段ずつ対になる)） |

| LFRQ 上位ニブル | 実測の更新周期 [samples] | `2^(18-上位ニブル)` |
| --- | --- | --- |
| `0` | 262144 | 262144 |
| `1` | 131072 | 131072 |
| `2` | 65536 | 65536 |
| `3` | 32768 | 32768 |
| `4` | 16384 | 16384 |
| `5` | 8192 | 8192 |
| `6` | 4096 | 4096 |
| `7` | 2048 | 2048 |
| `8` | 1024 | 1024 |
| `9` | 512 | 512 |
| `a` | 256 | 256 |
| `b` | 128 | 128 |
| `c` | 64 | 64 |
| `d` | 32 | 32 |
| `e` | 16 | 16 |
| `f` | 8 | 8 |

Raising the high nibble of LFRQ by one halves the step width

下位ニブルを `0` に固定して上位ニブルを `b` → `f` と上げたときの実測波形。
**同じ 256 サンプルの窓に入る段が 2 → 4 → 8 → 16 → 32 と倍々に増える。**
背景の縞が段 1 つぶんで、この表の `2^(18-上位ニブル)` と一致する。灰色の生波形を見ると、
搬送波のレベルが跳ぶのは縞の境目だけで、段の途中では動かない。

**上位ニブル `f` も例外ではない。** `NFRQ=0x00` のときこの帯だけ「値が変わる間隔」が
16 サンプルに見えるが、それは LFO が遅くなっているのではなく、ノイズ発生器が 2 回に 1 回しか
新しい語を出していないため（[§2.2](#22-lfo-値が変わる間隔はノイズ語の更新周期との合成で決まる)）。8 サンプルごとにラッチしていること自体は
実測してある（[§3](#3-結論の根拠) `[J]`）。

**この式は「更新のタイミングがどうなっているか」を書いたものであって、チップ内部で位相
カウンタがどう進んでいるかを述べたものではない**（[§6.1](#61-観測した現象とそこから言えること)）。

下位ニブルは更新周期だけでなく、**LFO が引くノイズ語の列そのものも変えない**
（[§2.3](#23-下位ニブルは値列も変えない)）。

### 2.2 LFO 値が変わる間隔はノイズ語の更新周期との合成で決まる

`NFRQ` は LFO の更新周期には一切関与しない。決めるのは**ノイズ発生器が新しい語を出す周期**で、

    ノイズ語の更新周期 P_n = (32 - NFRQ) / 2  [samples]

φM で書けば `32 × (32 - NFRQ)` サイクル（φM=4MHz で `NFRQ=0x00` → 3906.25Hz /
`0x1f` → 125kHz）。LFO は [§2.1](#21-更新周期は-lfrq-の上位ニブルだけで決まる) の更新周期 `P_lfo` ごとにこの語を取り込むだけなので、
**観測される「値が変わる間隔」はこの 2 つの合成**になる。

| | 起きること | 値が変わる間隔 |
| --- | --- | --- |
| `P_lfo >= P_n` | 更新のたびに新しい語が来ている | `P_lfo` |
| `P_lfo < P_n` | 同じ語を続けて引く更新が出る | `P_lfo` の整数倍。平均は `P_n` |

現在の測定系で `P_lfo < P_n` になるのは `LFRQ` 上位ニブル `f`（`P_lfo` = 8）の帯だけで、
ここで `NFRQ` の効果が見える。

| LFRQ | `P_lfo` | `NFRQ=0x00`（`P_n`=16）で値が変わる間隔 | `NFRQ=0x01`〜`0x1f` |
| --- | --- | --- | --- |
| `0xd0`〜`0xdf` | 32 | 32 | 32 |
| `0xe0`〜`0xef` | 16 | 16 | 16 |
| `0xf0`〜`0xff` | 8 | **16**（2 回に 1 回しか変わらない） | 8 |

With NFRQ=0x00 the steps of the f band come in identical pairs

`LFRQ=0xf0` を `NFRQ=0x1f`（上段）と `NFRQ=0x00`（中段）で撮り比べた実測波形。
背景の縞は 8 サンプル = `P_lfo` 1 つぶんで、**どちらも段の幅は 8 サンプルのまま**。
▼ は隣の段とレベルがほぼ同じ（差が 0.5dB 未満）だった境界で、**中段だけ 1 本おきに
規則正しく並ぶ** = 8 サンプルごとのラッチが 2 回に 1 回しか新しい語を引いていない。
下段は対照で、`e` 帯は `NFRQ=0x00` でも 16 サンプルのまま変わらない。

この偏りは窓の中だけでなくキャプチャ全体で見ても中段だけに出る。**波形の出どころ・
▼ が付く境界の割合・0.5dB という境目の決め方は [§4.5 図の生成](#図の生成)。**
同じことを閾値なしの統計で測ったのが [§5.4.2](#542-段ごとの-lfo-値から供給周期を測る) で、
こちらは奇数の連が 1 本も出ないことを示している。

実用上は **`NFRQ=0x00` では上位ニブル `f` が `e` と同じ速さにしか聞こえない。**
`0x01` 以上なら全域が [§2.1](#21-更新周期は-lfrq-の上位ニブルだけで決まる) の規則どおりに動く。

#### 中間の値（15.5 / 12 / 8.5）が「間隔」としては出ない理由

`P_n` は `NFRQ` に応じて 16, 15.5, 15, … と連続的に短くなるが、**観測される間隔にその値が
そのまま現れることは無い。** LFO はノイズ語を自分のラッチ時刻でしか読めないので、
値が変わりうる瞬間は `P_lfo` の整数倍しかなく、間隔は必ず 8 の整数倍になる。
`NFRQ=0x01`〜`0x1f` で推定周期が一律 8 になるのはこのためで、`P_n` が 8 でないことと矛盾しない。

`P_n` は**平均として**現れる。`NFRQ` を上げると 8 サンプルの間隔が混じる割合が増え、
平均間隔がちょうど `P_n` になる。これは実測してある（[§3](#3-結論の根拠) `[J]` / [§5.4](#54-nfrq-を全-32-値振る)）。

- `NFRQ=0x00` は `P_n` = 16 が `P_lfo` = 8 の**ちょうど 2 倍**なので位相が完全に噛み合い、
  8 サンプルの間隔が 1 つも出ない。だから推定周期が 16 になる
- `NFRQ=0x01` は `P_n` = 15.5 で 8 の整数倍から外れるため、まれに 8 サンプルの間隔が混じる。
  だから推定周期は真の格子である 8 に戻る
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

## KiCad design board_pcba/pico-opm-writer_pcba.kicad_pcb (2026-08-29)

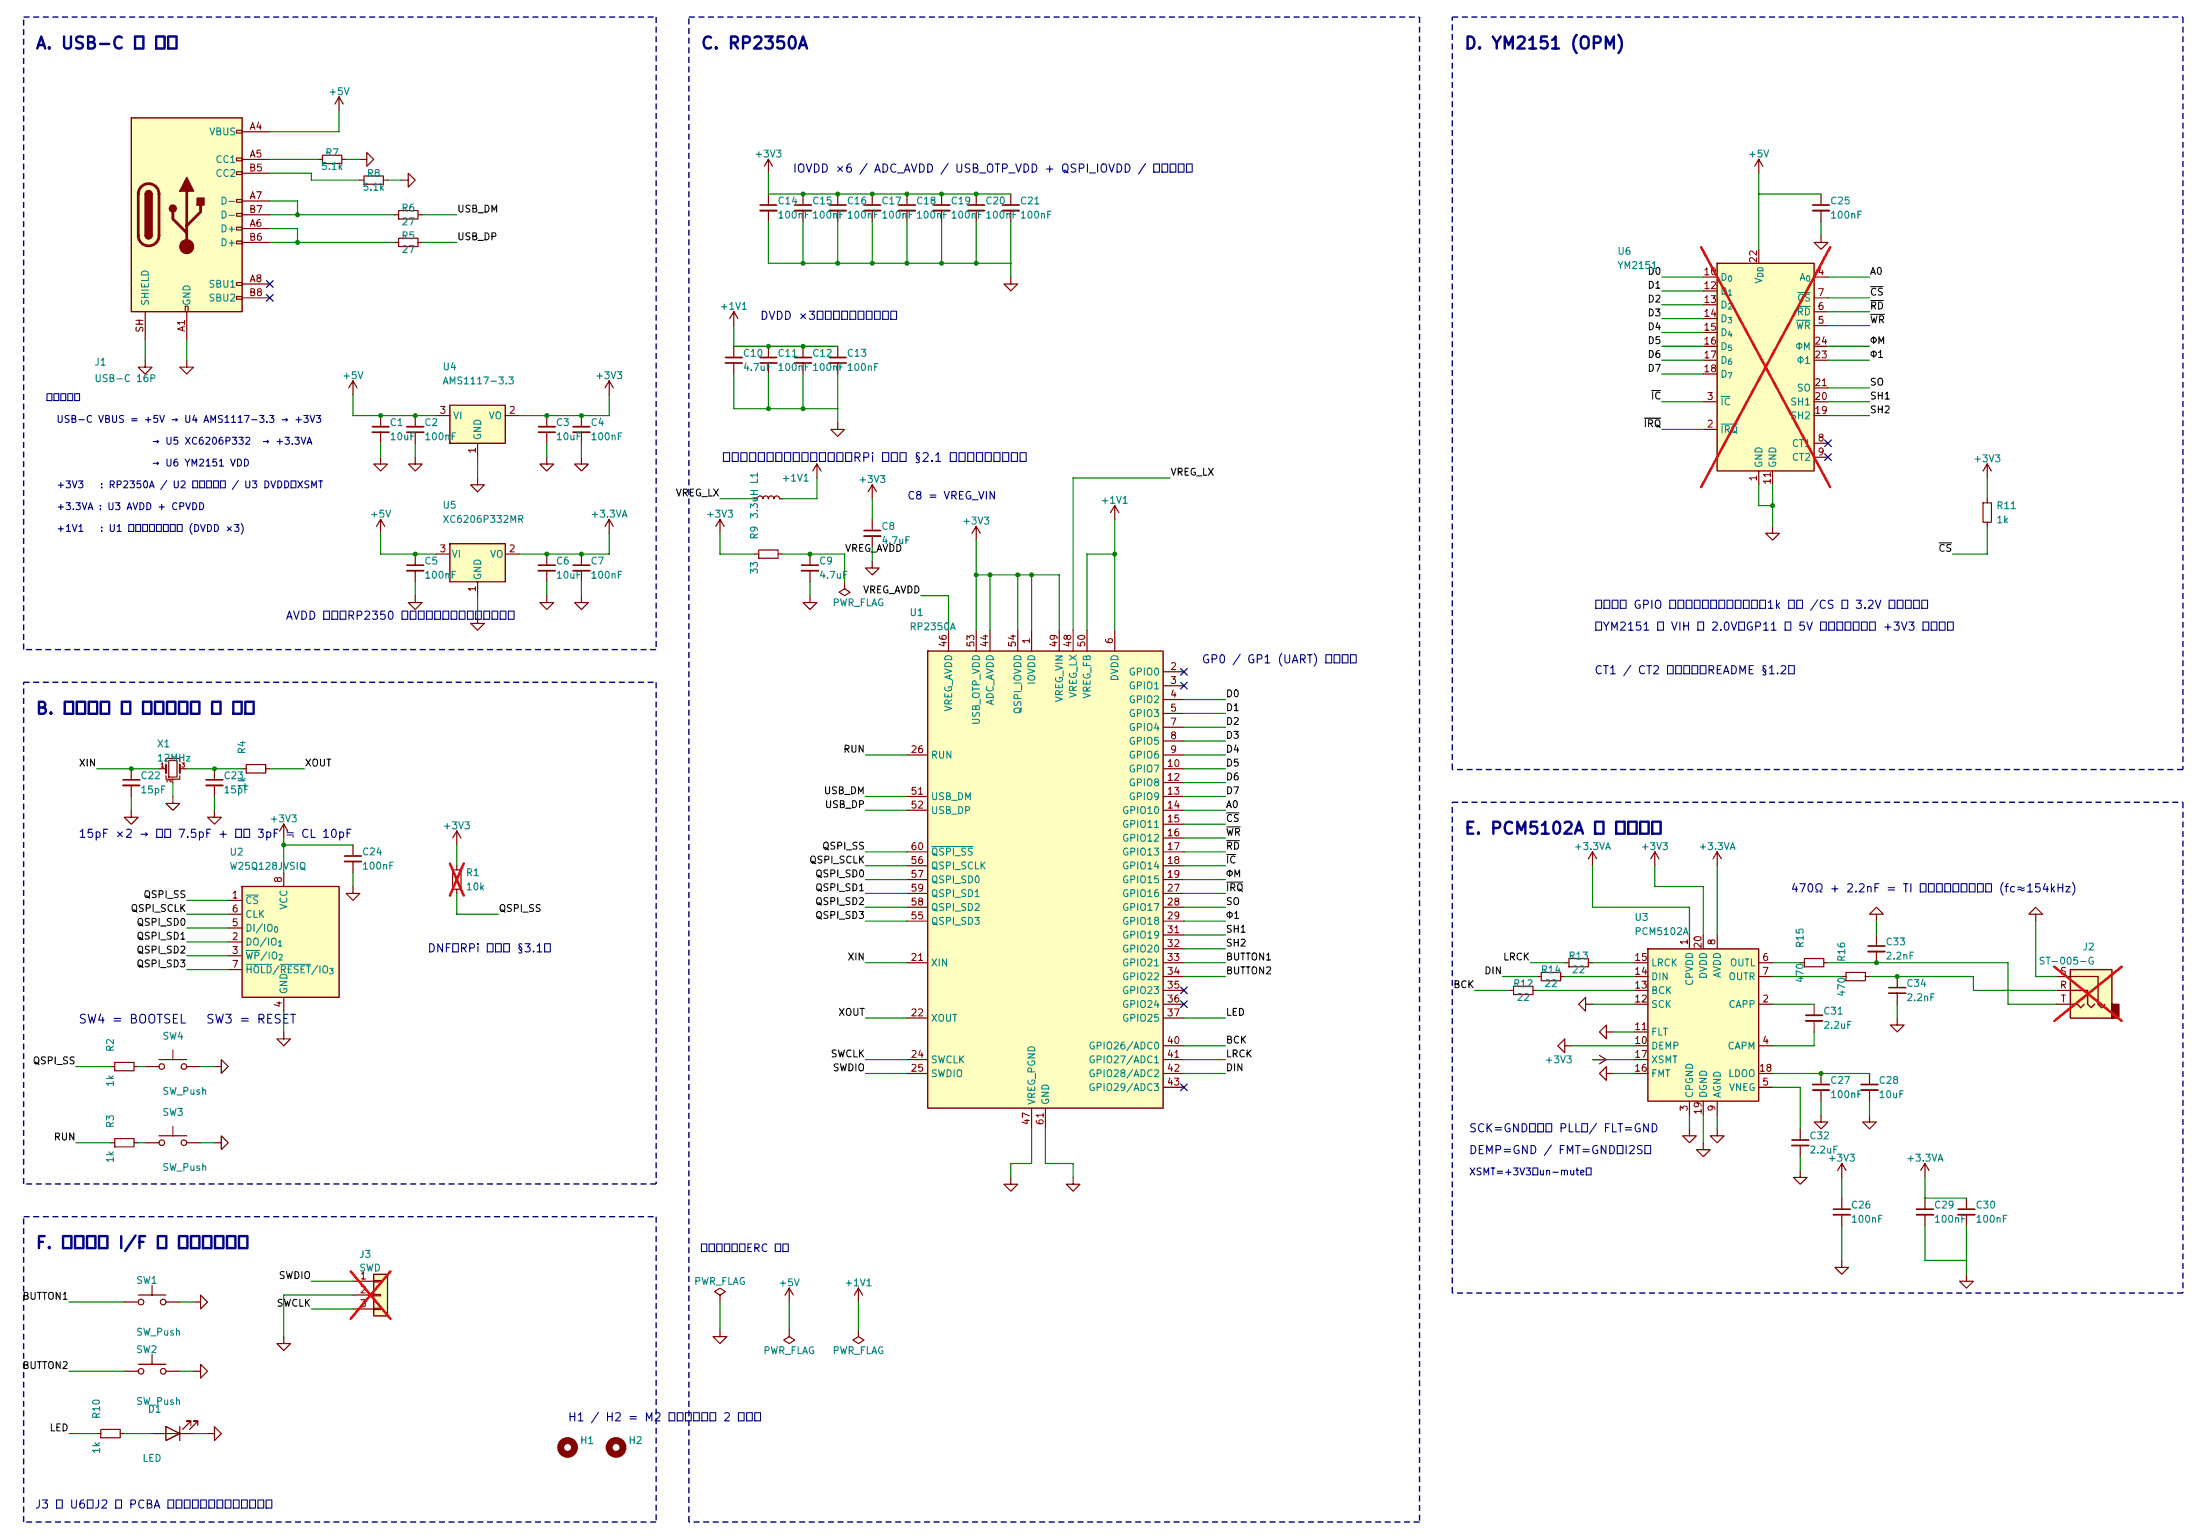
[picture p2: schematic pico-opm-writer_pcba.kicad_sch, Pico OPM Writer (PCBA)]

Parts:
C1, C3: 10uF; C_0805_2012Metric; LCSC Part # C15850
C2, C4, C5, C7, C11, C12, C13, C14, C15, C16, C17, C18, C19, C20, C21, C24, C25, C26, C27, C29, C30: 100nF; C_0402_1005Metric; LCSC Part # C1525
C6, C28: 10uF; C_0603_1608Metric; LCSC Part # C19702
C8, C10: 4.7uF; rpi_capc1005x50_wide; LCSC Part # C23733
C9: 4.7uF; C_0402_1005Metric; LCSC Part # C23733
C22, C23: 15pF; C_0402_1005Metric; LCSC Part # C1548
C31, C32: 2.2uF; C_0603_1608Metric; LCSC Part # C23630
C33, C34: 2.2nF; C_0402_1005Metric; LCSC Part # C1531
D1: LED; LED_0603_1608Metric; LCSC Part # C2286
H1, H2: MountingHole; MountingHole_2.2mm_M2
J1: USB-C 16P; USB_C_Receptacle_Palconn_UTC16-G; LCSC Part # C2765186
J2: ST-005-G; Jack_3.5mm_Switronic_ST-005-G_horizontal; not fitted
J3: SWD; PinHeader_1x03_P2.54mm_Vertical; not fitted
L1: 3.3uH; abracon_aota-b201610s3r3-101-t; LCSC Part # C42411119
R1: 10k; R_0402_1005Metric; LCSC Part # C25744; not fitted
R2, R3, R4, R10, R11: 1k; R_0402_1005Metric; LCSC Part # C11702
R5, R6: 27; R_0402_1005Metric; LCSC Part # C25100
R7, R8: 5.1k; R_0402_1005Metric; LCSC Part # C25905
R9: 33; R_0402_1005Metric; LCSC Part # C25105
R12, R13, R14: 22; R_0402_1005Metric; LCSC Part # C25092
R15, R16: 470; R_0402_1005Metric; LCSC Part # C25117
SW1, SW2, SW3, SW4: SW_Push; SW_SPST_TS-1088-xR020; LCSC Part # C720477
U1: RP2350A; QFN-60-1EP_7x7mm_P0.4mm_EP3.4x3.4mm; LCSC Part # C42411118
U2: W25Q128JVSIQ; SOIC-8_5.3x5.3mm_P1.27mm; LCSC Part # C97521
U3: PCM5102A; TSSOP-20_4.4x6.5mm_P0.65mm; LCSC Part # C107671
U4: AMS1117-3.3; SOT-223-3_TabPin2; LCSC Part # C6186
U5: XC6206P332MR; SOT-23-3; LCSC Part # C5446
U6: YM2151; DIP-24_W15.24mm_Socket; not fitted
X1: 12MHz; Crystal_SMD_3225-4Pin_3.2x2.5mm; LCSC Part # C20625731

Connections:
+3.3VA: C6.1, C7.1, C29.1, C30.1, U3.1 (CPVDD), U3.8 (AVDD), U5.2 (VO)
+3V3: C3.1, C4.1, C8.1, C14.1, C15.1, C16.1, C17.1, C18.1, C19.1, C20.1, C21.1, C24.1, C26.1, R1.1, R9.1, R11.1, U1.1 (IOVDD), U1.11 (IOVDD), U1.20 (IOVDD), U1.30 (IOVDD), U1.38 (IOVDD), U1.44 (ADC_AVDD), U1.45 (IOVDD), U1.49 (VREG_VIN), U1.53 (USB_OTP_VDD), U1.54 (QSPI_IOVDD), U2.8 (VCC), U3.17 (XSMT), U3.20 (DVDD), U4.2 (VO)
/A0: U1.14 (GPIO10), U6.4 (A_{0})
/BCK: R12.1, U1.40 (GPIO26/ADC0)
/BUTTON1: SW1.1, U1.33 (GPIO21)
/BUTTON2: SW2.1, U1.34 (GPIO22)
/D0: U1.4 (GPIO2), U6.10 (D_{0})
/D1: U1.5 (GPIO3), U6.12 (D_{1})
/D2: U1.7 (GPIO4), U6.13 (D_{2})
/D3: U1.8 (GPIO5), U6.14 (D_{3})
/D4: U1.9 (GPIO6), U6.15 (D_{4})
/D5: U1.10 (GPIO7), U6.16 (D_{5})
/D6: U1.12 (GPIO8), U6.17 (D_{6})
/D7: U1.13 (GPIO9), U6.18 (D_{7})
/DIN: R14.1, U1.42 (GPIO28/ADC2)
/LED: R10.1, U1.37 (GPIO25)
/LRCK: R13.1, U1.41 (GPIO27/ADC1)
/QSPI_SCLK: U1.56 (QSPI_SCLK), U2.6 (CLK)
/QSPI_SD0: U1.57 (QSPI_SD0), U2.5 (DI/IO_{0})
/QSPI_SD1: U1.59 (QSPI_SD1), U2.2 (DO/IO_{1})
/QSPI_SD2: U1.58 (QSPI_SD2), U2.3 (~WP/IO_{2})
/QSPI_SD3: U1.55 (QSPI_SD3), U2.7 (~HOLD/~RESET/IO_{3})
/QSPI_SS: R1.2, R2.1, U1.60 (~QSPI_SS), U2.1 (~CS)
/RUN: R3.1, U1.26 (RUN)
/SH1: U1.31 (GPIO19), U6.20 (SH1)
/SH2: U1.32 (GPIO20), U6.19 (SH2)
/SO: U1.28 (GPIO17), U6.21 (SO)
/SWCLK: J3.3, U1.24 (SWCLK)
/SWDIO: J3.1, U1.25 (SWDIO)
/USB_DM: R6.2, U1.51 (USB_DM)
/USB_DP: R5.2, U1.52 (USB_DP)
/VREG_LX: L1.1, U1.48 (VREG_LX)
/XIN: C22.1, U1.21 (XIN), X1.1
/XOUT: R4.2, U1.22 (XOUT)
/~CS: R11.2, U1.15 (GPIO11), U6.7 (~CS)
/~IC: U1.18 (GPIO14), U6.3 (~IC)
/~IRQ: U1.27 (GPIO16), U6.2 (~IRQ)
/~RD: U1.17 (GPIO13), U6.6 (~RD)
/~WR: U1.16 (GPIO12), U6.5 (~WR)
/Φ1: U1.29 (GPIO18), U6.23 (Φ1)
/ΦM: U1.19 (GPIO15), U6.24 (ΦM)
unnamed: C23.1, R4.1, X1.3
unnamed: C33.2, J2.T, R15.2
unnamed: C34.1, J2.R, R16.2
unnamed: D1.2 (A), R10.2
unnamed: J1.A5 (CC1), R7.1
unnamed: J1.B5 (CC2), R8.1
unnamed: J1.A6 (D+), J1.B6 (D+), R5.1
unnamed: J1.A7 (D-), J1.B7 (D-), R6.1
unnamed: R2.2, SW4.1
unnamed: R3.2, SW3.1
unnamed: R12.2, U3.13 (BCK)
unnamed: C31.2, U3.4 (CAPM)
unnamed: C31.1, U3.2 (CAPP)
unnamed: R14.2, U3.14 (DIN)
unnamed: C27.1, C28.1, U3.18 (LDOO)
unnamed: R13.2, U3.15 (LRCK)
unnamed: R15.1, U3.6 (OUTL)
unnamed: R16.1, U3.7 (OUTR)
unnamed: C32.1, U3.5 (VNEG)

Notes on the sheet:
電源フラグ（ERC 用）
H1 / H2 = M2 取付穴（対角 2 箇所）
+3V3 : RP2350A / U2 フラッシュ / U3 DVDD・XSMT
470Ω + 2.2nF = TI 推奨ポストフィルタ (fc≈154kHz)
E. PCM5102A ・ 音声出力
→ U6 YM2151 VDD
DNF（RPi ガイド §3.1）
C8 = VREG_VIN
電源ツリー
SCK=GND（内蔵 PLL）/ FLT=GND
+1V1 : U1 内蔵バックの出力 (DVDD ×3)
内蔵スイッチングレギュレータ（RPi ガイド §2.1 の部品選定に従う）
C. RP2350A
CT1 / CT2 は未使用（README §1.2）
IOVDD ×6 / ADC_AVDD / USB_OTP_VDD + QSPI_IOVDD / フラッシュ
AVDD 専用。RP2350 内蔵バックのノイズを分離する
F. ユーザー I/F ・ デバッグ端子
（YM2151 の VIH は 2.0V。GP11 に 5V を掛けないため +3V3 へ引く）
15pF ×2 → 直列 7.5pF + 寄生 3pF ≒ CL 10pF
B. クロック ・ フラッシュ ・ 起動
DEMP=GND / FMT=GND（I2S）
DVDD ×3（内蔵バックの出力）
USB-C VBUS = +5V → U4 AMS1117-3.3 → +3V3
+3.3VA : U3 AVDD + CPVDD
SW4 = BOOTSEL SW3 = RESET
D. YM2151 (OPM)
起動直後 GPIO は入力＋内部プルダウン。1k なら /CS は 3.2V 以上を保つ
A. USB-C ・ 電源
J3 と U6・J2 は PCBA では実装しない（手はんだ）
→ U5 XC6206P332 → +3.3VA
XSMT=+3V3（un-mute）
GP0 / GP1 (UART) は未使用

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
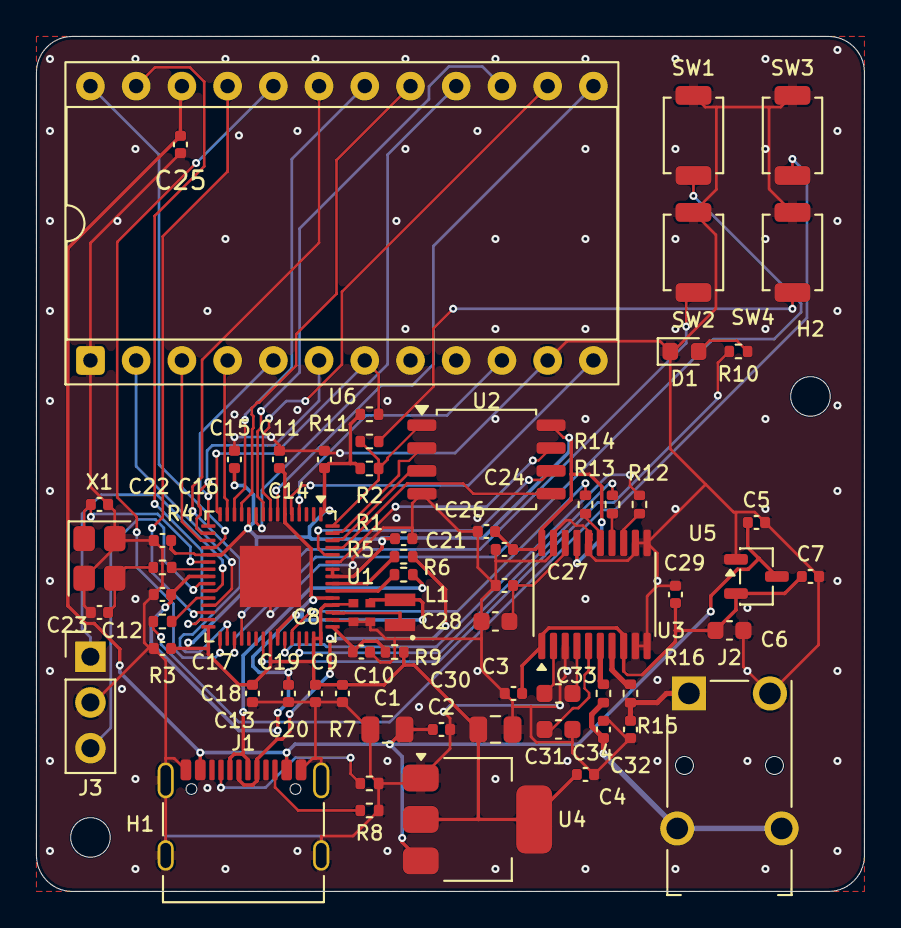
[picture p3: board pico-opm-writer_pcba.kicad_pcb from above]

Board: 2 copper layers, 46.0 x 47.5 mm, 68 parts (0 on the bottom side), 64 nets.

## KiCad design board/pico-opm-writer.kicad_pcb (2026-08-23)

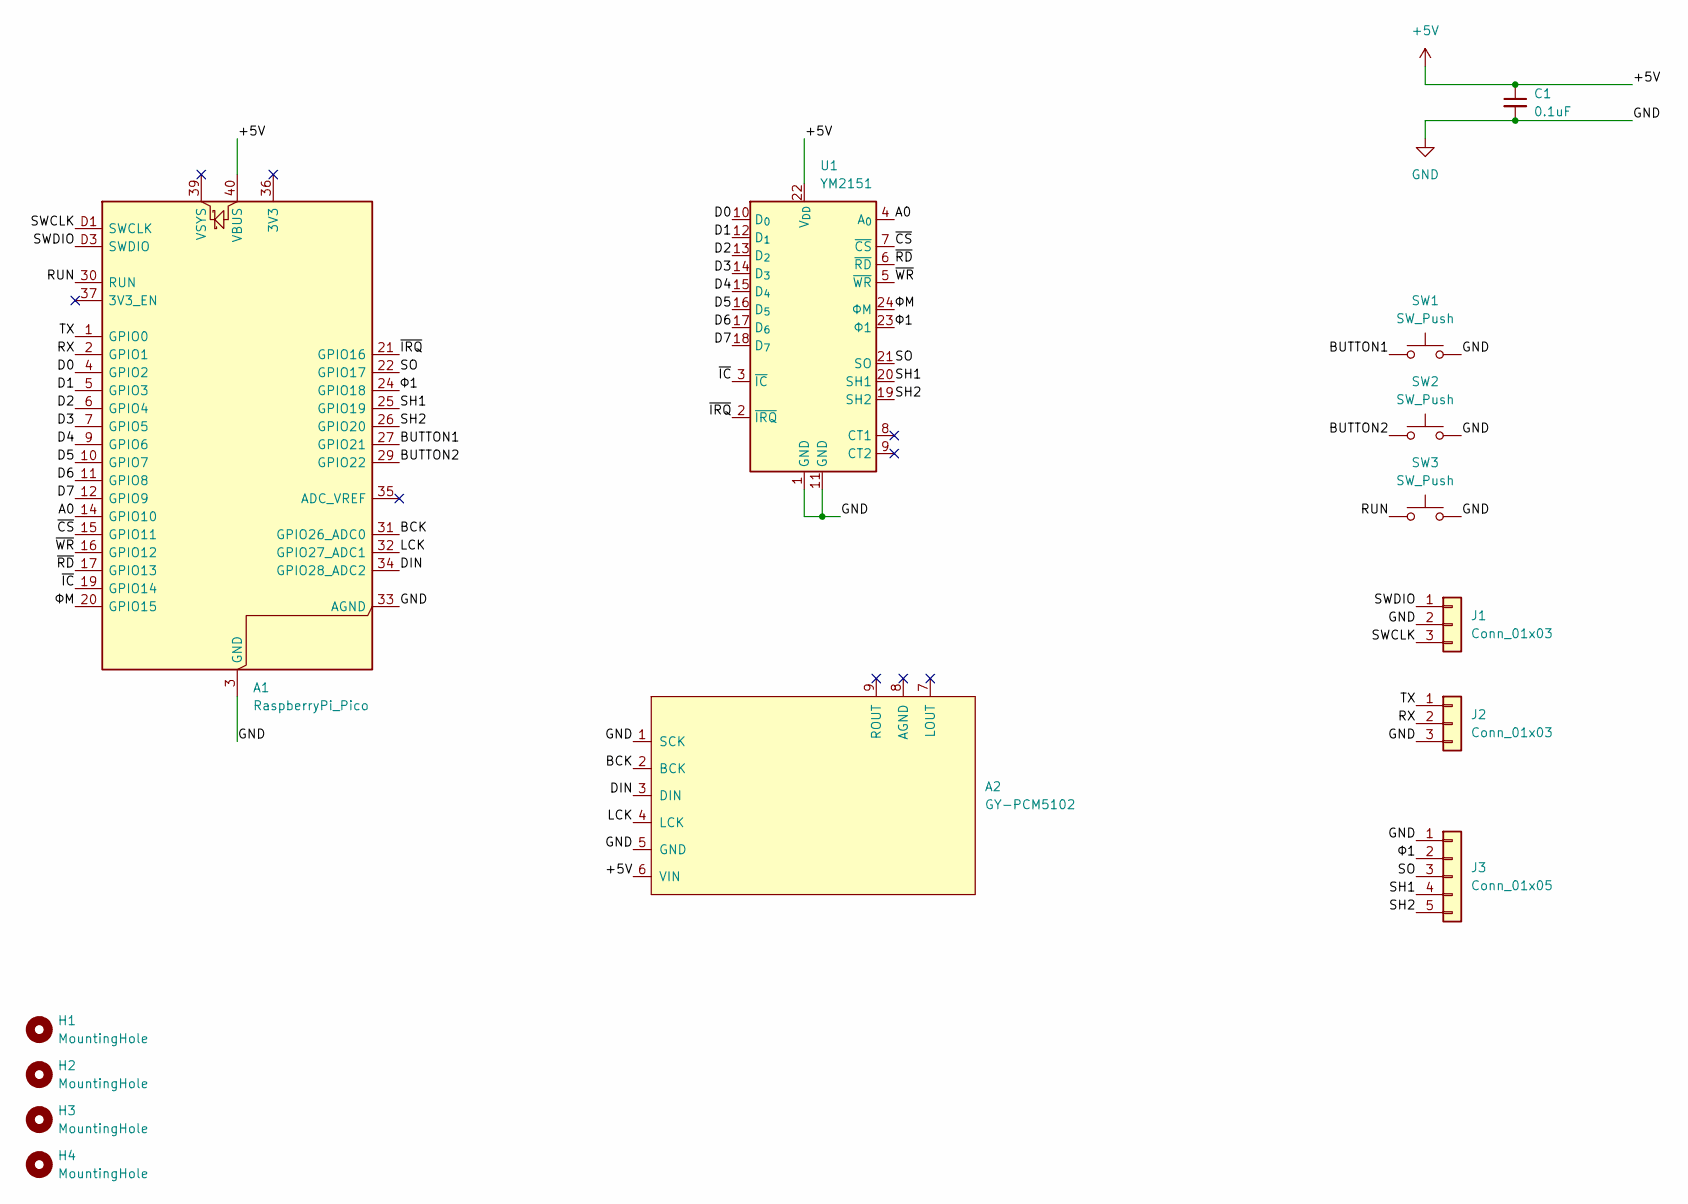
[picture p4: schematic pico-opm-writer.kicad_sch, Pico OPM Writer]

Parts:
A1: RaspberryPi_Pico; RPi_Pico_SMD
A2: GY-PCM5102; GY-PCM5102_BOARD
C1: 0.1uF; C_Disc_D3.0mm_W1.6mm_P2.50mm
H1, H2, H3, H4: MountingHole; MountingHole_3.2mm_M3
J1, J2: Conn_01x03; PinHeader_1x03_P2.54mm_Vertical
J3: Conn_01x05; PinHeader_1x05_P2.54mm_Vertical
SW1, SW2, SW3: SW_Push; SW_PUSH_6mm_H7.3mm
U1: YM2151; DIP-24_W15.24mm_Socket

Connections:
+5V: A1.40 (VBUS), A2.6 (VIN), C1.1, U1.22 (V_{DD})
/A0: A1.14 (GPIO10), U1.4 (A_{0})
/BCK: A1.31 (GPIO26_ADC0), A2.2 (BCK)
/BUTTON1: A1.27 (GPIO21), SW1.1
/BUTTON2: A1.29 (GPIO22), SW2.1
/D0: A1.4 (GPIO2), U1.10 (D_{0})
/D1: A1.5 (GPIO3), U1.12 (D_{1})
/D2: A1.6 (GPIO4), U1.13 (D_{2})
/D3: A1.7 (GPIO5), U1.14 (D_{3})
/D4: A1.9 (GPIO6), U1.15 (D_{4})
/D5: A1.10 (GPIO7), U1.16 (D_{5})
/D6: A1.11 (GPIO8), U1.17 (D_{6})
/D7: A1.12 (GPIO9), U1.18 (D_{7})
/DIN: A1.34 (GPIO28_ADC2), A2.3 (DIN)
/LCK: A1.32 (GPIO27_ADC1), A2.4 (LCK)
/RUN: A1.30 (RUN), SW3.1
/RX: A1.2 (GPIO1), J2.2
/SH1: A1.25 (GPIO19), J3.4, U1.20 (SH1)
/SH2: A1.26 (GPIO20), J3.5, U1.19 (SH2)
/SO: A1.22 (GPIO17), J3.3, U1.21 (SO)
/SWCLK: A1.D1 (SWCLK), J1.3
/SWDIO: A1.D3 (SWDIO), J1.1
/TX: A1.1 (GPIO0), J2.1
/~CS: A1.15 (GPIO11), U1.7 (~CS)
/~IC: A1.19 (GPIO14), U1.3 (~IC)
/~IRQ: A1.21 (GPIO16), U1.2 (~IRQ)
/~RD: A1.17 (GPIO13), U1.6 (~RD)
/~WR: A1.16 (GPIO12), U1.5 (~WR)
/Φ1: A1.24 (GPIO18), J3.2, U1.23 (Φ1)
/ΦM: A1.20 (GPIO15), U1.24 (ΦM)
GND: A1.3 (GND), A1.8 (GND), A1.13 (GND), A1.18 (GND), A1.23 (GND), A1.28 (GND), A1.33 (AGND), A1.38 (GND), A1.D2 (GND), A2.1 (SCK), A2.5 (GND), C1.2, J1.2, J2.3, J3.1, SW1.2, SW2.2, SW3.2, U1.1 (GND), U1.11 (GND)

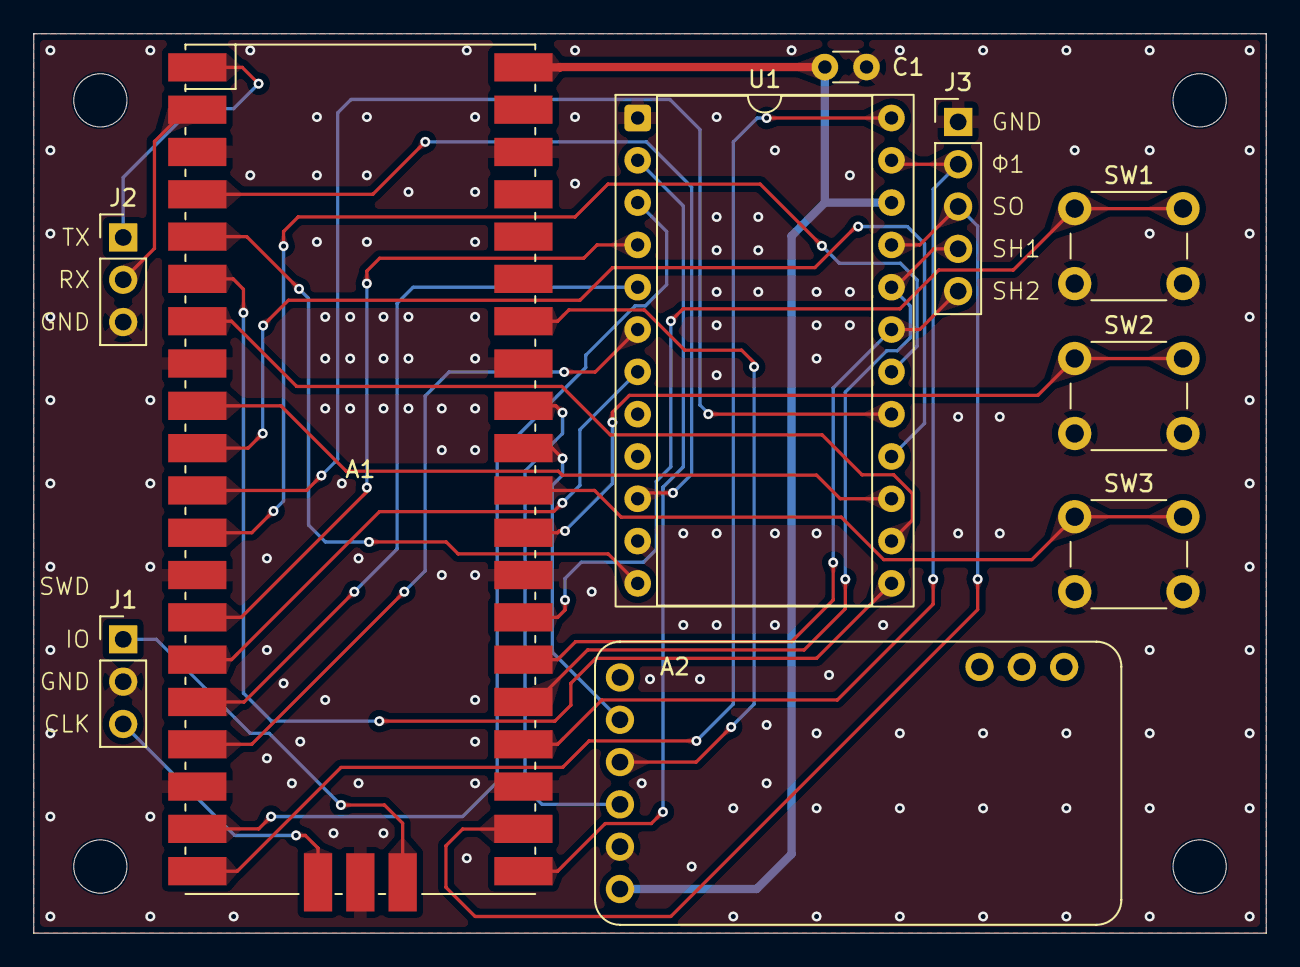
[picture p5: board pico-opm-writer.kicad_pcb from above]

Board: 2 copper layers, 74.0 x 54.0 mm, 14 parts (0 on the bottom side), 31 nets.

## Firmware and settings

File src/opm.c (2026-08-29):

/*
 * OPM (YM2151) バス制御の実装
 *
 * SPDX-License-Identifier: MIT
 */
#include "opm.h"

#include "hardware/clocks.h"
#include "hardware/gpio.h"
#include "hardware/pio.h"
#include "pico/platform.h"

#include "opm_clock.pio.h"
#include "stats.h"

/* GPIO マスク */
#define OPM_MASK_DATA ((uint32_t)0xffu << OPM_PIN_D0)
#define OPM_MASK_A0   ((uint32_t)1u << OPM_PIN_A0)
#define OPM_MASK_CS   ((uint32_t)1u << OPM_PIN_CS)
#define OPM_MASK_WR   ((uint32_t)1u << OPM_PIN_WR)
#define OPM_MASK_RD   ((uint32_t)1u << OPM_PIN_RD)
#define OPM_MASK_IC   ((uint32_t)1u << OPM_PIN_IC)
#define OPM_MASK_IRQ  ((uint32_t)1u << OPM_PIN_IRQ)

#define OPM_MASK_ALL (OPM_MASK_DATA | OPM_MASK_A0 | OPM_MASK_CS | OPM_MASK_WR | OPM_MASK_RD | OPM_MASK_IC)

/* φM 生成に使っている PIO / ステートマシン */
static PIO s_pio;
static uint s_sm;
static uint s_offset;

/* PIO 分周比（16.8 固定小数）と、そこから逆算した実 φM 周波数 */
static uint32_t s_div_int;
static uint32_t s_div_frac;
static uint32_t s_clock_hz_actual;

/* OPM_T_SETUP_NS 相当のシステムクロックサイクル数 */
static uint32_t s_setup_cycles;

/* OPM_BUSY_CYCLES（φM サイクル）相当のシステムクロックサイクル数と、その ns 表示 */
static uint32_t s_data_wait_cycles;
static uint32_t s_data_wait_ns;

/*
 * φM の分周比と、それに付随する sys_clk 依存の値を算出する。
 *
 * φM = sys_clk / (2 x div) なので div = sys_clk / (2 x φM)。
 * これを 1/256 刻みの固定小数にすると div256 = sys_clk x 128 / φM。
 *
 * round_up を立てると 1/256 刻みではなく整数へ切り上げる。分周比が大きくなる方向
 * なので φM は目標以下にしかならず、H/L 期間が公称値より短くならない。クロック
 * 切り替えの途中（sys_clk が中途半端な 48MHz のとき）に使う。
 */
static void opm_clock_compute(uint32_t sys_hz, uint32_t phim_hz, bool round_up)
{
    uint64_t div256;

    if (round_up)
    {
        uint64_t den = 2ull * phim_hz;
        uint64_t div = ((uint64_t)sys_hz + den - 1u) / den;
        div256 = div << 8;
    }
    else
    {
        div256 = ((uint64_t)sys_hz * 128u + phim_hz / 2u) / phim_hz;
    }
    if (div256 < 256u)
    {
        div256 = 256u; /* 分周比 1 未満にはできない */
    }

    s_div_int = (uint32_t)(div256 >> 8);
    s_div_frac = (uint32_t)(div256 & 0xffu);
    s_clock_hz_actual = (uint32_t)(((uint64_t)sys_hz * 128u) / div256);

    /* ns 指定のセットアップ時間をサイクル数へ（切り上げ） */
    s_setup_cycles =
        (uint32_t)(((uint64_t)sys_hz * OPM_T_SETUP_NS + 999999999u) / 1000000000u);

    /*
     * データサイクル後の BUSY 待ち。φM サイクル数で持っているので、
     * sys_clk と φM の比を掛ければ sys クロックのサイクル数になる（切り上げ）。
     *
     * **目標値 phim_hz ではなく、上で求めた実 φM を使う。** round_up の経路では
     * 実 φM が目標以下になるので、目標で割ると BUSY が明ける前に待ちが終わる。
     * 実 φM で割っておけば、どの経路から呼ばれても待ちが足りなくなることはない。
     */
    s_data_wait_cycles = (uint32_t)(((uint64_t)sys_hz * OPM_BUSY_CYCLES +
                                     s_clock_hz_actual - 1u) /
                                    s_clock_hz_actual);
    s_data_wait_ns = (uint32_t)(((uint64_t)OPM_BUSY_CYCLES * 1000000000u +
                                 s_clock_hz_actual - 1u) /
                                s_clock_hz_actual);
}

/*
 * 算出済みの分周比を、走っている SM へ反映する。
 *
 * 走ったまま SMx_CLKDIV を書くと進行中のカウントの扱いが規定されていないので、
 * 一瞬止めてから書く。停止中は SM が最後に出したレベルをピンが保持するため、
 * 進行中の H/L 期間は数百 ns 伸びるだけで、短くはならない。
 * clkdiv_restart は分周カウンタを 0 に戻すだけで PC / X / Y には触らない。
 */
static void opm_clock_apply(void)
{
    pio_sm_set_enabled(s_pio, s_sm, false);
    pio_sm_set_clkdiv_int_frac8(s_pio, s_sm, s_div_int, (uint8_t)s_div_frac);
    pio_sm_clkdiv_restart(s_pio, s_sm);
    pio_sm_set_enabled(s_pio, s_sm, true);
}

/* φM の分周比を算出して PIO を起動する。 */
static void opm_clock_start(void)
{
    opm_clock_compute(clock_get_hz(clk_sys), OPM_CLOCK_HZ, false);

    bool ok = pio_claim_free_sm_and_add_program(&opm_clock_program, &s_pio, &s_sm, &s_offset);
    hard_assert(ok);

    opm_clock_program_init(s_pio, s_sm, s_offset, OPM_PIN_PHIM, s_div_int, (uint8_t)s_div_frac);
    pio_sm_set_enabled(s_pio, s_sm, true);
}

void opm_clock_retune_for(uint32_t sys_hz, uint32_t phim_hz)
{
    opm_clock_compute(sys_hz, phim_hz, false);
    opm_clock_apply();
}

void opm_clock_retune_up(uint32_t phim_hz)
{
    opm_clock_compute(clock_get_hz(clk_sys), phim_hz, true);
    opm_clock_apply();
}

/*
 * データバスの向きを切り替える。
 *
 * 既定は出力（書き込み方向）で、読み出しの間だけ入力へ倒す。OPM に D0-D7 を
 * 駆動させる前に必ず入力にしておくこと（バスの衝突を防ぐ）。
 */
static void opm_bus_set_dir(bool out)
{
    if (out)
    {
        gpio_set_dir_out_masked(OPM_MASK_DATA);
    }
    else
    {
        gpio_set_dir_in_masked(OPM_MASK_DATA);
    }
}

/* データバスと A0 を確定させてから /CS と /WR を制御する（1 バスサイクル） */
static void opm_bus_cycle(bool a0, uint8_t value)
{
    /* データ・A0 と同時に /CS を L にする */
    gpio_put_masked(OPM_MASK_DATA | OPM_MASK_A0 | OPM_MASK_CS,
                    ((uint32_t)value << OPM_PIN_D0) | (a0 ? OPM_MASK_A0 : 0u));
    busy_wait_at_least_cycles(s_setup_cycles); /* t_SETUP */

    gpio_clr_mask(OPM_MASK_WR);
    busy_wait_us_32(OPM_T_WR_US);
    gpio_set_mask(OPM_MASK_WR);

    /* /WR を H に戻した後に /CS を H に戻す */
    gpio_set_mask(OPM_MASK_CS);
}

void opm_init(void)
{
    /* 出力ピンをまとめて初期化。/CS・/WR・/RD・/IC は負論理なので H から始める。 */
    gpio_init_mask(OPM_MASK_ALL);
    gpio_put_masked(OPM_MASK_ALL, OPM_MASK_CS | OPM_MASK_WR | OPM_MASK_RD | OPM_MASK_IC);
    gpio_set_dir_out_masked(OPM_MASK_ALL & ~OPM_MASK_DATA);
    opm_bus_set_dir(true); /* データバスは書き込み方向で始める */

    /* /IRQ を入力として初期化し、プルアップを有効にする */
    gpio_init(OPM_PIN_IRQ);
    gpio_set_dir(OPM_PIN_IRQ, GPIO_IN);
    gpio_pull_up(OPM_PIN_IRQ);

    /* /IC を操作する前に φM を動かしておく必要がある。s_setup_cycles もここで決まる。 */
    opm_clock_start();

    opm_reset();
}

void opm_write(uint8_t addr, uint8_t data)
{
#if STATS_PROFILE
    uint32_t t0 = time_us_32();
#endif

    /* アドレスサイクル */
    opm_bus_cycle(false, addr);
    busy_wait_us_32(OPM_T_ADDR_US);

    /*
     * データサイクル。BUSY は opm_read() で読めるが、書き込み経路では見ずに待つ。
     * 待つ長さは φM サイクル数から実行時に算出してあるので、クロックを
     * 切り替えても自動で追従する（opm.h の OPM_BUSY_CYCLES）。
     */
    opm_bus_cycle(true, data);
    busy_wait_at_least_cycles(s_data_wait_cycles);

#if STATS_PROFILE
    /*
     * 1 レジスタ書き込みの実費用。タイミング定数を変えたときの前後比較は
     * `s` の OPMW 行の平均（us/s ÷ writes/s）で見る。
     */
    stats_opm_write_add(time_us_32() - t0);
#endif
}

/*
 * /RD による 1 バイト読み出し。A0=1 がデータシート上のステータスレジスタ。
 *
 * 手順の並びがバス衝突の防止そのものなので崩さないこと。Pico 側を先に入力へ
 * 倒してから OPM に駆動させ、OPM が手放すのを待ってから出力へ戻す。
 */
uint8_t opm_read(bool a0)
{
    opm_bus_set_dir(false);

    /* A0 を確定させると同時に /CS を L にする（D0-D7 は入力中なので触らない） */
    gpio_put_masked(OPM_MASK_A0 | OPM_MASK_CS, a0 ? OPM_MASK_A0 : 0u);
    busy_wait_at_least_cycles(s_setup_cycles); /* t_SETUP */

    gpio_clr_mask(OPM_MASK_RD);
    busy_wait_us_32(OPM_T_RD_US);
    uint32_t all = gpio_get_all();
    gpio_set_mask(OPM_MASK_RD);

    /* /RD を H に戻した後に /CS を H に戻す */
    gpio_set_mask(OPM_MASK_CS);

    /* OPM が D0-D7 を手放すのを待ってから出力へ戻す */
    busy_wait_us_32(OPM_T_FLOAT_US);
    opm_bus_set_dir(true);

    return (uint8_t)((all >> OPM_PIN_D0) & 0xffu);
}

void opm_reset(void)
{
    gpio_clr_mask(OPM_MASK_IC);
    sleep_ms(OPM_T_IC_LOW_MS);
    gpio_set_mask(OPM_MASK_IC);
    sleep_ms(OPM_T_IC_WAIT_MS);
}
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

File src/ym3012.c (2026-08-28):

/*
 * YM3012 (OPM の DAC) 出力のキャプチャと PCM 変換の実装
 *
 * SPDX-License-Identifier: MIT
 */
#include "ym3012.h"

#include <stdio.h>

#include "hardware/dma.h"
#include "hardware/gpio.h"
#include "hardware/pio.h"
#include "pico/stdlib.h"

#include "stats.h"
#include "ym3012.pio.h"

/* PCM は signed 16bit little-endian。int16_t の配列をそのまま送るのでこれが前提。 */
_Static_assert(__BYTE_ORDER__ == __ORDER_LITTLE_ENDIAN__,
               "PCM 出力は little-endian 前提");

/*
 * リング本体。DMA のハードウェアリング機能はアドレスの下位ビットだけを回すので、
 * バッファをリングサイズと同じ境界へアラインしなければならない。
 */
static uint32_t s_ring[YM3012_RING_FRAMES]
    __attribute__((aligned(YM3012_RING_BYTES)));

/* キャプチャに使っている PIO / ステートマシン / DMA チャネル */
static PIO s_pio;
static uint s_sm;
static uint s_offset;
static uint s_dma_ch;

/*
 * DMA の書き込み位置はリング内の 12bit しか分からないので、差分を積んで
 * 64bit の総フレーム数へ延ばす。DMA 位置そのものを二重に持つわけではない。
 */
static uint32_t s_last_widx;
static uint64_t s_write_total;

/*
 * 最後に「無音でない」フレームを見た時点の総フレーム数（そのフレームの次の番号）。
 * ym3012_ring_poll() が取り込みのついでに更新する。曲が終わったあと余韻が消えるのを
 * 待つのに使う（songend.c）。
 */
static uint64_t s_last_loud_total;

/* USB キャプチャが使う既定の読み出しカーソル */
static ym3012_reader_t s_reader;

/* 変換直後に呼ぶミキサ（MDX の ADPCM パート）。未登録なら NULL。 */
static ym3012_mixer_t s_mixer;
static uint64_t s_mix_ready;

/*
 * 出力ゲイン（フェードアウト）。s_fade_frames が 0 なら掛けない。
 * s_fade_inv は「残り比」を除算なしで引くための 1/frames（Q32）。
 *
 * s_fade_release は「このフレーム以降はゲインを 1.0 に戻す」境界。ゲインを即座に
 * 戻すと、リングにまだ残っている**フェード済みのはずの区間**が全音量で読み出されて
 * しまう（カーソルは書き込み位置より後ろに居る）。解除もフレーム番号で持つ。
 *
 * s_release_frames は境界から 1.0 まで戻すのにかける長さ。0 なら境界で一気に戻す。
 * s_release_inv はフェードアウト側と同じ作りの 1/frames（Q32）。
 */
static uint64_t s_fade_start;
static uint32_t s_fade_frames;
static uint32_t s_fade_inv;
static uint64_t s_fade_release = UINT64_MAX;
static uint32_t s_release_frames;
static uint32_t s_release_inv;

static bool s_selftest_ok;
static char s_selftest_detail[80];

/* ---- ループバック自己診断 ---------------------------------------------- */

/*
 * 無効ビット・仮数・指数から 32bit のフレームを組む。
 * 並びは受信順で bit0 から「無効 3 / 仮数 10 / 指数 3」を L・R の順に 2 組。
 */
static uint32_t frame_pack(uint32_t ul, uint32_t ml, uint32_t el,
                           uint32_t ur, uint32_t mr, uint32_t er)
{
    return ((ul & 7u)) | ((ml & 0x3ffu) << 3) | ((el & 7u) << 13) |
           ((ur & 7u) << 16) | ((mr & 0x3ffu) << 19) | ((er & 7u) << 29);
}

#if YM3012_LOOPBACK_ENABLED

#define LOOPBACK_PIN_SO   (YM3012_LOOPBACK_BASE + 0u)
#define LOOPBACK_PIN_PHI1 (YM3012_LOOPBACK_BASE + 1u)
#define LOOPBACK_PIN_SH1  (YM3012_LOOPBACK_BASE + 2u)

/*
 * 合成フレームを 1 個ビットバンギングで流し込む。
 *
 * キャプチャ用 PIO は純粋にエッジ駆動でタイミング制約が無いので、CPU が
 * 好きな速さで叩いてよい。ここでは余裕を見て 1 クロック 2us で送る。
 */
static void loopback_send_frame(uint32_t word)
{
    /* SH1 の立ち下がりでフレームの先頭を作る */
    gpio_put(LOOPBACK_PIN_SH1, 1);
    busy_wait_us_32(2);
    gpio_put(LOOPBACK_PIN_SH1, 0);
    busy_wait_us_32(2);

    /* YM3012 は LSB first。word の bit0 が最初に出る。 */
    for (uint i = 0; i < 32; i++)
    {
        gpio_put(LOOPBACK_PIN_SO, (word >> i) & 1u);
        gpio_put(LOOPBACK_PIN_PHI1, 0);
        busy_wait_us_32(1);
        gpio_put(LOOPBACK_PIN_PHI1, 1); /* この立ち上がりで PIO が SO を取り込む */
        busy_wait_us_32(1);
    }
}

/*
 * PIO のビット順・フレーム同期・L/R の並びを、外部機器なしで検証する。
 *
 * PIO は FUNCSEL に関係なくパッドの入力値を読めるので、ループバック用ピンは
 * SIO の出力にしたまま CPU から駆動してよい。DMA 開始前に 1 回だけ実行する。
 */
static bool loopback_selftest(void)
{
    /* 期待する (L, R) は左右で別の値にして、入れ替わりを検出できるようにする */
    static const struct
    {
        uint32_t ul, ml, el; /* L の無効ビット・仮数・指数 */
        uint32_t ur, mr, er; /* R の無効ビット・仮数・指数 */
        int16_t expect_l;
        int16_t expect_r;
    } cases[] = {
        /* フルスケール両端。無効ビットが結果に混ざらないことも見る。 */
        {5u, 1023u, 7u, 2u, 0u, 7u, 32704, -32768},
        /* 最小ステップ。ゼロと +1 で L/R の取り違えが分かる。 */
        {7u, 512u, 1u, 0u, 513u, 1u, 0, 1},
        /* 負値と中間の指数。 */
        {3u, 511u, 1u, 4u, 768u, 2u, -1, 512},
    };

    for (uint i = 0; i < 3; i++)
    {
        gpio_init(YM3012_LOOPBACK_BASE + i);
        gpio_set_dir(YM3012_LOOPBACK_BASE + i, GPIO_OUT);
    }
    gpio_put(LOOPBACK_PIN_SO, 0);
    gpio_put(LOOPBACK_PIN_PHI1, 0);
    gpio_put(LOOPBACK_PIN_SH1, 1);

    ym3012_capture_program_init(s_pio, s_sm, s_offset, YM3012_LOOPBACK_BASE);
    pio_sm_clear_fifos(s_pio, s_sm);
    pio_sm_set_enabled(s_pio, s_sm, true);

    bool ok = true;
    for (uint i = 0; i < count_of(cases) && ok; i++)
    {
        uint32_t word = frame_pack(cases[i].ul, cases[i].ml, cases[i].el,
                                   cases[i].ur, cases[i].mr, cases[i].er);
        loopback_send_frame(word);

        if (pio_sm_is_rx_fifo_empty(s_pio, s_sm))
        {
            snprintf(s_selftest_detail, sizeof(s_selftest_detail),
                     "FAIL case %u: no data pushed", i);
            ok = false;
            break;
        }

        uint32_t got = pio_sm_get(s_pio, s_sm);
        if (got != word)
        {
            snprintf(s_selftest_detail, sizeof(s_selftest_detail),
                     "FAIL case %u: word %08lx expect %08lx",
                     i, (unsigned long)got, (unsigned long)word);
            ok = false;
            break;
        }

        int16_t l, r;
        ym3012_frame_to_pcm(got, &l, &r);
        if (l != cases[i].expect_l || r != cases[i].expect_r)
        {
            snprintf(s_selftest_detail, sizeof(s_selftest_detail),
                     "FAIL case %u: pcm L=%d R=%d expect L=%d R=%d",
                     i, l, r, cases[i].expect_l, cases[i].expect_r);
            ok = false;
            break;
        }
    }

    pio_sm_set_enabled(s_pio, s_sm, false);
    pio_sm_clear_fifos(s_pio, s_sm);

    /* ループバック用ピンは入力へ戻して手を引く */
    for (uint i = 0; i < 3; i++)
    {
        gpio_deinit(YM3012_LOOPBACK_BASE + i);
    }

    if (ok)
    {
        snprintf(s_selftest_detail, sizeof(s_selftest_detail), "PASS");
    }
    return ok;
}

#else /* YM3012_LOOPBACK_ENABLED */

static bool loopback_selftest(void)
{
    snprintf(s_selftest_detail, sizeof(s_selftest_detail), "SKIP (disabled)");
    return true;
}

#endif /* YM3012_LOOPBACK_ENABLED */

/* ---- 初期化 ------------------------------------------------------------ */
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

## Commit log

2026-08-09 YM2151 (OPM) レジスタライタのファームウェアを追加
    Raspberry Pi Pico 2 (RP2350) から YM2151 のレジスタを USB CDC 経由で
    書き込むファームウェア。行入力 + コマンドパーサ (pico-opm-writer.c)、
    バス制御 (opm.c / opm.h)、PIO による φM 生成 (opm_clock.pio) の構成。
    φM と sys_clk は 4MHz/144MHz と NTSC 3.579545MHz/157.5MHz の 2 プリセットを
    OPM_CLOCK_MODE で選択する。仕様は README.md に記述。
2026-08-09 ホスト PC 側のツール群を追加
    - opm-writer.py: シーケンスファイルを USB CDC でファームへ流し込む
    (!capture でロジアナも制御)
    - opm-dac2wav.py: DAC の生ロジックキャプチャを 16bit ステレオ WAV へデコード
    - opm-lfo-period.py: キャプチャから LFO 更新周期をサンプル数で測る (TSV 出力)
    - opm-dac-testgen.py / opm-lfo-period-testgen.py: 上記 2 本の回帰テスト (実機不要)
    各スクリプトのリファレンスは docs/<スクリプト名>.md。
2026-08-09 実機調査の環境と一次データを追加
    - test/lfo_noise/: LFO ノイズ波形の調査 (LFRQ / NFRQ の掃引)。掃引・解析とも
    完了しており、結論と根拠は README §6 / §7、実測値は result/。
    wav_value*/ と wav_w0,1,2/ は一次データのみで解析は未了 (README §6.8)
    - test/dac_lr/: DAC の 2 スロット (CH1/CH2) の関係。L と R は同一にならない
    wav*/ 以下は zstd 圧縮したキャプチャの一次データ。
    [wav_4a_01_am.tsv, wav_4a_01_pm.tsv, wav_am.tsv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]
2026-08-09 *.zst の delta 圧縮を無効にする .gitattributes を追加
    zstd 圧縮済みのキャプチャデータに git の delta 圧縮をかけても縮まらず、
    逆にパックが実サイズより膨らむ (416MB のワーキングツリーに対して
    size-pack が 553MB)。*.zst に -delta -diff を指定して抑止する。
2026-08-10 調査 README を「結論 → 根拠 → 詳細」の構成に再編
    test/lfo_noise/ と test/dac_lr/ の README を、調査した順ではなく読者が理解しやすい順に
    組み替えた。解析結果の要約 / 判明した仕様 / 結論の根拠 / 解析方法 / 詳細な解析結果 /
    考察 / 不明点・未解決事項 / 今後の課題 の順とし、掃引ツールの操作手順は付録へ移した。
    実験条件・測定値・失敗した実験・否定された仮説は削らず後半に残してある。
    冒頭の「解析結果の要約」に載せるのは確定した結論だけとし、確度の列、測定条件、
    他の行から導かれるだけの帰結、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
2026-08-10 段ごとの LFO 値から値の供給周期を測る解析を追加
    これまでの解析器 (tools/opm-lfo-period.py) は LFO の更新イベントの**間隔**しか測らない。
    LFO はノイズ語を自分のラッチ時刻でしか読めないため間隔は更新周期の整数倍にしかならず、
    ノイズ発生器が新しい語を出す周期 (32-NFRQ)/2 samples は原理的に測れなかった。
    値そのものを見る解析を analyze_lfo.py に足す。
    analyze_lfo.py:
    - `--runs` 個別条件の連の長さと値の供給周期。`--period` で更新周期を明示できるのが要で、
    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
2026-08-10 NFRQ 掃引を別の搬送波でキャプチャし直した一次データと解析結果を追加
    既存の wav_nfrq/ は NFRQ 全 32 値を押さえているが、f 帯 (LFRQ=0xf0/0xff) の搬送波が
    52/8 の 1 種類しかなく、段/周期 0.71 とはしごの下限ぎりぎりだった。対照帯の e0 も
    搬送波が違う (52/4) 上に解析器の共振警告が出る（実測搬送波 15.83 サンプル vs 周期 16）。
    wav_nfrq_5a09/ は KC=0x5a / MUL=9 (T_c = 7.06 サンプル / 8850Hz) に固定し、LFRQ を
    e0 (更新周期 16、対照) / f0 / ff (更新周期 8) の 3 点 × NFRQ 全 32 値 × AM/PM の
    192 条件。対照帯を同じ搬送波に揃えたので、NFRQ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
2026-08-10 LFO ノイズの NFRQ の効き方を「頭打ち」から 2 クロックの合成へ書き直す
    NFRQ の効き方を「LFO 更新周期の速い側の頭打ち」として書いていたが、この枠組みでは
    NFRQ=0x01〜0x1f の 31 値すべてで頭打ちが同じ 8 になる理由を説明できず、NFRQ != 0x00 の
    真の頭打ちも決められなかった。頭打ちではなく独立した 2 つの周期の合成だった。
    P_lfo = 2^(18-(LFRQ>>4)) LFO がノイズ語を取り込む周期（§2.1 の規則。変更なし）
    P_n = (32 - NFRQ) / 2 ノイズ発生器が新しい語を出す周期
    P_lfo >= P_n なら更新のたびに新しい語が来るので値が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
2026-08-10 段ごとの LFO 値列をキャプチャ間・条件間で突き合わせる --values を追加
    更新のタイミングだけを見る --gaps / 値を連の長さに畳む --runs では
    「別のキャプチャや別の条件で同じ語の列を引いているか」に答えられない。
    値列のまま扱い、遅れを総当たりして突き合わせる解析を足す。
    - 一致の閾値は無関係な段どうしの |差| の下側 10% 点に取る。こう決めると
    無関係な 2 列の一致率がちょうど 10% になり、上振れがそのまま
    「本当に同じ語だった割合」になる
    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
2026-08-10 下位ニブルが LFO 値列を変えないことと、0x28 の取り込み飛びを実測
    一次データだけだった wav_value/ を解析し、0x24〜0x2c の帯を別の搬送波で
    撮り直した。
    下位ニブルと値列（wav_value/ _r2 _r3、新規 --values）:
    - LFRQ=0xa0 と 0xaf は値列が完全に一致する。2048 段が 1 段も外れず、
    同じ組が 3 つある。下位ニブルは更新周期だけでなく、LFO が引く
    ノイズ語の列そのものも変えない
    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
    [wav_lfrq28_52_am.tsv, wav_lfrq28_52_pm.tsv]
2026-08-10 ノイズ発生器を直接測る test/noise_period/ を追加
    NE (0x0F の bit7) を立てるとノイズがチャネル 7 の C2 の出力に差し替わる。
    LFO を経由しないので格子が DAC の 1 サンプルになり、LFO 経由では飽和して
    届かなかった側まで測れる。
    出力の性質:
    - 一定の振幅にノイズ発生器のビットで符号を付けた 2 値で、符号は 1 サンプルに
    1 回しかラッチされない。L の符号列がノイズ発生器のビット列そのものになる
    - 符号の変化率 r から P_n = 0.5 / r。同じ符号が続く長さが P_n の整数倍に
    乗る割合は 32 条件すべてで 100.0% で、変化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
2026-08-17 FatFs に公式パッチ 3 本を当てる
    https://elm-chan.org/fsw/ff/patches.html から取得し、この順で適用した。
    1. ffunicode.zip (2025-08-03) 94ee9c278b100abca9375436757b40abf7782cde0a8ba4c2e7189083b5b9dbc3
    ffunicode.c を丸ごと差し替え。変換テーブルの圧縮改善。
    2. ff16p1.diff (2025-09-13) 7996ddc3135f3d534a8153f7d75d587030e5c8551b003c3b7ee823ffb7fc64bf
    f_mkfs の最小ボリュームを 128 → 64 セクタへ。
    3. ff16p2.diff (2026-07-10) 5cd39f1fc299f0f1dec9fa1ce544dc0bc048b2f6eb3b8161476ed20f9cf1e290
    セキュリティ修正。CVE-2026-6682 ほか。壊れた FAT サイズ欄でデータ破壊や
    クラッシュが起き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
2026-08-17 ストレージと VGM 再生をドキュメントに反映する
    README.md:
    - §3.3 のエラー理由に wrong state / no filesystem / not found / bad file /
    io error を追加。コマンドが 1 文字とは限らなくなったことも書き直す
    - §3.4 のコマンド一覧に storage と vgm を追加
    - §3.6 の i と §3.11 の s の出力例を現物に合わせる
    - §3.13 storage / §3.14 vgm を新設
    - §7 ストレージ / §8 VGM 再生を新設。以降の章を 9-11 へ繰り下げ
    - §10 の将来の拡張から VGM の項目を外し、GD3 表示 / .vgz 展開 / GPIO UI を入れる
    docs/pico-opm-writer.md:
    - §1 のソース表と §1.1 のメイン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
2026-08-18 φM プリセットを実行時に切り替えられるようにする
    4MHz と 3.579545MHz (= 315/88 MHz) の両方が整数分周になる sys_clk は
    2520MHz が最小で実現できないので、φM を変えるには sys_clk ごと張り替える
    しかない。clockmode.c がこれを行い、clock コマンドから切り替える。
    φM と BCK の H/L 期間は分周比の個数ぶんの clk_sys サイクルなので、短い
    パルスは「分周比が小さいまま clk_sys が上がる」ときにだけ出る。clk_sys 自体
    は glitchless mux で欠けたサイクルを出さず、上がる瞬間に進行中だった H/L は
    最悪でも「新しい clk_sys での公称 H/L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
    [i2s.h, opm.c, opm.h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]
2026-08-18 VGM 再生を φM の自動追従に対応させる
    これまでヘッダ (0x30) の YM2151 クロックは警告に使うだけで、食い違ったまま
    狂った音程で鳴らしていた。vgm_play() で最寄りのプリセットへ寄せる。境界は
    2 つの中点 3789772Hz なので、3546895Hz の PAL 物や 3375000Hz は 3.58MHz 側
    に落ちる。
    寄せるのは opm_clear() と s_start_us より前。切り替えに使う数百 us が再生の
    起点に乗らない。wait は 44.1kHz の絶対サンプル数でテンポは元から正確なので、
    合わせるべきは φM の方。
    不一致の警告は寄せたあとの残差にだけ出す。clock fixed のときは寄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
2026-08-22 ユーザ提供機能を README とヘルプに揃える
    README がユーザ向けの仕様書として実装に追いついていなかったので、
    ファーム側の非対称と古いヘルプ文字列も含めて突き合わせ直す。
    ファーム:
    - mdx_list() が `# files : N` を出さず vgm_list() と非対称だったので合わせる
    - `h` の 3 行を実装に合わせる。`t` は pcm/pio/mdx/adpcm の 4 つを走らせる、
    `clock auto|fixed` は MDX にも効く、`storage format` は force を取れる
    README:
    - §3.3 エラー一覧に not connected / drain timeout / self test failed /
    unsupported を追加し、unknown command / not found / bad file / wrong stat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
2026-08-23 基板データを登録
    [pico-opm-writer.kicad_pcb, pico-opm-writer.kicad_sch]
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2026-08-23 基板のシルクの場所を調整した
    [pico-opm-writer.kicad_pcb]
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2026-08-23 基板のベースのモデルを作成した
    [pico-opm-writer_base-Body.stl, pico-opm-writer_base.FCStd]
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2026-08-23 基板データの小修正
    * YM2151のシンボルデータで12番ピンが非表示のピン情報で重複していたのを削除。
    * C1の乗数記入漏れ
    * 上記に合わせてPCBも更新(実質変更なし)
    [pico-opm-writer.kicad_pcb, pico-opm-writer.kicad_sch]
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2026-08-24 YM2151 からの読み出しコマンド r 0 / r 1 を追加する
    /RD (GP13) は基板上で配線済みで GPIO も初期化していたが、H 固定のままで
    読み出しは実装していなかった。opm_read() を足し、ホストから `r 0` / `r 1`
    で 1 バイト読み出せるようにする。読み出しの間だけデータバスを入力へ倒す。
    1 文字の r を読み出しに使うので、/IC リセットは reset へ移す。ホストツール
    の応答待ちの特別扱いと、テストのシーケンスファイル 3 本も追従させる。
    読み出しはレジスタを変えないので、VGM / MDX の再生中も拒否しない。
    opm_write() の BUSY 待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
    [opm.c, opm.h]
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2026-08-26 BUSY フラグと opm_write() の待ち時間を実測して調査レポートにまとめる
    opm_write() の固定ウェイト（t_DATA = 25us）を BUSY ポーリングへ置き換えるかを
    判断するための実機調査。一時的な診断コマンドで測定し、レポートと一次データだけを
    残してファームウェア本体は無変更に戻してある（診断コードは diag.patch）。
    判明したこと:
    - BUSY は書き込みから 67.1 ± 0.2 φM サイクルで落ちる（4MHz で 16.8us）。
    sys_clk を固定したまま φM を 1.2〜3.6MHz で振り、境界を 1/φM の 1 次式として
    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
    [regs.tsv, scale-phim-run1.tsv, scale-phim.tsv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]
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2026-08-28 自然終了では OPM を触らないようにする
    MXDRV 参照実装 (mxdrv 2.06+17 Rel.X5-S) の L001442 は、曲データが尽きたとき
    END_FLG / LOOP_FLG から自分のビットを落として停止フラグを立て、PCM8 を止める
    だけで OPM には 1 バイトも書かない。最後の音は音色本来の RR で自然に減衰する。
    消音 (L00063e) が走るのは STOP コマンドと次の PLAY の先頭だけ。
    ファーム側は自然終了でも key_off_all() を呼んでいて、原典に無い強制消音で
    余韻を切り落としていた。vgm.c の end_of_data と mdx.c の s_enable == 0 から
    外す。ERROR の後始末・MDX 内蔵フェードの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
2026-08-28 p 2 の待機中は phiM の切り替えを通す
    clockmode_apply() がキャプチャ中の phiM 切り替えを拒むのは、流している PCM の
    サンプリングレートがストリームの途中で変わって WAV の時間軸が狂うから。
    WAITING はまだ 1 フレームも流していないので、その理由が当てはまらない。
    通さないと、ファイル側のクロックを要求する VGM を p 2 で録ろうとした時点で
    必ず失敗する（vgm play が clockmode_follow_file() で弾かれて ERR wrong state）。
    storage host の拒否は WAITING でも据え置き。あちらの理由（フラッシュの消去で
    メインループが数十 ms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
2026-08-29 RP2350A / PCM5102A 直載せ基板の回路図を追加する
    Pico 2 と GY-PCM5102 をモジュールとして載せる board/ に対して、RP2350A・
    PCM5102A・周辺部品を基板へ直接実装する改版を board_pcba/ に起こす。
    モジュール側に重複していた電源回路・USB・水晶は基板へ統合した。JLCPCB の
    Economic PCBA で組む前提で、部品はすべて LCSC の在庫から選んである。
    実装 62 点で $6.70 / 枚（10 枚なら部品 $67.0 + Extended 手数料 $21）。
    成果物は A3 1 枚の回路図だけで、基板レイアウト (.kicad_pcb) は未着手。
    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
    [pico-opm-writer_pcba.kicad_pcb, pico-opm-writer_pcba.kicad_sch]
2026-08-29 RP2350A / PCM5102A 直載せ基板のレイアウトを起こす
    board_pcba に回路図しか無かったところへ、配置・配線・GND ベタまで入れて
    基板を一通り完成させる。46 × 47.5mm / 2 層 / 板厚 1.6mm。
    配置は KiCad の pcbnew Python API で生成し、自動配線は Specctra DSN / SES 経由で
    freerouting に投げた（DSN のエクスポートは GUI 専用で kicad-cli には無い）。
    質が効くネット — 内蔵レギュレータのループ・USB 差動対・水晶・PCM5102A の
    チャージポンプとアナログ出力 — だけは先に手で引いてロックしてある。
    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
    [pico-opm-writer_pcba.kicad_pcb, pico-opm-writer_pcba.kicad_sch]
2026-08-30 基板のベースの基板までの隙間を0.5mm大きくした。
    その分、土台の厚みを0.5mm薄くした。
    [pico-opm-writer_base-Body.stl, pico-opm-writer_base.FCStd]
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
